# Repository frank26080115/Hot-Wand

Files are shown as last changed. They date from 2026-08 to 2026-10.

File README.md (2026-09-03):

# Hot-Wand

Compact RF soldering iron station. Compatible with 13.56 MHz handpieces. If the handpiece uses 13.56 MHz and a F-type coaxial connector, then it is compatible.

The project's name, Hot-Wand, reflects how a RF soldering iron feels like magic, and justifies their typical multiple-hundreds-of-dollars price. The spirit of this project is not to lower the price, but to make it portable.

This is nearly a clone of [SergeyMax's design](https://github.com/SergeyMax/SolderingStation), but with modifications:

 * redrawn schematic for clarity
 * layout to fit in a Hammond MFG enclosure
 * removed AC power input, uses DC inputs (battery XT30 connector) or USB-PD (with negotiation for 28V)
 * uses a 128x32 OLED display
 * options for low power mode, automatic sleep
 * uses a STM32F042F6P6 microcontroller (more flash memory)
 * cooling fan, temperature sensors
 * internal glass fuse
 * substituted parts that are only available from Russia

I implemented a rather fancy GUI, fancier than what is available on a Metcal soldering station. The firmware features/supports:

 * persistent settings, edited through a setup menu
 * 3 different power levels (for adapting to different USB bricks or power banks)
 * low battery warning/cutoff
 * user triggered sleep mode (basically, the power switch)
 * idle detection for automatic screen dimming and sleep
 * various fault detection
 * easter eggs! try and find them

The XT30 connector allows the user to connect a battery pack. If the user configures what kind of battery chemistry is being used, then the firmware will automatically determine the number of series cells in the battery pack and set an appropriate low battery cutoff threshold. When the battery voltage is considered too low, the power is automatically cutoff and the user is offered an option to override the cutoff.

The USB-C connector is connected to a USB-PD negotiation IC. The negotiator is configured to request 28V at the maximum allowable current (capable of 5A). Depending on the USB-PD host's implementation, the actual offered voltage may be 28V or 20V. If the current required is more than the current available from the USB-PD host, the user can select one of the lower power modes to avoid unexpected shutdown.

The RF power output is through a F-type connector, so it is compatible with most 13.56 MHz handpieces, such as Metcal, Thermaltronics, Hakko.

On paper, the buck converter that is actually powering the RF amplifier is set to 20V output with a 5A current limit. Thinking this means a 80W heat output is optimistic, I would expect somewhere between 50W to 80W of actual heating power, while using about 120W total from the upstream. Thus, the highest power setting is meant to be compatible with 140W USB-PD GaN chargers. The lowest power setting is roughly 50W electrically, to be compatible with 65W USB-PD chargers. The medium setting is roughly 75W electrically and is meant to be used with 100W USB-PD chargers.

When using a battery, the buck converter cannot boost the voltage, so using any DC input below about 24V would mean maximum power cannot be reached. The user does not have to set a low power mode in these cases but just don't expect the power bar being displayed to ever reach the top of the chart. The system cannot function at all below 14V. The DC input is rated for up to a 36V input. There is a glass fuse inside that limits the total system power draw to TODO amps.

While this is a DIY project and not a commercial product, it is a difficult project as it requires hand-wound inductors and tuning the inductor coils. This project is a learning experience, as I had to study the (translated from Russian) blog post made by SergeyMax in detail. See my page on the design study TODO.

## Hot-Wand Lite

In the same spirit, a compact RF soldering iron station. Compatible with 470 kHz handpieces. This is the inexpensive version. It is a clone of the [Radio Thermal](https://radiothermal.com/), but with modifications

 * layout to fit in a Hammond MFG enclosure
 * uses battery XT30 connector or USB-PD for input
 * uses some sort of Seeed Studio XIAO microcontroller module
 * user selectable power levels via externally pluggable jumpers
 * internal glass fuse

Physically, Hot-Wand and Hot-Wand-Lite uses the same aluminum enclosure. The power input stage are almost identical. The RF output connector is a SMA connector this time. [Radio Thermal](https://radiothermal.com/) (the inspiration for this) has instructions on how to build a cheap handpiece.

This cost saving design has way less fault detection.

While this is a DIY project and not a commercial product, it is a difficult project as it requires hand-wound inductors and tuning the inductor coils. Regarding how this is copying a lot of the [Radio Thermal](https://radiothermal.com/) design, I am copying it verbatim, as they do not use anything weird from Russia, and the RF design education I've already gotten from the much more complicated 13.56 MHz version of Hot-Wand.

## What is a RF soldering iron anyways?

An RF soldering iron sends high-frequency electromagnetic energy into a purpose-built tip cartridge, where a thin magnetic heating layer produces heat very close to the working end; in Curie-regulated cartridges, that layer also changes how strongly it absorbs energy as it approaches its designed temperature. Compared with a conventional iron whose resistive heater must heat a larger structure and conduct that heat to the tip, the shorter thermal path and low effective thermal lag let an RF tip respond immediately when a solder joint draws heat and recover its temperature quickly afterward. That fast, load-responsive delivery is why a nominally 50 W RF iron can feel more capable than a nominally 100 W resistive iron: the wattage rating describes available electrical power, while the user's experience is dominated by how quickly and efficiently that power reaches the joint and restores the tip temperature.

The RF soldering iron's station unit does not feature a temperature setting or even have the ability to detect the iron's temperature. When you buy the iron cartridge (which is the tip and stem), it is specific to one temperature. It will always be dead-nuts on target because of the Curie-point behavior of the magnetic alloy built into the cartridge. Below its designed temperature, the alloy is magnetic and the skin effect concentrates RF current in its thin, relatively high-resistance outer layer, producing heat right at the tip. At the Curie point the alloy loses its magnetic properties, the skin effect collapses, and the current moves into the low-resistance copper core, so heating drops sharply. When a solder joint cools the tip, the alloy becomes magnetic again and full heating immediately resumes. The temperature feedback mechanism is therefore inside the heater material itself, directly at the working tip, instead of being a sensor-and-controller loop back in the station.

## Project Ethos

I've always liked the Metcal MX-5200 I have access to at work. I'm also a robot combat competitor, both in insect weight classes and also a part of a heavyweight battlebots team. Thus, I travel with my tools a lot, sometimes even flying to NHRL from California. And while I like my [iFixit soldering iron](https://eleccelerator.com/review-ifixit-soldering-iron/) for it's portability, I thought it'd be cool to have a portable RF soldering iron.

While designing this project, the cost started to balloon. At one point it was decided to drop the pretense that DIY is cheaper, and instead, build something I would rather own even more than the actual (gigantic) MX-5200.

I also wanted to document this project in a way that makes it way more friendly for a DIY builder to actually build.

Undertaking this project is not cheap, it requires a considerable amount of skill and for you to already have access to soldering equipment. You have been warned. If you need a good soldering iron for a reasonable cost, a Hakko FX-888DX or a iFixit Soldering Iron are still a good bets.

## Design Study

Please see [my full design study (click here)](doc/design-study/design-study.md). This includes:

 * Dissection of SergeyMax's design
 * Analyzes other DIY builder's notes as they build SergeyMax's design
 * Analyzes SergeyMax's follow-up video (that's in Russian)
 * My additional design choices, justifications, calculations
 * and more

and please explore the [documentation directory itself](doc), as I might've written something but forgot to link it.

## Build Guides

 * [DIY build guide for the Hot Wand (13.56 MHz version)](doc/build-guide-13mhz/build-guide.md)
 * [DIY build guide for the Hot Wand Lite (470 kHz version)](doc/build-guide-lite-470khz/build-guide-lite.md)

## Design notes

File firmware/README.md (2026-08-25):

This is the firmware for the Hot Wand, running on a STM32F042 microcontroller.

It is meant to be built under PlatformIO and flashed via the SWD pins using a ST-Link V2.

# Firmware Architecture

The overall firmware is split into the main application that operates the soldering iron, and a setup menu (which keeps the soldering iron unpowered while within the menu). The main application owns initialization and the continuously running control loop. The setup menu is a separate modal loop entered during boot; it stops RF generation and forces the buck-converter control to minimum output before accepting input or drawing menu pages. It uses only the button, display, timeout, and nonvolatile-settings paths needed to edit configuration, then resets the controller when exiting. This keeps setup logic out of the active power-control path and makes the safe output state explicit at the boundary between the two modes.

## Platform and hardware layer

The project uses PlatformIO's STM32Cube framework and the STM32F0 hardware abstraction layer supplied by ST. The vendor HAL and CMSIS definitions provide the supported interface to clock control, GPIO, interrupt configuration, ADC setup and calibration, flash programming, and the other MCU peripherals. This keeps device-specific register names, bit definitions, and startup behavior tied to the selected STM32 target rather than duplicating them inside the application.

Some paths use the STM32 peripheral registers directly after the HAL has established the surrounding clocks and pin configuration. This is intentional where the firmware needs an exact timer waveform, a carefully ordered GPIO/peripheral handoff, or a small deterministic interrupt path. The RF carrier, power-attenuation PWM, fan PWM, tip-detect timer, ADC channel rotation, and OLED I2C transport are examples. These accesses still use ST's CMSIS device definitions; they are not a separate home-grown hardware abstraction layer.

## Imported U8g2 display library

A copy of U8g2, including its U8x8 support layer, is imported into `lib/u8g2` and compiled as part of the firmware instead of being fetched as a build-time dependency. The imported library provides the SSD1306 display driver, framebuffer, fonts, and drawing primitives. Its upstream license is retained alongside the source.

Application code reaches U8g2 through `oled.c`. That module supplies the display setup and the U8x8 byte, GPIO, and delay callbacks that connect the library to this board's I2C transport and STM32 timing functions. Keeping the adapter at this boundary avoids spreading display-controller and library-callback details through the rest of the firmware.

## Execution model

There is no RTOS, scheduler, thread, or dynamically registered task list. After a fixed initialization sequence, `main()` enters one cooperative `for (;;)` superloop. Each subsystem exposes a small task function that is called in a deliberate order: inputs and tip state are serviced first, safety faults are checked, power is supervised, RF restart eligibility is evaluated, and then the lower-priority temperature, fan, debug, button-action, and display work runs.

Most tasks are non-blocking state machines. They remember their own state and compare timestamps against the shared millisecond tick, then return quickly when no work is due. This makes execution easy to inspect: there is one foreground control flow, and timing behavior does not depend on scheduler priorities or task synchronization primitives.

The boot/setup screens and terminal fault screen use their own explicit loops. Those are intentionally modal states, not hidden schedulers. They use short delays while continuing the small amount of input and display work appropriate to that state. The setup menu and all terminal fault paths first disable power-producing outputs.

## Interrupts and timing

Interrupts are reserved for events that cannot depend on foreground loop latency:

- SysTick maintains the HAL millisecond counter used by the cooperative state machines.
- The ADC completion interrupt advances continuous round-robin sampling, updates the filtered readings, and maintains a high-granularity DC-input-voltage history.
- EXTI and TIM14 qualify tip-presence edges with a hardware-timed debounce interval. (highest priority)
- The clock security system uses the NMI path to shut down RF if the external crystal fails.
- The user button press is using an interrupt edge trrigger sharing EXTI.

The startup vector table supplied by STM32Cube uses weak handlers. `interrupt_vectors.S` provides strong, non-LTO shims that retain and dispatch to the firmware's C implementations even with the GCC 7 link-time optimizer enabled.

## Tip-detection safety

Tip detection starts fail-closed: before the detector has initialized and confirmed the input, its fault latch is set and RF is not allowed to start. The electrical input has an external pull-up, so a high level represents a connected tip and a low level represents a missing tip.

Both input edges trigger EXTI. The handler masks the tip interrupt and starts TIM14 as a one-shot timer for the 300 microsecond debounce interval. When that interval expires, the timer interrupt samples the settled pin. A confirmed missing tip latches the fault and calls `rfgen_stop()` directly from the interrupt path, without waiting for another pass through the main loop. Edges arriving during qualification remain pending and receive another complete qualification interval after EXTI is unmasked.

The latch does not clear merely because the signal returns high. Reset is allowed only when the last debounced state says the tip is present, the physical pin is currently high, and no debounce interval is in progress. Normal operation treats the resulting tip fault as terminal until the user resets the controller.

RF startup independently repeats these checks. It refuses to start while the tip latch is set, while TIM14 is qualifying an edge, or while the physical tip input is low. The final check and timer enable are performed with maskable interrupts disabled, closing the race in which a disconnect could otherwise occur partway through startup.

## Fan controller

The firmware allows the user to pick between 16 different fan control modes, in three broad categories:

 * simple and force the fan to a certain speed
 * automatic modes triggered by a particular temperature threshold
 * adaptive modes that adjusts fan speed based on temperature detected

## RF generation and shutdown safety

The RF carrier depends on the 27.12 MHz external crystal. TIM1 divides that clock by two to produce the 13.56 MHz, 50 percent duty-cycle waveform. Startup verifies that HSE is ready and is actually the system clock before enabling the RF output. The clock security system remains enabled afterward; an HSE failure enters the NMI handler, latches a clock fault, and stops the generator. Internal lockup and SRAM-parity fault signals are also routed to TIM1's hardware break input, whose configured run and idle off-states hold the RF output inactive.

RF shutdown does not rely on simply stopping a timer and hoping the pin assumes a safe state. Normal `rfgen_stop()` marks the generator inactive, preloads the GPIO output latch low, changes the RF pin from TIM1 alternate-function control to a push-pull GPIO output, and disables TIM1. `rfgen_emergency_stop()` reverses that order for minimum latency: it first clears TIM1's main-output enable, channel enable, and counter, then performs the same GPIO-low handoff. Emergency stop also latches an RF-driver fault that both start gates enforce until MCU reset.

Startup uses the reverse discipline. The timer is completely configured while its main output remains disabled, the inactive timer state owns the pin first, and only the final guarded sequence enables the timer and RF output. If a tip or clock fault is observed during that sequence, shutdown runs again immediately.

## Fault containment

Fault handling is deliberately terminal. Entering `show_fault()` immediately stops RF generation, forces the buck-converter attenuation output to its minimum-power state, and stops the fan before attempting to draw or animate an error message. If the display is unavailable, the firmware remains in the safe terminal loop anyway. Faults are never cleared automatically; recovery requires the explicit reset path allowed for that fault.

Some faults are triggered from the interrupt context. `rfgen_emergency_stop()` will be called from within the interrupt for minimal latency, and then a fault flag is set for the main thread to show the terminal `show_fault()`.

This gives the firmware layered protection. Foreground supervision handles normal voltage, temperature, current, and power decisions; time-critical failures (tip detector, crystal clock, voltage dips/spikes) have interrupt-level shutdown paths; TIM1 has hardware break inputs for internal MCU faults; and terminal fault presentation independently reapplies safe output states before doing any UI work.

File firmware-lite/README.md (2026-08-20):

# Hot Wand Lite Firmware

The Lite edition of Hot Wand is very simple as it is a copy of the Radio Thermal DIY RF soldering iron design. The microcontroller simply needs to generate a 470 kHz square wave.

The additional feature is that the user can select between 3 power modes. The LED will blink according to the input voltage and selected power mode.

This firmware is built under PlatformIO under the Arduino framework. The RF generator code does use low level hardware registers and so care must be taken so that Arduino built-in functionalities do not conflict with the same hardware.

## Power Modes

The "Sport" mode is a 100%-no-matter-what power mode.

The "Normal" power mode is one that allows 100% power for 21V of power input or lower. When above 21V, the firmware attempts to lower power consumption in a way that caps it at 100W.

The "Eco" power mode is a 70% power mode. The intention is to allow a 3A capable power supply to be used instead of a 5A power supply.

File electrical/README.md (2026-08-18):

This directory contains electrical design files for the Hot Wand project

The main `hot-wand` project is the 13.56 MHz version, while the `hot-wand-lite` is the 470 kHz version meant to be less expensive.

The schematic and PCB are designed with CadSoft EAGLE 7. PDF versions of the schematic and image previews of the PCB are provided for convenience.

The `mfg` directory will contain the BOM and gerber files, along with some helpers that aid in generating these files.

The BOM, CPL files, and the design rules, are all meant for use with JLCPCB's PCBA service.

## Release Procedure

0. Run a DRU check, and also run `drill_sizes_report.bat` to catch stray drill sizes
1. Edit the symbol and footprint for the version to reflect the latest version designation
2. Generate the schematic preview PDF file using `eagle_schematic_preview.py`
3. Generate the gerber files using `generate_gerbers.bat` (this also generates the gerber preview)
4. Generate the BOM and CPL files using `generate_bom_cpl.bat`

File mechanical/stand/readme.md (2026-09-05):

this directory contains the 3D printed and milled/cut components used for the folding soldering iron stand

see [this document to see the instructions](../../doc/build-guide-iron-stand.md)

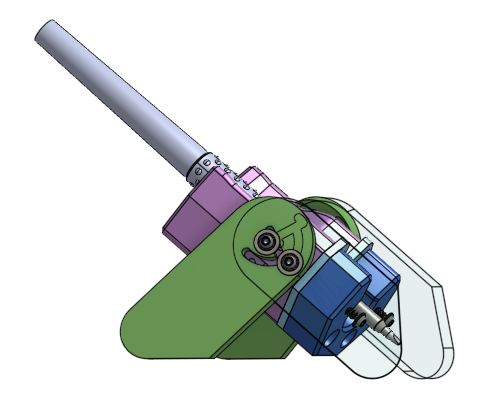
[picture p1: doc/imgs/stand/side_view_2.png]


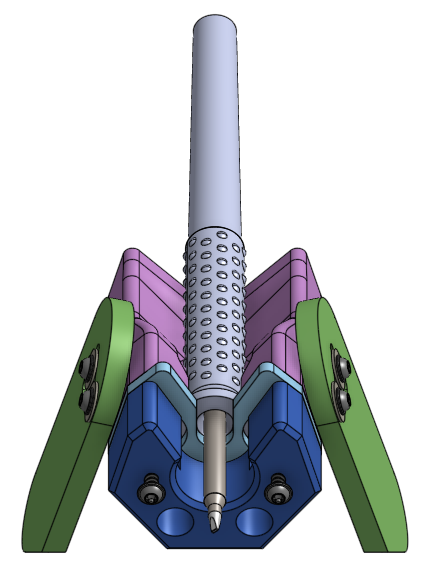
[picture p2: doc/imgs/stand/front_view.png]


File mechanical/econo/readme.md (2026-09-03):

This directory contains the 3D printed components used for the economically built Hot Wand 13.56 MHz plastic version.

These parts are not used if you are building the aluminum enclosed version.

see [this document to see the instructions](../../doc/build-guide-13mhz/econo-build.md)

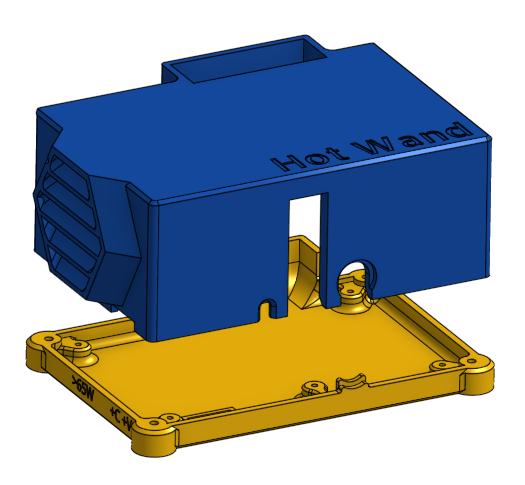
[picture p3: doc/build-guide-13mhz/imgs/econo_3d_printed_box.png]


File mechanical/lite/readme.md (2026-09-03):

this directory contains the 3D printed components used for the Hot Wand Lite 470 kHz version

see [this document to see the instructions](../../doc/build-guide-lite-470khz/build-guide-lite.md)

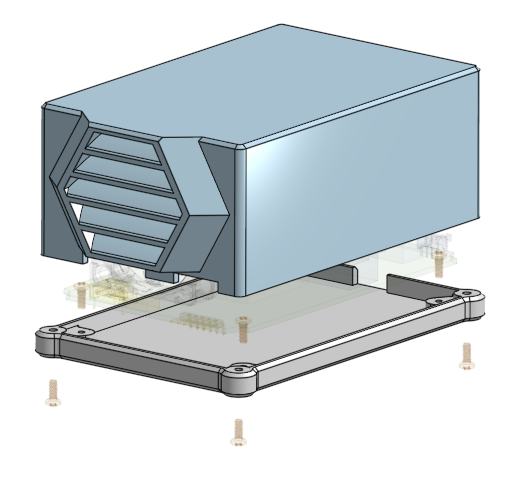
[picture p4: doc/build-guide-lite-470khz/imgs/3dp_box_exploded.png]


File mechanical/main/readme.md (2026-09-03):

this directory contains the 3D printed components used for the main Hot Wand 13.56 MHz version

see [this document to see the instructions](../../doc/build-guide-13mhz/build-guide.md)

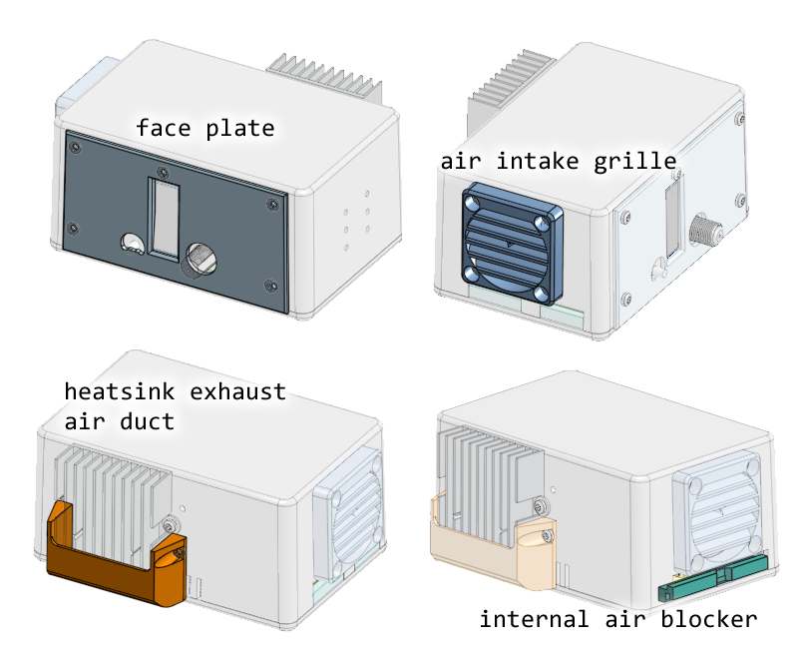
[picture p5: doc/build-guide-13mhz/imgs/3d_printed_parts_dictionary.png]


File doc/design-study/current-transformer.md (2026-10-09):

In SergeyMax’s design, there is a current transformer at the RF output. It is using one of the same toroid cores that’s used in other places in this design. The primary winding is just a single loop of the RF output. The transformer is 1:14:14 so the two secondaries are both 14. The connection that looks almost like a center tap is connected to the RF output through a 10pF capacitor. The output of the transformer goes to something that resembles a full bridge diode rectifier. That goes to what looks like a RC filter before a resistor leading to the feedback network of the main buck converter.

At a simple first glance, I assumed that this was some sort of stability or protection mechanism. More current would mean more signal driven into the feedback network and thus lower the buck converter’s output voltage. I thought maybe this was to compensate for some sort of voltage drop caused by inrush, maybe the buck converter overcompensated for voltage drops like that, and needed something to stabilize it.

SergeyMax’s own blog post didn’t really give a clear answer, and other people building his design were also studying it. This forum thread is a goldmine https://www.eevblog.com/forum/projects/i-built-the-diy-metcal-compatible-soldering-station/

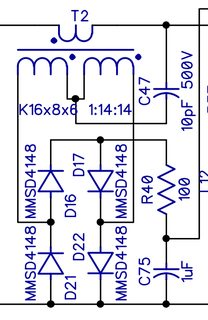
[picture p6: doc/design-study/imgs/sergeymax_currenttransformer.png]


TLDR: This is a power factor meter. As the temperature of the iron tip changes, the complex load changes, shifting the phase relationship between RF voltage and current. The tip doesn't need or want more power when it is already hot, and the power factor will change. This current transformer circuit is able to sense this by detecting the phase difference between voltage and current, and then it tells the buck converter to lower its output voltage when the tip doesn't want more power. (technically it also tells the buck converter to raise the voltage when it is cold)

The builder `rfmerrill` posted to the forum thread:

> At first I thought it was a simple current sense circuit, but then I noticed that the RC filter is a lowpass at around 2 kHz, and the diodes are not arranged in a rectifier configuration.
> 
> After poking at it a bit with some friends, we realized this is actually a **ring mixer** that mixes the output current with the output voltage to measure the phase angle between voltage and current! Which makes a ton of sense actually: We want to reduce the output power as the iron tip reaches the curie point. As it does so, the inductance of the iron tip will drop, causing the phase angle between voltage and current to move away from 45 degrees.
> 
> In other words, it's effectively a power factor meter!

later

> Here's how it works:
> 
> Current flows in the same direction on the schematic on primary and secondary side (same polarity voltage = opposite polarity current!)
> 
> The node between D16 and D17 is clamped to approximately +/-2V by the diode ring.
> 
> Because of the above, we can think of C47 as being from the output voltage to essentially ground, as the voltage on the other side of C47 is much greater than 2V in magnitude. Therefore, the current through C47 is approximately the same as it would be were it connected to ground--in quadrature with the output voltage and equal to approx Vout / 1173 ohm (either RMS or peak since it's a sinusoid)
> 
> When primary current is flowing left to right--i.e. towards the soldering iron tip--D16 and D17 are reverse-biased, and therefore no current flows through R40
> 
> When primary current is flowing right to left, the current induced in the secondary flows through D16 and D17, and the additional current injected by C47 has nowhere to go but into R40--until the voltage at that node gets high enough that either D21 or D22 is forward biased. Because the current injected by C47 is so high, this results in R40 effectively seeing a square wave current which you can see in the LTSpice simulation above.
> 
> So if we want to create a simplified model of how R40 is being driven, we can think of it like this:
> 
> - Not driven when primary current is flowing left to right
> - Driven at +2V when primary current is flowing right to left and current is flowing down through C47
> - Driven at -2V when primary current is flowing right to left and current is flowing up through C47
> 
> Because the current through C47 is 90 degrees out of phase with the output voltage we can then reach the conclusion that
> 
> **if the output current and voltage are in-phase, periods 2 and 3 are of equal time and thus the voltage at C1 is zero**
> 
> . Of course, that voltage is also being pulled towards 0.8V via its connection to the feedback loop of the DC-DC, but we'll ignore that for now.
> 
> If the output voltage starts to lead the output current, then period 2 will lengthen and period 3 will shorten, and the voltage on C47 will be pulled higher. Likewise if the current leads the voltage, the inverse will happen and the voltage on C47 will be pulled lower.
> 
> So in essence this is not as dependent on the magnitude of output current and voltage, and much more on the relative phase, which makes sense.
> 

I read what he said, and it was difficult to get a nice graphic out of a simulator to represent it, so I came up with this theoretical signal animation instead:



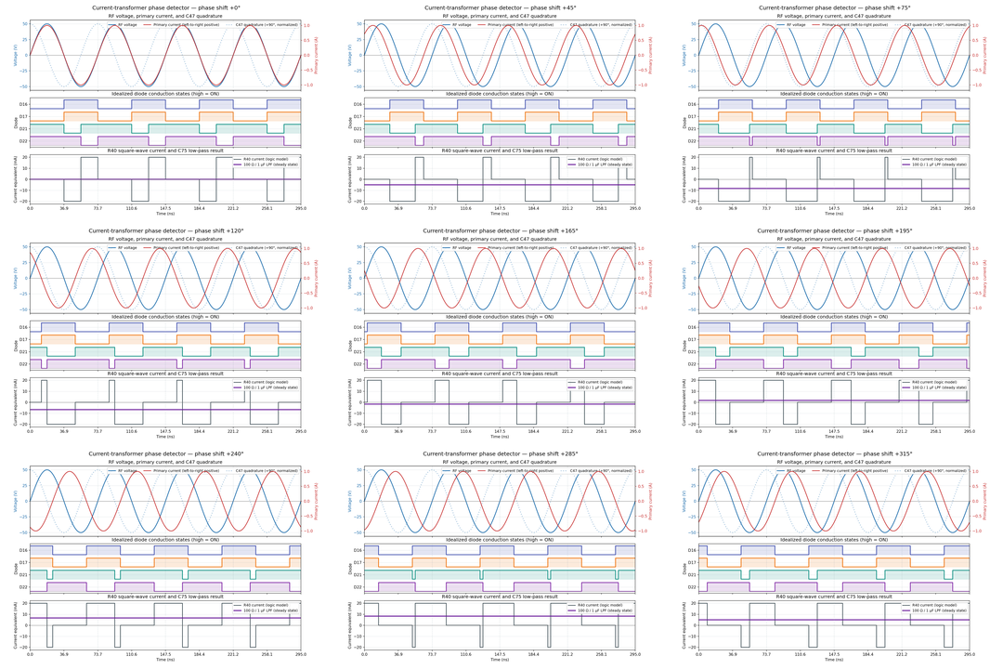
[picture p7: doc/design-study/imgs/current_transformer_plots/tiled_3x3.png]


If you wish to see the individual frames, [click here for all the frame files](./imgs/current_transformer_plots/)

For the three examples of tip temperature states and their resulting waveform:

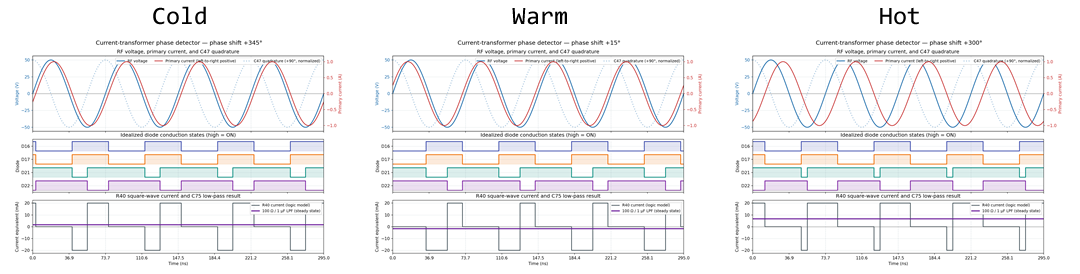
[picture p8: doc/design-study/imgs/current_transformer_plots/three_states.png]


The numbers used in this model are in this document at the bottom.

## My Own Implementation

The builder `rfmerrill` told me that (over reddit chat)

> I was never able to get it to work until I actually sourced the exact cores from russia

He didn't get the current transformer to work with any of the substitute toroid cores, it only started working once he put in the effort to import some of the Russian ones that SergeyMax used.

The rule of thumb is that for a transformer application, a different AL doesn't mean I have to change the winding ratios, it's a ratio after all.

The toroid core I picked is a Fair-Rite 5961004901. The material is "61", the AL is supposedly higher than the one SergeyMax used, and the datasheet claims that it is a "high frequency NiZn ferrite material developed for a range of inductive applications up to 25 MHz".

On paper, this current transformer is behaving almost like a digital component because of the way the diodes clamp the voltage. The current transformer and the 10pF capacitor really just need to provide enough signal strength to actually cause the diodes to conduct. So this means the Fair-Rite substitute should work better, in a sense. But the concern is that the different material causes a phase delay from primary to secondary, which would obviously ruin the whole thing as the whole point is to measure the phase difference between voltage and current.

I planned out the winding in 3D with consideration for my transformer PCB footprint. All wires are to be 22 AWG (SergeyMax used 0.6mm). There isn't many photos of this component so I thought a 3D model would help a ton.

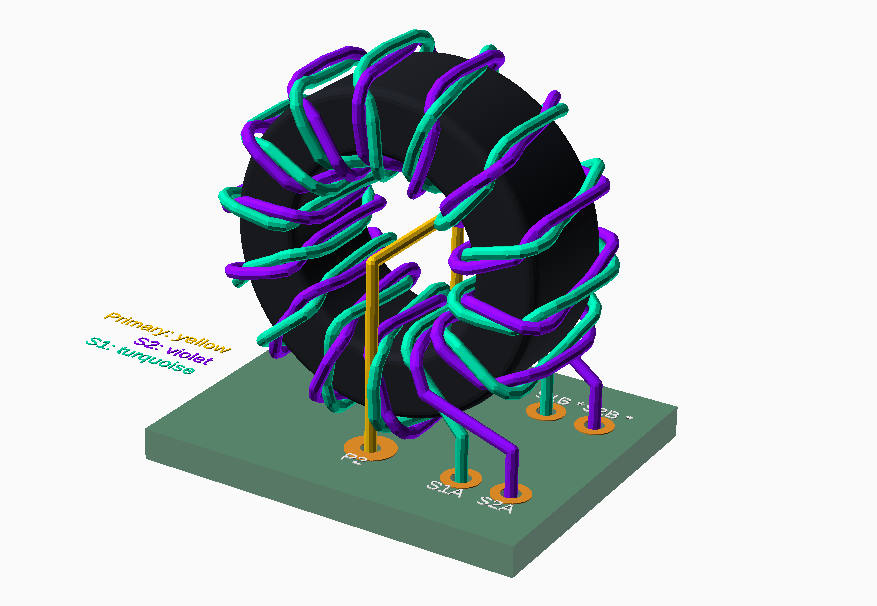
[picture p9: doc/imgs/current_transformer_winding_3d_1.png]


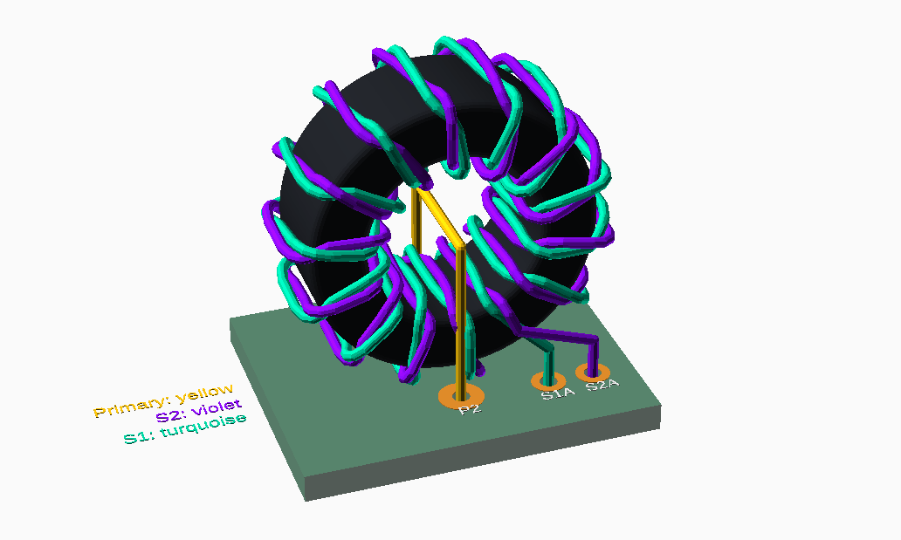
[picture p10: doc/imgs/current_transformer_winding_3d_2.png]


The two secondary wires are first twisted together, and then wound around the toroid, crossing the center of the toroid 14 times. A twisted bifilar winding implementation.

Also, it's hard to get the directions wrong, because the directions for the current flow (the primary current must be in the opposite direction of the secondaries) are actually dictated by the PCB design, not the winding direction. You can wind it clockwise or counterclockwise and it is theoretically going to do the same thing physically. But, do not criss-cross at the bottom!

## Screenshot From SergeyMax's Follow-up Video

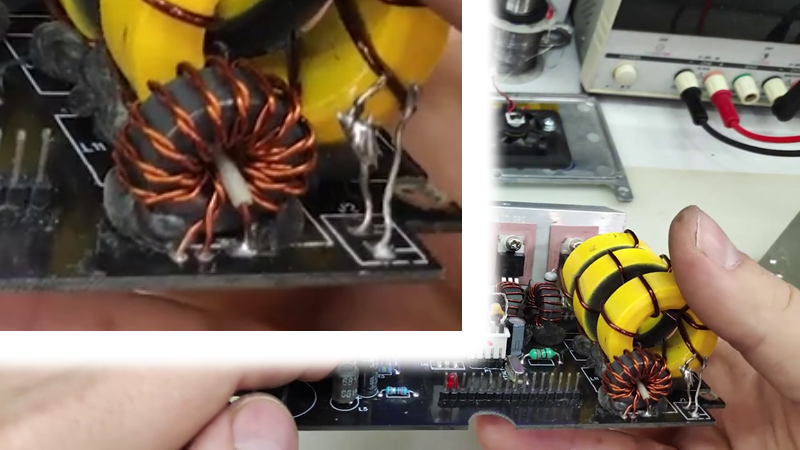
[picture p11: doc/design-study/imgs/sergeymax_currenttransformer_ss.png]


He did say that if you screw this up, it could make the circuit do the opposite, which is boosting the voltage when it should be lowering it. I have spent a ton of time making sure I did not make this mistake.

## Iron Tip Model

For simulations, it is useful to know how to model the iron tip as if it was a complex load.

I got these measurements from http://randomfunprojects.co.uk/metcal.html

Measurements at 13.56 MHz of a STTC-147 tip

| Tip state | Resistance, R (Ω) | Reactance, X (Ω) | Equiv. component | SWR  | S11  |
| --- | ---: | ---: | ---: | ---: | ---: |
| Cold | 42.3 | +j13 | 153 nH | 1.4 |  -16 dB |
| Warm<br />(below Curie temperature) | 55 | -j16 | 730 pF | 1.1 |  -23 dB |
| Hot<br />(above Curie temperature)  | 12 | +j24 | 280 nH | 5.1 | -3.4 dB |

## Relevant Patent

[US Patent US4795886A, filed by Metcal in 1986](https://patents.google.com/patent/US4795886A/en), describes the first embodiment of this, although it was different.

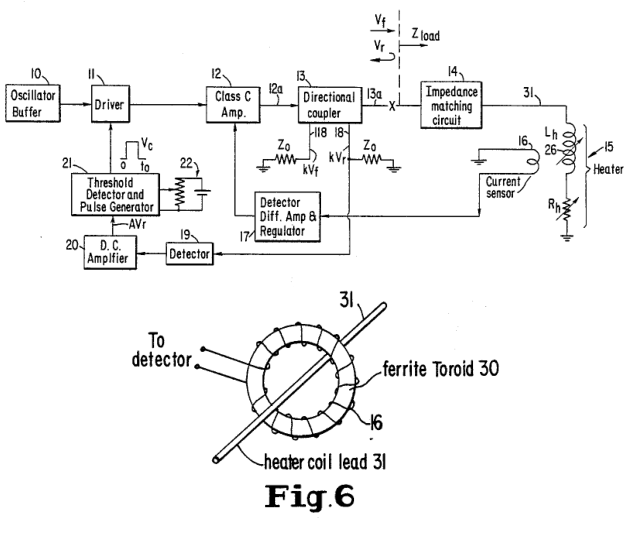
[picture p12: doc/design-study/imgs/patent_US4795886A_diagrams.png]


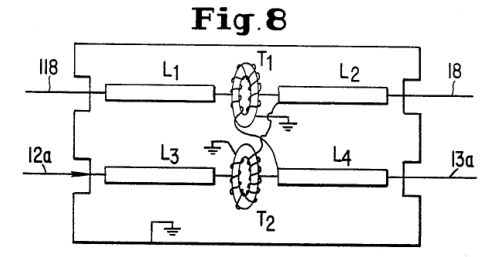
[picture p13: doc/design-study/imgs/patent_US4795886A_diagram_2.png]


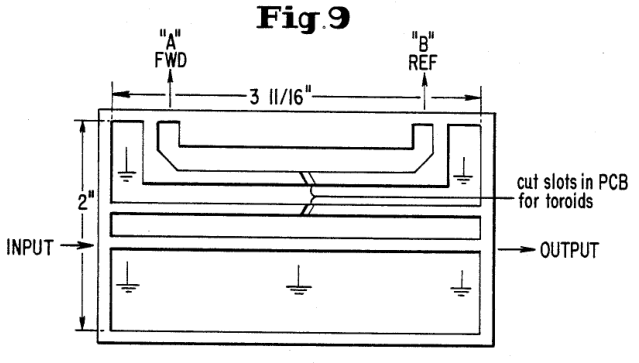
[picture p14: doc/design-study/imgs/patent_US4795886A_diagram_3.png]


The patent’s preferred embodiment uses a directional coupler to measure reflected-voltage magnitude. It does not measure the phase of the reflected wave, so it does not obtain the complete complex reflection coefficient. Our implementation instead measures the phase relationship between load voltage and current, which is another indicator of the changing load impedance.

> When the current to the load exceeds the desired constant magnitude, the voltage induced across coil 16 causes the regulator 17 to decrease the voltage fed to the collector of the final stage of the power supply, namely the Class C amplifier 12. To achieve this function, the detector, differential amplifier and regulator 17 has an adjustable reference voltage against which the voltage across coil 16 is compared. If the voltage across coil 16 exceeds the reference voltage, the regulator 17 lowers the collector voltage to the Class C amplifier 12, until the two volt ages are equal. Similarly, if the voltage across coil 16 is lower than the reference voltage, the regulator senses the difference and raises the voltage to the Class C amplifier until the voltage across coil 16 equals the reference voltage. If the Class C amplifier is of the vacuum tube type, the regulator 17 controls the plate voltage of that amplifier.

Fun, our modern implementation adjusts the voltage being output by the buck converter. This is saying something similar, except it is only using voltage on the coil as the feedback signal, not the phase. (you can see why me and others have been confused by this current transformer's purpose)

The patent's preferred embodiment turns off the RF for a fixed time duration when the iron tip is too hot (reflected voltage exceeds an adjustable threshold associated with a temperature near the effective Curie point)

> When the reflected voltage signal from output 18 produces a voltage that exceeds the reference voltage from circuit 22, the Schmitt trigger produces an output signal which actuates a monostable 21b multivibrator which produces an output signal V_c of a predetermined length, to V_c can turn off the driver transistor by using it to bias the base of a common emitter amplifier stage.

later

> Since the cooling load is small the heater may still be at the effective Curie when time period to expires in which event the driver and Class C amplifier will be turned back on, but since there would then still be a reflected voltage at output 18 the multivibrator would be turned back on almost instantly starting a new off period for a time period to. Thus, the radio frequency power to heater 15 would be cycled on and off with the "off" periods being relatively long as compared to the "on" periods. On the other hand if the cooling load was large the same events would occur except that there would be greater cooling of heater 15 during the time periods to, and the "off" periods would usually be shorter than the "on" periods.

Although it also mentions reducing the current as an alternative implementation

> Instead of turning current on and off for controlling the temperature of the load 15, the apparatus may be designed to simply reduce the current.

Interestingly, even though we think of these RF irons as having one fixed temperature as determined by the tip's Curie temperature, this patent also describes a way of controlling the temperature.

> As the temperature approaches T_c, V_r will increase above this residual voltage. The threshold detector 21, 22 can be set to trigger at any temperature in the range perhaps T_3 to T_c. Thus we have available a range of possible operating temperatures near T_c.

> Though it is theoretically possible to vary the operating temperature over the entire range from approximately T_3 to T_c it is probably desirable to maintain it substantially below the effective Curie temperature T_c at all times in order to maintain the good amplifier efficiency and stability referred to previously as one of the advantages of this approach. A large value of V_r, corresponds to a high degree of mismatch between the Class C amplifier 12 and the load 14, 15. This in turn lowers the efficiency of the amplifier output. Thus operation at temperatures ranging from T_3 up to a temperature T_4, at which amplifier efficiency and stability are still high, is desirable.

## Fooling Around with Dummy Load

I built a dummy load, it has uses two 100 ohm 50W resistors in parallel to create a 50 ohm 100W rated load, mounted to a big heatsink that can be optionally air-cooled (although I don't think it needs it for short tests). In series with this resistance is a 146 nH air core inductor (Wurth Elektronik 7449150146). I built this in a way that the inductor can be shorted out or have capacitors attached.

These tests were performed on a **Metcal MX-5200**, operating at 13.56 MHz. The power numbers below are the MX-5200's displayed readings.

```text
Z(L parallel C) = j*omega*L / (1 - omega^2*L*C)
Zload = 50 + Z(L parallel C)
phase = atan(Im(Zload) / Re(Zload))
```

Positive phase means voltage leads current (inductive load); negative phase means current leads voltage (capacitive load).

| Dummy-load configuration | MX-5200 displayed power number | Calculated nominal load at 13.56 MHz | Calculated phase |
| --- | ---: | ---: | ---: |
| Inductor bypass jumpers open; inductor in series | 40 | `50 + j12.44 ohms` | +14.0 degrees |
| Inductor bypass jumpers shorted | 50 | `50 + j0 ohms` | 0.0 degrees |
| 2,000 pF in parallel with the inductor; bypass open | 56 | `50 - j11.11 ohms` | -12.5 degrees |
| 500 pF in parallel with the inductor; bypass open | 18 | `50 + j26.46 ohms` | +27.9 degrees |
| 300 pF in parallel with the inductor; bypass open | 20 | `50 + j18.24 ohms` | +20.0 degrees |

For comparison, the measured STTC-147 tip impedances in the Iron Tip Model section above represent these phases:

| Tip temperature state | Previously reported measured impedance at 13.56 MHz | Phase calculated from that impedance | Comparison with the dummy load |
| --- | ---: | ---: | --- |
| Cold | `42.3 + j13 ohms` | +17.1 degrees | The unmodified inductive dummy load has almost the same reactance; the 300 pF case has a somewhat larger inductive phase. Both retain 50 ohms of resistance rather than 42.3 ohms. |
| Warm, below Curie | `55 - j16 ohms` | -16.2 degrees | The 2,000 pF case is a nearby capacitive test point, with somewhat smaller resistance and capacitive reactance magnitude. |
| Hot, above Curie | `12 + j24 ohms` | +63.4 degrees | The 500 pF case has a similar reactance magnitude, but its much higher resistance gives a far smaller phase angle. It does not reproduce the hot-tip load. |

Within these five MX-5200 tests, indicated power falls as the nominal load becomes more inductive: 50 with bypass, 40 with the inductor alone, 20 with 300 pF, and 18 with 500 pF. The capacitive 2,000 pF case gives the highest reading, 56. This ordering is consistent with reduced power for increasingly lagging load current and greater power for leading load current, but it does not identify the MX-5200's detector implementation or isolate regulation from RF matching effects.

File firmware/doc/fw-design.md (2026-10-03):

# Main Loop Tasks

 * long button press forces iron to sleep, short press cycles through power modes
 * GUI is updated at 15 FPS
 * UART debug messages are sent at 2 Hz

# Important Policies

 * Faults are never automatically recovered, always have the user press a button
 * The screen is only 32 pixels wide, supporting 5 characters, choose short words
 * Only use capital letters on the GUI as the pixel font may be hard to read
 * Action for button short press must be performed immediately on the first edge to appear responsive

# GUI design

The screen is 128x32 but oriented in a portrait fashion, so it is 32 pixels wide and 128 pixels tall. The connector of the screen is at the bottom.

The top line is always the DC input voltage (for battery monitoring)

If a temperature limit is reached, the first line will also blink "!HOT!" every other second.

Below that is the power graph. It plots the power vs time with solid shaded plot.

# Power Levels

The assumption is that this is an electrically 100W-ish system because the buck converter is theoretically tuned for 20V and is capable of 5A. Actual heat power is unknown. Total input power will also be slightly higher due to inefficienceis and  miscellaneous power usage elsewhere.

The user can choose between power level modes. Available levels are:

 * "SPORT" (100W)
 * "NORMAL" (75W)
 * "ECO" (50W, must never fail when used with a 65W USB power supply)

To actually modulate the power, there is a PWM pin allocated to send a bias signal to the buck converter's feedback input through a resistor and diode.

If the currently utilized power is above the set limit, the attenuation is raised at a steady pace, otherwise, it is lowered.

Pressing the button will cycle through the power modes.

# Power Management

If the input power is below 14V (undervoltage lockout threshold of the secondary buck converter), then all soldering iron functionality is disabled. The GUI will show "LOW VOLT FAULT". Button presses in this state will cause a reboot. The microcontroller shall be in a state that can accept SWD connections.

The ADC provides other fault protections with interrupt priority: one triggered by over-voltage of the buck converter, another triggered by a sharp drop of the input voltage. These events will trigger the system to immediately shut down to protect itself.

If the temperature is too hot, the power limit of ECO mode will be automatically imposed. There is also a higher temperature limit, if reached, will cause the system to completely shutdown with the a fault message.

# Cooling Fan Control

The cooling fan hardware is optional, but the control for it will always exist.

The firmware allows the user to pick between 16 different fan control modes, in three broad categories:

 * simple and force the fan to a certain speed
 * automatic modes triggered by a particular temperature threshold
 * adaptive modes that adjusts fan speed based on temperature detected

# Boot Mode

When the microcontroller boots, it will wait 300 milliseconds for power to stabilize, and then sample the input DC power.

If during boot, the user button is held down, then UART message debugging will become enabled. While the buttons is held, the screen shows "HOLD TO ENTER SETUP" with a progress bar. The progress bar will grow for 3 seconds and then enter the setup menu if the user continues to hold the button.

If the crystal clock fails to initialize properly, the GUI will display an error "CLOCK FAULT"

# Setup Menu

When in the setup menu, the RF generator will be off and the buck converter will be put in minimum output state.

The first line will always say "SETUP", the second line will always be a blank space.

From the third line and onwards, the subject title of the item will be displayed, followed by a "  =  " line, then the value of the item.

Long hold press cycles the value. (duration specified in configuration header)

Short press cycles the subject. (duration specified in configuration header)

The two "SAVE AND EXIT" and "EXIT NO SAVE" are the last subjects and will perform the actions indicated. ("exit" meaning full device reset)

A 5 minute inactivity (no button press of any kind) timeout will cause the device to enter sleep mode (without saving) to prevent OLED burn-in.

# Firmware Code Modules

 * U8g2 and U8x8
 * OLED interface layer, connects HAL to U8g2
 * GUI main mode display
 * GUI setup menu display
 * NVM saving and loading
 * Systick 1ms time keeper, doesn't have to be precise
 * Round robin ADC sampling state machine that also handles digital low pass filtering
 * Tip detection state machine
 * User button state machine
 * Power output limiter
 * RF clock generator
 * Fan state machine
 * PA13 fan PWM generator, with a compile-time GPIO fallback

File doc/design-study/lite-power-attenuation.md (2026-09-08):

## Goal

For the Lite 470 kHz version that is a copy of Radio Thermal's design, which is asking for a 20V 5A power supply, this is a little tricky. The problem is that, the premise of the project is to add USB-PD as a power input, but, only the USB-C cables with a E-marker inside are capable of 5A. This is very annoying and I'd like to implement a reduced power mode just so it would work with 3A instead, which can make it work with normal USB-C cables and 65W USB-C chargers. The constraint is that we cannot add a buck converter into the design.

(For the full 13.56 MHz version, reducing power is a simple matter of reducing the voltage provided by the buck converter.)

I understand that 20V and 3A is about 60W, and RF irons like these are not efficient so we are expecting maybe 30-40W of heat. This is deemed totally acceptable. Even a 30W iron, if it is responsive, feels great to use in 90% of soldering situations. This is about giving just a few more options to the user, they can still power it with full 5A if they choose to.

## Ideas

Something different I've done from Radio Thermal's design is to use a Seeed Studio XIAO microcontroller which generates the 470 kHz, this allows DIY builders to avoid having to buy any programming equipment, as code is flashed via a USB connector.

Having this flexibility, the first explored option is to simply turn on the iron for a period of time and turn it off for a period of time. If we do this really fast, like 5ms on, and 5ms off, the user won't notice the interruption in heat, and won't be bothered by the coil whine (100 Hz hum). Once you get into the 1ms range you might start to hear an annoying 1 kHz tone.

The issue with that idea is that the current will probably still spike to 5A anyways for 5ms, and trigger the over-current protection that's set at 3A if you've negotiated for 3A over USB-PD.

Realistically, the over-current protection doesn't trigger immediately, it takes a few microseconds to trigger, they are usually tolerant of things like the device having a large input capacitor that causes a brief in-rush, plus, they also have their own output capacitor.

Doing long periods like 10ms or even 1ms is easy for the microcontroller. I don't really want to use any periods that can cause an audible tone, and once you get down into the microseconds, the interrupt execution times become a problem.

The firmware design was changed, I switched to using a DMA to feed each individual pulse into the PWM generator. Each power level corresponded to a pattern stored in a table. A PWM pattern like `101010101010` would be 100% power, and I can do things like `101000101000` to reduce the power consumed, that was the idea, kind of a pulse-density modulation. The hope was that the very short period of high consumption, now on the scale of microseconds, would be masked by the capacitor and skip being detected as over-current by the USB host.

(I have explored using SPI or UART to do this, but PWM is the best method here)

But this won't work as is, I'm not dumb, I've already modeled out the way the RF amplifier ramps up. It takes 6-12 clock cycles for it to ramp up to a steady resonating power amp. If you miss a single cycle, it collapses and is basically chaotic enough that restarting will take another 6-12 clock cycles. The good news is that, 12 clock cycles is super short in context and could fly under the 3A radar.

## Simulations

When turning ON the RF wave input
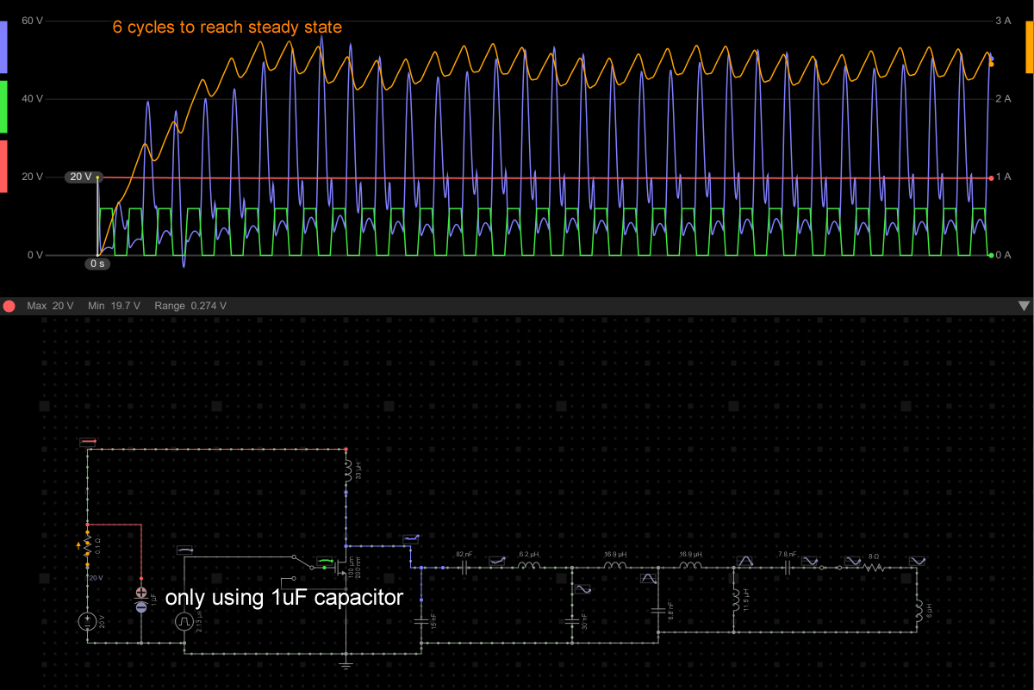
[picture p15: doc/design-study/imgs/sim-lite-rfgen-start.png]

-----
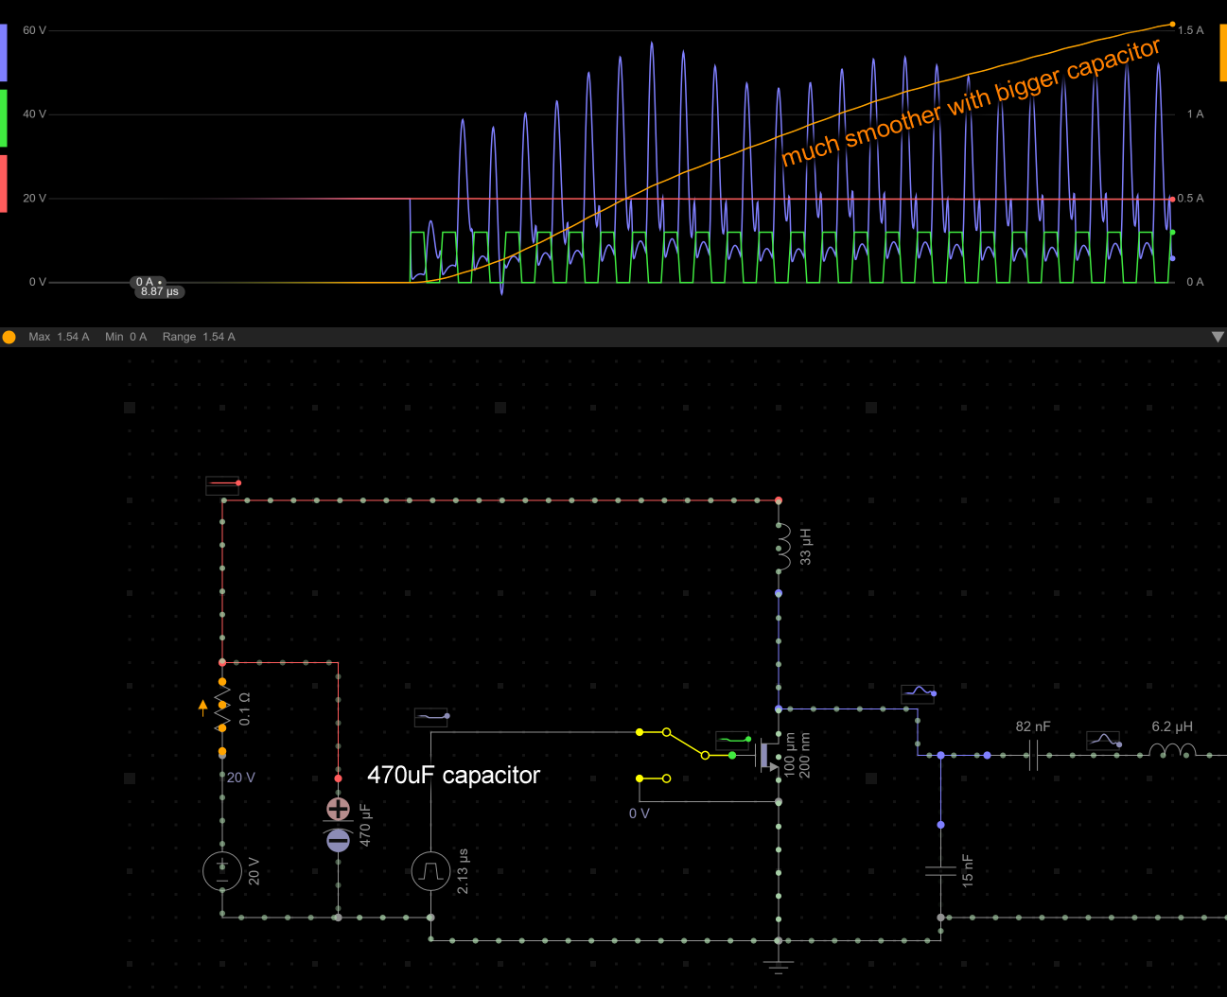
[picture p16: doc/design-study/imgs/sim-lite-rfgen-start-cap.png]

-----
When turning OFF the RF wave input
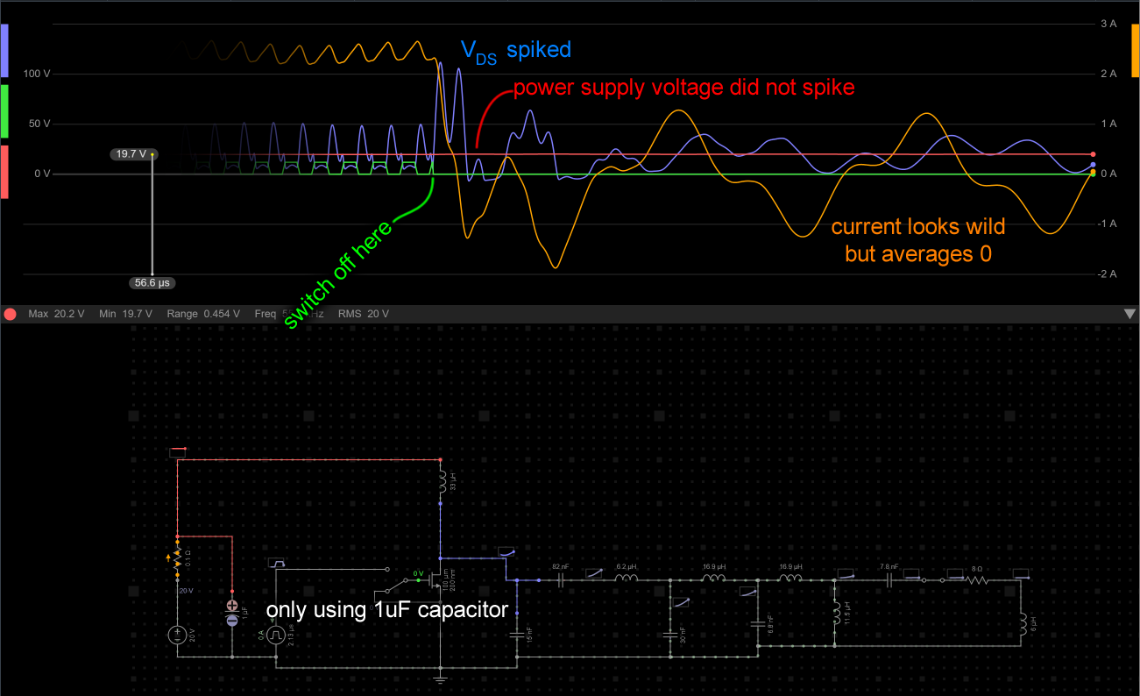
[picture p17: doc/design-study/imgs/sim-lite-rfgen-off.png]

-----
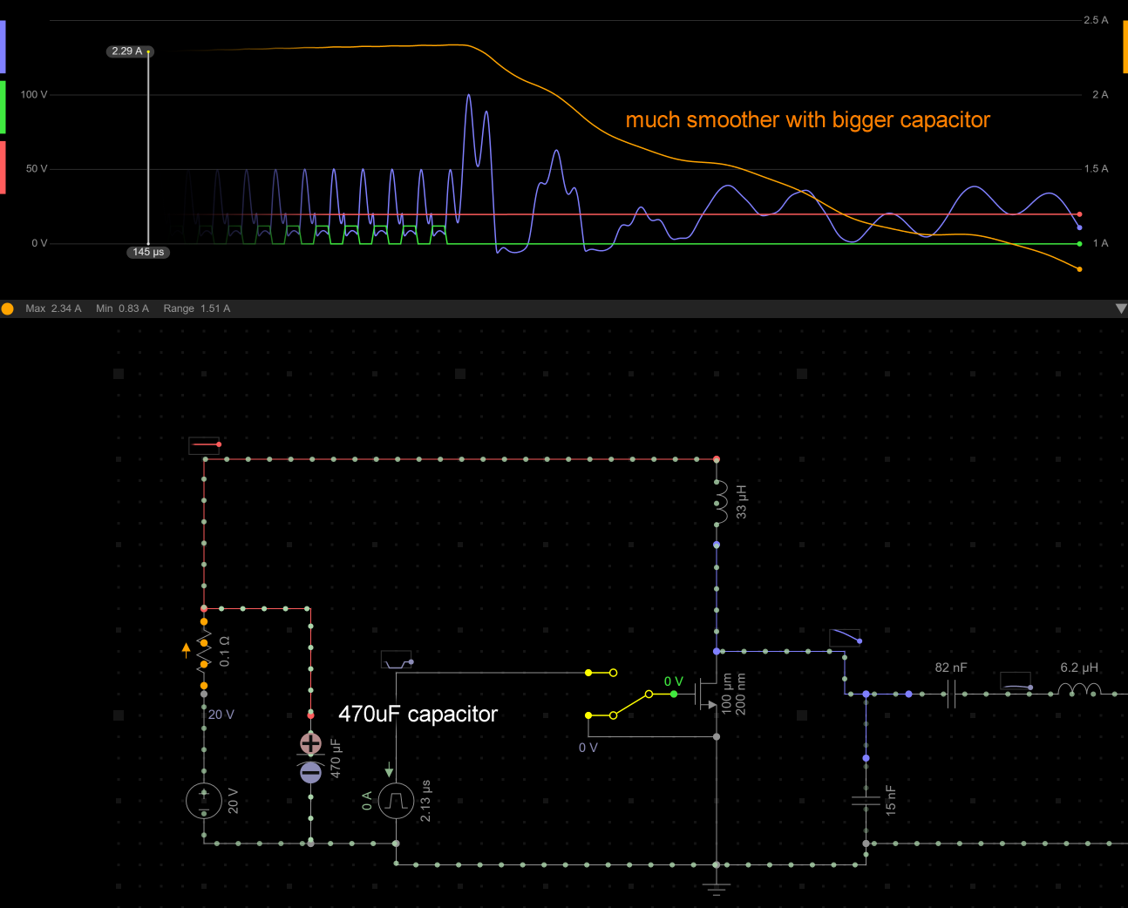
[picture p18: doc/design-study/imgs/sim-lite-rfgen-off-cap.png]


## Final Implementation

So the firmware was changed (I started writing the firmware like 2 weeks before manufacturing of the PCB), so that the pattern table now always starts with 12 carrier cycles (26 microseconds). The code that generates the pattern now inserts more cycles or more blank time (ie. off time) in order to satisfy an average power being requested, all done during run-time.

The first 12 cycles represents a ramp so it's considered 80% average power instead of 100%. If you loop these then you get 100% average power. If you do 12 cycles on and 12 cycles blank then the algorithm considers this about 40%. The algorithm adds more cycles or more blank time depending on the average power requested.

When a blank time starts, the voltages and currents don't just start decaying, noooo, it's not bouncing back and forth at 470 kHz either (if it did, then restarting the amp would be cleaner), it's chaotic. Without a carrier, it doesn't go into the iron tip, but without the MOSFET being on, it doesn't dissipate into ground. No amount of tuning can get this perfect. It does still slowly chill out, so the algorithm is written to enforce a minimum length for any blank periods so that any restart is unlikely to cause some catastrophic spike. The average power calculations are always done with this in consideration.

The major concern is power back-flowing into the USB host. When I added the 470 uF capacitor into the simulation model, this stops being a problem. Napkin math says the capacitor voltage will rise maybe only `0.04V` from the left over energy. It's not THAT much energy in context.

## Upgrading the MOSFET

At some point in September of 2026, on Radio Thermal's Discord, there was one user who asked if it was possible to have multiple handpieces connected at once, not all powered at once, but quickly switched.

This should be easy, even a cheap power switch can handle the current involved, and 470 kHz isn't that high to worry about. The only question left is, if the circuit can handle the open circuit load. Radio Thermal authors posted a few LTspice simulations for people to play with, with different tip loading conditions and VDS measurements already inside.

Given that my design can use a 28V USB-PD input or lithium battery input, I got some results for 30V, and it pointed me to wanting to update the MOSFET to a IXFP26N30X3, it has a 300V VDS rating and a lower gate charge (less heat from the gate driver circuit). In many other ways it is better than the IRF640NPBF that the original Radio Thermal design uses, but it is more expensive. There is also a protection TVS diode SMCJ150CA (SergeyMax actually used a SM15T150CA) that is added as insurance.

Ok the reality is, the peak VDS simulated for a 30V input is about 151V, the SM15T150CA is actually going to conduct a bit before that at 128V so I changed it to a SMCJ150CA, then, the SMCJ150CA's clamping voltage is what made me want a IXFP30N25X3 rated at 250V, but it's $9 (the IRF640NPBF is like $2), and the IXFP26N30X3 is like $6 with a 300V VDS rating and similar other specs. Admittedly all of this is WAYYYYYY overkill, but I'm only doing this once and these are gifts to friends. Plus, from the experiences of the builders of the SergeyMax design, and how I am doing bursty input power, I wanted this to be bulletproof.

Another thing I noticed is that the IRF640NPBF has a gate charge of 67nC (at 10V) and napkin math says that it's going to cost like a bit over 0.3W of heat to drive it. I wanted to keep the resistors simple 0.1W resistors in the gate driver circuit. So IXFP26N30X3 having a 22nC (at 10V) gate charge helps a ton. What's also odd, Radio Thermal's authors only specified 5 ohms for that resistor, it's a 0805 package on the layout, but they did not specify a part number, it's missing from their BOM, and 5 ohm is not a E24 or E96 value. My own design started off using two 3.6 ohm resistors anyways so I didn't bother pushing this issue. SR0805FR-475R1L (5.1 ohm) or CRCW08054R99FKEAHP (4.99 ohm) would work as 5 ohm 0.5W 0805 resistors and are not hideously expensive for a one-off project.

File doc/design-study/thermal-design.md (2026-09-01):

When the project started, it didn't look like SergeyMax focused on thermal very much. The box is plain looking without vent holes and the MOSFETs only have very small heatsinks.

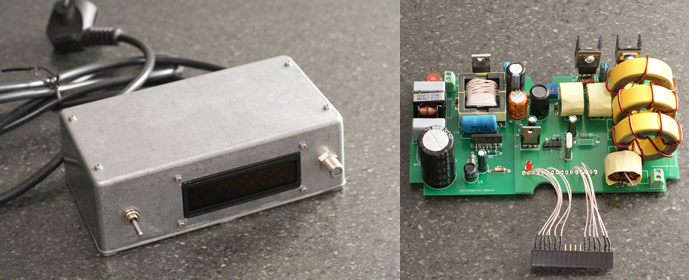
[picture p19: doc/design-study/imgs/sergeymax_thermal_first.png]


Here's a fun question to hold in your head: Why are the actual Metcal or Thermaltronics stations so gigantic when SergeyMax's unit look so small? The differences are huge.

The builder over at EEVblog named `rfmerrill` has a photo of his own build and he stuck the MOSFETs against the enclosure wall with some thermal pads in between.

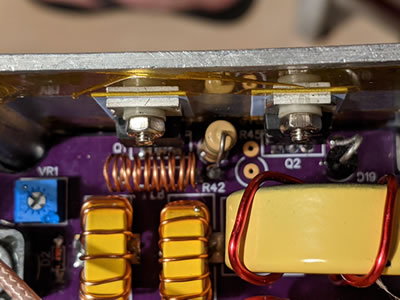
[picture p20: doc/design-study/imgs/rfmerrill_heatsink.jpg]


`rfmerrill` did mention that:

> recommend connecting a nearby ground to Q2's screw to shunt the capacitive coupled noise that will otherwise return through the housing and output jack

also

> Switch the main power transistor back to the "good" silpad from the cheap amazon one (which I used briefly because I couldn't find the good ones)

Years later, SergeyMax released a follow-up video. In it, his own unit has operated for a few years but he added a gigantic heatsink and a small cooling fan to it

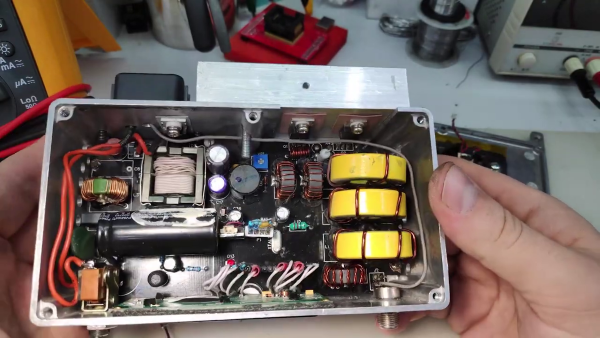
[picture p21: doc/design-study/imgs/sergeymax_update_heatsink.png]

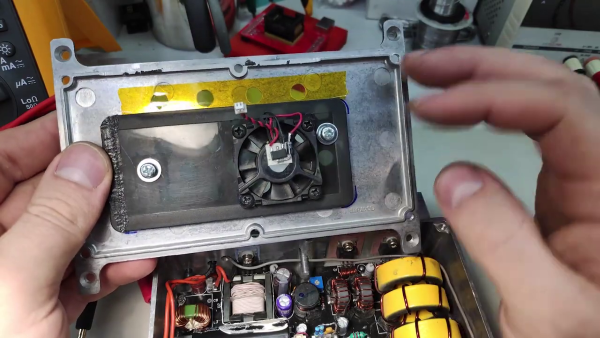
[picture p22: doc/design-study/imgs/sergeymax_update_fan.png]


This prompted me to update my design. I will put a Noctua NF-A4x10 fan inside mine. I use these fans in many places, such as on my 3D printer and a they also cool my archival external hard-drives. They are quiet and last for years.

The plan is to mount it inside the enclosure on the side, on the wall where the power input connectors are. I chose a side mount instead a top mount to lessen the chance of something falling inside the enclosure.

The MOSFETs will be mounted against a large square heatsink. The legs will have to be bent a lot for the back of the TO-220 to reach the heatsink. The heatsink is also attached to the outside of the aluminum enclosure. The assembly of this arrangement should be straight forward.

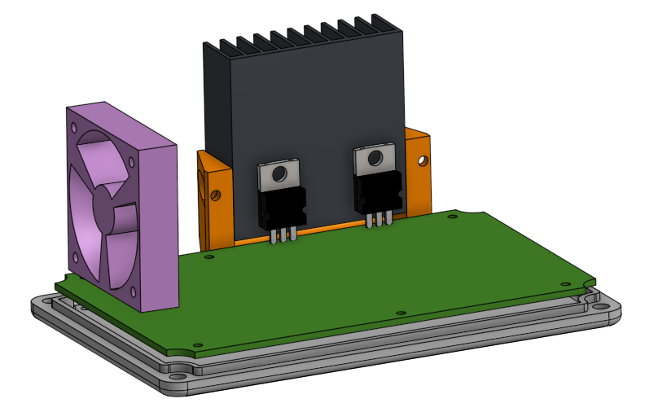
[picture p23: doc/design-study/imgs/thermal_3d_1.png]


It's hidden but there is an air exit at the foot of the MOSFETs. There is a 3D printed air-duct that will redirect exiting airflow up through the heatsink fins.

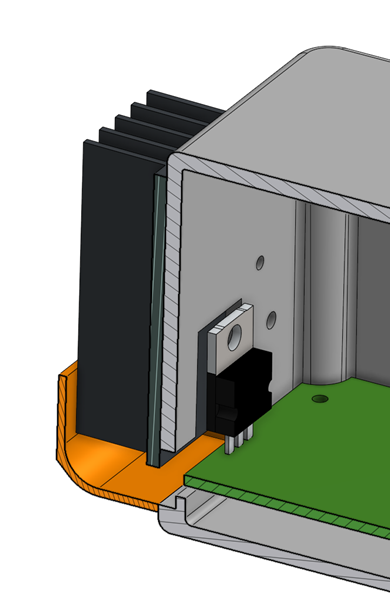
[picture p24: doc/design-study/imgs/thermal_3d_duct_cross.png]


To encourage the airflow through this exit, all other air escape gaps not useful for cooling are covered by 3D printed features.



To further prevent debris from entering the enclosure, a louvered air intake grille is 3D printed, with slats facing downwards.



Back to the question I posed at the start: The Metcal stations are meant for 24/7 non-stop factory operations over decades, it wants to have no moving parts, no possible dust or liquid ingress, so it's a gigantic chunk of aluminum. They remind me of those industrial computers that are also chunks of aluminum with no fans.

Our little portable DIY version of this station is definitely going to need some considerations for thermal dissipation.

## Buck Converter Cooling

The PCB is made with 2oz thick copper for better heat dissipation. This is important for the `TPS54560` buck converter. There are some vent air exit slits near where the buck converter is. That region has a brass standoff connecting that copper pour to the bottom plate of the enclosure. I also soldered on some copper cooling fins to the exposed copper pour in that region.

The `TPS54560` buck converter has its own junction thermal limit.

## Fan Control

The fan is powered by 12V. The 12V comes from a secondary buck converter and is rated for 2A. The fan is controlled by a small MOSFET. As the fan only needs about 50mA, none of this is concerning.

The fan is controlled by the microcontroller. The microcontroller drives the MOSFET, and the MOSFET is used for low-side switching the fan. Additionally, the circuit can be reconfigured:

 * the microcontroller can drive a PWM signal directly
 * the MOSFET can drive a PWM signal as open-drain (the microcontroller will invert the signal)
 * the MOSFET can be driven with PWM and attempt to speed-control a fan that lack PWM inputs

The firmware allows the user to pick between 16 different fan control modes, in three broad categories:

 * simple and force the fan to a certain speed
 * automatic modes triggered by a particular temperature threshold
 * adaptive modes that adjusts fan speed based on temperature detected

## Temperature Sensors

The microcontroller always has its own internal temperature sensor that is being monitored, but it is questionable if this is useful, as it is placed very far away from RF and power components.

There are connections and voltage dividers for two NTC thermistors. These are optional, but I have attached the NTC thermistors to the plastic casing of the two main MOSFETs.

The thermistor is 10 kohm at 25C and have beta of 3950K, a 2.2 kohm pull-up resistor towards 3.3V is used to implement a voltage divider.

| Temp (C) | ADC reading |
|---|---|
| 0 | 960 |
| 25 | 839 |
| 50 | 634 |
| 75 | 413 |
| 100 | 246 |
| 125 | 143 |
| 150 | 85 |

Candidates for NTC thermistor: NRL2104J3950B1F (wire leads) or NRNE104H3950B1H (through hole)

## Resistor Changes from Original Design

In SergeyMax's design, he used two 2.2 ohm resistors in series (doing both source and sink) between the output of his MAX17602 and the IRF510 MOSFET. The foorprint are 0805 and the power rating is not specified, but I think 0805 can go up to 0.5W if you shop hard enough. In my design, I have two 3.6 ohm resistors here doing the same job, one for source and one for sink. Calculations showed that these should be worst case 0.75W rated so I used a 1206 footprint instead.

The 22 ohm resistor used at the input of the tip-detector circuit is an ordinary 0805 footprint resistor in SergeyMax's design. Many EEVBlog users reported that this resistor tended to fail when the tip is actually removed. In my design, these have been beefed up to a 2512 footprint resistor rated for 2W. Better safe than sorry.

At the gate of the main amp MOSFET, there are 150 ohm resistors that SergeyMax specified to be 2W rated and he used a axial package. In my design, I still used a 2W rating but I used a SMD 2512 package, with plenty of ground stitching vias (and 2oz copper PCB). for 12V DC conditions, 150 ohm should cause a bit under 1W of heat, and this net is supposed to be a 12V RF gate clock so we expect a bit less.

## Airflow Napkin Math

(note: numbers are from the design on August 26 2026, final numbers may have changed)

Intake area: fan represented as two circles, 38mm OD and 18mm ID, giving an oriface area of 880mm^2

Outlets for buck converter cooling: 40mm^2 to 60mm^2

Outlet for MOSFET cooling: 45mm x 8.6mm = 387mm^2

Outlets for inductor cooling: 2x or 4x or 6x 4mm diameter holes, oriface area ranging from 25mm^2 to 75mm^2

Useless outlets: 25mm x 5mm and 20mm x 5mm, 225mm^2 total



Generated using `doc\tools\airflow_pie_chart.py`

This rough estimate only tells me:
 * I can afford to have those 6 holes for the toroid cooling, maybe even more. The magnetic properties of those toroids do depend on temperature a bit.
 * I should put in an effort into mimizing the useless air outlets

## Cooling for the Lite Version

I've met with the developers of Radio Thermal, I commented on how big their design is but most of it was taken up by the fan. They replied that it does still work without the fan, but they do not make claims about its performance without the fan.

In my design, there's still a fan and a heatsink (actually two heatsinks stuck together) on the MOSFET. The air is blowing against the heatsink and the toroids internally.



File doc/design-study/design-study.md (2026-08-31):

Designing Hot-Wand was the result of me being inspired by these projects, and then studying them

[SergeyMax's GitHub](https://github.com/SergeyMax/SolderingStation), and SergeyMax's [blog post](https://habr.com/en/articles/451246/) (note: this is a translated version from Russian)

[Radio Thermal's GitHub](https://github.com/RadioThermal/RadioThermal_Soldering_OSHW) and Radio Thermal's [website](https://radiothermal.com/)

At the heart of both is a RF class E amplifier, followed by an impedance matching circuit. Drive the amplifier at the specified frequency and it will output RF power to the iron cartridge.

The Radio Thermal design uses a ATtiny microcontroller to generate the 470 kHz square wave that drives the gate of the MOSFET in the amplifier. There's no power preconditioning or any feedback, nothing fancy, it is extremely simple.

SergeyMax's efforts stemmed from tearing down an actual Metcal soldering station, reverse engineering it, and then building a cheap compact replica. It is way more complicated.

(for personal reasons, I wanted to build a 13.56 MHz version, hence why the extra effort, these reasons may not be totally right in hindsight but that's what I did lol)

In SergeyMax's design, there are the major sections:

 * AC power input, which provides the DC input to the main buck converter and also has a tapped 10V-ish for the gate driver
 * main buck converter, set to about 20V but adjustable, with high side current measurement
 * gate driver for the second gate driver, weird...
 * a second gate driver stage, this is important
 * the class E RF amplifier
 * the impedance matching network
 * a current amplifier right before the RF output
 * a tip detector that detects high voltages at the RF output and signals the microcontroller
 * linear regulators for the microcontroller
 * microcontroller and LCD screen

SergeyMax schematic (https://habrastorage.org/webt/re/41/zc/re41zcn7fyp0lb9axbbr8i0vbn0.png)

SergeyMax's schematic is a bit hard to decode as it is drawn to fit everything onto one sheet of paper and also does not use net flags. Drawing it out again into logical blocks help.

Hot Wand schematic preview

### Input Power

I can blow away the AC power input section and replace it with a DC power input quite easily (most other builders of his design also removed his AC power input, because it's designed for Russia's 220V AC). I don't want to play with wall AC power and would rather delegate that to off-the-shelf USB-PD chargers and power banks.

The Radio Thermal design does not use a buck converter so the RF power input is the unconditioned DC power input. SergeyMax's design uses a buck converter, his design is wall powered so it's gotta have something to take AC power from a transformer and turn it into steady DC. You can't just rectify it and pray. The output from a transformer, even if rectified, is unregulated, with substantial ripple and a voltage that varies with load because of the transformer's finite source impedance.

The buck converter in SergeyMax's design implements a feedback network with an adjustable pot and also has a feedback from the current transformer. The adjustment pot sets the "typical" output voltage of the buck converter, while the microcontroller and the current transformer are able to influence the output voltage further.

For my own design, I really wanted to have adjustable power levels. The best way to accomplish this is to have a microcontroller interface with the feedback signal of the buck converter. So I kept it in my design (I was debating whether I can simplify it away).

The feedback from the current transformer is kind of a power saving feature for added efficiency. It is a power factor detector that tells the buck converter to chill out if the iron tip is already hot. I have a [page written about it here](current-transformer.md).

<a href="current-transformer.md">
  Current-transformer phase detector animation
</a>

You might have noticed that the buck converter circuit has a second LC stage before the current sensor and RF amplifier. This is simply a filter stage to isolate the buck converter's domain from the RF domain, the first is switching at 450 kHz and the latter is switching at 13.56 Mhz and SergeyMax picked 450 kHz and added the filter stage so these two domains don't interact or beat with each other.

Important: another builder pointed out that the 6.8kohm resistor on the buck converter feedback network is the wrong value, and will only allow for about 14V maximum output. He swapped it for a 22kohm and so did I. The original design had a 22V zener beside this resistor in the feedback network that would've capped the voltage at 22V, I upped this zener to 24V as well. My design might be considered a bit "overclocked", but you don't have to actually tune it that high. Later in this document I discuss more protection mechanisms placed around this buck converter. (in other good news, 24V zeners and TVS diodes are wayyy more common anyways, a win for DFM)

### Gate Driver

SergeyMax's design has two big MOSFETs instead of just one. One of them is the main RF class E amplifier's MOSFET, the other one is part of another smaller RF class E amplifier that drives the gate of the bigger one. The difference is that, we are now playing at 13.56 Mhz not 470 kHz. Driving a MOSFET gate at this high frequency means the charges at the MOSFET gate are moving back and forth through the gate driver much frequently. At 470 kHz, moving these charges from the positive supply into the gate, and then out of the gate into ground, at 4A, is not problematic.

The dilemma is that, the RF amplifier needs a big beefy MOSFET that can survive high currents and high voltages (the reverse engineered unit had a MOSFET rated for 500V), but big silicon means big gates, which means big gate capacitance.

This simulation below is representing an ordinary push-pull driver at 12V, driving into a 800 pF capacitor pretending to be a MOSFET gate:



At 13.56 MHz, this becomes upwards of 4W of heat being wasted, by very small parts.

The solution is to use a first stage with a MOSFET chosen to have a very very small gate capacitance, and it can be small because this amplifier only needs to generate about 12V with almost no real current. This MOSFET, along with the inductors and capacitors around it, form another smaller class E amplifier with a resonant tank. This resonant tank is resonanting at 13.56 MHz, bouncing the charges in and out of the gate of the much bigger MOSFET. The charges are being recycled, instead of going in a DC circuit from positive to negative.

[Click here for a more in-depth study of the power consumption comparisons](gate-driver-method-comparison.md)

There is an inductor in the design to tune the resonance of this circuit. The instructions from SergeyMax basically says: make a coreless coil with wire, 10 loops of wire about 5mm in diameter and 10mm wide, you need to stretch or compress this until you tune the resonance correctly.

| Coil Width | Napkin Math Inductance |
|---:|:---|
| 5 mm | 375 nH |
| 10 mm | 224 nH |
| 15 mm | 160 nH |

You might want to start off with 15 mm wide and then compress it until it is tuned, because it is harder to stretch it when it is on a PCB.



I plugged this into a simulator and was able to play with the inductance until the current consumption dropped to 100mA at 12V. 1.2W vs 4W, and moving the heat away from the small parts. Not bad.



If you go overboard with stretching the coil then you end up with an output waveform either not low enough or not high enough. The wave form must at least reach 0V or else the next MOSFET won't actually ever turn off, which would essentially cause a short circuit event.



The MOSFET STP19NF20 datasheet says it has a C_iss of 800 pF. The calculation for this L becomes `L = 1 / ((2 * pi * 13.56e6) ^ 2 * 800e-12)` which is `= 172 nH`. The schematic rounded this as 180 nH. The reactance from L8 nearly cancels out the reactance of the Q1 gate

`X(L8)       = 2 * pi * 13.56e6 * 180e-9         = 15.34 ohms`

`X(Q1 gate)  = 1 / (2 * pi * 13.56e6 * 800e-12)  = 14.67 ohms`

If we choose a different MOSFET wit ha different C_iss, then the tuning will change.

### Impedance Matching Networks

Analysis on how the impedance matching networks work are written in these two pages:

 * [For the Hot-Wand 13.56 MHz](impedance-matching-13.56MHz.md)
 * [For the Hot-Wand-Lite 470 kHz](impedance-matching-470kHz.md)

### Protections

SergeyMax's design has a ton of TVS diodes and Zener diodes protecting these MOSFETs. He did explicitly say that the Metcal unit used a 500V rated MOSFET, but keeping in mind his blog post is from 2019, he found that MOSFET to be too expensive and found a smaller one rated 200V, and just added more 150V TVS diodes. I looked up that bigger MOSFET today... $20 each, so I feel him.

But why did the Metcal use a 500V rated MOSFET and SergeyMax decide that 150V is enough? The circuit isn't actually supposed to let that V_DS voltage get that high in normal operation, when a proper RF soldering iron cartidge is installed, the output impedance is matched and there is a place for all the energy to go. When you unplug the iron cartridge, the output is open circuit and there's nowhere for the energy, stored as magnetic fields in the inductors, to go. The inductors will spike the voltage to hundreds of volts.

Even if you had a detector for disconnection of the cartridge, your MOSFET must survive this spike somehow, either by being rated very high, or having a TVS diode buddy taking it. It does not matter how fast your tip detection circuit works, the energy is already stored, if it has no where to go, even shutting down the RF generator does stop the voltage spike from happening.

### Tip Detector

There is a NPN transistor and some surrounding circuitry that is triggered by the disconnection of the iron cartridge, and signals to the microcontroller. The microcontroller's job is to stop the generation of the RF wave signal if the tip is detected to be disconnected. SergeyMax's firmware will retry to see if the tip reconnected automatically after a few seconds, which is similar to what actual Metcal stations do. My firmware does not and requires the user to press the button to confirm the tip swap has been completed.

The way it works is that a tiny DC current is constantly fed into the iron tip, diverting it to ground. If the tip is not there, that current builds up a charge in a capacitor and then goes through the transistor base instead. [A full study on how this works is available by clicking here](tip-detector.md)

### Microcontroller

The last bit I needed to study is how the microcontroller is generating the 13.56 MHz signal. SergeyMax used a STM32F030F4P6 and a 27.12 MHz crystal in the circuit. The STM32 uses its timer to generate a PWM signal with period of 2 system clock ticks, resulting in a 13.56 MHz square wave.

While SergeyMax used a classic HD44780 chipset 16x2 LCD screen, I wanted to use a SSD1306 chipset OLED screen, which means using I2C. SergeyMax used one of the I2C pins for the PWM generation so I had to reassign the PWM generation pin to another timer channel, not a huge deal. Writing out the code a bit while integrating the U8g2 graphics library into it, it seemed likely that my code will exceed 16kb, so I made sure my circuit is compatible with both the STM32F030F4P6 and the STM32F042F6P6, which has the same footprint but 32kb of flash memory.

Fun fact... more modern STM32 families, like STM32C or STM32G, don't offer the same pin-out or crystal inputs for their smaller packages. But luckily, while exceeding 16kb, the firmware is still under 32kb, so I don't need to upgrade beyond a STM32F042.

With all the pins assigned, I still had two ADC capable pins left, so I added footprints to connect two NTC thermistors, just in case I want to monitor temperatures in the circuit somewhere. The buck converter is going to get hot but it's got an internal thermal cutoff, the two MOSFETs do not have anything monitoring them, so these are the primary suspects.

### DC Power Input

The power input in my design is my own design, it is not derived from either of the preceding projects.

For battery power, I put in a XT30 connector in my design, as the choice is between XT30 and XT60, and I simply will more likely need it to be XT30. My own small combat robots all use XT30 and our team's bigger robots use other much bigger connectors.

For USB-C power input, it uses a USB-PD negotiation IC [AP53781](https://www.diodes.com/part/view/AP53781), compatible with PD3.2, to obtain 28V (from EPR, Extended Power Range). This IC is quite simple, you pick the voltage and current using two resistors. You can also pick "automatic" for the current. The hope is that, if 28V is unavailable from the connected charger, then it will fall back to the next lower voltage, which is 20V.

I chose to use a USB-C charge-only connector to simplify the layout, which means there are no data signals. This means the connector is incompatible with Qualcomm QuickCharge. AP53781 can only negotiate QC up to version 3.0 which is capped at 36W, way too low anyways. So it's not a big deal to not have USB data signals.

With two power inputs, I need one to not explode the other, especially the battery. That's why I added an ideal-diode controller to the circuit. If the USB power is detected, the ideal-diode controller is simply shut down via its enable pin. This prevents 28V from USB from making a 20V lithium battery explode if somebody plugs in both. And vice versa, a battery is also not able to damage a USB charger because the ideal-diode controller would be shut down.

I am not using a 10V tap from a AC transformer like SergeyMax, instead, I've placed a 12V fixed voltage buck converter in the circuit. This powers the gate driver and the cooling fan. The microcontroller is also powered by a similar 3.3V buck converter. These are small and compatible with 78XX series voltage regulators.

Leaving out a barrel jack in my design is a deliberate decision.

I also added a classic glass fuse in my design. I expect it to be appreciated during a short circuit event or a MOSFET failure.

There is some inrush current to worry about. This is discussed later.

### Thermal and Cooling

SergeyMax talked about how the buck converter needed ground via stitching under the IC's exposed bottom pad, plus the vendor uses 2oz copper. SergeyMax's own layout does have the ground stitching, and he even put in a lot of effort making sure the ground plane isn't partitioned near the buck converter.

In my own design, I follow the same practices, and in addition, I put a heatsink and standoff in the area near the buck converter IC. The standoff is made of brass and will conduct some heat from that area of copper to the aluminum enclosure.

SergeyMax's photos shows he's put small generic heatsinks onto the backs of the MOSFETs. I have also put heatsinks on my MOSFETs, and the heatsinks are pressed against the aluminum enclosure for extra effectiveness. I do have to bend and cut my heatsinks so they fit in the design though, a bit inconvenient.

The Radio Thermal design uses a decently sized cooling fan, but when I talked with the authors in person during their demo, they said it will run without the fan. However, without cooling, the magnetic properties of the inductor toroids will change and the whole circuit will go out of tune slightly, causing it to be more inefficient.

In my own design, I had plenty of PCB space and physical space to spare, so I added a small 20mm fan. It is controlled by a MOSFET driven by the microcontroller. The user can choose to leave the fan off, or always on, or use temperature sensors to determine when the fan should run.

### Hand Wound Inductor Considerations

First, if you were reading SergeyMax's post and confused as to where he put instructions for winding the custom inductors, the actual instructions are inside the schematic file, you must open it with DipTrace first, you can get a free view-only version to do so.

The instructions for the K16x8x6 9uH inductors (2 of them) are to use 22 AWG wire with 15 turns. The toroid core SergeyMax actually used only existed in Russia. The closest match I found on Digi-Key is Fair-Rite 5961004901, but the target is now around 10 or 11 turns instead of 15.

Other builders of the design have stated that landing on something 10uH is totally fine and might even work better. One community member experienced an overheating core and suspects it was because it was made of iron powder instead of ferrite.

For the current transformer that's supposed to use the same toroid core, no change is needed. Although, I did add an adjustment potentiometer just in case I need to tune the output of the feedback signal from this current transformer.

For the three large inductors, I purchased the same toroid cores T130-6 from Amidon as SergeyMax specified. The instructions are to use 16 AWG wire, and the turns are 4, 6, and 7. There's no point in attempting to wind these differently, as each turn results in such a huge difference in inductance, that you should just follow the instructions and hope for the best.

In Radio Thermal's design, they used the Kool Mu 0077932A7 core, with Aₗ = 32 nH/turn², +/- 8%. The first core is actually two of these cores epoxied together in a stack, making it roughly Aₗ = 64 nH/turn².

For 6.2 uH: 10 turns if using 2 cores, 14 turns if using 1 core

For 16.9 uH: 22 to 24 turns (choose 23 if no measurement)

For 11.5 uH: 18 to 20 turns (choose 19 if no measurement)

They ask that you use 22 AWG wire or thicker, and use a VNA or LCR meter to verify the results.

### Additional Protections

There are online discussions about SergeyMax's design, some other people have tried to build it and ran into problems.

One person reported that the 22 ohm resistor (it's a 0805 footprint in SergeyMax's layout) "failed enthusiastically" when the tip was disconnected while the circuit was running. So in my design, I put a 2W rated resistor (2512 footprint) in it's position.

Note that a lot of builders did what I did, replace the AC converter circuit with a DC input. Note that SergeyMax designed his AC input for Russian 220V and not American 120V, hence why so many people did that.

One person claimed that the buck converter or one of the MOSFETs can fail if the input power is removed suddenly (which is less of a problem if the input is AC). I had enough board space and firmware memory left to approach this problem from multiple angles:

 * Added a TVS diode at the output of the buck converter where it supplies the RF amplifier. The amplifier itself already has a TVS protecting it above 150V, the new TVS diode is on the input side starting protection from 24V.
 * Added a output-to-input diode to the buck converter, providing an additional path parallel to the internal MOSFET body diode, when there's backward current.
 * Firmware is set to halt RF generation immediately when a sharp input voltage drop is detected
 * Firmware is set to halt RF generation immediately when an output voltage exceeds 25V

Both the 12V and 3.3V auxiliary power regulators (they are buck converters too but can also be replaced with linear regulators) also have diodes that protect from reverse current.

The battery input is always protected by an ideal-diode implementation, so that even if the user mistakenly connects both the battery and the USB port, the battery doesn't explode.

An additional MOSFET protects the AP53781 from high battery voltage, the rating for AP53781 is 31V and the battery might be as high as 35V. This MOSFET is driven by the AP53781 itself so the AP53781 is acting like the ideal-diode controller. The additional gate capacitance being driven by a current limited gate driver means all of the MOSFETs will turn on slower, which slows down inrush current into the big bulk capacitor, which is actually a good side effect.

Plus, there's a 20x5mm glass fuse that will blow during over-current. The upstream shouldn't explode.

I threw in some TVS diodes around the XT30 input, the USB input, and the tactile button, as protection against static electricity.

### Lite Version, Reducing Power

For the Lite 470 kHz version that is a copy of Radio Thermal's design, which is asking for a 20V 5A power supply, this is a little tricky. The problem is that, the premise of the project is to add USB-PD as a power input, but, only the USB-C cables with a E-marker inside are capable of 5A. This is very annoying and I'd like to implement a reduced power mode just so it would work with 3A instead, which can make it work with normal USB-C cables and 65W USB-C chargers. The constraint is that we cannot add a buck converter into the design.

To overcome all this... this topic deserves [its own page, please click here](lite-power-attenuation.md)

### Inrush Current Study

My design uses large bulk capacitors at the input, and also, I've allowed it to be connected to up to 8S worth of batteries, almost 34V. This would make the XT30 connector spark if the inrush current is uncontrolled.

The Radio Thermal design features a NTC inrush limiter on the barrel jack. In my design, the AP53781 slowly opens the MOSFET that gates the VBUS power, slow enough to act as an inrush limiter. When the MOSFETs connect, the inrush towards the input bulk capacitor should not exceed 2A. If 2A is tripping the USB power supply then we have bigger issues. The RF amplifier should not cause a large inrush when starting. The MOSFET will turn on and the inductor will essentially block the current surge (limits initial `di/dt`) that you would expect.

That leaves the XT30 connector to worry about, but I don't want to use an NTC inrush limiter, as it will waste a lot of power, we're talking about several watts. The more advanced 13.56 MHz design is a lot more dynamic in terms of current consumption as it has both circuitry and firmware that dynamically adjusts the power being supplied to the iron. So an NTC inrush limiter will very frequently cool back down and become very resistive. This both wastes energy and causes a delay in the soldering iron's thermal response.

There is an ideal-diode implementation in the way of the inrush, but the body diode of the MOSFET there will still conduct, so it's not helpful in blocking inrush. It will see a large pulse but expected to survive. I've selected some seriously overkill MOSFETs already.

Another idea that was explored: using the `LM74700` ideal-diode controller to block the inrush by giving it a back-to-back MOSFET instead of a single MOSFET. This was studied and determined to be not feasible, the problem being that the incoming voltage will blow up the second MOSFET's `V_GS`. Texas Instruments explicitly says the `LM74700` does not support this because its off action is to connect GATE to ANODE; that only guarantees `V_GS=0` for the input-side MOSFET.

So the real solution is to use a Texas Instruments `LM74810`. These are basically ideal-diode controllers for back-to-back NFETs. I implemented the inrush limiting feature according to the recommendation in the datasheet, it involves a resistor and capacitor on the HGATE signal.

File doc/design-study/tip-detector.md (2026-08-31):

# Tip Detector

The tip detector shuts down RF generation when the handpiece or cartridge becomes electrically disconnected. A disconnected load also causes the RF output voltage and the class-E MOSFET drain voltage to rise, but that voltage rise is not what this circuit directly measures.

The circuit is primarily a **DC continuity detector with an RF low-pass filter**. It injects a few milliamps of DC into the RF output. A connected cartridge provides a low-resistance DC path to ground and holds the detector low. An open connector or cartridge removes that path, allowing the bias voltage to turn on Q3.

(There is no diode RF rectifier or calibrated envelope detector in this circuit. Residual RF could be rectified by Q3's base-emitter junction, but that is an unwanted secondary effect and not the intended detection mechanism.)

## Circuit

The relevant portion of the circuit is approximately:

```text
3.3 V -- R19 470 ohm --------------+
                                   |
                                   |
RF-OUT -- R21 22 ohm -- L9 22 uH --+-- R22 2.2 kohm -- Q3 base
                                   |
                                C42 33 nF
                                   |
                                  GND

3.3 V -- R18 4.7 kohm --+-- (microcontroller GPIO)
                        |
                        |
                    Q3 collector

Q3 emitter -- GND
```

The output logic is active-low:

| Physical state | Q3 | `TIP-DET` / PA5 |
|---|---|---|
| Tip connected | Off | High: tip present |
| Tip disconnected | Saturated | Low: tip absent |





## DC Operation

At DC, L9 is approximately a short circuit and C42 is an open circuit. The detector therefore sees the DC resistance of the cable, connector, handpiece, and cartridge through R21.

Define:

```text
RBIAS = R19 = 470 ohm
RLOAD = R21 + resistance of cable, connectors, handpiece, and tip
RBASE = R22 = 2200 ohm
```

Before Q3 starts conducting, the detector-node voltage is approximately the ordinary divider result:

```text
VDET = 3.3 * RLOAD / (RBIAS + RLOAD)
```

With a connected tip whose complete DC loop resistance is only a few ohms, `RLOAD` is dominated by R21's 22 ohms. For example, using 2 ohms for the external loop gives:

```text
VDET = 3.3 * 24 / (470 + 24) = 0.160 V
```

This voltage is far below the base-emitter voltage needed to turn on Q3, so Q3 remains off. The DC continuity-test current is approximately:

```text
ITEST = 3.3 / (RBIAS + RLOAD)
```

For the illustrative 2-ohm external loop, the normal test current is:

```text
ITEST = 3.3 / (470 + 24) = 6.68 mA
```

This is too small to heat the cartridge appreciably.

When the tip is disconnected, `RLOAD` becomes effectively infinite. The 3.3 V bias then flows through `RBIAS`, `RBASE`, and Q3's base-emitter junction. Using a nominal `VBE` of 0.65 V:

```text
IB = (3.3 - 0.65) / (470 + 2200) = 0.99 mA
```

R18 only asks Q3 to sink approximately:

```text
IC = (3.3 - VCE(sat)) / 4700 = approximately 0.66 mA
```

The available base current is consequently much greater than necessary, so an open tip drives Q3 deeply into saturation. The [BC846B datasheet](https://assets.nexperia.com/documents/data-sheet/BC846_SER.pdf) specifies the B gain group at `hFE = 200` to `450` at 2 mA and gives a maximum `VCE(sat)` of 0.2 V under its stated saturation test. Even using 0.2 V as a conservative collector-low estimate, the result is safely below the STM32's guaranteed low-input limit.

### Approximate resistance trip point

At the instant Q3 begins to turn on, base current is still small. Taking `VBE = 0.65 V`, the approximate external-loop resistance that raises the detector node to the switching point is:

```text
RLOOP(trip) = VBE * RBIAS / (3.3 - VBE) - R21
```

With VR2 shorted, this gives approximately:

```text
RLOOP(trip) = 93 ohm
```

This is not a precision threshold. `VBE` varies with collector current, temperature, and transistor sample; the BC846B datasheet indicates roughly -2 mV/degree C. Cable resistance, inductor winding resistance, contamination, and connector contact resistance also contribute. The useful conclusion is that **a normal low-resistance cartridge looks decisively connected, while an open circuit looks decisively disconnected**.

### Optional VR2 test-current adjustment

VR2 is not needed for normal operation. Its only intended use is to insert extra series resistance when testing different continuity currents. Adding resistance also changes the approximate resistance trip point, so the choice is not completely independent of detection behavior.

Using the same illustrative 2-ohm external loop:

| Resistance inserted at VR2 | Test current | Approximate external-loop trip resistance |
| ---: | ---: | ---: |
| 0 ohm, normal short | 6.68 mA | 93 ohm |
| 330 ohm | 4.00 mA | 174 ohm |
| 680 ohm | 2.81 mA | 260 ohm |
| 1000 ohm | 2.21 mA | 339 ohm |

Unless there is a specific reason to reduce the test current, VR2 should remain shorted. VR3 also remains shorted; R22 alone provides ample base-current limiting.

With the output open and before Q3 conducts, C42 charges through `RBIAS`. Its full charging time constant is:

```text
tauDET = RBIAS * C42 = 470 ohm * 33 nF = 15.5 us
```

It does not need to charge to 3.3 V to cause a transition. Starting near zero, the ideal time to reach 0.65 V is only:

```text
tTRIP = -tauDET * ln(1 - 0.65 / 3.3)
      = 0.219 * tauDET
      = 3.4 us
```

Base current and parasitic capacitances change the real waveform, but this shows that the detector-node transition is naturally in the microsecond range rather than milliseconds. On reconnection, C42 discharges through R21 and the low-resistance tip loop and therefore falls still faster.

## Rejection of the 13.56 MHz Signal

R21, L9, and C42 form a second-order low-pass network. Its ideal undamped natural frequency is:

```text
f0 = 1 / (2 * pi * sqrt(L * C))
   = 1 / (2 * pi * sqrt(22 uH * 33 nF))
   = 187 kHz
```

At 13.56 MHz, the ideal component reactances are:

```text
XL = 2 * pi * f * L
   = 2 * pi * 13.56 MHz * 22 uH
   = 1874 ohm

XC = 1 / (2 * pi * f * C)
   = 1 / (2 * pi * 13.56 MHz * 33 nF)
   = 0.356 ohm
```

The inductor therefore presents a large series impedance to RF while C42 holds the detector node close to RF ground. Treating the components as ideal and ignoring the relatively light bias-network loading, the RF transfer magnitude is approximately:

```text
|VDET / VRF| = |XC| / sqrt(R21^2 + (XL - XC)^2)
              = 0.000190
              = -74.4 dB
```

For illustration, 100 V peak at `RF-OUT` would produce only about 19 mV peak at the detector node in this ideal calculation. This is why describing the network merely as an "LC filter that triggers on high RF voltage" is misleading: its purpose is to keep the RF away from Q3 while allowing the DC continuity measurement through.

R21 limits current and damps the LC network. Real attenuation will differ because L9 has winding resistance, inter-winding capacitance, and a self-resonant frequency, while PCB and transistor capacitances add other RF paths. Those parasitics should be checked on the assembled board, but they do not change the basic DC-continuity operating principle.

## Collector Filtering and Logic Levels

R18 pulls `TIP-DET` to 3.3 V while C41 filters the collector signal. When Q3 is off, their time constant and corner frequency are:

```text
tau = R18 * C41 = 4.7 kohm * 3.3 nF = 15.5 us
fc  = 1 / (2 * pi * R18 * C41) = 10.3 kHz
```

The corresponding 10% to 90% rising time is approximately:

```text
tr = 2.2 * tau = 34 us
```

The falling edge is also fast because Q3 actively discharges C41. This capacitor suppresses very short disturbances and keeps RF pickup away from the microcontroller input.

At a 3.3 V MCU supply, the conservative all-I/O limits in the [STM32F042 datasheet](https://www.st.com/resource/en/datasheet/stm32f042g4.pdf) are no more than 0.99 V for a guaranteed low and at least 2.31 V for a guaranteed high. The expected collector levels of approximately 0.2 V or less and 3.3 V have ample margin.

## Firmware Behavior

`TIP-DET` is connected to STM32 pin PA5 and configured for interrupts on both edges. The firmware interprets high as connected and low as disconnected.

On either edge, the EXTI interrupt temporarily masks further tip-detector edges and starts TIM17 as a 300 us one-shot debounce timer. When that timer expires, the firmware samples PA5:

- If PA5 is high, the tip is recorded as present.
- If PA5 is low, the disconnect fault is latched and RF generation is stopped.
- RF cannot start while the fault is latched, while a debounce interval is active, or while the physical input remains low.
- The latch can only be cleared by the user when the debounced state and the live pin both say that the tip is present.

The tip-detector interrupt has the highest maskable firmware priority. That minimizes additional interrupt latency, but it does not remove the deliberate 300 us qualification period.

Combining the analog settling time, the collector filter, and firmware debounce gives a typical response on the order of 0.3 ms to 0.4 ms. At 13.56 MHz, the 300 us debounce alone spans:

```text
13.56 MHz * 300 us = 4068 RF cycles
```

## Protection Limitations

This detector prevents the amplifier from continuing to drive a disconnected load. It cannot prevent the first no-load voltage excursion: energy already stored in the matching-network inductors and capacitors must go somewhere, and even one RF cycle is much faster than the detector and firmware.

Consequently, this circuit does not replace adequate MOSFET voltage rating, the drain-voltage clamp, suitable TVS protection, correct matching-network tuning, or safe PCB layout. It is a sustained-open-load shutdown mechanism, not a cycle-by-cycle overvoltage limiter.

Unlike SergeyMax's automatic retry behavior, this firmware leaves the disconnect fault latched. Once the cartridge is connected again, the user must press the button to acknowledge the replacement before RF generation can restart.

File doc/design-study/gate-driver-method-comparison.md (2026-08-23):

# 13.56 MHz Gate-Driver Method Comparison

SergeyMax's design has two power MOSFETs instead of driving the main RF MOSFET directly. In the original SergeyMax design, a MAX17602 gate-driver IC drives the relatively small IRF510 Q2. Q2, L7, C37/C38, L8, and the capacitance of Q1 form a small RF power amplifier whose load is the gate of the main STP19NF20 Q1.

Hot-Wand preserves that two-stage RF architecture but substitutes a 1EDN8511B for the MAX17602. This substitution was selected after comparing available drivers and is considered a potentially better fit for this implementation; it is not a component used or specified by SergeyMax. In the Hot-Wand schematic, U2 therefore means the 1EDN8511B. The two stages are:

1. U2 hard-switches the gate of Q2.
2. Q2 and the resonant network move charge into and out of the much larger gate of Q1.

The apparently simpler alternative would be to delete Q2 and its RF network and connect the 1EDN8511B directly to Q1. The driver has enough *peak-current* capability to make this look plausible: Infineon specifies 4 A source and 8 A sink. Peak current is not the main problem, however. At 13.56 MHz, the average amount of charge moved on every cycle, the resulting power dissipation, and the very small thermal mass of the SOT-23 driver all matter.

## Original Driver and Hot-Wand Substitution

The [MAX17602](https://www.analog.com/en/products/max17602.html) is a dual MOSFET driver with one inverting and one non-inverting channel. Analog Devices specifies 4 A peak source and sink current, 12 ns typical propagation delay, and typical 6 ns rise and 5 ns fall times with a 1 nF load.

The 1EDN8511B is a single-channel driver with separate source and sink output pins. It provides 4 A peak source current, 8 A peak sink current, and permits separate turn-on and turn-off gate resistors. It also specifies reverse-current robustness at its output. Those features made it look attractive for controlling Q2, particularly because rapidly and firmly turning Q2 off is useful in this RF switching stage.

The substitution is not better in every specification. The MAX17602 has a shorter typical propagation delay and provides two driver channels, while the 1EDN8511B has a stronger sink output and a simpler interface for separate source and sink paths. Calling the 1EDN8511B "potentially better" means that it appears better suited to this particular implementation; final judgment still depends on the measured waveform, power consumption, and temperature at 13.56 MHz.

All calculations below that refer to U2 or to the 1EDN8511B describe the Hot-Wand substitution. They should not be read as specifications or analysis of the original MAX17602 implementation.

## Datasheet Values Used

The relevant numbers are:

| Part | Role | Input capacitance, C_iss | Total gate charge, Qg | Gate-charge test condition |
|:---|:---|---:|---:|:---|
| STP19NF20 | Main RF amplifier, Q1 | 800 pF typical | 24 nC typical | VDS = 160 V, ID = 15 A, VGS = 0 to 10 V |
| IRF510 | Gate RF amplifier, Q2 | 180 pF typical | 8.3 nC maximum | VDS = 80 V, ID = 5.6 A, VGS = 0 to 10 V |

These come from the [STP19NF20 datasheet](https://www.st.com/resource/en/datasheet/stb19nf20.pdf) and the [Vishay IRF510 datasheet](https://www.vishay.com/docs/91015/irf510.pdf). The conditions do not exactly reproduce this class-E circuit, so the results below are engineering estimates, not precision loss predictions. In particular, Qg changes with drain voltage, drain current, and the gate-voltage excursion.

The [1EDN751x/1EDN851x datasheet](https://www.infineon.com/assets/row/public/documents/24/49/infineon-1edn751x-1edn851x-datasheet-en.pdf) specifies the following typical characteristics at a 12 V supply:

- 4 A peak source and 8 A peak sink capability;
- 0.85 ohm source and 0.35 ohm sink output resistance;
- 19 ns propagation delay;
- 6.5 ns rise time and 4.5 ns fall time with a 1.8 nF test load; and
- 170 degrees C/W junction-to-ambient thermal resistance for the SOT-23-6 package on the specified test board.

The RF period is only:

```text
T = 1 / 13.56e6 = 73.75 ns
```

The propagation delay mostly shifts the waveform in time and can be compensated by phase. Rise time, fall time, power, and temperature are the harder constraints. Infineon's power-versus-frequency graph only extends to 1 MHz, so operation at 13.56 MHz is an extrapolation even though the individual timing specifications are fast enough.

## C_iss Is Useful for Tuning, but Qg Is Better for Power

C_iss is measured as a small-signal capacitance with VGS = 0 V. It is useful for the first resonance estimate for L8:

```text
L = 1 / ((2 * pi * f)^2 * C_iss)
L = 1 / ((2 * pi * 13.56e6)^2 * 800e-12)
L = 172 nH
```

That explains the nominal 180 nH L8. It does not mean that Q1 behaves like an ideal, constant 800 pF capacitor during switching. The gate-drain capacitance changes as the drain voltage moves, and the driver must also supply the Miller charge. The datasheet's total gate charge is a better starting point for driver power.

The difference can be seen with a simple capacitor calculation. Charging an ideal 800 pF gate from 0 V to 12 V requires:

```text
Q = C * V
Q = 800e-12 * 12
Q = 9.6 nC

P = C * V^2 * f
P = 800e-12 * 12^2 * 13.56e6
P = 1.56 W
```

The 9.6 nC result is much lower than Q1's specified 24 nC total gate charge. Therefore, using only C_iss would substantially understate the load seen by a hard-switching driver. It is still useful when estimating the resonant frequency because the resonator responds to incremental capacitance, but even that result must be tuned on the real hardware.

## Charge Moved on Every Cycle

For a conventional gate driver, Qg enters the gate during turn-on and approximately the same charge leaves during turn-off. Consequently:

```text
charge delivered by the supply per cycle = Qg
absolute charge moved in and out per cycle = 2 * Qg

average supply current = Qg * f
average charge traffic = 2 * Qg * f
gate-drive power from the supply = Qg * Vdrive * f
```

The 4 A and 8 A driver specifications describe brief current peaks during an edge. They do not mean that the driver continuously consumes 4 A. The averages calculated from Qg are more useful for power budgeting.

At 13.56 MHz, the charge comparison is:

| Hard-driven MOSFET | Qg used | Charge in + out per cycle | Average supply current | Average charge traffic | Power at 10 V | 12 V estimate using the same Qg |
|:---|---:|---:|---:|---:|---:|---:|
| Q1, STP19NF20 | 24 nC | 48 nC | 325 mA | 651 mA | 3.25 W | 3.91 W |
| Q2, IRF510 | 8.3 nC  | 16.6 nC | 113 mA | 225 mA | 1.13 W | 1.35 W |

The 12 V column is deliberately labelled as an estimate. Both Qg values were specified for a 0-to-10 V gate excursion, and Q1's charge is typical while Q2's is a maximum. The table is most useful for showing scale: directly hard-switching Q1 makes the 1EDN8511B handle about 2.9 times as much gate charge as it handles while driving Q2.

This also explains why a direct driver is easy at 470 kHz but troublesome here. With the same Q1 and a 10 V gate drive:

```text
Pgate at 470 kHz  = 24e-9 * 10 * 470e3   = 0.113 W
Pgate at 13.56 MHz = 24e-9 * 10 * 13.56e6 = 3.25 W

13.56 MHz / 470 kHz = 28.9
```

The driver moves the same charge on each edge, but it must do it 28.9 times as often.

### Gate resistor recommendation for the IRF510

The 13.56 MHz design uses separate 3.6 ohm turn-on and turn-off resistors between the 1EDN8511B and the IRF510. These parts must not be selected as ordinary low-power gate resistors. Using the 1.35 W, 12 V gate-power estimate above, 1EDN8511B's typical output resistances, and the IRF510's 2.5 ohm typical internal gate resistance gives approximately:

```text
P(R-turn-on)  ~= (1.35 W / 2) * 3.6 / (0.85 + 3.6 + 2.5) = 0.35 W
P(R-turn-off) ~= (1.35 W / 2) * 3.6 / (0.35 + 3.6 + 2.5) = 0.38 W
```

The [IRF510 datasheet](https://www.vishay.com/docs/91015/irf510.pdf) specifies 2.5 ohms only as a typical gate-input resistance at 1 MHz; it gives no guaranteed minimum. Conservatively ignoring that internal resistance raises the estimates to about 0.55 W for R_turn_on and 0.62 W for R_turn_off. The real losses depend on Q2's actual gate-charge operating point and waveform, but these estimates rule out ordinary 0.1 W or 0.25 W parts and leave too little assurance for an ordinary 0.5 W part.

**Recommendation:** fit both resistors with the 3.6 ohm `1206` footprint pulse-withstanding resistor rated at least 0.75 W at 70 degrees C. The Yageo part `SR1206FR-7T3R6L` is an AEC-Q200 surge-resistant thick-film resistor rated 0.75 W at 70 degrees C, giving useful margin over the expected 0.35 W to 0.38 W. Its permissible power derates above 70 degrees C, so the assembled board should be tested at continuous RF output and the resistor temperatures checked in the final enclosure.

### Estimated U2 heating while driving the IRF510

The 1.35 W gate-power estimate is the total energy dissipated among U2's output transistors, the two external gate resistors, the IRF510's internal gate resistance, and other series resistance. It is not 1.35 W dissipated entirely inside U2.

Using the IRF510's 2.5 ohm typical internal gate resistance, U2's estimated output-stage share is:

```text
P(U2 source) ~= (1.35 W / 2) * 0.85 / (0.85 + 3.6 + 2.5) = 0.083 W
P(U2 sink)   ~= (1.35 W / 2) * 0.35 / (0.35 + 3.6 + 2.5) = 0.037 W

P(U2 output stage) ~= 0.083 W + 0.037 W = 0.12 W
```

Because 2.5 ohms is a typical IRF510 value specified at 1 MHz, and no minimum is guaranteed, a conservative calculation ignores the MOSFET's internal gate resistance:

```text
P(U2 output stage)
  ~= (1.35 W / 2) * (0.85 / (0.85 + 3.6) + 0.35 / (0.35 + 3.6))
  ~= 0.19 W
```

With U2's specified 170 degrees C/W junction-to-ambient thermal resistance, 0.12 W to 0.19 W corresponds to an idealized junction rise of about 20 to 32 degrees C on the datasheet test board. This range covers only resistive loss in the output stage. It excludes quiescent consumption, input switching, internal cross-conduction, PCB thermal conditions, and other frequency-dependent losses. Infineon's power-versus-frequency data stops at 1 MHz, so 13.56 MHz is a substantial extrapolation and the assembled U2 temperature and 12 V supply current remain authoritative checks. This also explains why the video report of suspect MAX17602 devices becoming very hot cannot be accepted or rejected from gate-charge power alone: a counterfeit or unsuitable driver can have much greater internal dynamic loss than this simplified resistance model predicts.

## What Happens If the 1EDN8511B Drives Q1 Directly?

The approximately 3.25 W at 10 V, or roughly 3.9 W at 12 V, is not all dissipated inside the driver IC. It is divided among the driver's output transistors, external gate resistors, Q1's internal gate resistance, and other series resistance. Nevertheless, all of it becomes heat somewhere; none of the energy placed in the gate is recovered by a conventional push-pull connection.

As a deliberately simplified illustration, suppose the existing 3.6 ohm source and sink resistors were reused and Q1's internal gate resistance and PCB resistance were ignored. The share dissipated by U2 would be approximately:

```text
source-edge driver share = 0.85 / (0.85 + 3.6) = 19.1%
sink-edge driver share   = 0.35 / (0.35 + 3.6) =  8.9%

P(U2) ~= (3.91 W / 2) * (19.1% + 8.9%)
P(U2) ~= 0.55 W
```

At 170 degrees C/W, 0.55 W corresponds to a 94 degrees C junction rise on the datasheet test board. This estimate omits the driver's own high-frequency switching loss and is strongly dependent on layout and resistance, so the thermal margin would be uncomfortable. Adding Q1's internal resistance would reduce U2's share, but that only moves some of the heat into Q1.

The same simplified split puts about 1.6 W into the turn-on resistor and about 1.8 W into the turn-off resistor. Q1's internal gate resistance would reduce those figures, but ordinary 0603 resistors would still not be a sensible assumption for a direct-drive experiment. Reducing the external resistance makes the edges faster but moves more heat into U2; increasing it protects U2 and the resistors but increases Q1's switching time and drain switching loss.

There is also a timing problem not included in Pgate. Q1's datasheet gives typical rise and fall times of 22 ns and 11 ns under its specified test conditions. A complete RF period is only 73.75 ns. Those datasheet switching times cannot be copied directly into the class-E operating point, but they show why merely having adequate peak gate current does not guarantee a clean, efficient 13.56 MHz power stage.

## What the RF Gate Amplifier Changes

The resonant method does **not** make Q1's gate charge disappear. Approximately the same charge still moves into and out of Q1, and substantial RF current can circulate through L8 and the gate. What changes is where that charge comes from.

With a direct driver, charge comes from the 12 V rail during every turn-on and is dumped to ground during every turn-off. With L8 tuned against Q1's gate capacitance, energy alternates between the electric field in the gate capacitance and the magnetic field in L8. Q2 only has to replenish the energy lost in the real resistances and deliberately shape the oscillation. The large Q1 gate current circulates locally instead of all of it passing through the tiny 1EDN8511B package.

For the idealized 800 pF gate charged to a 12 V peak, the maximum stored energy is:

```text
E = 0.5 * C * Vpeak^2
E = 0.5 * 800e-12 * 12^2
E = 57.6 nJ
```

A hard driver draws twice that amount from its supply per cycle:

```text
Esupply per cycle = C * V^2 = 115.2 nJ
```

Half is lost while charging the capacitance and the energy remaining in the capacitance is lost while discharging it. An ideal resonator keeps the 57.6 nJ and passes it back and forth. A real resonator only needs its losses replaced. For a loaded quality factor Qloaded:

```text
Presonator_loss ~= 2 * pi * f * E / Qloaded
```

Using the idealized 800 pF and 12 V peak gives:

| Assumed loaded Q | Estimated resonator loss |
|---:|---:|
| 5 | 0.98 W |
| 10 | 0.49 W |
| 20 | 0.25 W |

This is only a scale estimate. Q1's capacitance is nonlinear, its drain is moving, L8 has resistance, and Q2 is not an ideal lossless switch. R12 also deliberately damps and discharges the Q1 gate. With a 12 V peak sine wave, R12 alone would dissipate:

```text
Vrms = 12 / sqrt(2) = 8.49 V
P(R12) = Vrms^2 / 150 = 0.48 W
```

That corresponds to a parallel quality factor of about 10 for an 800 pF load at 13.56 MHz, before coil, MOSFET, and PCB losses are counted. The actual simulated waveform has a DC offset and is not a perfect sine, so R12's real dissipation must be measured from its RMS voltage.

## Whole-Circuit Power Comparison

The important comparison is not 800 pF versus zero. The present circuit saves energy at Q1 but pays to hard-switch Q2 and to operate Q2's drain resonator.

| Method | Hard-switched gate power | Additional RF-stage power | Napkin total from the 12 V rail |
|:---|---:|---:|---:|
| 1EDN8511B directly driving Q1 | about 3.25 W at 10 V; about 3.9 W as a 12 V estimate | none | about 3.3 to 4 W, plus driver self-consumption |
| 1EDN8511B driving Q2, then resonant drive of Q1 | about 1.13 W at 10 V; about 1.35 W as a 12 V estimate | approximately 1.2 W in the existing tuned simulation | approximately 2.3 to 2.6 W, plus driver self-consumption |

The 1.2 W RF-stage figure is the simulated 100 mA draw from a 12 V source after tuning. The simulation uses an ideal source at Q2's gate, so Q2's gate-drive power must be added; otherwise the comparison double-counts the benefit. The physical board may differ substantially because the hand-wound coil, Q1 capacitance, Q2 switching loss, and waveform are all imperfect.

On this basis, directly driving Q1 from 12 V would consume roughly 4 W, while the complete resonant approach is estimated to consume about 2.3 to 2.6 W. The RF gate amplifier therefore plausibly saves around 1 to 2 W and, just as importantly, **moves much of the remaining dissipation out of the small U2 package and the small resistors**. These are still napkin estimates: the final difference depends on Q1's operating-point gate charge, the loaded Q of the resonant network, Q2's switching losses, and the actual RMS voltage across R12.

## If L8 Is Badly Tuned

As an example, suppose a badly tuned L8 makes the complete gate-drive circuit draw 500 mA from the 12 V bus:

```text
Pinput = V * I
Pinput = 12 * 0.5
Pinput = 6 W
```

The gate-drive subsystem is then receiving 6 W. The 2 A rating of the 12 V buck converter means that it can supply this current without being overloaded; it does not say where the 6 W is dissipated. A mistuned resonant network redistributes that power among its switching, damping, magnetic, and clamping losses.

The extra power caused by mistuning can appear in several places:

| Component or path | Effect of detuning |
|:---|:---|
| Q2 | Conduction and switching loss increase when its drain waveform moves away from class-E operation. The heatsink removes average heat from Q2, while drain-voltage peaks and avalanche operation remain separate electrical stresses. |
| R12 | It continuously damps the Q1 gate waveform. Its dissipation is `Vgate_rms^2 / 150`. A 17.3 V RMS waveform corresponds to its 2 W rating because `sqrt(2 * 150) = 17.3`. |
| TVS2 and D9 | They conduct when the gate waveform reaches their clamping regions. Visible clipping therefore identifies some of the additional input power as clamp dissipation. |
| L8 | Its circulating RF current can be much greater than the 500 mA drawn from the supply. Skin effect, proximity effect, and ordinary copper resistance convert part of that circulating current into heat. |
| L7 | It carries the gate amplifier's DC input current plus RF ripple. Both copper loss and core loss depend on the resulting current waveform. |
| C37/C38 and PCB resistance | Capacitor ESR, dielectric loss, and trace resistance dissipate part of the circulating RF energy. Detuning can also increase the voltage across the coupling capacitors. |
| U2, R16, and R17  | These primarily pay for charging Q2's gate rather than directly absorbing all of the additional tank loss. Q2's altered drain waveform can still change its Miller charge and the current returned through the driver. |

The 6 W figure only describes the power entering from the 12 V bus. Resonant voltage and current magnification must be considered separately. Q2's drain voltage can be much greater than 12 V, and L8's circulating current can be much greater than 500 mA. Q2's heatsink helps with its share of the real power loss, but it does not reduce either of those RF magnification effects.

L8 tuning also affects the main amplifier through Q1's gate waveform. If Q1 does not turn fully on and off at the intended times, its additional dissipation is supplied by the main adjustable buck converter. That power is not included in the 6 W gate-drive calculation, so the 12 V current measurement and the main RF power measurement describe two different parts of the circuit.

During initial tuning, the useful measurements are:
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

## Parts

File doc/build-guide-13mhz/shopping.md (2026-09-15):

# Shopping List for Hot Wand (13.56 MHz version)

This is a practical shopping list for building **one** Hot Wand (13.56 MHz version). It supplements the fabrication files and the JLCPCB-assembled board; it is deliberately not a second BOM. Parts marked `JLC-DNP=2` in the schematic are not listed here because that value only records a temporary JLCPCB stock problem.

Exact manufacturer part numbers matter unless an entry explicitly permits a substitute. Quantities below are the installed quantities for one unit. Distributor stock changes, so a Digi-Key search link is used where a durable exact-product link is unavailable.

## Parts installed on the PCB

### 12 V regulator module

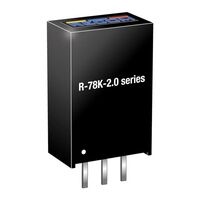
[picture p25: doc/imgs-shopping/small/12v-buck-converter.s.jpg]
12 V regulator module


Quantity: **one Recom R-78K12-2.0**. Install it at IC1 to create the 12 V rail for the power and cooling circuitry. Shop at [Digi-Key](https://www.digikey.com/en/products/detail/recom-power/R-78K12-2-0/18093036).

### 3.3 V regulator module

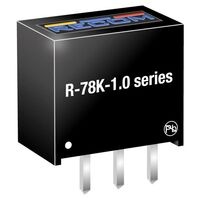
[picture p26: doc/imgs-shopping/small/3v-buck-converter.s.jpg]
3.3 V regulator module


Quantity: **one Recom R-78K3.3-1.0**. Install it at IC2 to power the controller and low-voltage logic. Shop at [Digi-Key](https://www.digikey.com/en/products/detail/recom-power/R-78K3-3-1-0/18093033).

### Inrush and reverse-polarity MOSFETs

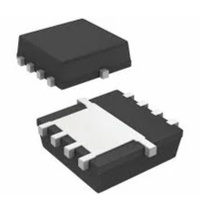
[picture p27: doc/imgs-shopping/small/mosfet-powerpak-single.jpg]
Single PowerPAK MOSFET


Quantity: **three Vishay SiS862ADN-T1-GE3 MOSFETs**. Install them at Q4, Q5, and Q7 in the power input circuitry. Shop at [Digi-Key](https://www.digikey.com/en/products/detail/vishay-siliconix/SIS862ADN-T1-GE3/10273791).

### Dual input-switch MOSFET

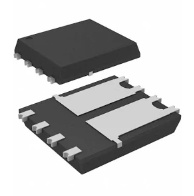
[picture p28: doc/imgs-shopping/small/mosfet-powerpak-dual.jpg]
Dual PowerPAK MOSFET


Quantity: **one Diodes Incorporated DMTH64M2LPDWQ-13**. Install it at Q6 in the USB-PD/input switching path. Shop using the exact-part [Digi-Key search](https://www.digikey.com/en/products/result?keywords=DMTH64M2LPDWQ-13).

### Main RF MOSFET

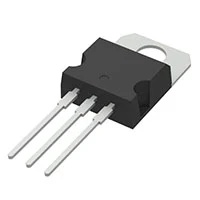
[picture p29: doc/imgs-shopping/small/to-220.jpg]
TO-220 MOSFET


Quantity: **one STMicroelectronics STP19NF20**. Install it at Q1 as the main RF amplifier MOSFET. Shop at [Digi-Key](https://www.digikey.com/en/products/detail/stmicroelectronics/STP19NF20/1852512).

### RF driver MOSFET

TO-220 MOSFET

Quantity: **one Vishay IRF510PBF**. Install it at Q2 as the RF gate driver MOSFET. Shop at [Digi-Key](https://www.digikey.com/en/products/detail/vishay-siliconix/IRF510PBF/811710).

### USB-C connector

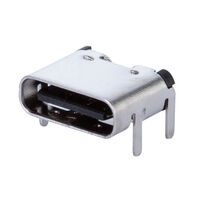
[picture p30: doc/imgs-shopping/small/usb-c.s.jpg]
USB-C connector


Quantity: **one Same Sky UJC-H-G-SMT-P6-TR**. Install it at JP2 for USB-PD input power. The drilled shell stakes and six-pad charge-only footprint must match the PCB. Shop at [Digi-Key](https://www.digikey.com/en/products/detail/same-sky-formerly-cui-devices/UJC-H-G-SMT-P6-TR/24818614).

### XT30 board connector

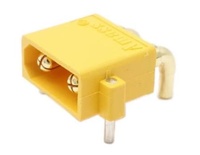
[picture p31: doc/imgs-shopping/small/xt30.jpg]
XT30 board connector


Quantity: **one XT30PW-M**. Install it at JP3 as the high-current DC input. It is the right-angle male PCB version. Search for this on your preferred online shop.

### USB-PD selection header

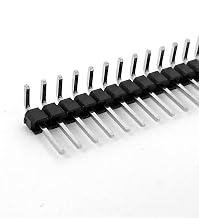
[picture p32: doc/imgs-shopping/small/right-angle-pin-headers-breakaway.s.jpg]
Right-angle breakaway pin header


Quantity: **one six-pin segment cut from a 1-by-40, 2.54 mm right-angle male breakaway header**. Install the six-pin segment at JP5 so the input voltage and current request can be selected. A long strip is inexpensive and leaves plenty of spare header for other projects. Search for [2.54 mm right-angle breakaway headers on Amazon](https://www.amazon.com/s?k=2.54mm+right+angle+male+breakaway+header+1x40).

### USB-PD selection shunts



Quantity: **two installed; buy one bulk bag of generic 2.54 mm jumper shunts**. Fit two shunts to JP5 to make the independent USB-PD selections. Prefer the taller style with a finger tab or handle because it is much easier to move in the completed unit; search for [bulk 2.54 mm pull-tab jumper caps on Amazon](https://www.amazon.com/s?k=2.54mm+jumper+caps+with+handle+pull+tab).

### 470 uF bulk capacitor

Large electrolytic capacitor

Quantity: **one Nichicon UHW1H471MPD, 470 uF, 50 V capacitor**. Install it at C6 for input-energy storage. Its 10 mm diameter and 5 mm lead spacing fit the intended footprint. Shop at [Digi-Key](https://www.digikey.com/en/products/detail/nichicon/UHW1H471MPD/3664388).

### 100 uF capacitors

Medium electrolytic capacitor

Quantity: **two Panasonic EEU-FR1H101B, 100 uF, 50 V capacitors**. Install them at C2 and C4 for local rail filtering. Their 8 mm diameter and 5 mm lead spacing match the board. Shop at [Digi-Key](https://www.digikey.com/en/products/detail/panasonic-industry/EEU-FR1H101B/2504106).

### Fuse clips

PCB fuse clips

Quantity: **two Eaton BK/1A3399-10-R**. Together they form the F1 holder for one 5-by-20 mm glass fuse. Shop at [Digi-Key](https://www.digikey.com/en/products/detail/eaton-electronics-division/BK-1A3399-10-R/1023735).

### Input fuse

Glass fuse

Quantity: **one Littelfuse 0235007.MXP, 7 A, 5-by-20 mm fast-acting glass fuse**. Install it in F1 to protect the input wiring and board during a fault; buying spares is sensible, but one is installed per unit. Shop at [Digi-Key](https://www.digikey.com/en/products/detail/littelfuse-inc/0235007-MXP/3424905).

### Input filter inductor

Through-hole inductor

Quantity: **one Würth Elektronik 744750460220, 22 uH inductor**. Install it at L1 in the input filter. Shop at [Digi-Key](https://www.digikey.com/en/products/detail/w%C3%BCrth-elektronik/744750460220/6598151).

### Axial 22 uH inductor

Axial inductor

Quantity: **one Abracon AIAP-01-220K-T**. Install it at L9. Shop at [Digi-Key](https://www.digikey.com/en/products/detail/abracon-llc/AIAP-01-220K-T/3059827).

Alternative: Bourns 5300-17-RC

### F-type handpiece connector

F-type coaxial connector

Quantity: **one Molex 0733300030 PCB F-type coaxial jack**. This is a F-type coaxial RF connector. Install it at JP1 as the 13.56 MHz handpiece output. Shop at [Digi-Key](https://www.digikey.com/en/products/detail/molex/0733300030/2755903).

### Pushbutton

Tactile pushbutton

Quantity: **one APEM MJTP1236D**. Install it at SW1 as the front-panel control button; Shop at [Digi-Key](https://www.digikey.com/en/products/detail/apem-inc/MJTP1236D/1798058).

### OLED display module

Quantity: **one 0.91-inch, 128-by-32, four-pin SSD1306 I2C module**. Install it at U4 for the user interface. Buy only a module with the board's expected physical size and pin order, **GND, VCC, SCL, SDA**; visually similar modules are wired differently. A practical source is this exact-description, [Amazon search](https://www.amazon.com/s?k=0.91+SSD1306+128x32).

### SWD programming header

Female socket header

Quantity: **one six-pin segment cut from a long 2.54 mm female breakaway socket strip**. Install it at JP4 on the underside of the board so the controller can be flashed and debugged. Buy a long strip and cut it to six positions rather than ordering a single expensive connector; search for [2.54 mm female breakaway headers on Amazon](https://www.amazon.com/s?k=2.54mm+female+breakaway+header+1x40).

### 10 kΩ potentiometer

Trim potentiometer

Quantity: **one Bourns TC33X-2-103E**. Install it at VR1. Shop using the exact-part [Digi-Key search](https://www.digikey.com/en/products/result?keywords=TC33X-2-103E).

### 1 kΩ potentiometer

Trim potentiometer

Quantity: **two Bourns TC33X-2-102E**. Install them at VR2 and VR3. Shop using the exact-part [Digi-Key search](https://www.digikey.com/en/products/result?keywords=TC33X-2-102E).

### 5 kΩ potentiometer

Trim potentiometer

Quantity: **one Bourns TC33X-2-502**. Install it at VR4. Shop using the exact-part [Digi-Key search](https://www.digikey.com/en/products/result?keywords=TC33X-2-502).

### Power-MOSFET thermistors

Quantity: **two TODO:TBD thermistors**. Install them at THERM1 and THERM2 against the two TO-220 devices so firmware can detect unsafe device temperatures.

### Four-pin fan header

Four-pin fan header

Quantity: **one Molex 0470531000**. Install it at FAN1 for the 12 V PWM fan. It is the keyed four-position PC-fan header expected by the fan cable. Shop at [Digi-Key](https://www.digikey.com/en/products/detail/molex/0470531000/2421261).

Alternative: JST `B2B-XH-A`, which is a 2 pin XH header so it won't support PWM. It is used by cheaper fans like WINNSINN. Shop at [Digi-Key](https://www.digikey.com/en/products/detail/jst-sales-america-inc/B2B-XH-A/1651045).

### Optional indicator LEDs

Quantity: **up to four 0603 LEDs**, one each for LED1 through LED4. They are visual indicators and the build guide permits them to be omitted; using different colors makes the indications easier to distinguish. Choose suitable low-current 0603 LEDs using the [Digi-Key 0603 LED search](https://www.digikey.com/en/products/result?keywords=0603%20indicator%20LED).

## Custom magnetics

### Fair-Rite toroid cores

Fair-Rite toroid core

Quantity: **three Fair-Rite 5961004901 cores**. Two are used for L3 and L7, and the third is used for transformer T1. Their material and dimensions determine the winding values. Shop at [Digi-Key](https://www.digikey.com/en/products/detail/fair-rite-products-corp/5961004901/8594132).

### Amidon T130-6 cores

Amidon toroid core

Quantity: **three Amidon T130-6 cores**. Wind L4, L5, and L6 on one core each; the `-6` material is essential to the stated turns and inductance. Shop from [Amidon](https://www.amidoncorp.com/t130-6/).

### 22 AWG magnet wire

Magnet wire

Quantity: **at least 3 m (10 ft) of solid 22 AWG enamelled copper magnet wire**. It winds L3, L7, L8, and both T1 secondaries, with margin for the one-turn primary, trimming, and one rewind. A small hobby spool is much more economical than distributor-cut wire; search for [22 AWG enamelled copper magnet wire on Amazon](https://www.amazon.com/s?k=22+AWG+enameled+copper+magnet+wire). Make sure it is solid copper, not copper-clad aluminum.

### 16 AWG magnet wire

Magnet wire

Quantity: **at least 1.5 m (5 ft) of solid 16 AWG enamelled copper magnet wire**. It winds the three large T130-6 inductors L4, L5, and L6 with working margin. Buy a small hobby spool from [Amazon](https://www.amazon.com/s?k=16+AWG+enameled+copper+magnet+wire), and make sure it is solid copper rather than copper-clad aluminum.

## Cooling and enclosure hardware

### Aluminum enclosure

Aluminum enclosure

Quantity: **one unpainted Hammond 1590T enclosure**. Shop at [Digi-Key](https://www.digikey.com/en/products/detail/hammond-manufacturing/1590T/131037).

### Main heatsink

45 mm square heatsink

Quantity: **one HSB21-454515 heatsink, 45-by-45-by-15 mm**. It cools Q1 and Q2 and transfers their heat to the enclosure wall. Shop using the exact-part [Digi-Key search](https://www.digikey.com/en/products/result?keywords=HSB21-454515).

(note: Uxcell on Amazon has 45mm x 45mm x 10mm heatsinks in packs of 5 for $8. This is compatible with our design, it is cheaper if you are using all 5, but it less effective at cooling.)

### Cooling fan



Quantity: **one Noctua NF-A4x10 PWM, 12 V, 40-by-40-by-10 mm fan**. Shop from [Noctua's product page](https://www.noctua.at/en/products/nf-a4x10-pwm).

This can be substituted for any cheap 40mm x 40mm x 10mm 12V cooling fan. Such as [WINNSINN on Amazon](https://www.amazon.com/dp/B07DB5XQ23).

### TO-220 thermal pads

TO-220 thermal pad

Quantity: **two electrically insulating silicone TO-220 pads**. Place one between each of Q1 and Q2 and the heatsink; they are required because both transistor tabs must remain electrically isolated. T-Global `DC0011/06-TI900-0.12-2A` is suitable; shop at [Digi-Key](https://www.digikey.com/en/products/detail/t-global-technology/DC0011-06-TI900-0-12-2A/3466708).

### TO-220 shoulder washers

Nylon shoulder washer

Quantity: **two nylon shoulder washers for #4 screws, approximately 3.7 mm outside diameter and 2 mm shoulder depth**. Fit one into each TO-220 tab hole to isolate its mounting screw. Shop for `12SWS0432` using the [Digi-Key search](https://www.digikey.com/en/products/result?keywords=12SWS0432).

### Thermistors

Thermistor

Quantity: **two TDK B57891M0103K000 NTC thermistors**. Epoxy one each to each of the TO-220 MOSFETs. Connect them using wires to THERM1 and THERM2 on the PCB. Shop at [Digi-Key](https://www.digikey.com/en/products/detail/tdk/B57891M0103K000/3500546).

Alternatives: `B57891M0103J000`, `B57891S0103F008`, `B57891S0103J008`, `B57891S0103H008`, `B57891S0103H009`

### #4-40 enclosure and heatsink screws

#4-40 machine screws

Quantity: **(at least) eleven #4-40-by-3/8-inch screws; buy a small box**. They fasten Q1, Q2, the heatsink, the exhaust duct, and the faceplate. Search for [#4-40-by-3/8-inch machine screws on Amazon](https://www.amazon.com/s?k=%234-40+x+3%2F8+machine+screws), or buy them from a local hardware store.

### Brass PCB standoffs



Quantity: **six female-female M2.5 standoffs, 6 mm long with a 4.5 mm hex body, made of brass**. Search for [M2.5-by-6 mm brass female-female standoffs on Amazon](https://www.amazon.com/s?k=M2.5+6mm+female+female+brass+standoff), checking the product drawing for the required body dimensions.

### M2.5 PCB screws

M2.5 screws

Quantity: **twelve M2.5-by-4 mm screws**. Use six to attach the standoffs to the PCB and six to attach the standoffs to the enclosure lid. Buy a small pack from [Amazon](https://www.amazon.com/s?k=M2.5+x+4mm+screws).

### Fan screws

M3 by 20 mm screws

Quantity: **two M3-by-20 mm screws**. They pass through the fan and its printed mounting feature.

This can be substituted liberally as long as you also substitute the nuts and washers these will screw into.

### Fan washers

M3 flat washers

Quantity: **six M3 flat washers**. They spread the fan-fastener load on the fan, and two are used for the heatsink.

This can be substituted liberally as long as they fit the screws being used with it.

### Fan locknuts

Nylon-insert locknuts

Quantity: **four M3 nylon-insert locknuts**. They keep the fan fasteners from loosening under vibration.

This can be substituted liberally as long as they fit the screws being used with it.

### Rubber feet

Rubber feet

Quantity: **four self-adhesive rubber bumper feet**. Put them on the enclosure lid so the finished unit does not slide or rest directly on its screw heads. Buy a generic sheet or bulk pack of [small adhesive rubber feet from Amazon](https://www.amazon.com/s?k=small+self+adhesive+rubber+bumper+feet).

### Copper sheet for PCB fins

Copper sheets

Quantity: **one small piece of 0.5 mm (approximately 0.020 inch) copper sheet**. Cut it into the 5 mm-tall fins described in the assembly supplement to move heat away from the regulator area into the fan airflow. A small hobby sheet is sufficient; search for [0.5 mm copper sheet on Amazon](https://www.amazon.com/s?k=0.5mm+copper+sheet), or check a local hobby or metal shop.

### Thermal paste

Quantity: **one small tube of ordinary non-electrically-conductive CPU thermal paste**. Apply it between the main heatsink and the aluminum enclosure wall to reduce their thermal contact resistance; it is not a substitute for the insulating pads beneath Q1 and Q2. Any inexpensive generic paste is adequate. Search [Amazon](https://www.amazon.com/s?k=non+conductive+CPU+thermal+paste), and do not use liquid metal.

### High-temperature epoxy

Quantity: **one small package of high-temperature two-part epoxy**. Use small amounts to secure the two thermistors in reliable thermal contact with Q1 and Q2, following the build guide and keeping it off electrical joints. A consumer metal-repair epoxy such as original J-B Weld is sufficient; search [Amazon](https://www.amazon.com/s?k=high+temperature+two+part+epoxy), or buy it from an automotive or hardware store.

### Sensor-safe high-temperature RTV silicone

Quantity: **one small tube of Permatex Ultra Red RTV Silicone Gasket Maker**. Make sure the tube is labeled sensor-safe and non-corrosive. Do not substitute an acidic, acetic-cure RTV: its cure byproducts can corrode exposed copper and other electronics. Search [Amazon](https://www.amazon.com/s?k=Permatex+Ultra+Red+RTV+Silicone+Gasket+Maker), or buy it from an automotive-parts or hardware store.

### 3D-printer filament

Quantity: **enough PETG for the final plastic parts and enough PLA for the disposable templates, if printing them yourself**. Use PETG for the faceplate, airflow parts, and anything that remains near the hot enclosure. PLA is adequate for drilling and cutting templates that are discarded after use. One standard spool of each is far more than a single unit consumes, so use filament already on hand or ask someone to print the parts.

## Handpiece and tip

Choose **one** of the handpiece systems below. The Thermaltronics, Metcal, and Hakko choices all use a standard F-type RF connection and operate at 13.56 MHz. Thermaltronics and Metcal share the STTC/SMTC cartridge ecosystem, while the Hakko FX-1001 uses its own T31 cartridges.

### Thermaltronics SHP-1 handpiece

Thermaltronics SHP-1 handpiece

The least-expensive new, directly compatible option. The SHP-1 is made for Thermaltronics' 13.56 MHz TMT-9000 system and is also specified for Metcal MX systems. It accepts Thermaltronics M-series and Metcal STTC/SMTC-series cartridges and connects through the F-type handpiece interface used by this project. See the official [Thermaltronics SHP-1 datasheet](https://www.thermaltronics.com/downloads/SHP-1_Datasheet.pdf).

### Metcal MX-RM3E handpiece



An alternative to the SHP-1. This is the conventional genuine Metcal MX handpiece, uses the F-type RF connection, and accepts STTC and SMTC cartridges as well as several newer compatible Metcal cartridge families. It is directly compatible, but costs more when purchased new; used units can be a good value. See the official [Metcal MX-RM3E page](https://store.metcal.com/en-us/shop/soldering-desoldering/hand-pieces/MX-RM3E).

### Metcal MX-H1-AV advanced handpiece



This is bling bling, almost $200 a pop. It uses the F-type RF connection and accepts STTC and SMTC cartridges. It is directly compatible but is normally the most expensive of the straightforward choices. See the official [Metcal MX-H1-AV page](https://store.metcal.com/en-us/shop/soldering-desoldering/hand-pieces/MX-H1-AV).

### Hakko FX-1001 handpiece



A directly connectable alternative to the Thermaltronics and Metcal handpieces. The FX-1001 has a standard F-type connector, operates at 13.56 MHz, and uses Hakko T31 cartridges. Hakko explicitly confirms that the FX-1001 and T31 cartridges can be used with 13.56 MHz Metcal supplies equipped with a standard F-type connector; see Hakko's official article, [Can I use my HAKKO FX-1001 Soldering Iron Handpiece and T31 Series Tips with my Metcal Power Supply?](https://kb.hakkousa.com/Knowledgebase/10637/Can-I-use-my-HAKKO-FX1001-Soldering-Iron-Handpiece-and-T31-Series-Tips-with-my-Metcal%C2%AE-Power-Supply). Also see the official [Hakko FX-1001 handpiece page](https://hakkousa.com/fx-1001-rf-induction-heating-soldering-iron-handpiece-only.html) and [FX-100 specifications](https://www.hakko.com/english/products/hakko_fx100_spec.html).

The connector and operating frequency are compatible without an adapter. However, because the Hot Wand's matching network and tip-disconnect detector were developed around an STTC cartridge, verify normal heating, power delivery, and disconnect detection with the selected T31 cartridge during bring-up.

### STTC/SMTC or Thermaltronics M-series cartridge

When using a Thermaltronics SHP-1 or compatible Metcal handpiece. Select the temperature series and tip geometry for the intended work. STTC and SMTC cartridges fit both the SHP-1 and the Metcal choices above; Thermaltronics M-series cartridges are specified for the SHP-1 but should not be assumed to fit every Metcal handle. Browse Metcal's official [cartridge and handpiece compatibility guide](https://www.metcal.com/wp-content/uploads/2026/03/Metcal_Cartridge-Guide-EN.pdf).

### Hakko T31 cartridge

T31 cartridges are made for the FX-1001 and are not mechanically interchangeable with STTC, SMTC, or Thermaltronics M-series cartridges. Choose the desired fixed temperature series and geometry from Hakko's official [T31 cartridge list](https://www.hakko.com/english/products/hakko_fx100_tips.html).

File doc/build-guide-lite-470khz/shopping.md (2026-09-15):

# Shopping List for Hot Wand Lite (470 kHz version)

This is a practical shopping list for building **one** Hot Wand Lite. It supplements the fabrication files and the JLCPCB-assembled board; it is deliberately not a second BOM. Parts marked `JLC-DNP=2` in the schematic are not listed here because that value only records a temporary JLCPCB stock problem.

Exact manufacturer part numbers matter unless an entry explicitly permits a substitute. Quantities below are the installed quantities for one unit. Distributor stock changes, so a Digi-Key search link is used where a durable exact-product link is unavailable.

## Parts installed on the PCB

### 12 V regulator module

12 V regulator module

Quantity: **one Recom R-78K12-2.0**. Install it at IC1 to create the 12 V rail used by the power stage and fan. Shop at [Digi-Key](https://www.digikey.com/en/products/detail/recom-power/R-78K12-2-0/18093036).

### Inrush and reverse-polarity MOSFETs

Single PowerPAK MOSFET

Quantity: **three Vishay SiS862ADN-T1-GE3 MOSFETs**. Install them at Q2, Q3, and Q5 as a part of the power input circuitry. Shop at [Digi-Key](https://www.digikey.com/en/products/detail/vishay-siliconix/SIS862ADN-T1-GE3/10273791).

### Dual input-switch MOSFET

Dual PowerPAK MOSFET

Quantity: **one Diodes Incorporated DMTH64M2LPDWQ-13**. Install it at Q4 in the USB-PD/input switching path. Shop using the exact-part [Digi-Key search](https://www.digikey.com/en/products/result?keywords=DMTH64M2LPDWQ-13).

### Main 470 kHz RF MOSFET

TO-220 MOSFET

Quantity: **one**, installed at Q1 as the main RF power switch.

Pick from:
* [IXFP26N30X3](https://www.digikey.com/en/products/detail/ixys/IXFP26N30X3/8032441), 300V VDS rating, "22 nC @ 10 V"
* [IXFP30N25X3](https://www.digikey.com/en/products/detail/ixys/IXFP30N25X3/7561333), 250V VDS rating, "21 nC @ 10 V", more expensive, no reason to pick this over the above, but it will work
* [IPW60R120CM8XKSA1](https://www.digikey.com/en/products/detail/infineon-technologies/IPW60R120CM8XKSA1/26424587), 600V VDS rating, "24 nC @ 10 V", there's no advantage to this part but I'm noting it down here as a comparable TO-247 part

### Main Power Inductor



Quantity: **one**, either a Pulse Electronics `PA4343.333NLT` [Digi-Key](https://www.digikey.com/en/products/detail/pulse-electronics/PA4343-333NLT/5641830) or a Bourns `SRP1265A-330M` [Digi-Key](https://www.digikey.com/en/products/detail/bourns-inc/SRP1265A-330M/4876718), populated as L1.

### USB-C connector

USB-C connector

Quantity: **one Same Sky UJC-H-G-SMT-P6-TR**. Install it at JP2 for USB-PD input power. The drilled shell stakes and six-pad charge-only footprint must match the PCB. Shop at [Digi-Key](https://www.digikey.com/en/products/detail/same-sky-formerly-cui-devices/UJC-H-G-SMT-P6-TR/24818614).

### XT30 board connector

XT30 board connector

Quantity: **one XT30PW-M**. Install it at JP3 as the high-current DC input. It is the right-angle male PCB version. Search for this on your preferred online shop.

### USB-PD selection header

Right-angle breakaway pin header

Quantity: **one six-pin segment cut from a 1-by-40, 2.54 mm right-angle male breakaway header**. Install the six-pin segment at JP5 so the input voltage and current request can be selected. A long strip is inexpensive and leaves enough spare header for JP6, JP4, and other projects. Search for [2.54 mm right-angle breakaway headers on Amazon](https://www.amazon.com/s?k=2.54mm+right+angle+male+breakaway+header+1x40).

### USB-PD selection shunts



Quantity: **two installed; buy one bulk bag of generic 2.54 mm jumper shunts**. Fit two shunts to JP5 to make the independent USB-PD selections. Prefer the taller style with a pull tab or handle because it is much easier to move in the completed unit. Search for [bulk 2.54 mm pull-tab jumper caps on Amazon](https://www.amazon.com/s?k=2.54mm+jumper+caps+with+handle+pull+tab).

### 470 uF bulk capacitors

Large electrolytic capacitor

Quantity: **two Nichicon UHW1H471MPD, 470 uF, 50 V capacitors**. Install them at C12 and C13. Their 10 mm diameter and 5 mm lead spacing fit the intended footprints. Shop at [Digi-Key](https://www.digikey.com/en/products/detail/nichicon/UHW1H471MPD/3664388).

### Fuse clips

PCB fuse clips

Quantity: **two Eaton BK/1A3399-10-R**. Together they form the F1 holder for one 5-by-20 mm glass fuse. Shop at [Digi-Key](https://www.digikey.com/en/products/detail/eaton-electronics-division/BK-1A3399-10-R/1023735).

### Input fuse

Glass fuse

Quantity: **one Littelfuse 0235007.MXP, 7 A, 5-by-20 mm fast-acting glass fuse**. Install it in F1 to protect the input wiring and board during a fault; buying spares is sensible, but one is installed per unit. Shop at [Digi-Key](https://www.digikey.com/en/products/detail/littelfuse-inc/0235007-MXP/3424905).

### SMA handpiece connector

SMA board connector

Quantity: **one SMA-J-P-H-ST-EM1 edge-launch jack**. Install it at JP1, in the orientation shown by the build guide, as the 470 kHz handpiece output. Its launch geometry must match the board footprint. Shop using the exact-part [Digi-Key search](https://www.digikey.com/en/products/result?keywords=SMA-J-P-H-ST-EM1).

### Slide switch

Right-angle slide switch

Quantity: **one Same Sky SLW-864574-5A-RA-N-D**. Install it at SW1 as the Lite unit's external control switch; the right-angle actuator and footprint are mechanically specific. Shop at [Digi-Key](https://www.digikey.com/en/products/detail/same-sky-formerly-cui-devices/SLW-864574-5A-RA-N-D/24399231).

### XIAO controller module

Quantity: **one Seeed Studio XIAO with pre-soldered headers**, as the microcontroller module. See assembly instructions to see which exact modules are compatible.

### XIAO socket headers

Female breakaway socket header

Quantity: **two seven-pin segments cut from a long 2.54 mm female breakaway socket strip**. Install them at U1 so the XIAO can be removed or replaced without desoldering the module. Buy a long strip and cut it to size rather than ordering two individual sockets; search for [2.54 mm female breakaway headers on Amazon](https://www.amazon.com/s?k=2.54mm+female+breakaway+header+1x40).

### Four-pin fan header

Four-pin fan header

Quantity: **one Molex 0470531000**. Install it at FAN1 for the 12 V PWM fan. It is the keyed four-position PC-fan header expected by the fan cable. Shop at [Digi-Key](https://www.digikey.com/en/products/detail/molex/0470531000/2421261).

### Output-selection header

Right-angle breakaway pin header

Quantity: **one four-pin segment cut from the same 1-by-40, 2.54 mm right-angle male header used for JP5**. Install it at JP6 only if the selectable output-level interface will be used; it exposes the signal-name selections documented in the build guide. Search for [2.54 mm right-angle breakaway headers on Amazon](https://www.amazon.com/s?k=2.54mm+right+angle+male+breakaway+header+1x40).

### Output-selection shunts



Quantity: **two additional 2.54 mm pull-tab jumper shunts**. Fit them across the two signal-to-ground pairs at JP6 when the output-level selection header is installed. They can come from the same bulk bag purchased for JP5; search for [bulk 2.54 mm pull-tab jumper caps on Amazon](https://www.amazon.com/s?k=2.54mm+jumper+caps+with+handle+pull+tab).

## Custom inductors

### Kool Mu cores

Kool Mu toroid core

Quantity: **five Magnetics 0077932A7 Kool Mu cores**. Use two stacked cores for L2 and one core each for L3, L4, and L5. The material, dimensions, and nominal 32 nH/turn² factor determine the winding instructions. Shop at [Digi-Key](https://www.digikey.com/en/products/detail/magnetics-a-division-of-spang-co/0077932A7/18626819).

### 22 AWG magnet wire

Magnet wire

Quantity: **at least 5 m (16.4 ft) of solid 22 AWG enamelled copper magnet wire**. It winds L2 through L5 and leaves useful margin for trimming, measurement corrections, or one rewind. A small hobby spool is much more economical than distributor-cut wire; search for [22 AWG enamelled copper magnet wire on Amazon](https://www.amazon.com/s?k=22+AWG+enameled+copper+magnet+wire). Make sure it is solid copper, not copper-clad aluminum.

### Core-stacking epoxy

Quantity: **one small package of rigid two-part epoxy**. Use a small amount to join the two 0077932A7 cores used by L2 before winding them; the joint must be thin enough that the winding-length guidance remains useful. An inexpensive consumer epoxy is sufficient; search [Amazon](https://www.amazon.com/s?k=two+part+epoxy+small+package), or buy it from a local hardware store.

## Cooling and enclosure hardware

### MOSFET heatsinks

heatsink

Quantity: **two tall stamped heatsinks for TO-220**. Stack them around Q1 as shown in the Lite build guide to cool the main RF switch and brace it against the enclosure wall.

[Assmann WSW Components V2006B @ Digi-Key](https://www.digikey.com/en/products/detail/assmann-wsw-components/V2006B/3476155)

[Boyd Laconia 504222B00000G @ Digi-Key](https://www.digikey.com/en/products/detail/boyd-laconia-llc/504222B00000G/5833)

### Cooling fan



Quantity: **one Noctua NF-A4x10 PWM, 12 V, 40-by-40-by-10 mm fan**. Shop from [Noctua's product page](https://www.noctua.at/en/products/nf-a4x10-pwm).

This can be substituted with any inexpensive 40 mm x 40 mm x 10 mm, 12 V cooling fan.

### Q1 mounting screw

#4-40 countersunk screws

Quantity: **one #4-40-by-1/2-inch countersink screw**. It passes through the shoulder washer, Q1, thermal pad, and heatsink stack shown in the build guide. Buy a small pack from [Amazon](https://www.amazon.com/s?k=%234-40+x+1%2F2+countersink+screws), or use a local hardware store.

### Q1 mounting locknut

Nylon-insert locknuts

Quantity: **one #4-40 nylon-insert locknut**. It clamps the Q1 heatsink stack without loosening in service. Buy a small pack from [Amazon](https://www.amazon.com/s?k=%234-40+nylon+insert+locknuts), or use a local hardware store.

### M2.5 screws

M2.5 screws

Quantity: **eight M2.5-by-8 mm screws**. These are used to fasten the PCB and to fasten the box halves together. Buy a small pack from [Amazon](https://www.amazon.com/s?k=M2.5+x+8mm+screws), or use a local hardware store.

Alternatives: #2 x 5/16" thread forming screws or sheet metal screws or plastite screws, M2.5 x 8mm plastite screws

### Thermal paste

Quantity: **one small tube of ordinary non-electrically-conductive CPU thermal paste**. Apply it only at the metal-to-metal heatsink interfaces shown in the build guide. Any inexpensive generic paste is adequate. Search [Amazon](https://www.amazon.com/s?k=non+conductive+CPU+thermal+paste).

### 3D-printer filament

**Enough PETG for the plastic parts**. Avoid PLA as the device might get very warm.

## Handpiece and tip

### Commercial 470 kHz handpiece

Thermaltronics SHP-K handpiece

If using the commercial path instead of the Radio Thermal handpiece. It holds Thermaltronics K-series cartridges; its original connector must be adapted or replaced to mate with the Hot Wand Lite's SMA output. Shop at [Digi-Key](https://www.digikey.com/en/products/detail/thermaltronics/SHP-KM/22491869).

#### Mating SMA cable plug

SMA cable plug

**Amphenol RF 901-9895-RFX**. This is a straight, in-line, standard-polarity SMA plug with a male center pin, so it mates with the female SMA jack at JP1. Shop at [Digi-Key](https://www.digikey.com/en/products/detail/amphenol-rf/901-9895-RFX/272187).

### K-series soldering cartridge

Thermaltronics K-series cartridges

If using the SHP-KM path. Select the geometry and temperature that suit the work; K75C002 is one example, not a universal choice. Browse the [Thermaltronics K-series catalog](https://www.thermaltronics.com/k_series.php).

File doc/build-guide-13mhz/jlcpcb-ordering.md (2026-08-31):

## PCB specifications

- Base material: FR-4
- Layers: 2
- Thickness: 1.6 mm
- Outer copper weight: 2 oz

Outer copper weight of 2 oz copper is preferred and deliberate for thermal design, it adds about $40 to the cost when building a batch of 5.

Keep the other fabrication options at their defaults.

## PCBA specifications

Select Standard PCBA and bottom-side assembly only. The top-side and omitted parts are installed by hand. Enable **Confirm Parts Placement** so component orientations can be checked before production.

## Gerber, BOM, CPL

See the `electrical/mfg` directory for the files

Sometimes, JLCPCB's parser misses the part number indicated and claims to not be able to find a part, in these cases, open the BOM file and find the part number, paste it into the search box manually.

The part numbers chosen within the BOM are selected to have the highest availability, but sometimes a part can still be out-of-stock. Handle this situation however you need to. If you choose to skip those components, make sure you remember which ones were skipped and purchase them from another distributor.

The rotations in the component placement file should be correct for the provided BOM, but you should be careful and double check against JLCPCB's placement preview.

If a part is dangerously low on stock at JLCPCB, they offer the option for you to pre-order the parts, which means "place a hold on these parts for me".

## Cost Estimate

A build batch of 5 units can cost $200 before taxes and before shipping

This is only the cost for JLCPCB, there are additional costs for other components you have to source yourself and solder manually.

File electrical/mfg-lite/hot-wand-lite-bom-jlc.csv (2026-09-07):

Comment | Designator | Footprint | LCSC Part #
 | JP5 | 1X06_LOCK
 | TVS4 | SOD323-R | C840638
 | TVS5 | SOD323-R | C840638
 | TVS6 | SOD323-R | C840638
1A 40V | D2 | SOD123FL | C8598
1EDN8511BXUSA1 | U2 | SOT95P280X145-6N-7-V | C3655509
1K | R16 R20 | 0603-RES | C21190
1n | C11 | 1206 | C3859218
1uF | C19 | 0603-CAP | C15849
2A | D1 | SMA-DIODE | C698873
2K | R14 R31 | 0603-RES | C22975
2N7002K | Q6 | SOT23-3 | C14498;C547263;C5224211;C54347659
3R6 | R3 R4 | 0603-RES | C445783
4K3 | R9 | 0603-RES | C23159
4K7 | R2 R7 R8 R22 R28 | 0603-RES | C23162
6n8 | C9 C10 | 1206 | C2182121
10n | C6 C7 C8 | 1206 | C2261646
10u | C14 C15 C16 C17 | EIA3216-KIT | C13585
15V | TVS3 | SOD-323 | C2987151
15n | C1 C5 | 1206 | C3858208
22K | R12 | 0603-RES | C31850
22n | C2 C3 C4 | 1206 | C3862155
24K | R13 | 0603-RES | C23352
33u | L1 | IND_PA4343.103NLT | C2453886
36V | TVS1 TVS2 | SMA | C134984
51K | R15 R19 R30 | 0603-RES | C23196
56K | R18 | 0603-RES | C23206
100K | R17 R21 | 0603-RES | C25803
100n | C18 C20 C21 C22 C23 C24 C25 C26 | 0603-CAP | C14663
100 | R1 R10 R11 R26 R29 | 0805 | C441975
470 | R5 R6 R23 R24 R25 R27 | 0603-RES | C23179
AMS1117-5.0 | IC2 | SOT223 | C6187
AP53781 | U4 | QFN3030-16 | C52730979
ES1J | D3 | SMA-DIODE | C64879
FAN-CONN-X4-CONN-X4 | FAN1 | FAN-CONN-X4
G3404 | Q7 | SOT23-3 | C14498;C547263;C96615
LED | LED1 | LED_LTST-S220KRKT | C284935
LM74810QDRRRQ1 | U3 | DRR0012E-MFG | C3215601
SMCJ150CA | D4 | SMC | C2649864

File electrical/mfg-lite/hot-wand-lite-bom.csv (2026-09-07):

Comment | Designator | Footprint | Asm | Mfg Part # | LCSC Part #
 | JP4 | 1X02_LONGPADS | DNP-TOP-TH
 | JP6 | 1X04_LOCK | DNP-TOP-TH
 | JP5 | 1X06_LOCK | TOP-TH
 | SJ6 | SJ_3 | DNP-BOTTOM-SMD
 | SJ7 | SJ_3 | DNP-BOTTOM-SMD
 | TVS4 | SOD323-R | BOTTOM-SMD |  | C840638
 | TVS5 | SOD323-R | BOTTOM-SMD |  | C840638
 | TVS6 | SOD323-R | BOTTOM-SMD |  | C840638
 | SW1 | SWITCH-SLW-864574-5A-RA-N-D | DNP-TOP-TH | SLW-864574-5A-RA-N-D
1A 40V | D2 | SOD123FL | BOTTOM-SMD |  | C8598
1EDN8511BXUSA1 | U2 | SOT95P280X145-6N-7-V | BOTTOM-SMD |  | C3655509
1K | R16 R20 | 0603-RES | BOTTOM-SMD |  | C21190
1n | C11 | 1206 | BOTTOM-SMD | GCM31C5C3A102FX03L | C3859218
1uF | C19 | 0603-CAP | BOTTOM-SMD |  | C15849
2A | D1 | SMA-DIODE | BOTTOM-SMD | VSSAF5N50;SL36A | C698873
2K | R14 R31 | 0603-RES | BOTTOM-SMD |  | C22975
2N7002K | Q6 | SOT23-3 | BOTTOM-SMD | 2N7002K;SSM3K388R,LF;Si2318CDS-T1-GE3;PMV60ENEAR | C14498;C547263;C5224211;C54347659
3R6 | R3 R4 | 0603-RES | BOTTOM-SMD |  | C445783
4K3 | R9 | 0603-RES | BOTTOM-SMD |  | C23159
4K7 | R2 R7 R8 R22 R28 | 0603-RES | BOTTOM-SMD |  | C23162
6n8 | C9 C10 | 1206 | BOTTOM-SMD | C1206C682JCGACAUTO | C2182121
6u2 | L2 | IND-KOOLMU-2W | DNP-TOP-MIX
10n | C6 | 1206 | BOTTOM-SMD | C3216C0G2E103J115AA | C2261646;C2170837;C2175075
10n | C7 C8 | 1206 | BOTTOM-SMD | GRM31B5C2E103JWA1L | C2261646
10u | C14 C17 | EIA3216-KIT | BOTTOM-SMD | MLASU31LBB5106KTNA01;GRT31CR61H106KE01K | C13585
10u | C15 C16 | EIA3216-KIT | BOTTOM-SMD | TAJA106K016TNJ;T491A106K016AT | C13585
11u5 | L5 | IND-KOOLMU | DNP-TOP-TH
12V R-78K12-2.0 | IC1 | TO220-BUCK-12V | DNP-TOP-TH | R-78K12-2.0
15V | TVS3 | SOD-323 | BOTTOM-SMD | SD15C-01FTG;CDSOD323-T15SC;TSD15CDYFR | C2987151
15n | C1 C5 | 1206 | BOTTOM-SMD | C3216C0G2E153J160AA | C3858208
16u9 | L3 L4 | IND-KOOLMU | DNP-TOP-TH
22K | R12 | 0603-RES | BOTTOM-SMD |  | C31850
22n | C2 C3 | 1206 | BOTTOM-SMD |  | C3862155
22n | C4 | 1206 | BOTTOM-SMD | GCM31C5C2E223JX03L | C3862155
24K | R13 | 0603-RES | BOTTOM-SMD |  | C23352
33u | L1 | IND_PA4343.103NLT | TOP-SMD | PA4343.333NLT;SRP1265A-330M | C2453886
36V | TVS1 TVS2 | SMA | BOTTOM-SMD | SMAJ36CA | C134984
51K | R15 R19 R30 | 0603-RES | BOTTOM-SMD |  | C23196
56K | R18 | 0603-RES | BOTTOM-SMD |  | C23206
100K | R17 R21 | 0603-RES | BOTTOM-SMD |  | C25803
100n | C18 C20 C21 C22 C23 C24 C25 C26 | 0603-CAP | BOTTOM-SMD |  | C14663
100 | R1 R10 R11 R26 R29 | 0805 | BOTTOM-SMD |  | C441975
470u | C13 | CPOL-RADIAL-1000UF-25V | DNP-TOP-TH | UHW1H471MPD
470u | C12 | CPOL-RADIAL-COMBO-10MM | DNP-TOP-TH | UHW1H471MPD
470 | R5 R6 R23 R24 R25 R27 | 0603-RES | BOTTOM-SMD |  | C23179
AMS1117-5.0 | IC2 | SOT223 | BOTTOM-SMD | AMS1117-5.0 | C6187
AP53781 | U4 | QFN3030-16 | BOTTOM-SMD |  | C52730979
COAX-SMA | JP1 | SAMTEC_SMA-J-P-H-ST-EM1-LGRPAD | DNP-BOTTOM-SMD | SMA-J-P-H-ST-EM1
DMTH64M2LPDWQ-13 | Q4 | POWERPAK-SO8-X2 | DNP-TOP-SMD | DMTH64M2LPDWQ-13
DNP | R32 | 0603-RES | DNP-BOTTOM-SMD
ES1J | D3 | SMA-DIODE | BOTTOM-SMD |  | C64879
FAN-CONN-X4-CONN-X4 | FAN1 | FAN-CONN-X4 | TOP-TH | 0470531000
FAN-TIEDOWN-20MM-V1 | FAN2 | FAN-20MM-TIEDOWN | DNP-TOP-TH | MS2006H12D-RSR
FUSEX20MM | F1 | FUSE_5MM | DNP-TOP-TH | 3518P
G3404 | Q7 | SOT23-3 | BOTTOM-SMD | G3404;MMFTN3404A;PJA3404A;Si2318CDS-T1-GE3;PMV60ENEAR | C14498;C547263;C96615
LED | LED2 | LED-0603 | DNP-TOP-SMD
LED | LED1 | LED_LTST-S220KRKT | BOTTOM-SMD | LTST-S220KRKT | C284935
LM74810QDRRRQ1 | U3 | DRR0012E-MFG | BOTTOM-MIX |  | C3215601
NCHAN | Q1 | TO247-COMBO | DNP-TOP-TH
PCB-ART-VER-LITE | PCB2 | PCB-ART-VERSION-LITE | DNP-BOTTOM-MECH
PCB-OUTLINE | PCB1 | PCB-OUTLINE | DNP-TOP-TH
SEEED-XIAO-SAMD21-TH-LOCKING | U1 | MODULE_102010388_LOCKING | DNP-TOP-TH
SIS862ADN-T1-GE3 | Q2 Q3 Q5 | POWERPAK-1212-8 | DNP-TOP-SMD | SIS862ADN-T1-GE3
SJ-SMALL-1206-SJ | SJ3 SJ5 | 1206-SJ | DNP-BOTTOM-SMD
SJ-SMALL-1206-SJ | SJ1 SJ2 SJ4 | 1206-SJ | DNP-TOP-SMD
SMCJ150CA | D4 | SMC | BOTTOM-SMD |  | C2649864
USBC-CHGONLY-4M-DRILL | JP2 | SAMESKY_UJC-H-G-SMT-2-P6-TR-DRILL | DNP-TOP-MIX | UJC-H-G-SMT-P6-TR
XT-CONNECTOR-XT30PW | JP3 | XT30PW | DNP-TOP-TH | XT30PW-M

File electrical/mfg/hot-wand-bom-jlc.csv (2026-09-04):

Comment | Designator | Footprint | LCSC Part #
 | JP5 | 1X06_LOCK
 | D11 | SMA-DIODE | C698873
0R1 | R1 R2 R3 | 1206 | C188071
1EDN8511BXUSA1 | U2 | SOT95P280X145-6N-7-V | C3655509
1K | R5 R8 R41 | 0603-RES | C21190
1N4148W | D7 | SOD123FL | C84367
1uF | C34 C36 C46 | 0603-CAP | C15849
2A | D10 | SMA-DIODE | C698873
2A 60V | D13 | SOD123FL | C53340922
2K2 | R9 R11 R22 R24 R27 R40 R50 R51 | 0603-RES | C4190
2N7002K | Q8 | SOT23-3 | C14498;C547263;C5224211;C54347659
3K | R48 R54 | 0603-RES | C4211
3R6 | R16 R17 | 1206 | C6301221
3V6 | D12 D14 | SOD-323 | C840638
3n3 | C8 C41 C58 | 0603-CAP | C1613
4K3 | R30 | 0603-RES | C23159
4K7 | R15 R18 R28 R29 R33 R35 R36 R38 R39 R42 R43 R44 | 0603-RES | C23162
4u7 IHLP2525CZ | L2 | IND_IHLP-2525CZ_VIS-M | C845027
10p | C55 C56 | 0603-CAP | C1634
10pF 500V | C33 | 0805 | C6629873
10u | C57 | 1206 | C13585
10u | C45 | EIA3216 | C13585
10u | C5 C43 C44 C61 | EIA3216-KIT | C13585
15V | TVS4 | SOD-323 | C2987151
22K | R4 R7 R23 R26 R34 R55 | 0603-RES | C31850
22 | R21 | R2512 | C5204054
27.12 MHz 10pF | Y1 | XTAL-4SMD-3.2X2.5-V2 | C1986817
33nF | C42 | 0603-CAP | C21117
36V | TVS3 TVS5 | SMA | C134984
39K | R47 | 0603-RES | C23153
47pF 1000V | C20 C21 C22 C23 C24 C25 C27 C28 C29 C30 C31 | 0805 | C6366545
75K | R49 | 0603-RES | C23242
82K | R25 R53 | 0603-RES | C23254
100n | C7 C35 C47 C48 C49 C50 C51 C52 C53 C54 C59 C60 C62 C63 C64 | 0603-CAP | C14663
100nF | C1 | 0603-CAP | C14663
100nF | C9 C10 C11 C12 C37 C38 | 0805 | C5182461
100pF | C39 C40 | 0805 | C6958299
100pF 1000V | C13 C14 C15 C16 C17 C18 C26 | 0805 | C6958299
100 | R10 R14 R52 | 0603-RES | C22775
100 | R31 R32 R56 | 0805 | C441975
150 2W | R12 | R2512 | C175287
270K | R6 | 0603-RES | C137755
470 | R19 R45 | 0603-RES | C23179
4148 | D5 D6 D8 | SOD123FL | C84367
AP53781 | U7 | QFN3030-16 | C52730979
BC846B | Q3 | SOT23-3 | C181138
BZT52C24 | D2 | SOD123FL | C2109
ES1J | D4 | SMA-DIODE | C64879
FAN-CONN-X4-CONN-X4 | FAN1 | FAN-CONN-X4
G3404 | Q9 | SOT23-3 | C14498;C547263;C96615
INA138 | U5 | SOT95P280X145-5N | C47914
LM74810QDRRRQ1 | U6 | DRR0012E-MFG | C3215601
SD103A | D3 | SOD-323 | C7420360
SM15T150CA | TVS1 | SMC | C133715
SMAJ24CA | TVS6 | SMA | C148223
SMBJ15CA | TVS2 | SMA-DIODE | C78809
STANDOFF-M2.5-4.5MMHEX | STANDOFF1 STANDOFF2 | STANDOFF-M2.5-4.5MMHEX
STM32F042F6P6 | U3 | SOP65P640X120-20N | C2969989
STPS3L60S | D1 | SMC | C2971007
STPS0540Z | D9 | SOD123FL | C181835
TEST-POINT-SQ-2MM | TP1 TP2 | PAD-SQ-2MM
TPS54560DDA | U1 | VREG_LM5017MR/NOPB | C31966

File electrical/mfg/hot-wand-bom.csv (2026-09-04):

Comment | Designator | Footprint | Asm | Mfg Part # | LCSC Part #
 | JP4 | 1X06_LOCK | DNP-TOP-TH
 | JP5 | 1X06_LOCK | TOP-TH
 | SJ1 | SJ_2S-NO | DNP-BOTTOM-SMD
 | SJ3 | SJ_2S-NO | DNP-BOTTOM-SMD
 | SJ2 | SJ_2S-NO | DNP-TOP-SMD
 | SJ4 | SJ_3 | DNP-BOTTOM-SMD
 | SJ5 | SJ_3 | DNP-BOTTOM-SMD
 | D11 | SMA-DIODE | BOTTOM-SMD |  | C698873
 | SW1 | SW_1-1825027-1 | DNP-TOP-TH | MJTP1236D;TL1105JAF160R1RBLK
 | T1 | XFORMER-K16X8X6-1:14:14 | DNP-TOP-TH
0R1 | R1 R2 R3 | 1206 | BOTTOM-SMD | KDV12DR100ET;VMK-R033-1.0-U | C188071
1EDN8511BXUSA1 | U2 | SOT95P280X145-6N-7-V | BOTTOM-SMD |  | C3655509
1K | R5 R8 R41 | 0603-RES | BOTTOM-SMD |  | C21190
1K | VR2 VR3 | TRIM_35WR1KLFTR_V3 | DNP-TOP-SMD | TC33X-2-102E
1N4148W | D7 | SOD123FL | BOTTOM-SMD |  | C84367
1uF | C34 C36 C46 | 0603-CAP | BOTTOM-SMD |  | C15849
2A | D10 | SMA-DIODE | BOTTOM-SMD | VSSAF5N50;SL36A | C698873
2A 60V | D13 | SOD123FL | BOTTOM-SMD | STPS2L60ZFY | C53340922
2K2 | R9 R11 R22 R24 R27 R40 R50 R51 | 0603-RES | BOTTOM-SMD |  | C4190
2N7002K | Q8 | SOT23-3 | BOTTOM-SMD | 2N7002K;SSM3K388R,LF;Si2318CDS-T1-GE3;PMV60ENEAR | C14498;C547263;C5224211;C54347659
3K | R48 R54 | 0603-RES | BOTTOM-SMD |  | C4211
3R6 | R16 R17 | 1206 | BOTTOM-SMD |  | C6301221
3V3 R-78K3.3 | IC2 | TO220-BUCK-3.3V | DNP-TOP-TH
3V6 | D12 D14 | SOD-323 | BOTTOM-SMD | ESDLC3V3D3B-TP;CDSOD323-T03SC;SD03LCC | C840638
3n3 | C8 C41 C58 | 0603-CAP | BOTTOM-SMD |  | C1613
4K3 | R30 | 0603-RES | BOTTOM-SMD |  | C23159
4K7 | R15 R18 R28 R29 R33 R35 R36 R38 R39 R42 R43 R44 | 0603-RES | BOTTOM-SMD |  | C23162
4u7 IHLP2525CZ | L2 | IND_IHLP-2525CZ_VIS-M | BOTTOM-SMD | IHLP2525CZER4R7M11 | C845027
5K | VR4 | TRIM_35WR1KLFTR_V2 | DNP-TOP-SMD | TC33X-2-502
8A 20x5mm | F1 | FUSE_5MM | DNP-TOP-TH | Keystone 3518P
9uH | L3 L7 | IND_K16X8X6_X2 | DNP-TOP-TH
10K | VR1 | TRIM_35WR1KLFTR_V2 | DNP-TOP-SMD | TC33X-2-103E
10K/~3950 | THERM1 THERM2 | 1X02-2MM | DNP-TOP-TH | B57891M0103K000
10p | C55 C56 | 0603-CAP | BOTTOM-SMD |  | C1634
10pF 500V | C33 | 0805 | BOTTOM-SMD | QCCT102Q100J1GV001E | C6629873
10u | C57 | 1206 | BOTTOM-SMD |  | C13585
10u | C45 | EIA3216 | BOTTOM-SMD | TAJA106K016TNJ;T491A106K016AT | C13585
10u | C5 C43 C61 | EIA3216-KIT | BOTTOM-SMD | MLASU31LBB5106KTNA01;GRT31CR61H106KE01K | C13585
10u | C44 | EIA3216-KIT | BOTTOM-SMD | TAJA106K016TNJ;T491A106K016AT | C13585
12V R-78K12-2.0 | IC1 | TO220-BUCK-12V | DNP-TOP-TH
15V | TVS4 | SOD-323 | BOTTOM-SMD | SD15C-01FTG;CDSOD323-T15SC;TSD15CDYFR | C2987151
15nF (DNP) | C3 | 0805 | DNP-BOTTOM-SMD
22K | R4 R7 R23 R26 R34 R55 | 0603-RES | BOTTOM-SMD |  | C31850
22uH | L9 | TFI0410 | DNP-TOP-TH | AIAP-01-220K-T
22 | R21 | R2512 | BOTTOM-SMD |  | C5204054
27.12 MHz 10pF | Y1 | XTAL-4SMD-3.2X2.5-V2 | BOTTOM-SMD |  | C1986817
33nF | C42 | 0603-CAP | BOTTOM-SMD |  | C21117
33u | L1 | IND_RADIAL_D12.7_P6.35 | DNP-TOP-TH | Wurth 744750460220 (22uH)
36V | TVS3 TVS5 | SMA | BOTTOM-SMD | SMAJ36CA | C134984
39K | R47 | 0603-RES | BOTTOM-SMD |  | C23153
47pF 1000V | C21 C22 C23 C24 C25 C27 C28 C29 C30 C31 | 0805 | BOTTOM-SMD |  | C6366545
47pF 1000V | C20 | 0805 | BOTTOM-SMD | QCCT102Q470J1GV001E | C6366545
75K | R49 | 0603-RES | BOTTOM-SMD |  | C23242
82K | R25 R53 | 0603-RES | BOTTOM-SMD |  | C23254
100n | C47 | 0603-CAP | BOTTOM-SMD
100n | C7 C35 C48 C49 C50 C51 C52 C53 C54 C59 C60 C62 C63 C64 | 0603-CAP | BOTTOM-SMD |  | C14663
100nF | C1 | 0603-CAP | BOTTOM-SMD |  | C14663
100nF | C9 C10 C11 C12 C37 C38 | 0805 | BOTTOM-SMD | CHV0805N250104KXT;MBASQ21GAB7104KTCA01;MBASQ21GAB7104MTCA01 | C5182461
100pF | C39 C40 | 0805 | BOTTOM-SMD |  | C6958299
100pF 1000V | C14 C15 C16 C17 C18 C26 | 0805 | BOTTOM-SMD |  | C6958299
100pF 1000V | C13 | 0805 | BOTTOM-SMD | QCCT102Q101J1GV001E | C6958299
100uF 50V | C4 | CPOL-RADIAL-1000UF-25V | DNP-TOP-TH
100uF 50V | C2 | CPOL-RADIAL-1000UF-25V | DNP-TOP-TH | EEU-FR1H101B;EEU-FR1J101B
100 | R10 R14 R52 | 0603-RES | BOTTOM-SMD |  | C22775
100 | R31 R32 R56 | 0805 | BOTTOM-SMD |  | C441975
150 2W | R12 | R2512 | BOTTOM-SMD | CRGP2512F150R | C175287
180nH | L8 | IND-10X6MM | DNP-TOP-TH
180nH | L4 | IND_T130-6_X2 | DNP-TOP-TH
270K | R6 | 0603-RES | BOTTOM-SMD |  | C137755
400nH | L5 | IND_T130-6_X2 | DNP-TOP-TH
470uF | C6 | CPOL-RADIAL-1000UF-25V | DNP-TOP-TH | UHW1H471MPD;EEU-FR1H471;EEU-FR1H471B
470 | R19 R45 | 0603-RES | BOTTOM-SMD |  | C23179
540nH | L6 | IND_T130-6_X2 | DNP-TOP-TH
4148 | D5 D6 D8 | SOD123FL | BOTTOM-SMD |  | C84367
AP53781 | U7 | QFN3030-16 | BOTTOM-SMD |  | C52730979
BC846B | Q3 | SOT23-3 | BOTTOM-SMD |  | C181138
BZT52C24 | D2 | SOD123FL | BOTTOM-SMD |  | C2109
COAX-FTYPE-PCB-MNT | JP1 | CONN_73330-0030_MOL | DNP-TOP-TH
DMTH64M2LPDWQ-13 | Q6 | POWERPAK-SO8-X2 | DNP-TOP-SMD
DNP | R37 R46 R46B | 0603-RES | DNP-BOTTOM-SMD
DNP | C32 R20 | 0805 | DNP-BOTTOM-SMD
DNP | C19 | 0805 | DNP-BOTTOM-SMD |  | C6958299
DNP | R13 | R2512 | DNP-BOTTOM-SMD | CRGP2512F150R
ES1J | D4 | SMA-DIODE | BOTTOM-SMD |  | C64879
FAN-CONN-X4-CONN-X4 | FAN1 | FAN-CONN-X4 | TOP-TH | WM9797-ND;0470533000
FAN-TIEDOWN-20MM-V1 | FAN2 | FAN-20MM-TIEDOWN | DNP-TOP-TH | MS2006H12D-RSR
G3404 | Q9 | SOT23-3 | BOTTOM-SMD | G3404;MMFTN3404A;PJA3404A;Si2318CDS-T1-GE3;PMV60ENEAR | C14498;C547263;C96615
INA138 | U5 | SOT95P280X145-5N | BOTTOM-SMD |  | C47914
IRF510 | Q2 | TO220V-REAR | DNP-TOP-TH
LED | LED1 LED2 LED3 LED4 | LED-0603 | DNP-TOP-SMD
LM74810QDRRRQ1 | U6 | DRR0012E-MFG | BOTTOM-MIX |  | C3215601
PCB-ART-VERSION | PCB2 | PCB-ART-VERSION | DNP-BOTTOM-MECH
PCB-OUTLINE | PCB1 | PCB-OUTLINE | DNP-TOP-TH
SD103A | D3 | SOD-323 | BOTTOM-SMD |  | C7420360
SIS862ADN-T1-GE3 | Q4 Q5 Q7 | POWERPAK-1212-8 | DNP-TOP-SMD
SJ-SMALL-1206-SJ | SJ7 SJ8 | 1206-SJ | DNP-BOTTOM-SMD
SJ-SMALL-1206-SJ | SJ6 | 1206-SJ | DNP-TOP-SMD
SM15T150CA | TVS1 | SMC | BOTTOM-SMD |  | C133715
SMAJ24CA | TVS6 | SMA | BOTTOM-SMD |  | C148223
SMBJ15CA | TVS2 | SMA-DIODE | BOTTOM-SMD |  | C78809
SSD1306-4PIN-0.91N-VERT | U4 | OLED-0.91IN-VERT | DNP-TOP-TH
STANDOFF-M2.5-4.5MMHEX | STANDOFF1 STANDOFF2 | STANDOFF-M2.5-4.5MMHEX | TOP-MIX
STM32F042F6P6 | U3 | SOP65P640X120-20N | BOTTOM-SMD |  | C2969989
STP19NF20 | Q1 | TO220V-REAR | DNP-TOP-TH
STPS3L60S | D1 | SMC | BOTTOM-SMD |  | C2971007
STPS0540Z | D9 | SOD123FL | BOTTOM-SMD |  | C181835
TEST-POINT-SQ-2MM | TP1 TP2 | PAD-SQ-2MM | TOP-SMD
TPS54560DDA | U1 | VREG_LM5017MR/NOPB | BOTTOM-MIX |  | C31966
USBC-CHGONLY-4M-DRILL | JP2 | SAMESKY_UJC-H-G-SMT-2-P6-TR-DRILL | DNP-TOP-MIX
XT-CONNECTOR-XT30PW | JP3 | XT30PW | DNP-TOP-TH

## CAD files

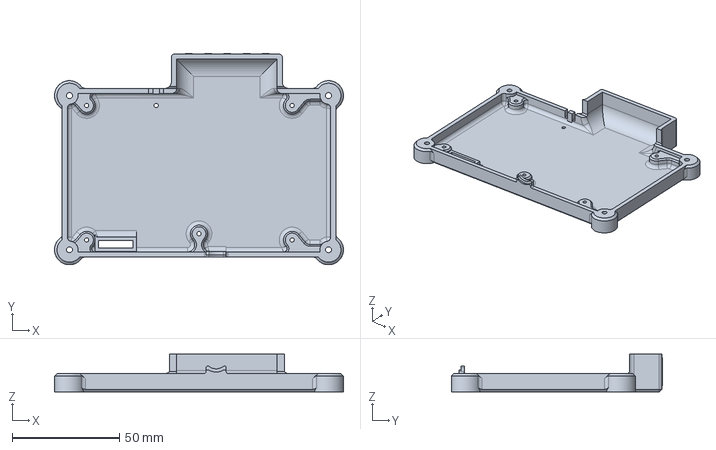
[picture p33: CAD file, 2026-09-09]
mechanical/econo/bottom-lid.step
135.0 x 98.8 x 17.6 mm

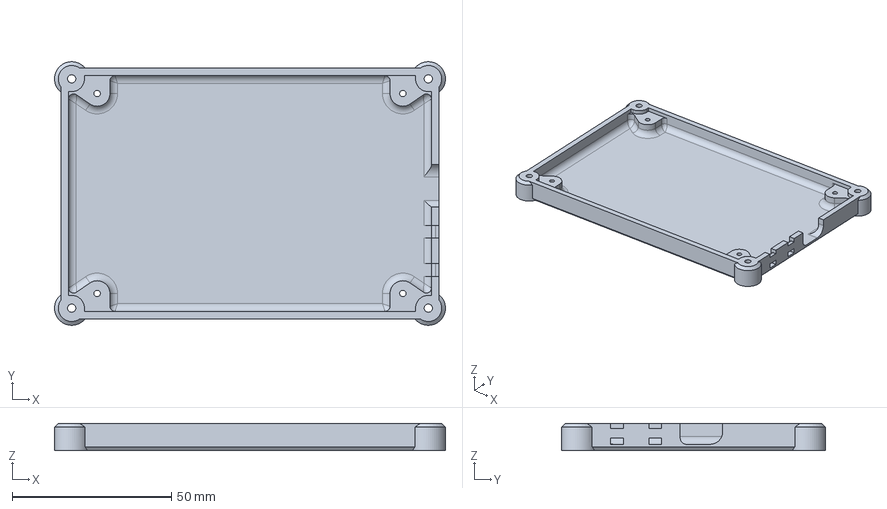
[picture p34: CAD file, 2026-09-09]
mechanical/lite/bottom-lid.step
122.8 x 82.8 x 8.60 mm

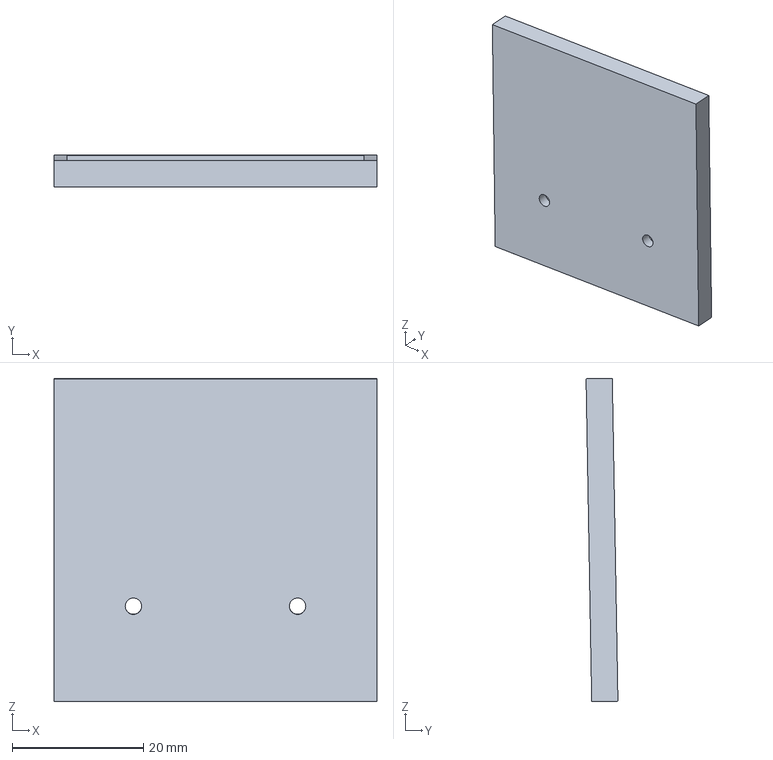
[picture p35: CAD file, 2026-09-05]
mechanical/main/heatsink-drill-template.step
49.2 x 4.86 x 49.3 mm

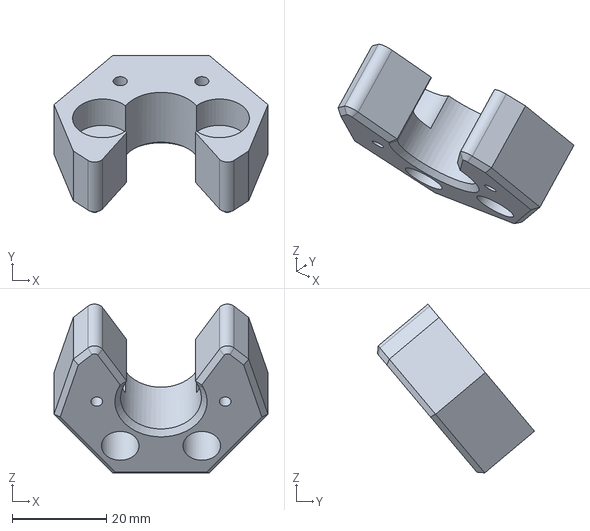
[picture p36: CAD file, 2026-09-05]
mechanical/stand/tip-shroud.step
45.5 x 33.4 x 35.9 mm

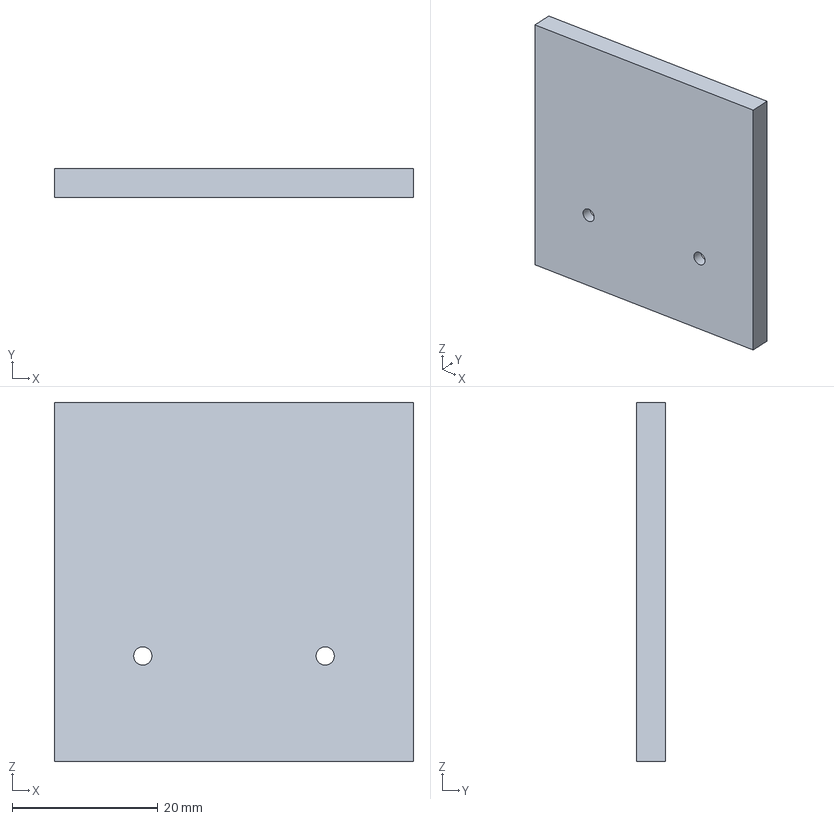
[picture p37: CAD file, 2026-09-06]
mechanical/econo/heatsink-drill-template.step
49.2 x 4.00 x 49.2 mm

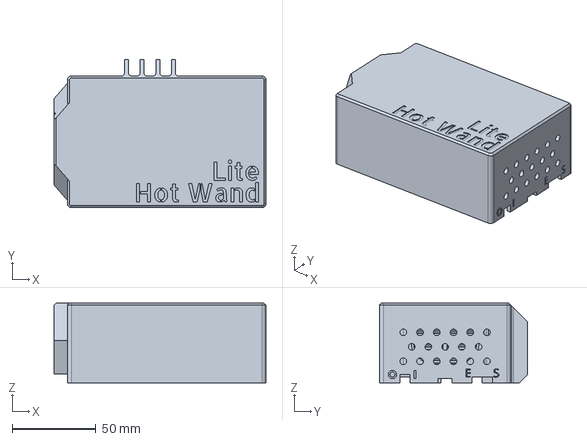
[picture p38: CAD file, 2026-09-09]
mechanical/lite/box-body.step
126.8 x 88.8 x 47.7 mm

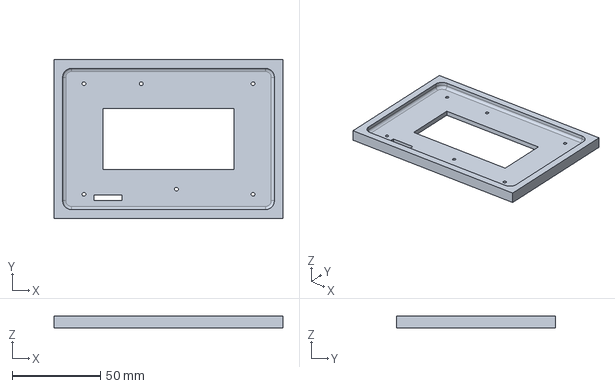
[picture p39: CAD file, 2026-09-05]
mechanical/main/lid-template.step
130.0 x 90.0 x 7.00 mm

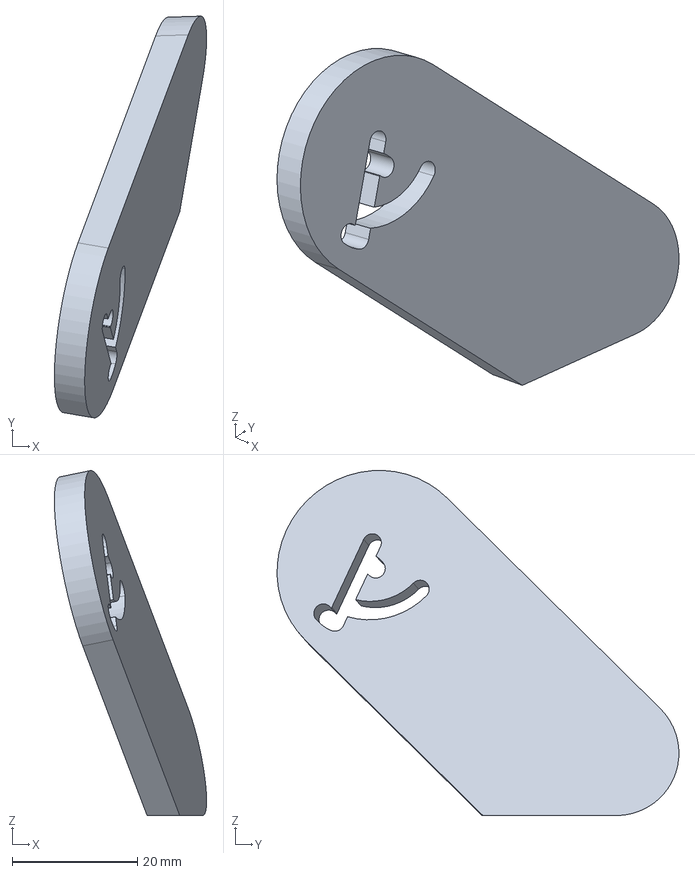
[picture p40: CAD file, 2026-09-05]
mechanical/stand/foot-left.step
24.3 x 64.0 x 55.0 mm

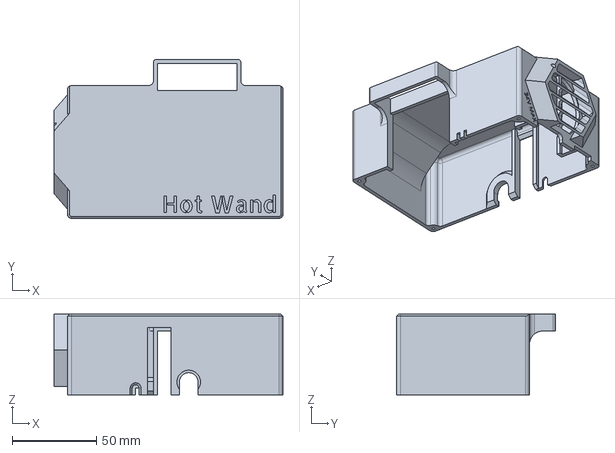
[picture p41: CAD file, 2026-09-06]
mechanical/econo/box-body.step
135.8 x 94.2 x 47.9 mm

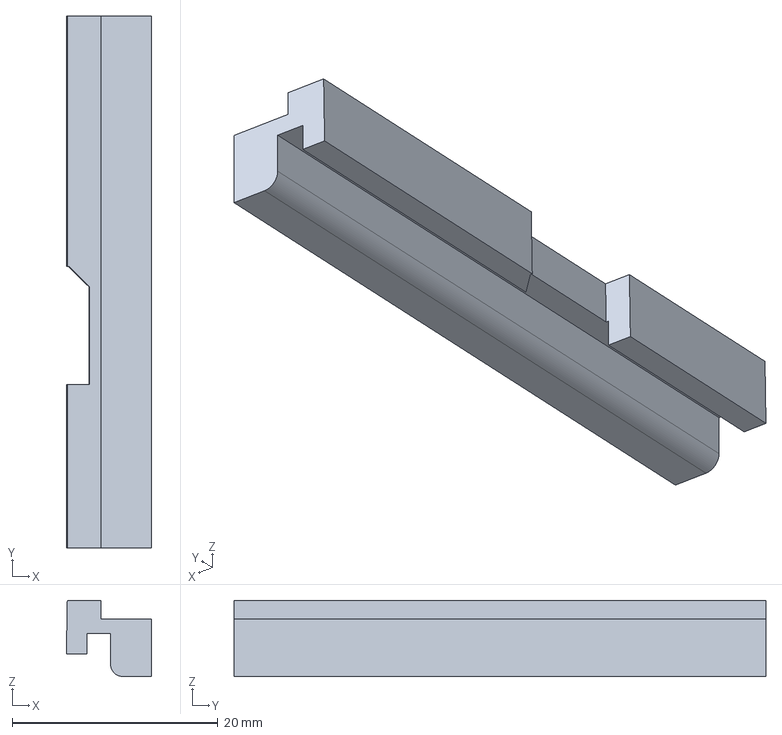
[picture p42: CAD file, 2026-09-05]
mechanical/main/air-gap-blocker.step
8.30 x 51.8 x 7.40 mm

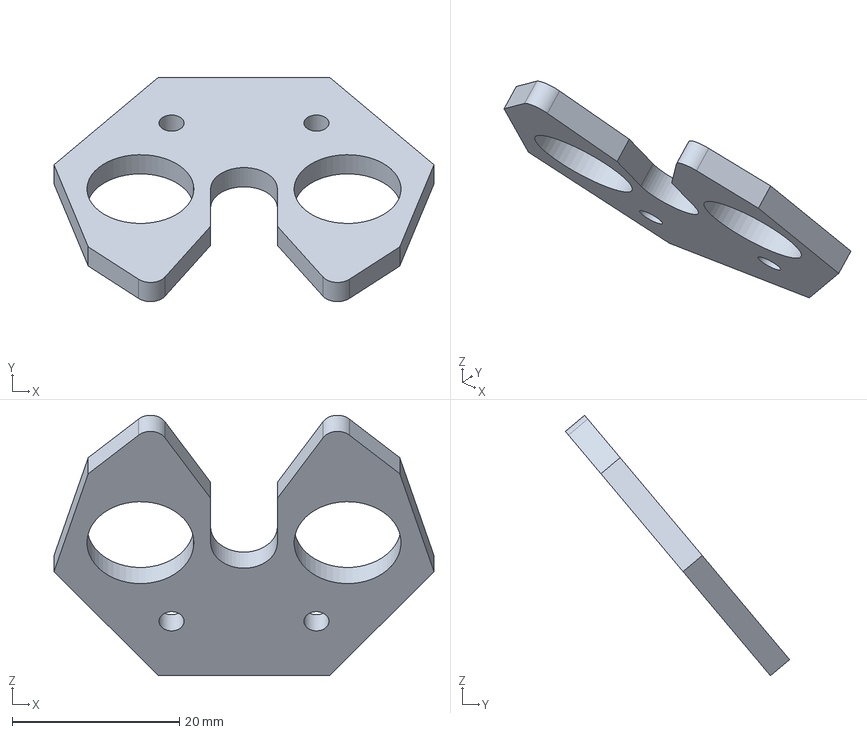
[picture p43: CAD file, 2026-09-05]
mechanical/stand/strike-plate.step
45.5 x 26.8 x 31.2 mm

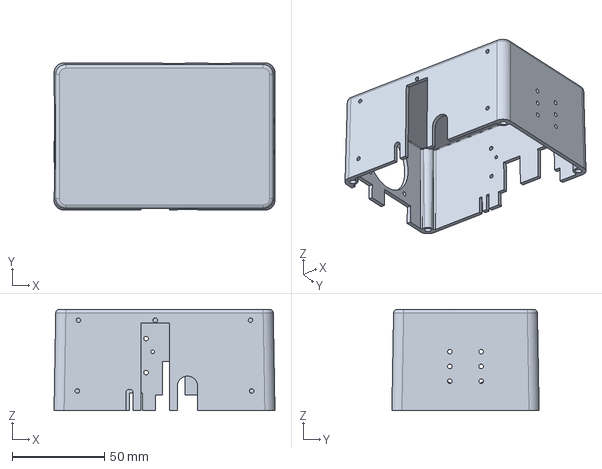
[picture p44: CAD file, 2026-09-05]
mechanical/main/1590t-enclosure-body.step
120.0 x 80.0 x 55.0 mm

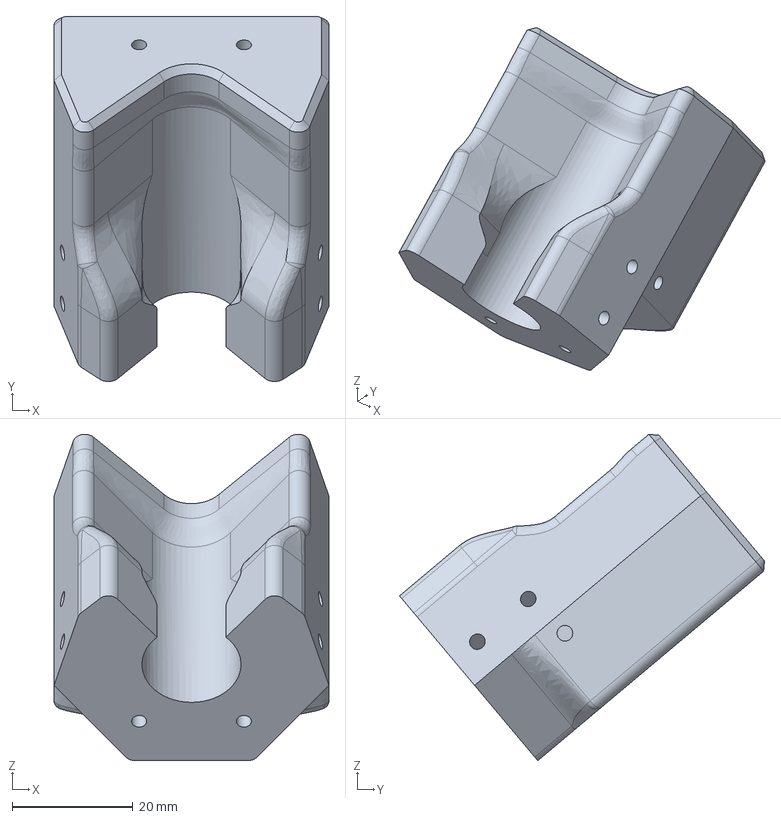
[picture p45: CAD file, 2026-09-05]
mechanical/stand/handle-rest.step
45.5 x 60.4 x 54.0 mm

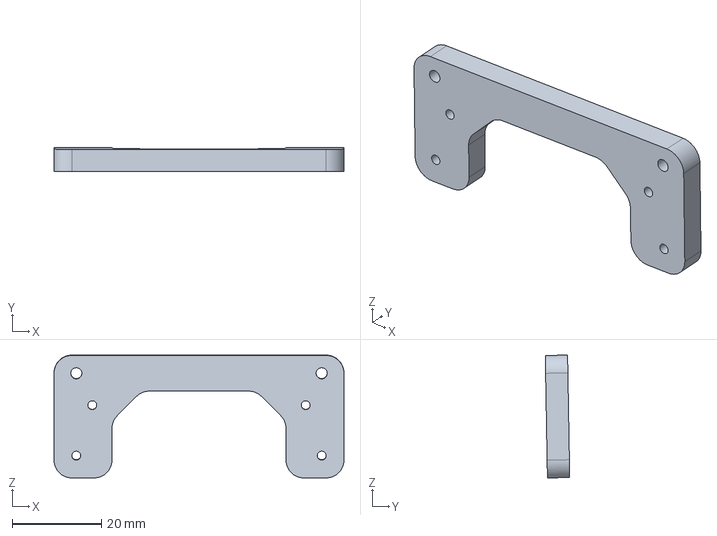
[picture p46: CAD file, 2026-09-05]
mechanical/main/internal-anchor-plate.step
65.0 x 5.48 x 27.5 mm

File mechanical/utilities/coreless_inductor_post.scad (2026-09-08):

/*
 * Coreless inductor L8 winding post
 *
 * Units are millimetres. This is a disposable winding mandrel: wind ten
 * turns of 22 AWG magnet wire in the spiral groove, then cut or snap the
 * 2 mm neck to remove the square footing.
 */

// ---------- Winding adjustment ----------

// IMPORTANT: Change this value to tune the winding spacing (for example,
// 1.05 or 1.1). This is the vertical rise of one complete spiral turn.
winding_pitch = 1.0;

// ---------- Physical dimensions ----------

footing_size = 20;
footing_thickness = 0.8;

neck_diameter = 2.0;
post_diameter = 5.4;
post_height = 12;
cone_side_angle = 45;

// The groove is cut by a complete 0.8 mm-diameter circular tube following
// the requested 5.4 mm-diameter helical path.
wire_diameter = 0.8;
spiral_path_diameter = 5.4;

// Higher values make the helical groove smoother but take longer to render.
segments_per_turn = 32;
wire_facets = 24;
post_facets = 96;

// ---------- Derived dimensions ----------

wire_radius = wire_diameter / 2;
spiral_path_radius = spiral_path_diameter / 2;

// OpenSCAD trigonometric functions use degrees. At 45 degrees, the cone
// height is the same as the change in radius: (5.8 - 2.0) / 2 = 1.9 mm.
cone_height =
    (post_diameter - neck_diameter) / 2 / tan(cone_side_angle);
cone_bottom_z = footing_thickness;
cone_top_z = cone_bottom_z + cone_height;
post_top_z = cone_top_z + post_height;

// Begin below the first possible cone intersection and finish above the top
// edge so the same uninterrupted helix cleanly opens at both ends.
spiral_start_z = cone_bottom_z;
spiral_end_z = post_top_z + wire_radius;
spiral_height = spiral_end_z - spiral_start_z;
spiral_segments = ceil(
    spiral_height / winding_pitch * segments_per_turn
);

function spiral_point(index) =
    let(
        z = spiral_start_z
            + spiral_height * index / spiral_segments,
        angle = 360 * (z - spiral_start_z) / winding_pitch
    )
    [
        spiral_path_radius * cos(angle),
        spiral_path_radius * sin(angle),
        z
    ];

// ---------- Geometry ----------

module footing() {
    translate([-footing_size / 2, -footing_size / 2, 0])
        cube([footing_size, footing_size, footing_thickness]);
}

module winding_post() {
    union() {
        translate([0, 0, cone_bottom_z])
            cylinder(
                h = cone_height,
                d1 = neck_diameter,
                d2 = post_diameter,
                $fn = post_facets
            );

        translate([0, 0, cone_top_z])
            cylinder(
                h = post_height,
                d = post_diameter,
                $fn = post_facets
            );
    }
}

module round_spiral_cutter() {
    for (i = [0 : spiral_segments - 1]) {
        hull() {
            translate(spiral_point(i))
                sphere(r = wire_radius, $fn = wire_facets);
            translate(spiral_point(i + 1))
                sphere(r = wire_radius, $fn = wire_facets);
        }
    }
}

module spiral_groove() {
    round_spiral_cutter();
}

union() {
    footing();

    difference() {
        winding_post();
        spiral_groove();
    }
}

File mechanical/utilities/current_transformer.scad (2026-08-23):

/*
 * Hot-Wand 1:14:14 current transformer
 *
 * Units are millimetres.
 *
 * This is an assembly illustration, not a manufacturing-accurate model of
 * enamel deformation.  The turn count, winding direction, continuous wire
 * identities, and PCB-hole mapping are intentional.  The exact twist pitch
 * and the way the free leads settle are illustrative.
 *
 * Winding convention encoded here:
 *
 *   turquoise wire: S1A -> 14 turns -> S1B
 *   violet wire:    S2A -> 14 turns -> S2B
 *   yellow wire:    P1  -> one pass through the core -> P2
 *
 * Start both secondary wires at the A holes, twist the two insulated wires
 * together, and wind the resulting pair as one cable.  If each continuous
 * colored wire is inserted into its matching A/B holes, the PCB footprint
 * establishes the required electrical polarity.
 *
 * Physical polarity encoded by the PCB footprint:
 *
 *   dotted side:   P1, S1B, S2B
 *   undotted side: P2, S1A, S2A
 *
 * The positive primary-current reference is P1 -> P2.  Following either
 * secondary from A -> B, its passages through the aperture run in the
 * opposite direction.  Consequently, current entering a dotted B terminal
 * runs through the aperture in the same sense as current entering dotted P1.
 */

// ---------- Display controls ----------

show_core = true;
show_secondary_windings = true;
show_primary = true;
show_pcb = true;
show_pad_labels = true;
show_color_legend = true;

// 0 = quicker/faceted, 1 = normal, 2 = smoother/slower.
render_quality = 1;

// ---------- Physical dimensions ----------

core_outer_diameter = 16;
core_inner_diameter = 9.6;
core_thickness = 6.3;
core_edge_radius = 0.45;

wire_diameter = 0.6;
wire_radius = wire_diameter / 2;

// For a toroidal transformer, each conductor passage through the aperture is
// one electrical turn.  The model produces exactly this many passages.
secondary_turns = 14;

// The exact hand-twisted pitch is not electrically prescriptive.  This value
// makes the bifilar construction unambiguous in an instructional rendering.
pair_twists = 34;
pair_center_distance = wire_diameter * 1.04;
pair_center_offset = pair_center_distance / 2;

// Clearance between the modelled wire centreline envelope and the ferrite.
winding_clearance = 0.15;

// Lift the upright core enough for the widest orientation of the twisted pair
// to pass between it and the PCB.  In the physical assembly the wound core
// naturally rests on the pair rather than directly on the board.
core_lift_above_pcb =
    pair_center_distance + wire_diameter + winding_clearance + 0.1;

// ---------- PCB footprint dimensions ----------

pcb_thickness = 1.6;
pcb_fragment_size = [20, 16];

// ---------- Color legend layout (safe to tweak) ----------

// XY position of the first legend line.  The PCB extends from X=-10 to X=10,
// so the default X position puts the entire legend off its right edge.
color_legend_origin = [11.5, 2.0];

// Positive values place subsequent lines downward from the origin.
color_legend_line_spacing = 1.45;
color_legend_text_size = 0.82;
color_legend_text_height = 0.05;
color_legend_z = 0.07;
text_rotation = 180;

secondary_pad_diameter = 1.9304;
primary_pad_diameter = 2.54;
pad_drill = 1.0;

// These coordinates match XFORMER-K16X8X6-1:14:14 in hot-wand.lbr.
S2A = [-7.6,  4.0];
S1A = [-5.0,  4.0];
S2B = [-7.6, -4.0];
S1B = [-5.0, -4.0];
P2  = [ 0.0,  3.8];
P1  = [ 0.0, -3.8];

// ---------- Colors ----------

core_color = [0.12, 0.13, 0.15];
secondary_1_color = [0.00, 0.86, 0.66];  // turquoise
secondary_2_color = [0.56, 0.04, 1.00];  // violet
primary_color = [1.00, 0.78, 0.04];      // yellow
pcb_color = [0.04, 0.30, 0.16, 0.68];
copper_color = [0.88, 0.55, 0.16];
label_color = [0.94, 0.94, 0.94];

// ---------- Derived geometry ----------

core_outer_radius = core_outer_diameter / 2;
core_inner_radius = core_inner_diameter / 2;
core_major_radius = (core_outer_radius + core_inner_radius) / 2;
core_radial_half_width = (core_outer_radius - core_inner_radius) / 2;
core_center_height = core_outer_radius + core_lift_above_pcb;

// The secondary centreline follows a rounded-rectangle envelope around the
// approximately rectangular cross-section of the ferrite toroid.
winding_radial_radius =
    core_radial_half_width
    + pair_center_offset
    + wire_radius
    + winding_clearance;
winding_axial_radius =
    core_thickness / 2
    + pair_center_offset
    + wire_radius
    + winding_clearance;
winding_superellipse_power = 4;

// Use nearly the entire circumference so the 14 paired passages are visibly
// separated.  The remaining lower-left gap is only for the free leads.  It is
// slightly wider than the maximum projected width of the twisted pair.
winding_gap_center_angle = 235;
winding_gap_angle = 12;
winding_start_angle = winding_gap_center_angle + winding_gap_angle / 2;
winding_sweep_angle = 360 - winding_gap_angle;

// Start on the P2/A face and finish on the P1/B face.  A toroidal turn is
// counted by a passage through the aperture, not by requiring both free leads
// to finish at the same cross-section angle.  Starting at -90 degrees and
// sweeping 13.5 cross-section revolutions produces exactly 14 aperture
// passages, then leaves the finish lead naturally on the opposite face.
winding_minor_start_angle = -90;
winding_minor_sweep_angle = -(secondary_turns - 0.5) * 360;
twist_start_angle = 0;

path_segments = render_quality <= 0
    ? max(secondary_turns * 15, pair_twists * 5)
    : render_quality == 1
        ? max(secondary_turns * 24, pair_twists * 9)
        : max(secondary_turns * 34, pair_twists * 12);

wire_facets = render_quality <= 0 ? 7 : render_quality == 1 ? 10 : 14;
core_facets = render_quality <= 0 ? 96 : render_quality == 1 ? 160 : 240;
core_corner_facets = render_quality <= 0 ? 10 : render_quality == 1 ? 16 : 24;

tangent_step = 1 / path_segments;
lead_rise = 2.2;

// ---------- Vector and path functions ----------

function v_add(a, b) = [a[0] + b[0], a[1] + b[1], a[2] + b[2]];
function v_sub(a, b) = [a[0] - b[0], a[1] - b[1], a[2] - b[2]];
function v_scale(v, s) = [v[0] * s, v[1] * s, v[2] * s];
function v_dot(a, b) = a[0] * b[0] + a[1] * b[1] + a[2] * b[2];
function v_cross(a, b) = [
    a[1] * b[2] - a[2] * b[1],
    a[2] * b[0] - a[0] * b[2],
    a[0] * b[1] - a[1] * b[0]
];
function v_length(v) = sqrt(v_dot(v, v));
function v_unit(v) = let(n = v_length(v)) n == 0 ? [0, 0, 0] : v_scale(v, 1 / n);

function clamp01(x) = min(1, max(0, x));
function signed_power(x, p) =
    x == 0 ? 0 : (x < 0 ? -1 : 1) * pow(abs(x), p);

function major_angle(u) = winding_start_angle + winding_sweep_angle * u;
function minor_angle(u) =
    winding_minor_start_angle + winding_minor_sweep_angle * u;

function radial_cross_section_offset(u) =
    winding_radial_radius
    * signed_power(cos(minor_angle(u)), 2 / winding_superellipse_power);

function axial_cross_section_offset(u) =
    winding_axial_radius
    * signed_power(sin(minor_angle(u)), 2 / winding_superellipse_power);

// Local toroid coordinates: the ring lies in XY and its thickness is along Z.
function winding_center_local(u) =
    let(
        phi = major_angle(u),
        radius = core_major_radius + radial_cross_section_offset(u)
    )
    [
        radius * cos(phi),
        radius * sin(phi),
        axial_cross_section_offset(u)
    ];

// Rotate the toroid upright and place it above the PCB.  After this transform,
// the ring lies in XZ and the toroid thickness is along Y.
function local_to_board(p) = [p[0], -p[2], p[1] + core_center_height];
function winding_center(u) = local_to_board(winding_center_local(u));

function winding_surface_normal(u) =
    let(
        phi = major_angle(u),
        radial = radial_cross_section_offset(u),
        axial = axial_cross_section_offset(u)
    )
    v_unit([
        radial * cos(phi),
        -axial,
        radial * sin(phi)
    ]);

function winding_tangent(u) =
    v_unit(v_sub(
        winding_center(clamp01(u + tangent_step)),
        winding_center(clamp01(u - tangent_step))
    ));

// Create a stable local frame normal to the bundle path, then rotate each
// conductor around the bundle centreline.  The 180-degree wire-index offset
// keeps the two insulated conductors on opposite sides of the twisted pair.
function secondary_wire_point(u, wire_index) =
    let(
        centre = winding_center(u),
        tangent = winding_tangent(u),
        raw_normal = winding_surface_normal(u),
        normal = v_unit(v_sub(
            raw_normal,
            v_scale(tangent, v_dot(raw_normal, tangent))
        )),
        binormal = v_unit(v_cross(tangent, normal)),
        twist_angle = twist_start_angle
            + pair_twists * 360 * u
            + wire_index * 180,
        offset_direction = v_add(
            v_scale(normal, cos(twist_angle)),
            v_scale(binormal, sin(twist_angle))
        )
    )
    v_add(centre, v_scale(offset_direction, pair_center_offset));

// ---------- Geometry helpers ----------
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

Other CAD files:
mechanical/stand/foot-right.step
mechanical/main/heatsink-exhaust-duct.step
mechanical/stand/alu-strike-plate.step
mechanical/main/air-intake-grille.step
mechanical/econo/bottom-lid.stl
mechanical/econo/box-body.stl
mechanical/econo/heatsink-drill-template.stl
mechanical/lite/bottom-lid.stl
mechanical/lite/box-body.stl
mechanical/main/1590t-enclosure-lid.step
mechanical/main/air-gap-blocker.stl
mechanical/main/air-intake-grille.stl
mechanical/main/box-template.step
mechanical/main/box-template.stl
mechanical/main/face-plate.step
mechanical/main/face-plate.stl
mechanical/main/heatsink-drill-template.stl
mechanical/main/heatsink-exhaust-duct.stl
mechanical/main/internal-anchor-plate.stl
mechanical/main/lid-template.stl
mechanical/stand/alu-strike-plate.dxf
mechanical/stand/foot-left.stl
mechanical/stand/foot-right.stl
mechanical/stand/handle-rest.stl
mechanical/stand/strike-plate.dxf
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

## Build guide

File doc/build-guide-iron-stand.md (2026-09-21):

# Soldering Iron Handpiece Stand

This soldering iron stand fits any handpiece that has a 16mm flange, which is common for RF soldering iron handpieces. It can contain magnets that put RF soldering iron cartridges into sleep mode. It is primarily designed to be portable with folding legs to stand it up, but it can also be mounted as a part of a heavier duty iron stand.

It consists of mostly 3D printed components and one aluminum plate that is supposed to be cut by SendCutSend (or similar).





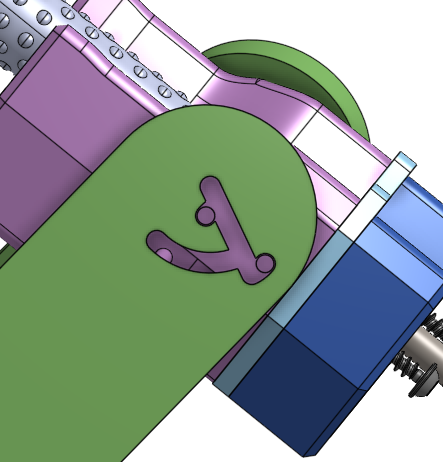
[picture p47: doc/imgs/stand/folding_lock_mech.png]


The pieces are named:

* Handle Rest
* Strike Plate
* Tip Shroud
* Left Foot, Right Foot

The files are all [here in this directory](../mechanical/stand)

There are two versions: 16mm for handpieces with a 16mm diameter flange (Metcal, Radio Thermal). 18mm for handpieces with a 18mm diameter flange (Thermaltronics). Only one piece, the handle-rest, has this variation.

It can house cylindrical magnets that are 1/2" in diameter and 1/4" thick, magnetized axially. (KJ Magnetics D84, D84AH, D84B-N52, etc)

The design has the strike plate intentionally taking possible hits from the hot soldering iron tip, preventing the plastic from getting melted accidentally. However it is still advised to cover exposed plastic surfaces with aluminum foil tape for added protection.

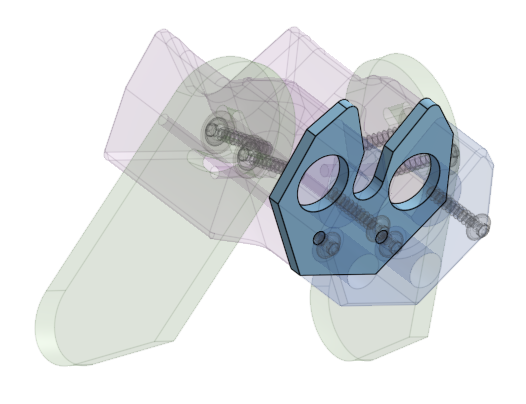
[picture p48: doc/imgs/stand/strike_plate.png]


The strike plate is to be made with a heat resistant material. The strike plate can be made of something like a soda can if you don't want to pay for it to be laser-cut or water-jet. The spacing for the magnet can be adapted.

Assembly assumes to use M3 sized 16mm long plastite screws (McMaster-Carr `96817A107`) and M3 washers. You may substitute this as you wish, all the holes are a bit undersized in the design.

The design is available [at Onshape (click here)](https://cad.onshape.com/documents/cfeb2fa9b83109508c6ff5e8/w/69b4ef0849f116bf37eeaccd/e/969a8f9c953454fe4aa374bb), public export permissions have been enabled. Static exported files have been saved to [this directory in the repo](../mechanical/stand) as well.

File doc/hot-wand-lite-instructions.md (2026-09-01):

# Hot Wand Lite Instructions

Hot-Wand Lite is the simpler cheaper 470 kHz version of Hot-Wand.

# Operating Instructions

## Powering by Battery

If you want to use a battery with the XT30 connector, you can use up to a 6S Li-HV, 6S Li-Po, or 6S LiFePO4 battery pack.

## Powering by Desktop AC

If you want to power from a AC power supply, the best way is to add a XT30 connector on a AC-to-DC converter capable of 20V 5A.

Technically this device will accept up to 28V, and theoretically it is more powerful at higher voltages. It will demand more current, and the electronics will run hotter, and be more stressed. I recommend sticking with 20V. Or, upgrade to the full blown 13.56 MHz version of Hot-Wand.

## Powering by USB-PD

Only USB-C chargers delivering 100W or more will work with Hot-Wand-Lite. If you want a cheaper way of using the maximum power output, consider using the XT30 connector along with a dedicated DC power supply capable of 20V and 5A, or more. A 65W USB-C charger might work if you configure for 15V mode.

The voltage and current requested from a USB-PD host can be configured using jumper shunt blocks. The voltage requested is 15V by default without the jumper, and 20V when the jumper is installed.

The current requested is 3A without the jumper, and 5A when the jumper is installed. However, requesting 5A, you need a special USB-C cable with a "E-marker" chip, and the cable must be rated 140W or more.

Realistically, the only configuration that actually works is:

 * USB-C PD charger capable of 100W or more
 * Voltage configured for 20V
 * Current configured for 5A
 * USB-C cable rated for 140W or more and explicitly states that it has a E-marker chip

## Power Levels

The jumpers near the output of the Hot Wand Lite is where you can select the power level. The levels are:

 * Sport (maximum always)
 * Normal (attempt to stay under 5A limit)
 * Eco (60% power always)

NOTE: These levels are not meant for saving battery power, they only exist so that if your power supply is not sufficient, you have an option to lower the power usage. In fact, theoretically if you are heating up a gigantic solder joint, using a higher power mode will use less total battery energy, because the heat will rise faster and less is being lost during that time. I would keep the configuration in Sport mode unless you have an insufficient power supply.

## LED Indicators

The LED indicator will blink in different patterns according to the input power voltage range (low or high) and the selected output power level (Sport, Normal, or Eco).

    Low V  + Eco:     _/\_______/\______
    Low V  + Normal:  _/\/\_____/\/\____
    Low V  + Sport:   _/\/\/\___/\/\/\__
    High V + Eco:     _/‾‾‾‾‾\/\____/‾‾‾‾‾\/\___
    High V + Normal:  _/‾‾‾‾‾\/\/\___/‾‾‾‾‾\/\/\___
    High V + Sport:   _/‾‾‾‾‾\__/‾‾‾‾‾\_

Input voltage below 22V is considered low. So a 20V capable USB host (such as 65W to 100W) will be considered in the low range. A 24V DC power supply or a 140W USB host will be considered in the high range.

# Assembly Instructions

[Please see this document (click here)](build-guide-lite-470khz/build-guide-lite.md)

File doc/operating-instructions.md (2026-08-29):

## Normal Operation

When powered up, the soldering iron does not really need any interaction. It just works, much like a Metcal soldering station.

The GUI will display the DC input voltage, and a graph representing power draw. The voltage helps users determine battery voltage or USB host delivered voltage. The power graph show how much power is being consumed by the soldering iron cartridge.

Remember, this is a RF soldering iron, there is no need (and no way) to adjust temperature. The temperature is just magically always correct. Since you are using one and knows it's worth like $1000, I assume this is why you are using one.

Pressing the button quickly will cycle between the three power limit modes. The SPORT mode is essentially unlimited. The Normal and Eco modes will show a dotted line on the power graph indicating where the virtual power limit is.

Pressing and holding the button for a few seconds will place the Hot-Wand into sleep mode, it is essentially powered off. Pressing the button again will wake it back up.

## Swapping Tips

Swapping the tip (removing the cartridge) should ideally be done when the iron is off, which is less stressful on the electrical components. Swapping tips while the unit is on causes a large build-up of stored RF energy and causes a voltage spike, which will trigger a fault.

## Operating Faults

If any internal sensors detect a fault, the fault will be displayed. Some faults can be dismissed by pressing the button, some cannot.

Swapping the tip (removing the cartridge) while the iron is powered will cause a fault. Finish swapping the tip, and press the button to reboot the device to use the new tip. It is highly recommended that you shut down the iron yourself before swapping the tip, it is less stressful on the electrical components this way.

A low battery fault can show up if you've configured a battery protection mode. This fault will cause the system to power down, but it can be overridden and continue to power back up if you press and hold the button. Do this at your own risk, I'm not your mom.

If overheating is detected, the power limiter will automatically go into Eco mode and you cannot change the power limit while the temperature is still too hot.

## Power Input

### Battery

If you want to use a battery with the XT30 connector, you can use up to a 8S Li-HV, 8S Li-Po, or 8S LiFePO4 battery pack. Although I strongly recommend not using 8S and stick with 6S.

### Desktop

If you want to power from a AC power supply, the best way is to add a XT30 connector on a AC-to-DC converter capable of 24V 5A, 28V 5A will also work and maybe better. Pushing above 28V is unneccessary.

### USB-PD

Only USB-C PD chargers delivering 65W or more will work with Hot-Wand. Only USB-C chargers delivering 140W or more will deliver the maximum amount of power that Hot-Wand is capable of delivering. If you want a cheaper way of using the maximum power output, consider using the XT30 connector along with a dedicated DC power supply.

The voltage and current requested from a USB-PD host can be configured using jumper shunt blocks.

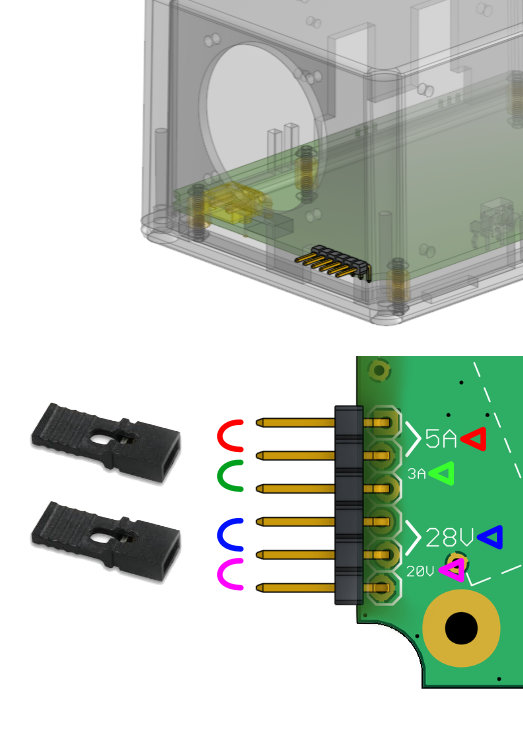
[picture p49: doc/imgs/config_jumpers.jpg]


The voltage requested is 20V by default without the jumper, and 28V when the jumper is installed. Some USB hosts can still provide 20V even if 28V is requested.

The current requested is "automatic" without the jumper, and 5A when the jumper is installed. However, requesting 5A, you need a special USB-C cable with a "E-marker" chip, and it must be rated 140W or more.

When using the "automatic" option for requesting current from the USB host without the special cable, it is likely the limit is 3A, if using a 65W, 80W, or 100W charger.

If you find that the Hot-Wand simply does not power up through USB, first, choose "automatic" for current. If that doesn't help, then choose 20V instead of 28V. If the 20V and automatic current option does not work, something is seriously wrong and that particular USB host cannot work with Hot-Wand.

If you find that the Hot-Wand will function, but suddenly, power is cut by the USB host, then you should try lowering the power limit by using one of the lower power limit modes.

If the USB host is delivering 15V instead of 20V (some chargers will split power when multiple devices are plugged in), the Hot-Wand will not work very well. Below 14V the Hot-Wand will not function at all.

## Setup Menu

When powered off (unplug power cable), press and hold the button, while holding the button, insert the power cable. Keep holding the button. The screen will state that holding the button will enter the setup menu. Eventually, the setup menu will be activated.

Inside the setup menu, pressing the button quickly will scroll to the next topic. Pressing and holding the button will cause the option to be edited within the current topic.

When you are happy with the setup, press the button until the screen reads "SAVE AND EXIT", then press-and-hold the button until the unit reboots.

If you want to discard your changes, then press the button until the screen reads "EXIT DON'T SAVE", then press-and-hold the button until the unit reboots.

## Battery Modes

In the setup menu, you can choose a battery mode. This let's you pick between three supported battery chemistries: Li-Po (regular lithium polymer), Li-HV (higher voltage lithium polymer), and Li-Fe (LiFePO4). For each option, there is also a "safer" mode.

The system will automatically determine how many cells your battery has based on your selected battery chemistry, and then determine the appropriate safe low battery cutoff voltage. If you've chosen the "safer" mode of that chemistry, then the cutoff voltage is just slightly higher.

This feature only works correctly if the input voltage calibration is correct. If you cannot calibrate the input voltage reading, then I would suggest you do not use the battery mode feature at all.

This feature does not account for cell imbalance! If you have an unhealthy out-of-balanace battery pack, it is possible that one cell is over-discharged but not trigger a warrning.

## Input Voltage Calibration

There is a setup menu topic for input voltage calibration ("INPUT VOLT CALIB"). You can pick options such as `-5` `-4` `-3` `-2` `-1` `0` `+1` `+2` `+3` `+4` `+5`. The voltage after calibration will be displayed on the screen while you make a selection. If you know what voltage you are actually inputting, then change the selection until the displayed voltage is the closest match.

Please use a multimeter for this. Don't trust that a 20V power supply is actually outputting 20.00V

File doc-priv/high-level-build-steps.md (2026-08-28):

## 0. Circuit Board Reception

Get the circuit board from JLCPCB

Populate all out-of-stock components that JLCPCB did not populate

## 1. Input Power

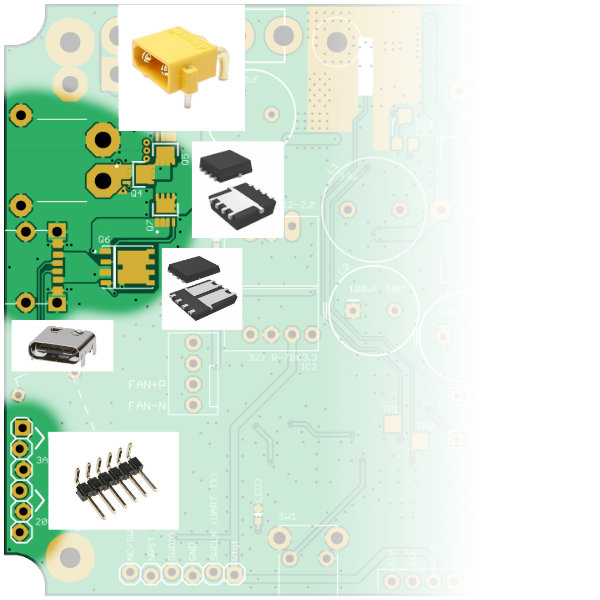
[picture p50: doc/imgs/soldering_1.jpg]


Populate power input MOSFETs, these PowerPAK MOSFETs are hand soldered with a soldering iron (not hot air). For each of the three MOSFETs, follow these steps:

1. brush the bottom of the MOSFET with flux, brush the PCB footprint with flux
2. apply a **very thin** layer of solder to the center pad of the MOSFET footprint on the PCB (not the MOSFET itself)
3. brush some more flux onto the PCB footprint
4. solder pin 1 of the MOSFET to the PCB, ensuring it is on straight
5. solder pins 2, 3, 4 of the MOSFET onto the PCB
6. solder pins 5 thru 8 of the MOSFET all in one go, apply extra solder as the wicking action will pull solder underneath the MOSFET (this is why we prepped the center pad first)

Populate the USB-C connector, followed by the XT30 connector

Populate JP5, which is the header for the shunt jumpers that configures USB-PD negotiation

Test input power. First test XT30 connector and check if the ideal-diode works. I recommend using a smoke-stopper device for this test if using a battery, otherwise, use a non-battery DC input with a XT30 connector.

Then test USB-C negotiation with a variety of configurations (20V vs 28V, 5A limit vs automatic current limit)

During the USB-C tests, the shunt jumpers should have been installed to JP5

(OPTIONAL) Populate LEDs. If you choose to do this, it might be nice to use different colours for each one.

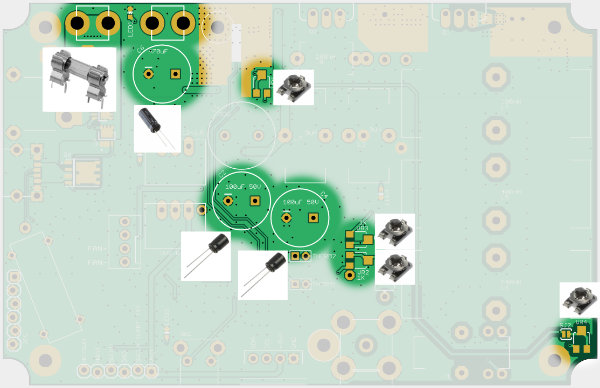
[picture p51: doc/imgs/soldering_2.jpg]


Populate the potentiometers. (DEVELOPMENT ONLY) Make note of their orientation and correlate spin direction with resistances.

Populate the fuse holder, and install a 7A fuse (20x5mm glass fast-blow fuse). Do a quick check to make sure it doesn't blow a fuse immediately.

Populate all through hole capacitors

## Testing Note: Voltage Measurement Points

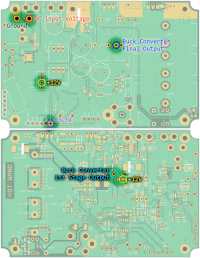
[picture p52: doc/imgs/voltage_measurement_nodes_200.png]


## 2. Power Supplies

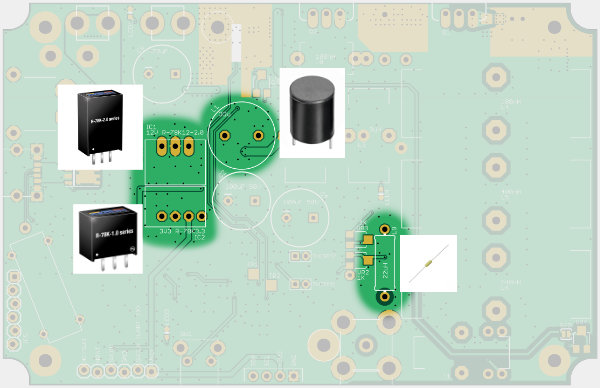
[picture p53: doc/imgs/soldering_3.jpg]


Populate the 12V buck converter. Populate the 3.3V buck converter (or voltage regulator).

Test the output of these buck converters (and/or voltage regulator). Power up the circuit using a current limited power supply of some kind (test condition: 20V input, 1A limit), and measure the 12V and 3.3V nodes using a multimeter, making sure they are measuring very close (within +/- 5%) to 12V and 3.3V.

Populate the L1 inductor. This is the main buck converter's first stage inductor.

Now, when powered up, the main buck converter will start outputting some voltage. Adjust the potentiometer to vary the voltage, test up to the limit, then set it to the lowest possible setting.

Populate the L9 inductor. This is the filter inductor for the tip detector.

## 3. PCB Cooling and Mounting Hardware

Add the custom cut copper fins to the buck converter heat dissipation area. Using 0.5mm thick copper sheets, cut strips that are about 5mm tall, and then cut them into small fins. Solder these fins to the top side of the PCB where the copper is exposed, near where buck converter is under, which is also near where one of the standoff screws is supposed to go. Arrange them such that the fins are perpendicular to the edge of the board as we want the air to flow outwards towards vents that are on the side of the box.



Do not make the fins block the area where the brass standoff and screw is supposed to go! We are soldering on the fins first before the standoffs are attached because it is easier to solder this way, without the huge thermal mass of the standoff.

Attach all brass standoffs (M2.5 thread, 6mm long, 4.5mm hex) to the bottom of the circuit board, using M2.5 x 4mm screws. Use low or medium strength thread-locker if available. Using tooth-lock washers is also optional.

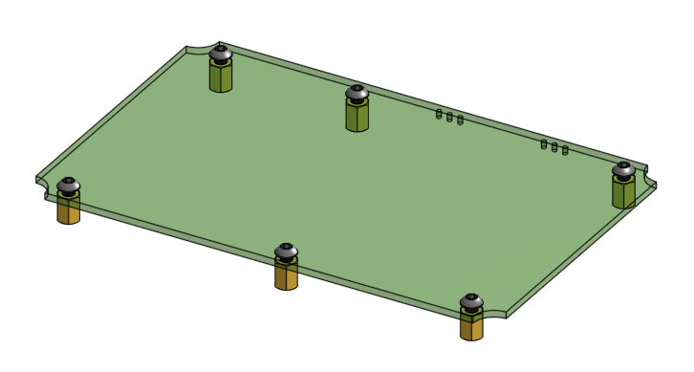
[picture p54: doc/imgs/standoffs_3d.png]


## 4. Controls and Firmware Bring-Up

Populate tactile button, OLED screen, coax connector

Populate the fan connector

Populate the debug header. It is a 6 pin female header with 0.1 inch pin pitch on the bottom of the circuit board.

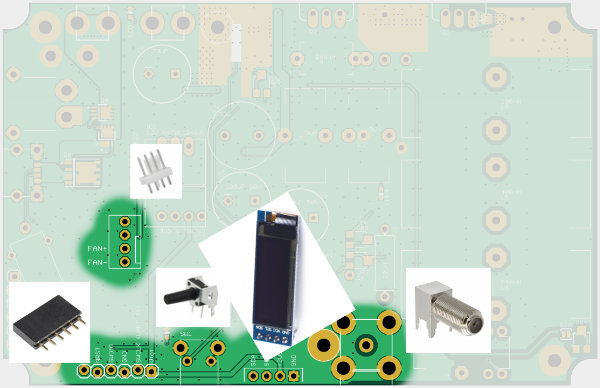
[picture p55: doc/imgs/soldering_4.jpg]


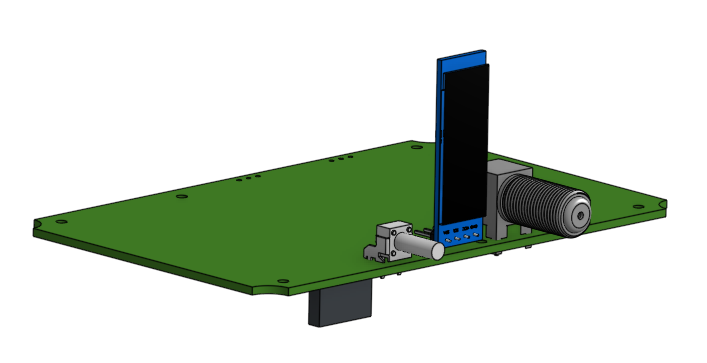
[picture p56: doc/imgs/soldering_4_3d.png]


Configure the fan solder jumpers (SJ3, SJ4, SJ5), these are on the bottom of the PCB.

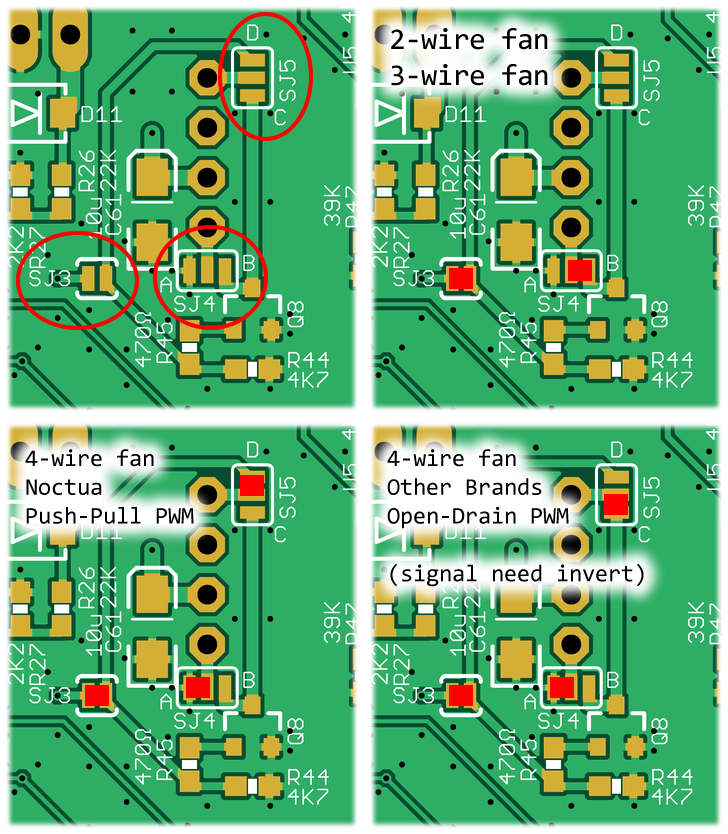
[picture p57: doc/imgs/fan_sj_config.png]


Ensure **SJ1** is bridged (ie. shorted) by solder.

At this point in the build process, you need to flash the firmware to the microcontroller

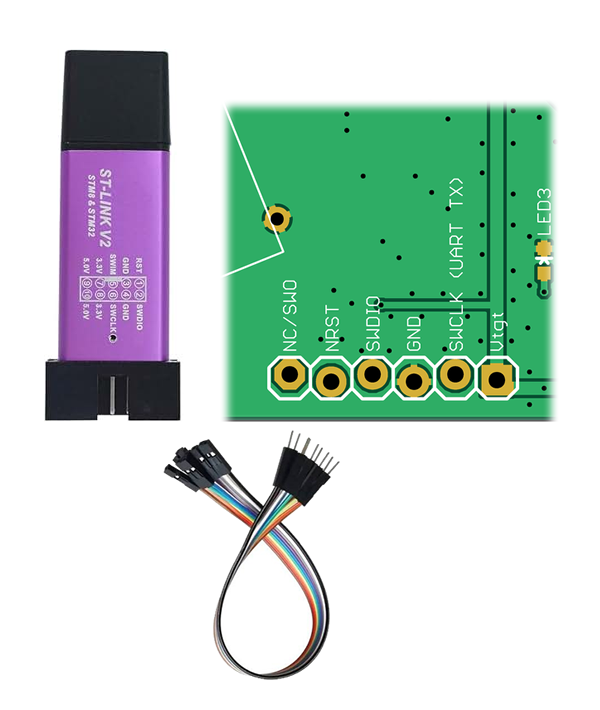
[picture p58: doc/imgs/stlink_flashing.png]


TODO: link to another page on firmware flashing

(DEVELOPMENT ONLY) Test firmware as much as possible, see all bring-up tests

## 5. Custom Inductors

Wind custom inductors (way more detailed instructions)

(DEVELOPMENT ONLY) measure custom wound inductor for inductance

Populate all custom wound inductors and transformer.

(DEVELOPMENT ONLY) Sanity check buck converter voltage isn't affected by power factor detector circuit

## 6. Solder/Measurement Jumpers

Either short out with solder, or populate **SJ6** with a 0.01 ohm measurement resistor, which is used to measure drain current of Q1.

If SJ6 is not used for measurements, then also short out **SJ7** with solder.

**SJ8** is used to measure the current consumption of the 12V rail, to determine the gate driver's efficiency. The tuning happens after the MOSFETs are ready. Short it out with solder if you are not performing this measurement.

## 6. Printed Parts and Templates

3D print all drilling and cutting templates

3D print: face plate, air intake grille, air exhaust duct, internal air blockers

3D printing material is PETG, or really anything that is more temperature resistant than PLA. Do not use PLA.

Everything can be 3D printed using a 0.4mm or 0.6mm nozzle.

## 7. Enclosure Preparation

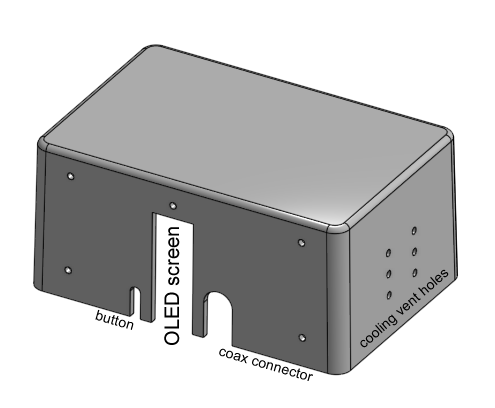
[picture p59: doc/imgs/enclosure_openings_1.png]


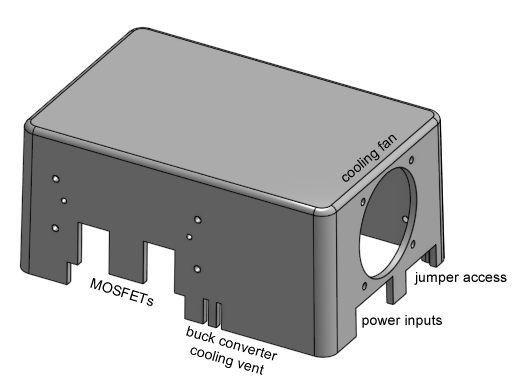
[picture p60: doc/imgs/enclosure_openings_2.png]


Drill and cut enclosure box and lid. Use the cutting and drilling templates to help. Thread tap enclosure box where needed. Please refer to diagram.

(note: all holes start off with a 2.5mm drill bit, and if needed, a larger drill bit is used after)

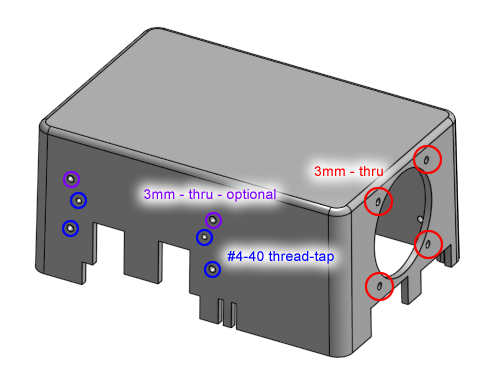
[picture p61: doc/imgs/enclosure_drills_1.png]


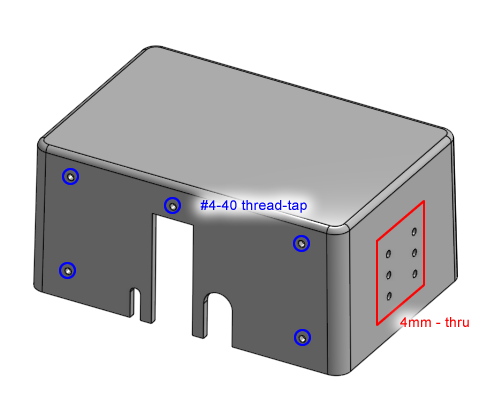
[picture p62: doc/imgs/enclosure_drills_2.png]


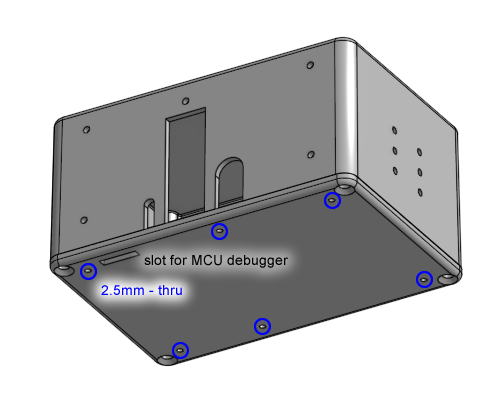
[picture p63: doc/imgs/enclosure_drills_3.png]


The holes for the face plate are not a part of the drilling template. Instead, the face plate itself is used as the drilling template. These holes are thread-tapped for #4-40 screws. The face plate will be fastened as the very last step of the whole build.

Perform an inspection of 3D printed parts and make sure they fit on the enclosure, such that the cutouts are the right size and in the right positions. Additional cutting, grinding, and/or filing, maybe required to make adjustments. Ensure the face plate lines up, and the tactile button, OLED screen, and coaxial connector all line up when the box is dropped over the circuit board when the circuit board is attached to the bottom box lid.

Clean all metal shavings, debur all drilled and cut edges, dull all sharp edges.

## 8. Power MOSFET and Heatsink Assembly

Drill and thread tap the heatsink. A 3D printed drilling template is provided. The thread tap is for a #4-40 thread.

Cut some of the fins off the heatsink where screws will sit over.

Debur the cuts and clean any metal shavings from heatsink.

Clean the surface of the heatsink and the back of both MOSFETs with rubbing alcohol.

Place a silicone thermal pad between each MOSFET and the heatsink.

Insert a nylon shoulder washer (for #4 screws with 3.7mm OD and 2mm depth) into the TO-220 tab's hole.

Fasten the MOSFET to the heatsink using a #4-40 x 3/8 inch long screw through the nylon shoulder washer.

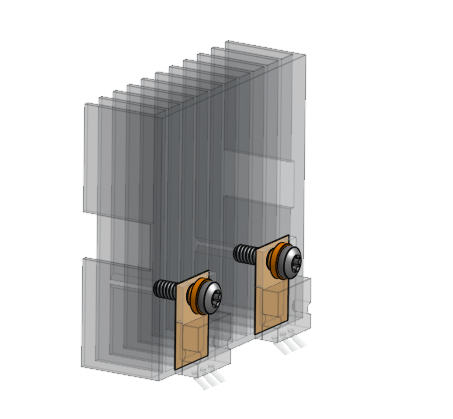
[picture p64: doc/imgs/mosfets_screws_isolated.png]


Before tightening completely, make sure the MOSFET legs are aligned with their perspective footprints on the circuit board. Tighten the screw completely after alignment is ensured.

Cut off the excess silicone thermal pad with an Xacto knife.

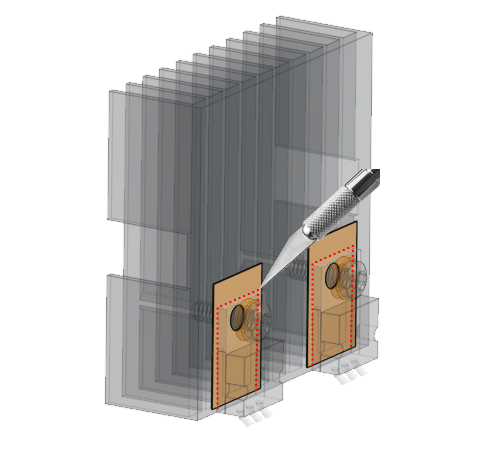
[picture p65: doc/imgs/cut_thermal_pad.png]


Check to make sure heatsink is not causing continuity problems. The drain tab of each MOSFET must not be conductive with the heatsink, nor with each other.

Bend the MOSFET legs, refer to the diagram. The goal is so that the heatsink can mate with the box's face once the box is dropped down on the circuit board.

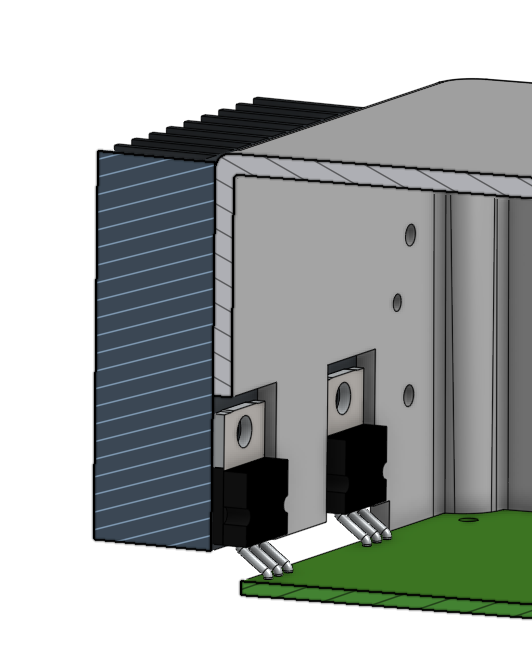
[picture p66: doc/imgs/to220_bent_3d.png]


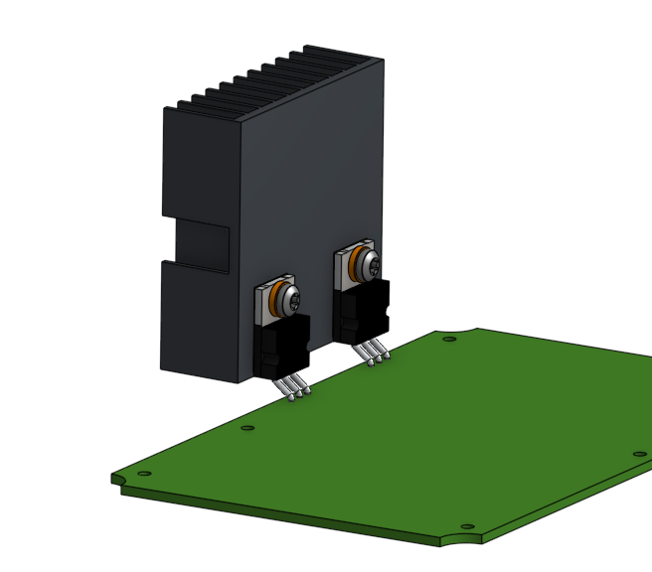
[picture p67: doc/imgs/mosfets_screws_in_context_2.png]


Solder MOSFETs to PCB, continue to adjust the angle of the MOSFET's legs as needed.

Wire up the NTC thermistors and attach them to the MOSFET's plastic face. First, ziptie the wires of the NTC thermistors to the drain leg of the MOSFET. Then, use high temperature epoxy to adhere the bead of the NTC thermistor to the surface of the MOSFET. Please refer to photograph.

Perform mandatory safety related firmware tests (tip detection, NTC thermistors, warning near 8S input voltages). These tests are to be done under unlimited current input power (the glass fuse is the protection now), but the buck converter should be set to a low setting.

(DEVELOPMENT ONLY) full functionality testing while not enclosed, tune the air-core inductor in the gate driver circuit, perform burn-in tests, see detailed test plan

## 9. Final Assembly

**Perform a final review of all soldering, including test points, test resistors, solder jumpers.**

Fasten PCB to bottom lid, using the brass standoffs installed previously and M2.5 x 4mm screws.

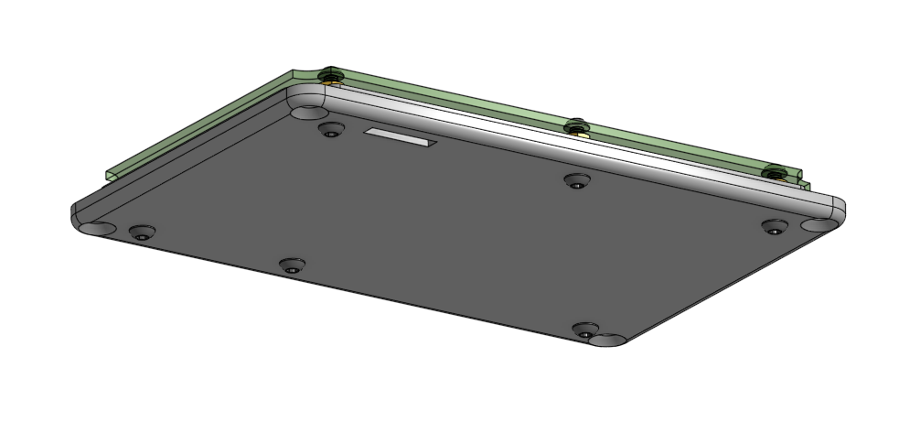
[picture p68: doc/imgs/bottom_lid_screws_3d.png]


Assemble cooling fan and the air intake grille to the box. See diagram for details.

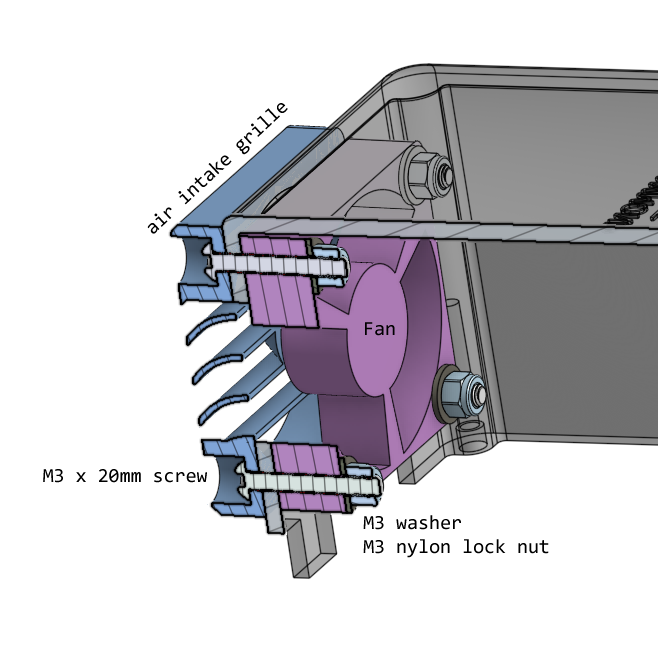
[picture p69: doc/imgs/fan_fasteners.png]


Clean the heatsink surface and the surface of the box where it will sit, use rubbing alcohol.

Apply thermal paste to the box where the heatsink will sit

Plug in the fan to the circuit board

Drop the box over the whole assembly

Secure the heatsink with #4-40 screws and M3 washers

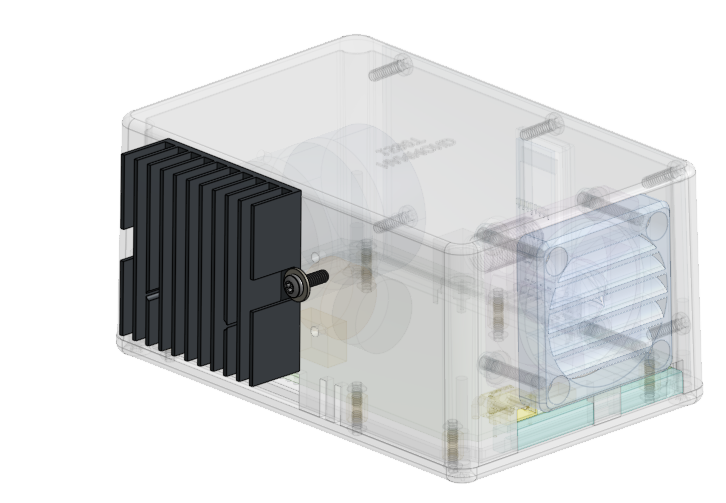
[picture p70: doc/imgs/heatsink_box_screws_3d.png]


Clean up thermal paste that got squished out

Fasten on the air exhaust duct, using #4-40 screws

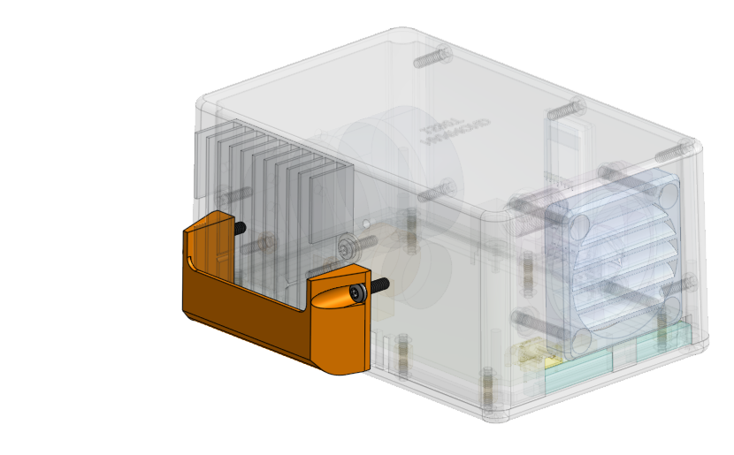
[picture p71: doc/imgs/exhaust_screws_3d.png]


Fasten on the face plate, using #4-40 screws

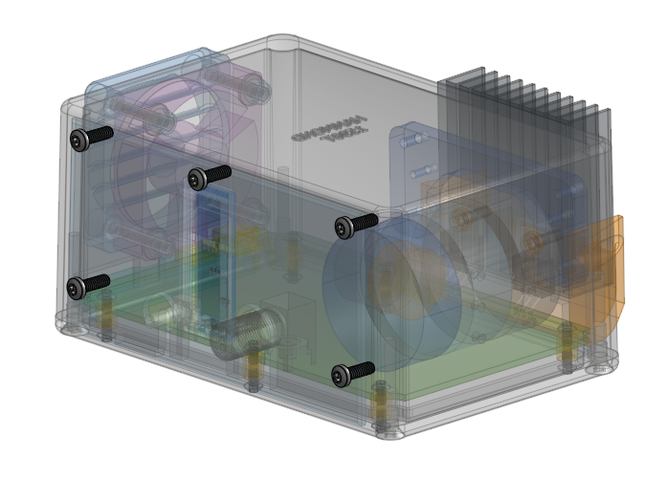
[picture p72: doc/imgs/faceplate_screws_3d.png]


Stick on some rubber feet to the bottom of the enclosure.

## 10. Enclosed Development

(DEVELOPMENT ONLY) further firmware development

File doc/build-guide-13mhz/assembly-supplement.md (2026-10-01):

# Assembly Supplement

## Power Input MOSFETs

Populate power input MOSFETs, these PowerPAK MOSFETs are hand soldered with a soldering iron (not hot air). For each of the three MOSFETs, follow these steps:

1. brush the bottom of the MOSFET with flux, brush the PCB footprint with flux
2. brush some more flux onto the PCB footprint
3. solder pin 1 of the MOSFET to the PCB, ensuring it is on straight and flat against the PCB
4. solder pins 2, 3, 4 of the MOSFET onto the PCB
5. solder pins 5 thru 8 of the MOSFET all in one go, apply extra solder as the wicking action will pull solder underneath the MOSFET

## Testing Note: Voltage Measurement Points

During assembly, it is recommended that you test the power supplies as they are added. Using a multimeter, these are the points that are convenient to test each important voltage node.

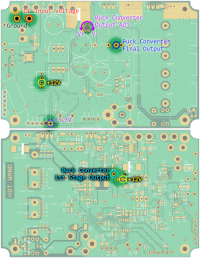
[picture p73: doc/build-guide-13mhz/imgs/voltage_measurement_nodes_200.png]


### Repeated XT30 Power Tests

For repeated power-up tests, leave the XT30 connector mated and switch the bench supply output on and off. Avoid rapidly unplugging and reconnecting XT30 while the bulk capacitor or U6 gate-drive capacitors may still be charged. A quick reconnect can behave differently from a fully discharged start and may spark at the connector.

If Q5 appears shorted in an unpowered resistance check, first disconnect every power source and verify that DC-IN and Q5 gate-to-source voltage have discharged. Recheck Q5 before assuming the MOSFET has failed. A connector spark by itself does not establish whether the inrush limiter is working.

## PCB Cooling Fins near Buck Converter

Using 0.5mm thick copper sheets, cut strips that are about 5mm tall, and then cut them into small fins. Solder these fins to the top side of the PCB where the copper is exposed, near where buck converter is under, which is also near where one of the standoff screws is supposed to go. Arrange them such that the fins are perpendicular to the edge of the board as we want the air to flow outwards towards vents that are on the side of the box.

<!-- TODO: Add a photo of the PCB cooling fins. -->

## Fan Solder Jumper Selection



For fans with only two wires, simply connect it such that the positive wire is connected to where it says `FAN+`, and the positive wire is connected to where it says `FAN-`. Then, use solder to bridge SJ4-B.

For fans with a PWM input (4 wires), plug the connector in the correct orientation (as indicated by the artwork). Then, for fans that prefer a push-pull PWM signal, use solder to bridge SJ4-A and SJ5-D. For fans that prefer an open-drain PWM signal, use solder to bridge SJ4-A and SJ5-C.

Noctua's documentation says their fans prefer a push-pull signal. Other brands of PC fans traditionally prefers an open-drain signal.

Using an open-drain signal requires the firmware option "FAN SIGNL POLAR" to be set to `INVRT`.

## Solder Jumpers and Tuning Parts

VR1 and R37: Responsible for main buck converter output voltage. If the best value for VR1 is known, VR1 can be omitted and R37 used in its place as a permanent setting.

R12 and R13 dissipates gate charge to Q1. R13 is to be identical as R12 but only placed if required. Otherwise leave DNP.

SJ6 is a 0R01 measurement resistor for current through Q1. Short it out with solder for normal builds.

SJ7 is an additional short-to-ground for when SJ6 is not being used for current measurement. Short it out with solder for normal builds.

R11 and VR4 are used to set the sensitivity of the current transformer power factor detector. If you need VR4 for tuning, then hort out SJ2, and maybe remove R11 depending on if you want it in parallel or not.

SJ8 is a measurement resistor for the 12V bus. It is used when tuning L8 (the custom coreless inductor). During normal builds, short out SJ8 with solder.

VR2 and VR3 are used to tune the sensitivity of the tip-detector. VR2 with R19 (and sometimes R20) sets the constant DC bias into Q3's base. VR3 and R22 sets the sensitivity to AC for Q3's base. The resistors can be exchanged for other values when the final resistance is determined, and the potentiometers can be bypassed with a solder jump.

SJ1 is connected between the microcontroller's BOOT0 pin and ground. It should be shorted out with solder in all normal situations. It can be used to put the microcontroller in a bootloader mode if a wire is used to bridge BOOT0 to VCC.

SJ3 connects the microcontroller to the overall fan controlling circuitry. Only connect this after flashing the microcontroller with firmware.

SJ4 is used to select the fan's ground, it can be permanently connected to ground, or have the ground connected to the MOSFET.

SJ5 selects the connection to the PWM pin of the fan. Most fans do not actually use a PWM signal. You can select the PWM signal coming directly from the MCU (recommended for Noctua brand fans and some others), or select the PWM to come from the MOSFET (open drain mode, requires signal inversion in configurable firmware settings).

R46 should be a 0 ohm resistor (or short it out with solder). You can choose to replace it with a particular value if you need to negotiate a certain current limit with the USB-PD host.

## Component Skipping and Substitutions

### Fuse

You can obviously just bridge the fuse holder footprint and not use a fuse. Do this at your own risk.

### Power Input Ideal Diode

Everything around U6, Q4, and Q5, these are an ideal-diode implementation with inrush limiting. They prevent a battery from exploding if a battery and USB are simultaneously plugged in. They also prevent inrush current from causing a fuse to blow. You can decide to skip these two protections, and maybe also add a NTC inrush limiter.

Q7 is used to protect the AP53781 from battery voltage that is potentially too high. Skip and short this out if you wish. Or substitute with an appropriate schottky diode.

### 3.3V Regulator

If you don't want to pay for a `R-78K3.3` buck converter for the 3.3V power bus, you can install a linear voltage regulator instead. The PCB layout supports the `LM1117T-3.3` or `LD1117V33` footprint by providing an extra pad beside the original `R-78K3.3` footprint. (this only saves about $2, and will result in more internal heat)

If you perform this substitution, when the input voltage reaches below about 14V, instead of providing a warning, the whole device will simply shut down abruptly.

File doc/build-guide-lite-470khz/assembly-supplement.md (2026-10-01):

# Assembly Supplement

## Power Input MOSFETs

Populate power input MOSFETs, these PowerPAK MOSFETs are hand soldered with a soldering iron (not hot air). For each of the three MOSFETs, follow these steps:

1. brush the bottom of the MOSFET with flux, brush the PCB footprint with flux
2. brush some more flux onto the PCB footprint
3. solder pin 1 of the MOSFET to the PCB, ensuring it is on straight and flat against the PCB
4. solder pins 2, 3, 4 of the MOSFET onto the PCB
5. solder pins 5 thru 8 of the MOSFET all in one go, apply extra solder as the wicking action will pull solder underneath the MOSFET

## Skipping Components and Substitutions

None of the following are recommended.

You can obviously just bridge the fuse holder footprint and not use a fuse. Do this at your own risk.

If you only ever want to use the power mode "Sport" mode, then you only need C12 and not C13.

You don't need the SMA coaxial connector if you just solder the cable directly to the PCB.

D3 and D4 are optional. They do not exist in the Radio Thermal design. They are meant to protect Q1 from high V_DS conditions, which could occur if the iron tip is disconnected while the unit is operating. These diodes do exist in the SergeyMax design. Omiting these diodes would save I think maybe $10 total if you order a batch of 5 PCBA jobs.

TVS4, TVS5, TVS6, are all meant for anti-static protection. They are optional.

TVS1 and TVS2 are meant for power line transient protection and a bit of anti-static protection. They are optional.

Q5 is used to protect the AP53781 from battery voltage that is potentially too high. Skip and short this out if you wish. Or substitute with an appropriate schottky diode.

Everything around U3, Q2, and Q3, these are an ideal-diode implementation with inrush limiting. They prevent a battery from exploding if a battery and USB are simultaneously plugged in. They also prevent inrush current from causing a fuse to blow. You can decide to skip these two protections, and maybe also add a NTC inrush limiter.

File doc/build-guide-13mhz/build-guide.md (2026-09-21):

# Hot-Wand 13.56 MHz Build Guide

## 0. Circuit Board Reception

Get the circuit board from JLCPCB with mostly bottom components already populated. [See this guide on ordering from JLCPCB](jlcpcb-ordering.md)

Populate all out-of-stock components that JLCPCB did not populate on the bottom side first. (this depends on what was available when the circuit board was ordered)

For all the other required parts, [see the shopping document (click here)](shopping.md)

## 1. Input Power



Populate power input MOSFETs, these PowerPAK MOSFETs are hand soldered with a soldering iron (not hot air). For each of the three MOSFETs, [follow these steps (click here for document)](./assembly-supplement.md#power-input-mosfets)

Populate the USB-C connector, followed by the XT30 connector

Populate JP5, which is the header for the shunt jumpers that configures USB-PD negotiation

Test input power. First test XT30 connector and check if the ideal-diode works. I recommend using a smoke-stopper device for this test if using a battery, otherwise, use a non-battery DC input with a XT30 connector.

Then test USB-C negotiation with a variety of configurations (20V vs 28V, 5A limit vs automatic current limit)

During the USB-C tests, the shunt jumpers should have been installed to JP5

([click here to see testing notes](assembly-supplement.md#testing-note-voltage-measurement-points))

(OPTIONAL) Populate LEDs. If you choose to do this, it might be nice to use different colours for each one.



Make sure the components with polarity are installed correctly. The capacitors have a negative lead that is marked with a `-` symbol and a strip on the side.

Populate the potentiometers. (DEVELOPMENT ONLY) Make note of their orientation and correlate spin direction with resistances.

Populate the fuse holder, and install a 7A fuse (20x5mm glass fast-blow fuse). Do a quick check to make sure it doesn't blow a fuse immediately. ([click here to see testing notes](assembly-supplement.md#testing-note-voltage-measurement-points))

Populate all through hole capacitors

## 2. Power Supplies



Populate the 12V buck converter. Populate the 3.3V buck converter (or voltage regulator).

Test the output of these buck converters (and/or voltage regulator). Power up the circuit using a current limited power supply of some kind (test condition: 20V input, 1A limit), and measure the 12V and 3.3V nodes using a multimeter, making sure they are measuring very close (within +/- 5%) to 12V and 3.3V.

Populate the L1 inductor. This is the main buck converter's first stage inductor.

Now, when powered up, the main buck converter will start outputting some voltage. Adjust the potentiometer to vary the voltage, test up to the limit, then set it to the lowest possible setting.

([click here to see testing notes](assembly-supplement.md#testing-note-voltage-measurement-points))

Populate the L9 inductor. This is the filter inductor for the tip detector. It should be raised about 5mm above the PCB when installed.

## 3. PCB Cooling and Mounting Hardware

Add the custom cut copper fins to the buck converter heat dissipation area.  [Click here to see detailed procedures](assembly-supplement.md#pcb-cooling-fins-near-buck-converter)

<!-- TODO: Add a photo of the PCB cooling fins. -->

Do not make the fins block the area where the brass standoff and screw is supposed to go! We are soldering on the fins first before the standoffs are attached because it is easier to solder this way, without the huge thermal mass of the standoff.

Attach all brass standoffs (M2.5 thread, 6mm long, 4.5mm hex) to the bottom of the circuit board, using M2.5 x 4mm screws. Use low or medium strength thread-locker if available. Using tooth-lock washers is also optional and can help.



## 4. Controls and Firmware Bring-Up

Populate the tactile button, OLED screen, and the coax connector. The OLED screen needs a right angled header (4 pins), and when soldering, raise the header a bit.

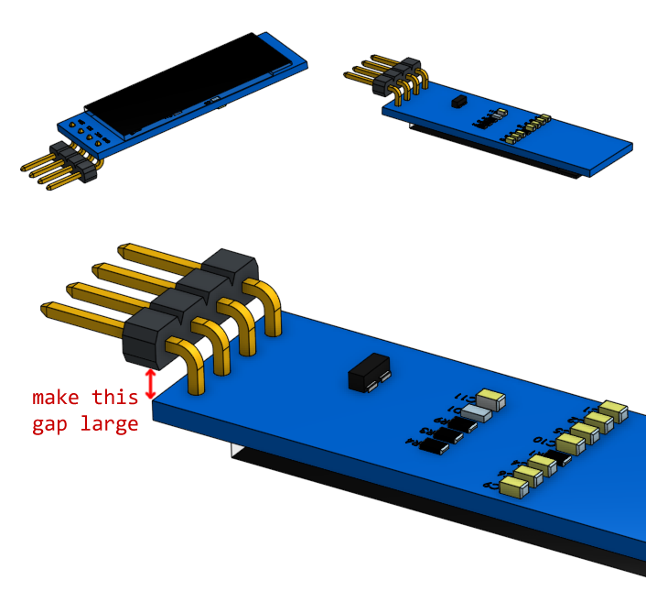
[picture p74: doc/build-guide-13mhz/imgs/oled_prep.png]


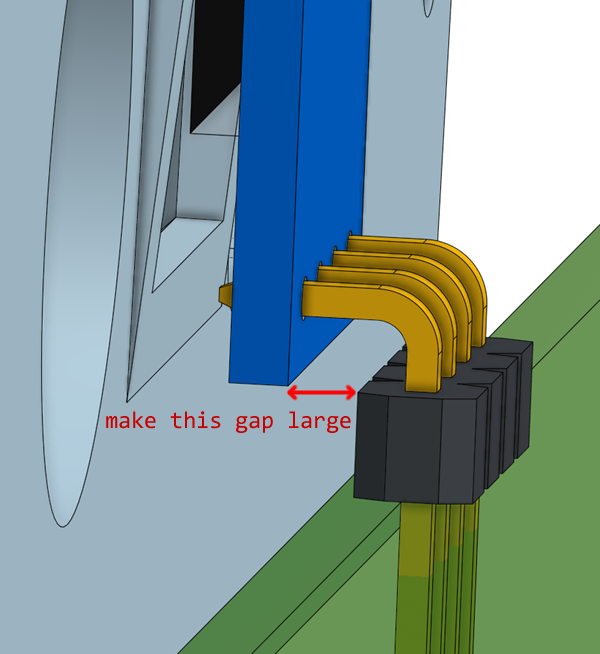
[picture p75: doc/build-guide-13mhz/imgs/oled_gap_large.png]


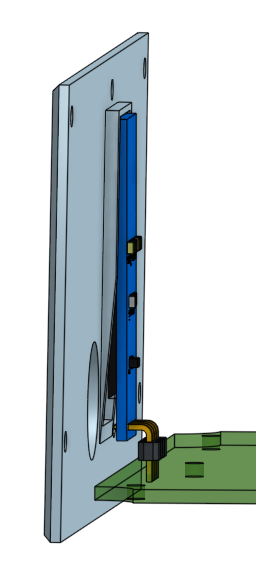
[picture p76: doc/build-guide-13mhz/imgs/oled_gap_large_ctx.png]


Make sure you trim off the protruding header from the bottom of the PCB.

Populate the fan connector

Populate the debug header. It is a 6 pin female header with 0.1 inch pin pitch on the bottom of the circuit board.





Ensure **SJ1** is bridged (ie. shorted) by solder.

At this point in the build process, you need to [flash the firmware to the microcontroller (click here for instructions)](firmware-flashing.md)



(DEVELOPMENT ONLY) Test firmware as much as possible, go through all bring-up tests

Configure the fan solder jumpers (SJ3, SJ4, SJ5), these are on the bottom of the PCB. Do this after firmware flashing. [More details, click here](./assembly-supplement.md#fan-solder-jumper-selection)



## 5. Custom Inductors

Wind custom inductors ([click here for detailed instructions](custom-inductors.md))

(DEVELOPMENT ONLY) measure custom wound inductor for inductance

Populate all custom wound inductors and transformer.

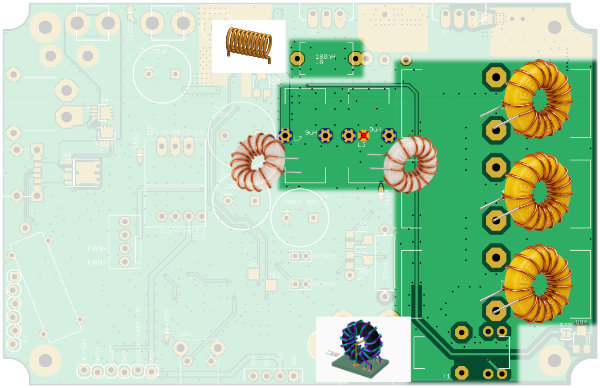
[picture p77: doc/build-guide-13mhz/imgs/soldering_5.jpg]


(DEVELOPMENT ONLY) Sanity check buck converter voltage isn't affected by power factor detector circuit

## 6. Solder/Measurement Jumpers

Ensure that **SJ1** is already bridged/shorted with solder. (BOOT0 pin of MCU)

Ensure that **SJ3** is already bridged/shorted with solder. (fan control signal from MCU)

Short **SJ6** and **SJ7** and **SJ8** with solder.

(DEVELOPMENT ONLY) SJ6 can be used for measuring the drain current of Q1, when populated with a 0.01 ohm measurement resistor.

(DEVELOPMENT ONLY) SJ8 used to measure the current consumption of the 12V rail, to determine the gate driver's efficiency. The tuning happens after the MOSFETs are ready. Short it out with solder if you are not performing this measurement.

## 7. Printed Parts and Templates

3D print: face plate, air intake grille, air exhaust duct, internal air blocker



The files are all [here in this directory](../../mechanical/main)

3D printing material is PETG, or really anything that is more temperature resistant than PLA. Do not use PLA.

Everything can be 3D printed using a 0.4mm or 0.6mm nozzle. Everything is designed to be printable without supports.

The internal air blocker may need some additional tweaking with a knife and file before it fits.

3D print all drilling and cutting templates. These are to be printed using PLA.

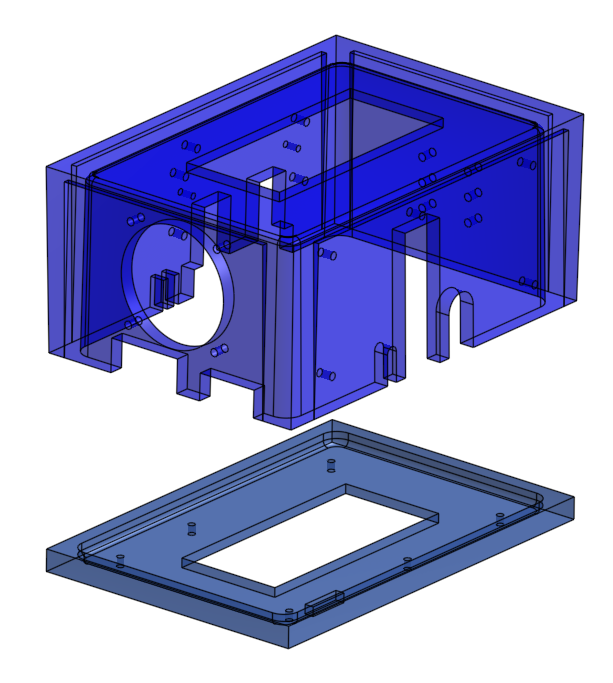
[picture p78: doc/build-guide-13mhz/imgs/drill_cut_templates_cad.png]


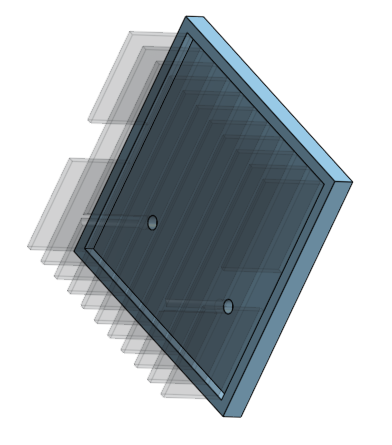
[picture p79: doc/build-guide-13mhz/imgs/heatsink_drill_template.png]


## 8. Enclosure Preparation





Drill and cut enclosure box and lid. Use the cutting and drilling templates to help. Thread tap enclosure box where needed. Please refer to diagram.

(note: all holes start off with a 2.5mm drill bit, and if needed, a larger drill bit is used after)

(note: the template is designed to be used with a drill press, the surface angles of the template are made so that holes being drilled are perpendicular to the box's tapered walls)





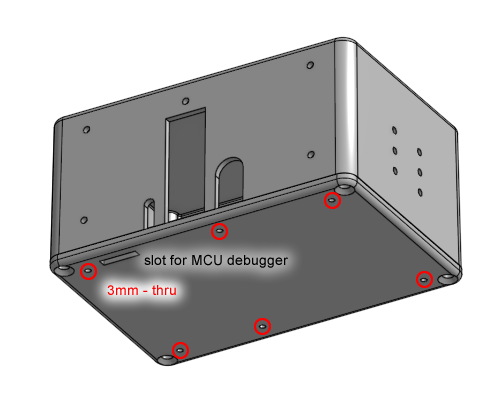
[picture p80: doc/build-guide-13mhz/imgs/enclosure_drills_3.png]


Perform an inspection of 3D printed parts and make sure they fit on the enclosure, such that the cutouts are the right size and in the right positions. Additional cutting, grinding, and/or filing, maybe required to make adjustments. Ensure the face plate lines up, and the tactile button, OLED screen, and coaxial connector all line up when the box is dropped over the circuit board when the circuit board is attached to the bottom box lid.

Clean all metal shavings, debur all drilled and cut edges, dull all sharp edges.

## 9. Power MOSFET and Heatsink Assembly

Drill and thread tap the heatsink. A 3D printed drilling template is provided. The thread tap is for a #4-40 thread. Remember to place the template correctly such that the final result would be optimized for upward airflow.

Cut some of the fins off the heatsink where screws will sit over.

Debur the cuts and clean any metal shavings from heatsink.

Clean the surface of the heatsink and the back of both MOSFETs with rubbing alcohol.

Place a silicone thermal pad between each MOSFET and the heatsink.

Insert a nylon shoulder washer (for #4 screws with 3.7mm OD and 2mm depth) into the TO-220 tab's hole.

Fasten the MOSFET to the heatsink using a #4-40 x 3/8 inch long screw through the nylon shoulder washer.

DO NOT FORGET THE NYLON SHOULDER WASHERS! Or else you blow up your circuit as you short circuit the drain tab to ground.



Before tightening completely, make sure the MOSFET legs are aligned with their perspective footprints on the circuit board. Tighten the screw completely after alignment is ensured.

Cut off the excess silicone thermal pad with an Xacto knife.



Check to make sure heatsink is not causing continuity problems. The drain tab of each MOSFET must not be conductive with the heatsink, nor with each other.

Bend the MOSFET legs, refer to the diagram. The goal is so that the heatsink can mate with the box's face once the box is dropped down on the circuit board.





Solder MOSFETs to PCB, continue to adjust the angle of the MOSFET's legs as needed.

Wire up the NTC thermistors and attach them to the MOSFET's plastic face. First, use high temperature RTV silicone to adhere the wires of the NTC thermistors a part of the PCB near the MOSFET. Then, use high temperature epoxy to adhere the bead of the NTC thermistor to the surface of the MOSFET. Note: this step takes many hours for the silicone and epoxy to cure, be patient. Please refer to photograph.

Perform mandatory safety related firmware tests (tip detection, NTC thermistors, warning near 8S input voltages). These tests are to be done under unlimited current input power (the glass fuse is the protection now), but the buck converter should be set to a low setting.

(DEVELOPMENT ONLY) full functionality testing while not enclosed, tune the air-core inductor in the gate driver circuit, perform burn-in tests, see detailed test plan

## 10. Final Assembly

**Perform a final review of all soldering, including test points, test resistors, solder jumpers.**

Clean the entire PCB, using an antistatic brush and rubbing alcohol.

At this point, you may apply conformal coating over the circuit board if you wish.

Fasten PCB to bottom lid, using the brass standoffs installed previously and M2.5 x 4mm screws.



**Addendum:** you might need to grind away some of the metal too close to the standoffs. See the following photo:

<!-- TODO photo -->

Assemble cooling fan and the air intake grille to the box. See diagram for details.



Clean the heatsink surface and the surface of the box where it will sit, use rubbing alcohol.

Apply thermal paste to the box where the heatsink will sit

Plug in the fan to the circuit board. Watch the polarity of the connector when plugging it in.

Make sure the fan wires are tidy and won't get jammed back into the fan blades once the box is closed, maybe use tape or zip-ties or something to keep the wires short and together.

Drop the box over the whole assembly

Secure the heatsink with #4-40 screws and M3 washers



Clean up thermal paste that got squished out

Fasten on the air exhaust duct, using #4-40 screws



Fasten on the face plate, using #4-40 screws



Using the screws that came with the purchase of the enclosure, screw the lid to the box.

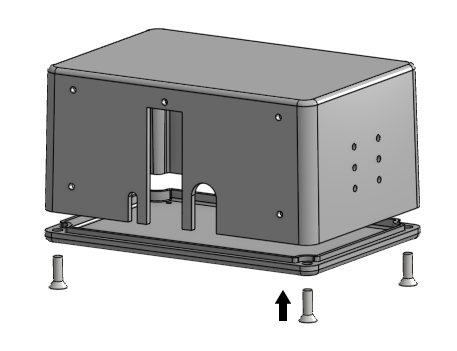
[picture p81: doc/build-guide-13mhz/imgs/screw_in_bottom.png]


Stick on some rubber feet to the bottom of the enclosure.

<!-- TODO: photograph -->

## 11. Enclosed Development

(DEVELOPMENT ONLY) further firmware development

## Iron Stand

Please see [this page about my 3D printed folding soldering stand](../build-guide-iron-stand.md)



## Economy Build

There's a cheaper way of building this project, using more 3D printed parts and less other hardware. [Please see this (click here) document if you are interested](econo-build.md)

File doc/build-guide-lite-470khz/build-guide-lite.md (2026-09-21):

# Hot-Wand Lite 470 kHz Build Guide

## 0. Circuit Board Reception

Get the circuit board from JLCPCB with mostly bottom components already populated. [See this guide on ordering from JLCPCB](jlcpcb-ordering.md)

Populate all out-of-stock components that JLCPCB did not populate on the bottom side first. (this depends on what was available when the circuit board was ordered)

For all the other required parts, [see the shopping document (click here)](shopping.md)

## 1. Input Power

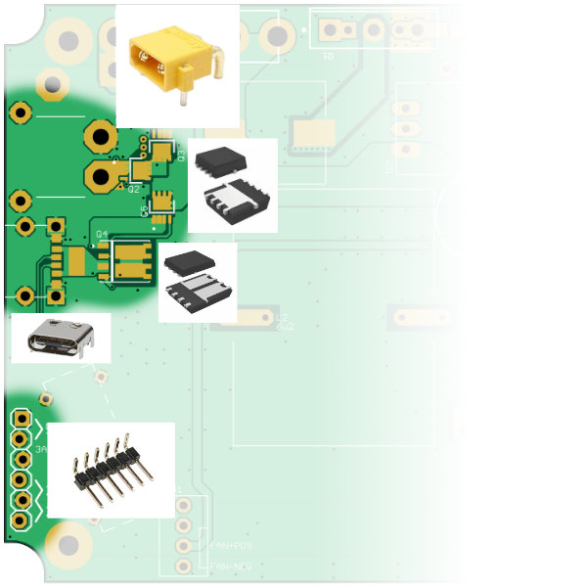
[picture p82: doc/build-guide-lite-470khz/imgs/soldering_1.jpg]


Populate power input MOSFETs, these PowerPAK MOSFETs are hand soldered with a soldering iron (not hot air). For each of the three MOSFETs, [follow these steps (click here for document)](./assembly-supplement.md#power-input-mosfets)

Populate the USB-C connector, followed by the XT30 connector

Populate JP5, which is the header for the shunt jumpers that configures USB-PD negotiation

Test input power. First test XT30 connector and check if the ideal-diode works. I recommend using a smoke-stopper device for this test if using a battery, otherwise, use a non-battery DC input with a XT30 connector.

Then test USB-C negotiation with a variety of configurations (20V vs 28V, 5A limit vs automatic current limit)

During the USB-C tests, the shunt jumpers should have been installed to JP5

## 2. Top Side Components

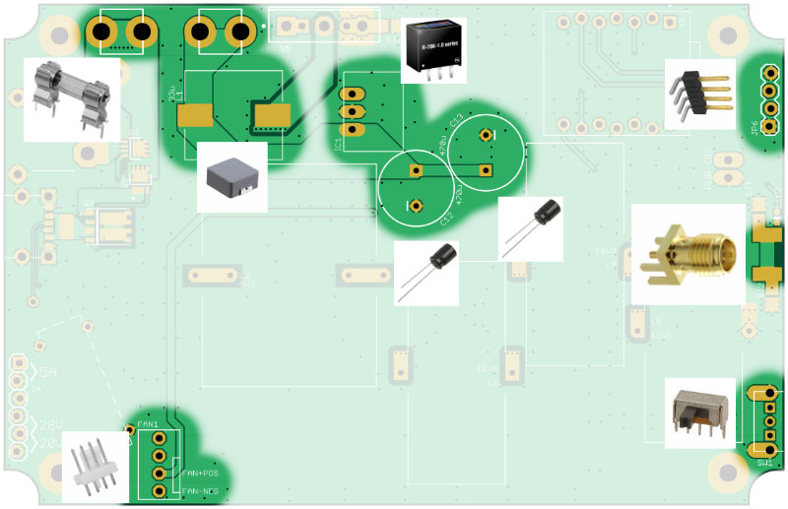
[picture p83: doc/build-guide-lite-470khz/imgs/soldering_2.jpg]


Make sure the components with polarity are installed correctly. The capacitors have a negative lead that is marked with a `-` symbol and a strip on the side.

The SMA coaxial connector is supposed to be soldered upside down, with the center pin on the bottom of the board.

(For revision `20260820A` only) The power switch needs to have a direction selected, to choose which side means "ON" and which side means "OFF". I leave this up to the user. Solder between one of these two locations to make the choice.

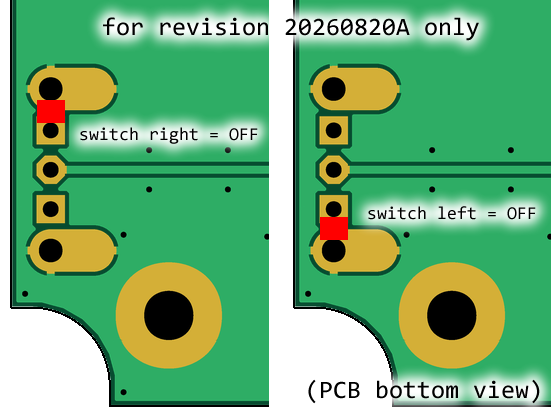
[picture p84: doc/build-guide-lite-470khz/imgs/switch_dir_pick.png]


## 3. Microcontroller and Firmware Bring-Up

WARNING: NEVER flash firmware while the main input power is connected. You can also just remove the microcontroller module before flashing it.

Many microcontroller modules are compatible with this design:

 * Seeed Studio XIAO RP2040
 * Seeed Studio XIAO SAMD21
 * Seeed Studio XIAO ESP32-C3
 * Waveshare RP2040 Zero (needs to be installed upside down)
 * ESP32-C3 Super Mini

Solder male headers to the microcontroller module (the headers should have been included with the microcontroller module).

The microcontroller can be [flashed using Visual Studio Code and PlatformIO (click here for a guide)](firmware-flashing.md).

It is recommended to solder female headers onto the Hot-Wand-Lite PCB where the microcontroller module footprint is, and then plugging in the microcontroller module. This makes the microcontroller module removable.

## 4. Custom Inductors

There are 4 custom inductors in this design. [Follow the instructions on how to create them (click here)](custom-indoctors.md), and then solder them to their perspective locations.

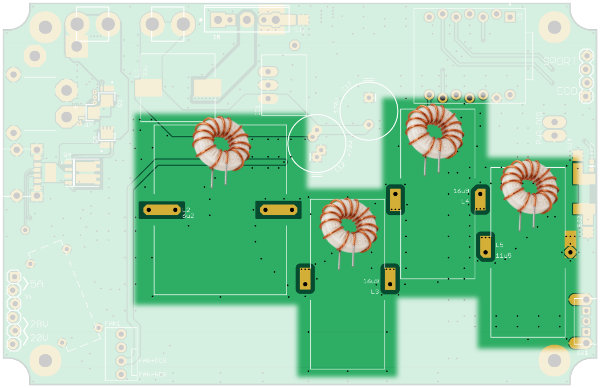
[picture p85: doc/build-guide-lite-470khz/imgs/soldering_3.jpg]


(DEVELOPMENT ONLY) If a LCR meter is available, record the number of winds for each individual inductor and the resulting inductance.

## 5. MOSFET Heatsink

Assemble the MOSFET together with the heatsinks according to the diagrams:

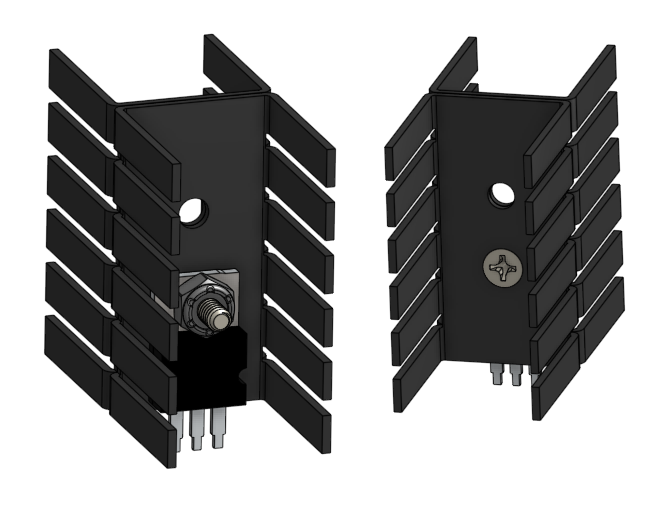
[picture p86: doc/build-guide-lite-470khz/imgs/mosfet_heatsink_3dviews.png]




The bottom 3 fins of the heatsink needs to be bent to avoid the 12V buck converter, use a gentle curved bend to avoid snapping the aluminum. There's 1 bottom fin that needs to be snapped off so it doesn't hit the SMD inductor. You must do this before soldering.



Then solder the MOSFET to the circuit board.

WARNING: do NOT ever use the heatsink or the TO-220 as a ground, it is not ground, it is the drain of the MOSFET carrying high RF voltage.

## 6. Solder Jumpers

SJ1, SJ2, SJ3, SJ4, SJ5 are all meant for a developer to measure the ground return current. For normal use, these all need to be bridged (ie shorted-out) with solder.

(DEVELOPMENT ONLY) At this point, full testing can happen, as long as tests are short enough as to not require a cooling fan.

## 7. 3D Printed Box

3D print the box, consisting of two parts: the body, and the bottom. Avoid using PLA for this, use something that can stand a bit more temperature. The design is meant to be printed without any supports.



[Find the files required here (click here)](../../mechanical/lite)

(note: if you want a more expensive premium metal build, the Lite version PCB is compatible with the aluminum enclosure that the 13.56 MHz version uses, and you will need the brass standoffs, and the heatsink stack needs to be insulated from the MOSFET)

## 8. Final Assembly and Testing

**Perform a final review of all soldering, including test points, test resistors, solder jumpers.**

Clean the entire PCB, using an antistatic brush and rubbing alcohol.

At this point, you may apply conformal coating over the circuit board if you wish.

Fasten PCB to bottom lid using four M2.5 x 6mm screws.



Insert the cooling fan into the slot for the fan. Make sure the direction of airflow is towards the inside of the box. The fan should not need any fasteners, but you can use a small amount of hot glue to hold it in place (it will sit on the XT30 connector).



Plug in the fan, making sure the polarity is correct.

Make sure the fan wires are tidy and won't get jammed back into the fan blades once the box is closed, maybe use tape or zip-ties or something to keep the wires short and together.

Drop the box over the whole assembly. The heatsink might touch the box, that's ok. Use four M2.5 x 6mm screws to fasten the bottom lid to the box body.



## Handpiece

#### If using: Radio Thermal Handpiece

Radio Thermal provides instructions on making a cheap handpiece, [please see their instructions](https://github.com/RadioThermal/RadioThermal_Soldering_OSHW/tree/main/Handpiece)

When finished, you can just connect the it to the SMA connector

#### If using: Thermaltronics Handpiece

Thermaltronics still sells their older SHP-K handpieces (meant for 470 kHz cartridges) for about $50 dollars, but they have a weird big connector. You can either cut off the connector and solder on a SMA connector, or make some sort of adapter by yourself.

## Iron Stand

Please see [this page about my 3D printed folding soldering stand](../build-guide-iron-stand.md)



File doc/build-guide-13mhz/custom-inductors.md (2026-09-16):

# Custom Inductors

Make sure you are familiar with how to use enamel coated magnet wire correctly, how to prepare the ends of the wires for soldering, etc.

Remember that, one "turn" is defined as passing through the center of the toroid once. It doesn't have to be a complete loop.

## 9 uH choke

Both small custom inductors use the Fair-Rite 5961004901 toroid core, and 22 AWG solid core enamel coated wire (aka magnet wire).

For the 9 uH choke, use 13 turns. The A_L of this toroid core is 80 +/- 25%, 13 turns is worst case 10.14 uH. Ending up with a slightly higher than specified inductance for these 9 uH chokes is not the end of the world.

Equation for wire length: `(2 * 13) + T * (2 * ((16 - 9.6) / 2 + 6.35) + pi * 0.644) * 1.05`

13 turns should be 315 mm of wire. I highly recommend cutting sections of 350 mm to make it easier to pull.

If you actually managed to get a `K16x8x6` identical to the one SergeyMax used, then use 15 turns as per original instructions.

## Current transformer

The ratio is 1:14:14

Uses the Fair-Rite 5961004901 toroid core and 22 AWG enamel coated wire.

The primary (the 1 in 1:14:14) is just a single wire crossing the inside of the toroid once. No crossing on the bottom/outside of the toroid.

I recommend cutting off about 3 feet of 22 AWG enamel coated wire, and then folding all of it exactly in half as if it was a pair of wires, then twisting the pair together, evenly.

Then wrap the twisted-pair around the toroid 14 times. Do not cause these wires to cross while wrapping around the toroid.

Reference the following 3D model:





You need to use a multimeter to confirm which wire is which before soldering the wire ends into the PCB.

## Large inductors

The three large inductors are using the Amidon T130-6 toroid cores and 16 AWG solid core enamel coated wire.

Equation for wire length: `(2 * 10) + T * (2 * ((33 - 19.8) / 2 + 11.1) + pi * 1.29) * 1.05`

180 uH -> 4 turns -> 186 mm

400 uH -> 6 turns -> 269 mm

540 uH -> 7 turns -> 310 mm

## Coreless inductor L8

Use 10 turns of 22 AWG wire, wound around a 5 mm dowel or similar mandrel. Make the coil approximately 10 mm wide, then squeeze or stretch it during tuning.



Using a 5 mm inside diameter, a 0.644 mm wire diameter, a 1 mm pitch, two 10 mm leads, and 5% extra wire for winding tolerance, the approximate cut length in millimeters is:

`(2 * 10) + 10 * sqrt((pi * (5 + 0.644))^2 + (10 / 10)^2) * 1.05`

This gives approximately 207 mm, so cut about 210 mm of wire before winding.

## Securing the Inductors

Custom inductors are commonly secured with neutral-cure, electronics-grade RTV silicone, which remains flexible and is relatively easy to remove, or with two-part epoxy when a rigid, permanent bond is wanted. Avoid acid-cure RTV silicone, recognizable by its vinegar smell, because it can corrode copper and electronics. Avoid hot-melt glue as it is very possible for this circuit to get hot.

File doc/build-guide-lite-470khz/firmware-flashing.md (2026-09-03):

# Firmware Flashing for Hot Wand Lite

While the microcontroller module is removed from the circuit board, plug it into your computer via a USB-C cable.

Run Visual Studio Code **with the PlatformIO extension installed**.

Use Github to obtain a copy of the Hot-Wand project repo. (do this either by cloning it from Github or by downloading the zip package from Github)

Use Visual Studio Code to open the `firmware-lite` directory within the project repo.

PlatformIO will attempt to load the project, this might take a long time. After PlatformIO is ready, it will show the options:

 * seeed_xiao_rp2040
 * seeed_xiao_samd21
 * waveshare_rp2040_zero
 * seeed_xiao_esp32c3
 * esp32c3_supermini

Expand one of these, and click "Upload". It should be that simple.



Note: Visual Studio Code and PlatformIO might need to install more things on your computer when doing this for the first time. It might be super slow.

## Troubleshooting

If something goes wrong, it might be in the build step or in the upload step. If it's in the build step, you can also click "Build" and use the messages to help you troubleshoot.

Problems during the upload step are often caused by driver issues or not selecting the right COM port.

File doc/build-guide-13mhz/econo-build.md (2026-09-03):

# Economy Build for Hot Wand 13.56 MHz version

There's a way to build the 13.56 MHz version of Hot Wand for cheap, using a 3D printed enclosure and skipping a lot of components.

Due to the lack of an aluminum enclosure, this design relies heavily on the cooling fan for cooling. It also does not provide an RF shield between the inside and outside.

If you wish to build this way, then you need to be smart and pay attention to both documents to figure out what to buy and what not to buy.

Do not buy any of the brass standoffs.

Do not buy the aluminum enclosure.

The screws used are `M2.5 x 8mm` and `#4-40 x 3/8 in`. There are no nuts or washers required at all.

Do not buy thermal paste, it is not needed.

You do still need to make the custom heatsink fins for the buck converter out of the copper sheet.

Note: This design only works for a heatsink that is 45mm x 45mm x 15mm, `HSB21-454515`. This heatsink is cheaper on Digi-Key than ones on Amazon even in bulk.

## 3D Printed Box

The box is designed as two pieces. 3D print them both out a temperature resistant material, such as PETG. See [this directory for the files you need](../../mechanical/econo)



* Box Body
* Bottom Lid
* Heatsink Drilling Template

The heatsink needs a drilling template, you can print this out of PLA because it'll be thrown away after you are done.

## MOSFET and Heatsink Mounting

Drill and thread tap the heatsink. A 3D printed drilling template is provided. The thread tap is for a #4-40 thread. Remember to place the template correctly such that the final result would be optimized for upward airflow.

Cut some of the fins off the heatsink where screws will sit over.

Debur the cuts and clean any metal shavings from heatsink.

Clean the surface of the heatsink and the back of both MOSFETs with rubbing alcohol.

Place a silicone thermal pad between each MOSFET and the heatsink.

Insert a nylon shoulder washer (for #4 screws with 3.7mm OD and 2mm depth) into the TO-220 tab's hole.

Fasten the MOSFET to the heatsink using a #4-40 x 3/8 inch long screw through the nylon shoulder washer.

DO NOT FORGET THE NYLON SHOULDER WASHERS! Or else you blow up your circuit as you short circuit the drain tab to ground.



Before tightening completely, make sure the MOSFET legs are aligned with their perspective footprints on the circuit board. Tighten the screw completely after alignment is ensured.

Check to make sure heatsink is not causing continuity problems. The drain tab of each MOSFET must not be conductive with the heatsink, nor with each other.

The MOSFET legs do NOT need to be bent.

See original instructions about attaching the thermistors.

## Fan Installation

The fan is inserted into the plastic enclosure and held in place using hot glue. No fasteners are used. The design has the fan resting on the XT30 connector, so there's no fear of it moving even if there are no fasteners.



Make sure the airflow direction is into the box.

Plug in the fan before closing the box.

## Screwing the PCB Down

**Perform a final review of all soldering, including test points, test resistors, solder jumpers.**

Clean the entire PCB, using an antistatic brush and rubbing alcohol.

At this point, you may apply conformal coating over the circuit board if you wish.

Use **five** M2.5 x 8mm screws to screw down the PCB. Brass standoffs are not used. The screw near the F-type coax connector is installed, the screw near the buck converter is not installed.

(alternatives: #2 x 5/16" thread forming screws or sheet metal screws or plastite screws, M2.5 x 8mm plastite screws)



Plug in the fan before closing the box.

## Final Box Closure

Use M2.5 x 8mm screws to fasten the enclosure box to the enclosure bottom lid.



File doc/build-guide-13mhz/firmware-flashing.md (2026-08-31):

# Firmware Flashing

The microcontroller is a STM32F042. On the circuit board, there is a 6 pin debug header with the necessary SWD signals for firmware flashing. The signals are labelled on the circuit board.

The assembly specifies that a 6 pin female header is installed to the bottom of the PCB at this location. This allows the debug port to be accessed even when the Hot-Wand device is fully enclosed. This means it is easier to use male-to-female dupont jumper wires to make the connection between the debugger and our circuit board.



The firmware file is available as a `*.hex` file to download and flash directly.

The easiest tool to use for firmware flashing is a ST-Link V2 (or V3). This tool is most easily used with ST's own[STM32CubeProgrammer software (click here for ST's page to download)](https://www.st.com/en/development-tools/stm32cubeprog.html).

You can purchase a cheap ST-Link V2 from online retailers very easily. If you own a STM32 development board, you can also use the on-board ST-Link that is built into those development boards.

You might own a dedicated JTAG/SWD debugger device, such as a Segger J-Link, Keil ULINK, or [Black Magic Debug](https://black-magic.org/), in which case, I will leave it up to you on how to perform the flashing.

## Instructions for STM32CubeProgrammer

Wire up the debugger, make the connections

1. GND / ground
2. Vtgt or 3.3V
3. SWDIO
4. SWCLK
5. NRST or RST

The other remaining 6th signal is not connected.

Connect the debugger to your computer using a USB cable.

Run `STM32CubeProgrammer`.

Power on the Hot-Wand, using your preferred power input method. (be smart about it, if you can use one with a current limit, then use a 0.5A current limit)

Click on `Connect` inside `STM32CubeProgrammer`. The GUI should populate with some information about the current microcontroller, indicating that it is a `STM32F042`.

<!-- Insert screenshot of a successful STM32CubeProgrammer connection here. -->

Open the `Erasing & Programming` page using the navigation on the left side of the window.

Under `File path`, browse to and select the downloaded firmware `*.hex` file. The addresses required for programming are contained in the hex file, so no start address needs to be entered manually.

Enable the option to verify the programmed data after writing, if it is available in the installed version of STM32CubeProgrammer.

Click `Start Programming` or `Download`, depending on the version of the software. Wait for both the programming and verification operations to complete successfully. Do not disconnect the debugger or remove power while this operation is in progress.

<!-- Insert screenshot of the selected firmware file and programming controls here. -->

<!-- Insert screenshot of the successful programming and verification message here. -->

Click `Disconnect`, close STM32CubeProgrammer, and then remove power from the Hot-Wand. Disconnect the USB cable and jumper wires after the target is no longer powered.

Power the Hot-Wand normally. The device should start using the newly programmed firmware.

## Firmware Updating

You can update the firmware using the same procedure. But, as SJ3 is connected, the debug signal will cause the fan to do weird things.

## Troubleshooting

If STM32CubeProgrammer cannot connect to the microcontroller, check the following:

1. Confirm that `GND`, `SWDIO`, `SWCLK`, and `NRST` are connected to the matching signals on the debugger.
2. Confirm that the target is powered and that the debugger can detect the target voltage.
3. Confirm that the ST-Link is selected as the connection interface.
4. Reduce the SWD connection frequency and try connecting again.
5. Select the option to connect while the target is held in reset, if that option is available, and try again.
6. Disconnect and reconnect the debugger USB cable, then restart STM32CubeProgrammer.

If programming completes but verification fails, repeat the operation once after checking the connections and power supply. If it continues to fail, perform a full chip erase and then program the firmware file again. A full chip erase removes the existing firmware and any settings stored in the microcontroller's flash memory.

If the device does not start after a successful programming operation, remove power completely, wait a few seconds, and power it again. If the problem remains, reconnect the debugger and confirm that the programming and verification operations complete without errors.

## Note for Firmware Development

Be extremely careful in regards to the RF signal generation. That pin must never be left in a high state. When left in a high state, the MOSFET of the RF amplifier will be turned on, and if left on for too long, it represents a short circuit as flat DC voltage starts to flow through it.

This means never halting the code unexpectedly while RF signal generation is active. Do not pause at a breakpoint, single-step through the RF generation code, or otherwise stop the processor while the RF output pin may be high. A debugger can halt the CPU without changing the state of its GPIO pins, leaving the last output level applied indefinitely.

Before pausing or resetting the microcontroller during development, first disable RF generation and confirm that the output pin has returned to a low state. Firmware should also configure this pin as a low output as early as possible during startup and force it low before entering an error state, shutdown sequence, or other condition that may prevent normal signal generation from continuing. Treat unexpected faults and infinite loops in the RF generation path as potentially unsafe, since software protection cannot change the pin state after the processor has been halted by a debugger.

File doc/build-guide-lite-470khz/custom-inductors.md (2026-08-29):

# Custom Inductors

In Radio Thermal's design, they used the Kool Mu 0077932A7 core, with Aₗ = 32 nH/turn², +/- 8%. The first core is actually two of these cores epoxied together in a stack, making it roughly Aₗ = 64 nH/turn².

The coated core dimensions are 27.69 mm maximum outside diameter, 14.10 mm minimum inside diameter, and 11.94 mm maximum height. For 22 AWG wire, using a diameter of 0.644 mm, two 10 mm leads, and 5% extra wire for winding tolerance, the approximate cut length in millimeters is:

Single core, where `T` is the number of turns:

`(2 * 10) + T * (2 * ((27.69 - 14.10) / 2 + 11.94) + pi * 0.644) * 1.05`

Two cores stacked together:

`(2 * 10) + T * (2 * ((27.69 - 14.10) / 2 + (2 * 11.94)) + pi * 0.644) * 1.05`

One turn means passing the wire through the center of the toroid once. These lengths are deliberately approximate; cut a little more if the two-core stack has a thick epoxy joint or if you want longer leads.

For 6.2 uH: 10 turns using 2 cores, requiring about 685 mm of wire; or 14 turns using 1 core, requiring about 601 mm

For 16.9 uH: 22 to 24 turns, requiring about 932 mm to 1015 mm of wire (choose 23 turns and about 974 mm if no measurement)

For 11.5 uH: 18 to 20 turns, requiring about 766 mm to 849 mm of wire (choose 19 turns and about 808 mm if no measurement)

Radio Thermal's developers ask that you use 22 AWG wire or thicker, and use a VNA or LCR meter to verify the results.

If you really do not have the measurement equipment, I have indicated the best choice.

#### Total Wire Lengths

The totals below assume 22 AWG wire and use the rounded cut lengths given above.

Using the recommended turn counts and two stacked cores for the 6.2 uH inductor:

`685 + 974 + 808 = 2467 mm = 2.467 m = 8.09 ft`

Depending on whether 22 to 24 turns and 18 to 20 turns are used for the other two inductors, the total ranges from approximately 2383 mm to 2549 mm, or 2.383 m to 2.549 m (7.82 ft to 8.36 ft).

If the 6.2 uH inductor is instead wound with 14 turns on one core, while the recommended turn counts are used for the others:

`601 + 974 + 808 = 2383 mm = 2.383 m = 7.82 ft`

For one complete unit, the practical minimum purchase is 3 m (10 ft) of 22 AWG magnet wire. To leave enough wire for trimming mistakes or rewinding an inductor, buy approximately 5 m (16.4 ft), or the next larger standard spool size.

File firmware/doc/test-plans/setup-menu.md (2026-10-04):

# Automated Setup Menu test (13.56 MHz Hot-Wand)

## Run it

Build PlatformIO environment **stm32f042_setup_swd** in firmware/platformio.ini first. The Python runner flashes that already built ELF; it does not build firmware. This image provides the SWD synthetic button, preserves SWD pins, and displays the vision fiducial as its first OLED frame. The ordinary stm32f042 and stm32f042_cubeide environments are not suitable.

Before launching, power the safe, checked board and connect the ST-Link V3MINIE through SWD, NRST, target voltage, and ground. Keep L3–L6 and the handpiece absent. Put the Sony RX0 II in PC Remote still-photo mode, with JPEG size L, PC+Camera storage, manual focus available, and an exposure that resolves individual OLED pixels. Close other debugger or camera applications. Check framing with:

    py firmware\tools\auto_testing\eyes_rx0.py --view

The whole OLED must be visible. From the repository root, start the unattended test with:

    py firmware\tools\auto_testing\setup_menu_test.py

Optional arguments:

    py firmware\tools\auto_testing\setup_menu_test.py --output-dir .\menu-run-01 --crop-to 800
    py firmware\tools\auto_testing\setup_menu_test.py --calibration .\previous-run\fiducial_calibration.json

The runner needs numpy, opencv-python, Pillow, gphoto2, PlatformIO ARM GDB, and PlatformIO OpenOCD. Full executable paths are near the top of tools/auto_testing/build_metadata.py; update them if installations move. The default output directory is date-and-time named under the current directory. An explicit --output-dir must name a new directory. The run includes the five-minute inactivity tests, so allow more than 15 minutes plus camera focus and transfer time.

## Modules and evidence

| Module | Responsibility |
| --- | --- |
| tools/auto_testing/eyes_rx0.py | Importable Rx0Camera handles still capture, automatic fiducial focus/exposure search, and corrected capture. |
| tools/auto_testing/fiducial.py | Finds the fiducial and applies its saved perspective transform. |
| tools/auto_testing/image_processing.py | Compares corrected photos with the framebuffer using only the **central 2×2 camera pixels** of each 8×8 OLED pixel region. |
| tools/auto_testing/build_metadata.py | Reads symbols and addresses from the ELF and rejects flash load ranges that reach NVM. Reads the menu table in compiled target memory. |
| tools/auto_testing/target_gdb.py | Starts OpenOCD, connects persistent GDB over local TCP, flashes, reads the sent-frame mirror and NVM, sends synthetic presses, and resets. |
| tools/auto_testing/frmbuf2png.py | Converts framebuffer blobs to upright black-and-white PNGs. |
| tools/auto_testing/setup_menu_test.py | Runs the phases below and writes the report and image artifacts. |

The runner saves the initial 1 KiB NVM page to nvm_before.bin, flashes only the ELF application load ranges, then checks that the reserved NVM page remained byte-for-byte unchanged. It does not directly write settings or erase NVM. Firmware Save actions may append journal records. At the end, the runner restores the initial *setting values* through the menu and verifies them; the final raw page may differ from the backup.

Calibration happens while the fiducial gate remains visible. Unless --calibration is supplied, focus and exposure search are automatic; the corrected fiducial and JSON recipe are saved. The runner dismisses the gate by writing vision_test_fiducial_press, leaving the synthetic boot hold intact. The fiducial reappears after every reset. An existing JSON positions the camera once; subsequent stills reuse focus, exposure, and perspective transform.
Every downloaded calibration JPEG is retained under calibration_stills in the run directory.

After each successful OLED I2C send, the vision-test firmware copies the 512-byte framebuffer into vision_test_oled_sent_framebuffer and finishes an even vision_test_oled_sent_generation. GDB reads this completed-frame mirror, briefly halting and resuming the MCU. An odd generation means the copy was interrupted and must be retried. GDB-MI values are parsed only from their command's result record, excluding asynchronous stop notifications. The MCU measures button durations. The mailbox symbols are btn_swd_test_command_ms, btn_swd_test_state, and btn_swd_test_completed. Commands are issued only from idle: 0 releases the boot hold, 200 ms is short, and 1250 ms is long. The runner also tests 850, 1150, and 3000 ms. Expected page order and option strings come from the setup_menu_items table in the *flashed ELF*.

The photo comparison proves that the lit screen agrees with the framebuffer sent by firmware. On the voltage page, the bottom 18 OLED rows contain a live measurement that may change between the SWD read and the PTP still. The report gives both the whole-frame mismatch and the checked upper-region mismatch; only the latter determines pass/fail there. It does **not** independently OCR displayed words. Navigation, distinct option images, option wrap, and NVM persistence are checked separately. Retained photos permit review of exact text, clipping, and layout. A camera failure is logged and the run continues with framebuffer evidence if possible. Missing SWD connection, persistently invalid framebuffer pointer, unsafe ELF load range, or a button transport that cannot advance is a hard stop.

## Automated cases

| Phase | Operations and expected evidence |
| --- | --- |
| A1 | Release the boot hold before the three-second entry threshold; capture the non-menu screen. |
| A2–A3 | Reset, enter Setup Menu, release the hold without a menu action, then short-press to fan and polarity pages. |
| A4–A5 | Check value changes from 1250 and 3000 ms holds; probe 850 ms as short and 1150 ms as long. Reset to a known state. |
| B1 | Short-press through all eleven compiled pages and wrap. Distinct page images and return to the initial frame are checked. |
| B2 | On each value page, long-press through its compiled option count. Option images must be distinct and wrap to the starting image. The live voltage footer is excluded from image signatures. |
| B3 | Edit two settings in RAM, navigate away and back, discard, reenter, and verify the saved baseline remains. |
| B4 | Capture the voltage page at two times, step through positive and negative calibration selections, and retain images. Voltage accuracy requires an external reference. |
| C1–C2 | Save one field, then several fields; verify NVM journal and reentry values. |
| C3 | Edit saved settings without saving, discard, and verify the previous NVM values. |
| C4 | Issue **GDB reset**, reenter, and verify persistence. This emulates a reboot; it does not remove board power or prove power-loss behavior. |
| C5 | Restore initial setting values through the menu, Save, reset, and verify. |
| D1 | Make an unsaved edit, wait at least 305 seconds without a button command, capture the post-timeout screen, and confirm no save. |
| D2 | Wait about 270 seconds, send activity, capture about 45 seconds later, then wait for the new timeout and capture again. |
| D3 | Start a long press near 299.3 seconds after menu entry and record whether it beats timeout. A firmware discrepancy is possible because timeout is checked before events. |
| D4 | RF and buck safe-state verification remains a separate electrical probe check; the script reports it as blocked. |

report.txt contains timestamps, mailbox observations, expected page/value, mismatch fractions, NVM checks, failures, and interruptions. Each observation has numbered full and corrected camera images, a raw framebuffer binary, a synthetic framebuffer PNG, and classified/difference images when comparison succeeds. nvm_at_stop.bin is attempted on an interrupted run. Individual discrepancies are logged and the sequence continues when possible; a hard stop retains available artifacts.

## Limits and separate checks

The physical PA7 switch, EXTI path, contact bounce, and RF/buck electrical behavior are outside this SWD script. The human button bring-up and high-impedance electrical checks remain separate. With L3–L6 and the handpiece absent, this run says nothing about loaded RF heating, fan electrical performance, or tip detection. Blank-NVM defaults and forced flash-write failures require separately prepared fixtures; this script does not erase or corrupt NVM to create those conditions.

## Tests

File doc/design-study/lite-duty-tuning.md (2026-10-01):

# Lite continuous-carrier duty experiment

2026-09-27. Investigate changing the gate HIGH fraction within every RF cycle,
independently of the existing burst power setting. No firmware changes made.

## Method and limits

Original nominal PCB capacitors, including C11; 20 V supply; 470 kHz;
continuous carrier. The inherited FDP18N20F model and STP-CN04 cold, warm
(below Curie), and hot (above Curie) impedances are unchanged from the
[overtemperature study](lite-overtemperature-tuning.md). These are not measured
K75C002 impedances, and the model does not predict equilibrium temperature.
Actual fitted MOSFET and any board modifications must be accounted for before
applying the results. Clamp action, avalanche, core losses/saturation and thermal
feedback are not modeled.

[duty_sweep.py](sim-470khz/overtemperature/duty_sweep.py) runs 30 cases at
400 cycles with a 10 ns maximum timestep; `--verify` runs 21 cases at 800
cycles with a 5 ns maximum timestep, including more extreme low duties.
Measurements average the final 40 cycles. Peak drain voltage includes startup.
Duty is the command waveform's midpoint-to-midpoint HIGH fraction; gate rise,
fall, Miller plateau and threshold affect actual MOSFET conduction time.

The sweep holds frequency constant: at 470 kHz the period is 2.128 us;
50% gives approximately 1.064 us HIGH, while 40% gives 0.851 us HIGH.

Class E can be designed for non-50% duty. The matching and shunt network must
still provide appropriate drain voltage at turn-on; changing duty alone in a
fixed network is not equivalent to redesigning it for that duty. See
[Yang et al., Analysis and design of Class-E power amplifiers at any duty ratio](https://metal.shanghaitech.edu.cn/publication/J5.pdf).

## Initial screening

| Gate duty | Cold tip W | Warm tip W | Hot tip W | Warm MOSFET W | Warm drain at gate rising through 3 V |
| --- | ---: | ---: | ---: | ---: | ---: |
| 30% | 15.25 | 14.48 | 5.81 | 16.87 | 65.0 V |
| 40% | 43.84 | 48.88 | 5.78 | 12.25 | 45.4 V |
| 45% | 58.39 | 67.64 | 5.75 | 7.98 | 25.1 V |
| 50% | 65.77 | 77.64 | 5.73 | 6.03 | 4.8 V |
| 52.5% | 66.54 | 78.49 | 5.72 | 5.93 | -0.7 V |
| 55% | 66.44 | 78.33 | 5.71 | 5.94 | -0.8 V |
| 60% | 66.25 | 78.08 | 5.69 | 5.90 | -0.8 V |
| 65% | 66.67 | 77.93 | 5.83 | 5.82 | -0.8 V |

At 65%, the **hot** MOSFET dissipates 2.92 W and has 31.1 V drain voltage at
the 3 V gate crossing. Thus the warm-state column alone cannot qualify a duty.
The crossing is an indicator of turn-on conditions, not an exact measurement
of the instant channel conduction begins.

Reducing duty to 40% substantially reduces useful cold/warm power but hardly
changes hot power. Worse, the switch now discharges the drain capacitance from
substantial voltage each cycle. At 45 V, C1 alone contains about 15.2 uJ;
discharging that energy at 470 kHz corresponds to about 7.1 W. This is an
illustration of hard-switching loss, not an additional loss to add to the
simulated MOSFET dissipation.

## Longer, finer verification and shorter pulses

The repeat at 40%, 50% and 55% agreed with initial tip-power results within
0.2%. Maximum adjacent-window power change was 0.034% in the initial sweep
and 0.013% in verification. These check numerical consistency, not hardware
accuracy. Full data: [initial CSV](sim-470khz/overtemperature/duty.csv) and
[verification CSV](sim-470khz/overtemperature/duty_verify.csv).

| Gate duty | Cold tip W | Warm tip W | Hot tip W | Warm MOSFET W | Hot MOSFET W |
| --- | ---: | ---: | ---: | ---: | ---: |
| 10% | 1.03 | 0.76 | 0.64 | 6.08 | 7.09 |
| 15% | 1.85 | 1.38 | 1.60 | 8.12 | 6.89 |
| 20% | 3.65 | 2.81 | 3.68 | 11.37 | 3.81 |
| 25% | 7.52 | 6.31 | 5.24 | 14.88 | 1.46 |
| 50% reference | 65.78 | 77.66 | 5.73 | 6.04 | 0.72 |

Very short pulses eventually reduce hot power, but at 15% the model puts
6.89 W into the hot-state MOSFET to deliver just 1.60 W to the tip. This is
not an attractive idle-power solution; checking only hot-state loss would
also miss the large heating-state losses at intermediate duties.

## Firmware and bench implications

Carrier duty needs its own parameter, separate from `power`. The current
SAMD21 and RP2040 compare settings use half the period, and the RMT backend
uses half-period HIGH counts for both explicit pulses and the carrier.
All these paths must agree if a duty control is implemented. Burst behavior
needs separate verification after any change; these runs use continuous RF.

A small increase toward 52-55% is potentially an efficiency-tuning experiment,
not a useful hot-tip power reduction in this model. Start at 15 V and 50%,
change only one parameter, and inspect gate/drain timing and MOSFET temperature
in cold, heating and settled-hot conditions. Scope ground goes to board GND.
There is no model-certified safe duty range. Shorter pulses should not be
accepted merely because the tip warms more slowly or the USB meter reads less.

The existing L2 increase and capacitor adjustments remain more promising for
reducing above-Curie electrical power. A firmware-only alternative to study
separately is longer RF bursts with genuine gate-low pauses, so ring-up losses
are a smaller fraction of delivered energy. Startup/shutdown peaks and thermal
ripple must be checked; the present sweep does not establish safe burst timing.

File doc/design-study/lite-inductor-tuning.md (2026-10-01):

# Lite inductor adjustment experiment

2026-09-26. Initial recommendation: increase **L2**, the nominal 6.2 uH
series inductor wound on two stacked cores. Make small, reversible adjustments
to winding spacing, with electrical measurements before accepting a lower tip
temperature as an improvement.

## Assumptions and evidence

The user reports inductances within 0.1 uH of nominal on an LCR meter and
evenly spaced windings. Radio Thermal's authors suggested adjusting the
inductors under operating conditions.

The numerical screening below assumes the **original capacitors including
C11**, approximately **470 kHz**, **20 V**, and **continuous RF**. Confirm this
matches the hardware before using the numbers. The previous electrical model
uses STP-CN04 load states, not measured K75C002 impedances; these are directions
to investigate, not predictions of tip temperature or safe limits.

The sweep changes one ideal inductance at a time. Winding movement can also
change capacitance, leakage coupling and loss, which this sweep does not model.
The manufacturer explicitly notes that actual powder-core inductance depends
on winding construction and leakage flux:
[Magnetics powder-core explanation](https://www.mag-inc.com/products/powder-cores/learn-more-about-powder-cores).
Low-signal inductance matching alone does not validate the complete loaded RF
network or its switching behavior.

| Single adjustment | Cold tip W | Just below Curie W | Above Curie W |
| --- | ---: | ---: | ---: |
| Original | 65.77 | 77.64 | 5.73 |
| L2 +2%, 6.324 uH | 60.79 | 69.53 | 5.25 |
| L2 +5%, 6.510 uH | 53.20 | 57.97 | 4.63 |
| L2 +10%, 6.820 uH | 42.27 | 43.19 | 3.80 |
| L3 +5%, 17.745 uH | 68.10 | 80.06 | 6.05 |
| L4 +5%, 17.745 uH | 64.71 | 75.00 | 5.64 |
| L5 +5%, 12.075 uH | 68.93 | 81.01 | 6.18 |

L2 +5% reduces hot heating about 19%, but also reduces just-below-Curie heating
about 25%. This is useful attenuation, not free improvement in temperature
regulation. Its modeled cold/warm/hot MOSFET drain losses decrease from
3.79/6.03/0.71 W to 2.62/3.84/0.56 W. The corresponding all-time drain peaks
change from 85.8/93.1/119.7 V to 87.1/93.0/117.0 V. These peaks include startup;
protection clamp, avalanche, core saturation/loss and board parasitics are
omitted. Real drain waveforms take precedence.

Increasing L2 raises the series branch inductive reactance; at 470 kHz, a
0.31 uH increase adds approximately 0.92 ohm. That is significant in this
low-impedance branch. Increasing all inductors together is not equivalent.

## Procedure

1. Record the present capacitor configuration, frequency, supply voltage,
   gate/drain traces, tip temperature and amplifier temperature. Photograph
   the winding spacing so the original geometry can be restored. Use the same
   cartridge, cable, thermometer contact and airflow throughout.
2. With RF off and the supply disconnected/discharged, move a few L2 turns
   slightly closer and establish the direction and size of the inductance
   change on the LCR meter. Isolate a lead if needed to avoid measuring the
   surrounding network. Never attach the LCR meter to an energized board.
   Measure at the same frequency, fixture and temperature for comparisons.
3. Start electrical screening at 15 V, original carrier frequency, continuous
   RF (`power 100`). This avoids the load-dependent burst behavior observed
   in the earlier study. Keep the actual cartridge connected.
4. If making live fine adjustments, use a nonconductive plastic/nylon trimming
   tool and light pressure only. Do not use fingers, metal pliers or metal
   tweezers. These are RF nodes with voltages much higher than the DC input;
   enamel is not a touch-safe barrier. If a movement needs force, switch off
   and adjust it unpowered. Avoid scraping enamel, moving leads, or moving the
   whole core relative to its neighbors.
5. Monitor Q1 gate and drain together. After each tiny movement, withdraw the
   tool and observe switching first. The drain should return near zero before
   turn-on. Reject a change that produces markedly higher turn-on voltage,
   new spikes, unexpected input-current increase or rapid amplifier heating.
   Scope ground clips go to circuit GND, not an RF node. Use a properly rated
   probe and the fitted transistor's development voltage limit.
6. Start with approximately +0.1 to +0.15 uH from the measured L2 baseline.
   Then test roughly +0.2 and +0.3 uH if electrical results remain acceptable.
   For a 6.2 uH starting point this means about 6.3, 6.4 and 6.5 uH. These are
   trial points, not a prescribed optimum. Do not jump straight to +10%.
7. Qualify promising settings at increasing supply voltage toward 20 V,
   checking cold startup, warming through the transition, and hot operation.
   Wait for temperature to stabilize after each adjustment; continuous
   squeezing while watching a delayed thermometer makes overshoot likely.
   Record electrical changes immediately and thermal changes after settling.
8. Restore the original geometry and repeat a measurement, then repeat the
   candidate. A repeatable A/B result is more useful than one temperature dip.
   A jump associated only with tool/hand proximity can be RF interference or
   temporary loading, not a permanent improvement.
9. Once a candidate passes continuous operation, test Eco separately, including
   burst edges. Check heating recovery on the same repeatable soldering load.
   Accept only if idle temperature, recovery and amplifier stress are all
   suitable. More inductance can simply make the entire iron weaker.

Without a gate/drain scope measurement, use unpowered adjustments and reduced
voltage screening. Temperature alone is insufficient to qualify a live 20 V
retune. There is no guaranteed safe inductance interval established here.

Leave L1 alone: it is the supply choke, not one of the hand-wound matching
inductors. Keep L3, L4, L5, carrier frequency and capacitors fixed during the
first L2 series. If L2 does not give a repeatable useful trend within a few
small steps, restore baseline and investigate the actual load/waveforms rather
than continuing to compress turns.

| Trial | Measured L2 | Input V | Tip temperature | Drain at turn-on / peak | Input current | Amplifier temperature | Recovery |
| --- | --- | --- | --- | --- | --- | --- | --- |
| Baseline | | | | | | | |
| Small increase | | | | | | | |
| Restored baseline | | | | | | | |

## Reproduction

Run `python doc/design-study/sim-470khz/overtemperature/inductor_sweep.py`.
The script retains its netlist, case list, log and CSV in the same directory.
The original-capacitor run comprises 51 cases: baseline and -5%, +2%, +5%,
+10% for each of L2-L5, with three fixed load states. Final powers average
40 cycles after a 400-cycle run at a maximum timestep of 10 ns. Adjacent
steady windows differed by less than 0.02% in tip power.

The optional `--without-c11` regenerates the study for C11 removed; that variant
has not been run as part of this original-capacitor screening. See also
[`lite-overtemperature-tuning.md`](lite-overtemperature-tuning.md) and
[`lite-proposed-tuning-test-plan.md`](lite-proposed-tuning-test-plan.md).

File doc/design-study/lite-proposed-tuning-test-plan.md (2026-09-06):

# Hot-Wand Lite Proposed Tuning Test Plan

## Purpose

This plan uses only a synchronized four-channel oscilloscope to:

1. make a simple pass/fail decision on the 470 kHz power stage; and
2. try to improve its performance by adding capacitors in parallel with the
   existing capacitor banks.

The main load is a cold K-family cartridge. A second test is made after the
cartridge becomes hot. Cold is expected to be the more stressful load, but that
is an assumption until both states have been measured: a temperature-dependent
impedance change can make the hot state worse for zero-voltage switching even
when its current is lower.

This is a proposed development procedure, not a production certification. It
does not replace the voltage, current, pulse-energy, safe-operating-area, and
thermal limits in the data sheets for the parts actually fitted.

The calculations and nominal network behavior are described in
[`impedance-matching-470kHz.md`](impedance-matching-470kHz.md).

## Relevant Schematic Nets

The renamed nets in `electrical/hot-wand-lite.sch` make the RF chain:

```text
Q1 drain / MOSFET-DRAIN
  -> C2..C5 -> M1 -> L2 -> M2 -> L3 -> M3
  -> L4 -> M4 -> C10..C11 -> RF-OUT -> cartridge
  -> RF-RETURN -> SJ2||SJ3||SJ4||SJ5 -> GND

Q1 source -> MOSFET-SOURCE -> SJ1 -> GND
```

C6 through C8 shunt `M2` to ground, C9 shunts `M3` to ground, and L5
shunts `M4` to ground. All four output-return jumpers are connected across the
same two nodes; they are one four-resistor shunt bank, not four independent
sense points.

## Equipment and Preconditions

- A four-channel oscilloscope with waveform math, saved references, and CSV
  export if possible.
- One probe suitable for the full Q1 drain transient voltage. A normal low-
  voltage 10x probe is not automatically suitable.
- Three other compensated probes. A low-noise 1x probe may be useful on the
  two shunts if its bandwidth and capacitance are acceptable.
- Short probe ground springs. Do not use long alligator ground leads around the
  RF stage.
- A current-limited DC source is strongly preferred. Start at the lowest input
  voltage at which the 12 V gate-driver rail regulates correctly.
- The K-family cartridge and the exact handpiece/cable that will be used in
  service.
- D3/D4 and all other intended protection components fitted before testing.
- The actual Q1 part number and its data sheet recorded in the test log. The
  project shopping list suggests IRF640NPBF, but the schematic intentionally
  calls Q1 only `NCHAN` and permits alternatives.

Never defeat the oscilloscope protective-earth connection. All ground clips
from both oscilloscopes are normally common through protective earth. Connect
every ground clip only to circuit `GND`. In particular:

- do not ground `MOSFET-SOURCE`, because that bypasses SJ1;
- do not ground `RF-RETURN`, because that bypasses SJ2 through SJ5;
- do not ground `RF-OUT`, `M1` through `M4`, `MOSFET-DRAIN`, or Q1's heatsink;
  and
- confirm that grounding circuit `GND` does not short a non-isolated power
  source or another connected instrument.

Always connect the cartridge before enabling RF. Never use an open output as a
tuning test. Power down and discharge the board before moving probes or adding
a capacitor.

## Measurement Resistors

### SJ1: Q1 source-current shunt

Populate SJ1 with a low-inductance `0.010 ohm`, 1% current-sense resistor as a
starting value:

```text
IQ1_source = V(MOSFET-SOURCE) / 0.010 ohm
           = 100 A/V * V(MOSFET-SOURCE)

10 mV = 1 A
50 mV = 5 A
```

Use a pulse-rated part whose power rating is adequate for the planned burst:

```text
PSJ1 = IQ1_source_rms^2 * 0.010 ohm
```

SJ1 measures MOSFET source current, which includes drain current plus gate and
parasitic displacement currents. It is a useful switching-stress measurement,
but it is not the same as the 470 kHz load current. Its resistance and
inductance also alter Q1's effective gate-to-source drive, so SJ1 should be
shorted again after development unless it is intentionally part of the final
design.

### SJ2 through SJ5: cartridge-current shunt

Populate SJ2, SJ3, SJ4, and SJ5 with four equal low-inductance `1.00 ohm`, 1%
resistors. In parallel they give:

```text
RRF_shunt = 1.00 ohm / 4 = 0.250 ohm
Icartridge = V(RF-RETURN) / 0.250 ohm
           = 4 A/V * V(RF-RETURN)

250 mV = 1 A
500 mV = 2 A
```

For matched resistors, each resistor dissipates:

```text
Peach = Icartridge_rms^2 / 16
```

At `2 A RMS`, each 1 ohm resistor dissipates `0.25 W`. Use parts with adequate
continuous and pulse ratings, and stop before exceeding either their rating or
the board's thermal capability. Do not fit a zero-ohm link on any one of these
four footprints; one link bypasses the entire measurement bank.

Measure the actual installed shunt resistances if suitable low-resistance test
equipment is available. Otherwise, use the nominal values for approximate
current and treat scope-derived power as comparative rather than calibrated.

## Oscilloscope Preparation

1. Compensate all probes.
2. Set the attenuation and voltage rating correctly in the scope for every
   channel.
3. Connect the probes to the same low-voltage square wave and deskew them. At
   470 kHz, one degree is only about `5.91 ns`.
4. Use at least `100 MS/s` when available. Capture several complete carrier
   cycles away from the beginning or end of a power-control burst.
5. Use full bandwidth for drain overshoot and switching-edge checks. A 20 MHz
   bandwidth limit or high-resolution acquisition can be used separately for
   fundamental phase and shunt-amplitude measurements.
6. Trigger on the rising edge of `FET-GATE` and save the baseline setup and
   waveform as a scope reference.

Do not combine timing or phase measurements from the separate two-channel
scope with the four-channel scope. The second scope may monitor slow or
independent signals such as the input rail and 12 V gate-driver rail, but its
waveforms are not synchronized closely enough for RF phase or switching-loss
calculations.

## Four-Channel Probe Configurations

Two acquisitions are used because the synchronized scope has four channels.
Do not move probes while the board is powered.

### Configuration A: switching safety

| Channel | Probe tip | Derived quantity |
| --- | --- | --- |
| CH1 | `FET-GATE` | Gate voltage relative to ground |
| CH2 | `MOSFET-SOURCE` | `IQ1_source = CH2 / RSJ1` |
| CH3 | `MOSFET-DRAIN` | Drain voltage relative to ground |
| CH4 | `RF-RETURN` | `Icartridge = CH4 / RRF_shunt` |

Use scope math or exported samples:

```text
VGS = CH1 - CH2
VDS = CH3 - CH2
IQ1_source = CH2 / 0.010
Icartridge = CH4 / 0.250
```

This configuration establishes Q1 gate margin, turn-on drain voltage, drain
peak, Q1 current, and output current on the same timebase.

### Configuration B: load and delivered power

| Channel | Probe tip | Purpose |
| --- | --- | --- |
| CH1 | `FET-GATE` | Trigger and switching reference |
| CH2 | `MOSFET-DRAIN` | Drain peak and approximate ZVS check |
| CH3 | `RF-OUT` | Output voltage relative to ground |
| CH4 | `RF-RETURN` | Output-current shunt voltage |

Calculate:

```text
Vcartridge = CH3 - CH4
Icartridge = CH4 / 0.250
Pcartridge = mean(Vcartridge * Icartridge)
```

`CH3 - CH4` is essential: CH3 alone includes the voltage across the return
shunt. If the scope cannot subtract, multiply, and average simultaneously,
save all four channels to CSV and perform the arithmetic afterward.

For the fundamental impedance:

```text
|Zcartridge| = Vcartridge_rms / Icartridge_rms
theta = phase(Vcartridge) - phase(Icartridge)
Rcartridge = |Zcartridge| * cos(theta)
Xcartridge = |Zcartridge| * sin(theta)
```

Positive `theta` means current lags and the load is inductive. Negative `theta`
means current leads and the load is capacitive. Use a fundamental sinusoidal
fit or FFT phase, not the switching edges.

Changing an upstream capacitor does not force this cartridge phase toward
zero. The output phase identifies the cartridge/cable impedance; Q1's drain
waveform and delivered power determine whether the amplifier is well tuned.

# Test Plan 1: Simple Pass/Fail

## Pass/fail limits to record before power-up

Fill in these limits from the fitted parts and probes:

| Limit | Test value |
| --- | ---: |
| Fitted Q1 | __________ |
| Q1 absolute `VDS` rating | __________ V |
| Test `VDS` stop limit: no more than 80% of Q1 rating | __________ V |
| Drain probe peak rating | __________ V |
| Lower of Q1 and probe stop limits | __________ V |
| Q1 absolute `VGS` rating | __________ V |
| SJ1 RMS/pulse power limit | __________ W |
| Each SJ2-SJ5 RMS/pulse power limit | __________ W |
| Selected DC input-current limit | __________ A |

For an IRF640NPBF, the manufacturer specifies a `200 V` drain-to-source
breakdown rating and an absolute `+/-20 V` gate-to-source limit. This plan uses
`160 V` and `+/-15 V` as conservative development stop limits for that part.
Use different limits if a different Q1 is fitted. D4 is an SM15T150CA TVS with
a `128 V` maximum stand-off rating; repeated flat-topping or visible TVS
conduction is a failed tuning condition, not normal operation.

## Immediate stop conditions

Turn RF off immediately if any of the following occurs:

- the DC source enters current limit unexpectedly;
- `VDS` reaches the recorded stop limit or the drain probe rating;
- `VGS` exceeds the recorded limit, shows sustained negative drive, or does
  not return close to zero while Q1 should be off;
- the drain waveform clips repeatedly against the TVS or shows increasing
  cycle-to-cycle ringing;
- Q1 current exceeds the chosen device/SOA or SJ1 pulse limit;
- either shunt exceeds its calculated pulse or RMS power limit;
- waveforms drift rapidly at unchanged settings; or
- there is arcing, odor, smoke, unexpected sound, or abnormal heating.

## Cold-cartridge procedure

1. Let the K-family cartridge, handpiece, board, inductors, and Q1 return to
   room temperature. Record the cartridge and cable identifiers.
2. Connect the cartridge before power. Select the lowest firmware power setting
   that still provides clean groups of 470 kHz cycles.
3. Use Configuration A. Set a low DC current limit and begin at the lowest
   input voltage that gives a regulated gate-driver rail.
4. Capture the first stable carrier cycles inside a short burst. Ignore the
   start/stop transient only for phase and RMS calculations; its peak voltage
   must still remain below the stop limit.
5. Increase input voltage or power one small step at a time. At every step,
   save `VGS`, `VDS`, Q1 source current, and cartridge current.
6. Stop at the intended normal operating point, nominally 20 V for this
   project. Do not proceed to 24 V or 28 V until 20 V passes with margin.
7. Power down, discharge the board, and change to Configuration B. Repeat the
   same operating points and record output impedance and real power.
8. Repeat each important capture three times. A marginal result that changes
   materially between nominally identical cold starts is a failure.

## Cold pass criteria

The cold test passes only if all of the following are true at the intended
operating point:

| Item | Pass criterion |
| --- | --- |
| Carrier | Stable `470 kHz`, within `+/-1%` (`465.3` to `474.7 kHz`) |
| `VGS` high | Approximately 10 to 13.5 V for the 12 V driver, measured gate-to-source |
| `VGS` low | Returns within about -1 to +1 V with no unintended turn-on |
| `VGS` excursions | Remain inside the recorded conservative limit; `+/-15 V` for IRF640NPBF |
| Q1 turn-on | `VDS` is at its valley and no more than `max(5 V, 10% of VDS_peak)` when `VGS` crosses its rising threshold |
| Drain slope at turn-on | Near its minimum; no large positive-slope hard-switching edge |
| Drain peak | Below the recorded stop limit; `160 V` for IRF640NPBF, and below the probe rating |
| Drain clamp | No repeated flat-topping or obvious TVS/avalanche operation |
| Q1 and load current | Stable, repeatable, and below device, shunt, supply, and connector limits |
| Output real power | Positive, repeatable, and sufficient to begin heating the cartridge |
| Burst boundaries | No single start/stop transient violates any voltage or current limit |

The `5 V or 10%` turn-on criterion is a practical screening threshold, not a
claim of mathematically perfect class-E operation. A waveform that clearly
turns Q1 on while substantial drain voltage remains is a fail even if the
average current looks acceptable.

## Hot-cartridge procedure and pass criteria

1. Begin only after the cold test passes.
2. Keep the same handpiece, probes, input voltage, firmware setting, and scope
   timing.
3. Run long enough for the cartridge impedance and waveforms to stabilize at
   its hot operating state. Do not use the startup transient for the hot
   measurement.
4. Capture Configuration A, then power down and repeat the stabilized test with
   Configuration B.
5. Apply every cold pass criterion to the hot captures as well.
6. Compare cold and hot `VDS_peak`, turn-on `VDS`, Q1 peak/RMS current,
   cartridge impedance, and delivered power. A large unexplained drift or an
   improving output accompanied by worse switching stress is a fail.

## Simple verdict

- **PASS:** both cold and hot tests satisfy every criterion through the normal
  20 V operating point with repeatable margin.
- **CONDITIONAL PASS:** 20 V passes, but a higher optional input mode does not.
  Disable or document the higher mode.
- **FAIL:** any immediate stop condition occurs, either temperature state fails
  ZVS/stress limits, or the result is not repeatable.

# Test Plan 2: Capacitor-Addition-Only Tuning

## Scope of permitted changes

Do not remove or reduce any existing production capacitor. Trial capacitors are
temporarily placed in parallel with a bank; an unsuccessful trial must be
removed before the next trial. Only a capacitor addition that passes both cold
and hot tests becomes permanent.

Use C0G/NP0 or another RF-appropriate low-loss dielectric, with voltage,
ripple-current, package, and temperature ratings at least as good as the
existing parts. Keep leads and tack connections extremely short. Power down and
discharge before every change.

Do not tune by attempting to make cartridge voltage and current exactly in
phase. At a fixed frequency their phase is principally a property of the
cartridge and cable. Use these synchronized figures of merit instead:

1. lower Q1 `VDS` at turn-on;
2. lower worst-case `VDS_peak` without repeated TVS conduction;
3. lower Q1 switching-overlap energy;
4. lower Q1 RMS/peak current for the same delivered power; and
5. greater delivered real cartridge power without worsening items 1 through 4.

An oscilloscope-derived switching-loss proxy can be calculated from
Configuration A:

```text
VDS = CH3 - CH2
IQ1_source = CH2 / RSJ1
Eswitch_proxy = integral_over_one_cycle(max(VDS * IQ1_source, 0))
Pswitch_proxy = Eswitch_proxy * 470000
```

This is comparative, not a calibrated semiconductor-loss measurement. Source
current contains displacement currents, probe delay creates multiplication
error, and the shunt/probes perturb the circuit. Use the same deskew, probes,
scales, sample rate, and integration window for every candidate.

## Bank order and trial increments

Change only one bank at a time. Test each value relative to the current best
configuration, not cumulatively without intermediate measurements.

| Order | Bank | Existing total | Suggested independent additions | Reason |
| ---: | --- | ---: | --- | --- |
| 1 | C10 + C11 | 7.8 nF series bank | 100 pF, 220 pF, 470 pF, 1 nF | Direct output-match variable; most appropriate first adjustment for a measured cold cartridge |
| 2 | C6 + C7 + C8 | 30 nF shunt bank at `M2` | 220 pF, 470 pF, 1 nF, 2.2 nF | Adjusts the transformation presented toward the class-E drain |
| 3 | C2 + C3 + C4 + C5 | 81 nF series bank | 1 nF, 2.2 nF, 4.7 nF | Small drain-side reactive trim because the existing bank is only about `-j4.18 ohms` at 470 kHz |
| 4 | C9 | 6.8 nF shunt bank at `M3` | 22 pF, 47 pF, 100 pF maximum initial trials | Last resort only; C9 with L3/L4 sets the approximately 469.5 kHz immittance converter |

Do not start with C9. Large additions there move the deliberately tuned
L3-C9-L4 inverter away from the carrier and make the behavior of the other
banks harder to interpret.

The additions in the table are exploration values, not guaranteed answers.
If the smallest practical addition causes an immediate stress increase, stop
testing that direction at that bank. The correct mathematical solution may
require less capacitance; that solution is outside this add-only plan.

## Establish the baseline

1. Complete Test Plan 1 with no added tuning capacitors.
2. Choose a repeatable cold starting condition and a fixed point inside the RF
   burst for measurements.
3. Save three Configuration A and three Configuration B acquisitions at the
   selected reduced-power tuning point and at normal 20 V operation.
4. Record the mean and spread of:
   - Q1 turn-on `VDS`;
   - `VDS_peak`;
   - Q1 source peak and RMS current;
   - cartridge peak and RMS current;
   - `Pcartridge`;
   - cartridge phase and complex impedance; and
   - `Pswitch_proxy` if it can be calculated reliably.
5. Repeat at the stabilized hot state. Define the worse cold/hot result for
   each stress metric as the baseline to beat.

## Candidate test loop

For each temporary capacitor addition:

1. Power down and discharge the board.
2. Add one trial capacitor to the selected bank with the shortest possible
   connection. Record its measured or marked value and location.
3. Return the cartridge to the defined cold condition.
4. Repeat Configuration A first at the reduced-power tuning point. Reject the
   candidate immediately if any pass criterion worsens into a failure or any
   stop condition occurs.
5. If safe, repeat Configuration A at 20 V, followed by Configuration B at the
   same operating point. Capture three repetitions.
6. Heat the cartridge to its stable hot state and repeat both configurations.
7. Compare the candidate with the baseline using the acceptance rules below.
8. Keep the best passing addition as the new baseline, or remove the failed
   trial and restore the previous best configuration.
9. Test the next value or bank only after the previous state has been clearly
   recorded and restored.

## Candidate acceptance rules

A capacitor addition is accepted only if:

- every pass/fail criterion remains satisfied in both cold and hot states;
- no stress metric worsens by more than the larger of 5% or the measured
  three-run repeatability band; and
- it produces at least one meaningful improvement:
  - at least 10% lower Q1 turn-on `VDS` or switching-loss proxy while delivered
    power stays within 5% of baseline; or
  - at least 5% greater delivered real power while Q1 turn-on voltage, drain
    peak, Q1 current, and switching-loss proxy do not materially worsen.

When metrics conflict, prefer lower Q1 turn-on voltage and lower worst-case
drain peak over a small increase in output power. Reject an improvement that
exists only when hot but worsens the cold start, or vice versa.

Stop the add-only program when:

- all four banks have been tried without an accepted improvement;
- the next addition would exceed a component or probe rating;
- an accepted configuration has repeatable margin in both cold and hot tests;
  or
- the trend indicates that less capacitance is required.

In the last case, document **no add-only solution**. Do not force an addition
merely because removing/replacing an existing capacitor is outside the allowed
scope.

## Test Record

Use one row per baseline or capacitor trial and attach the saved scope files.

| Run | State | Added bank/value | Input V | `VDS` at turn-on | `VDS` peak | Q1 I peak/RMS | Load I RMS | Load phase | Load real power | Loss proxy | Verdict |
| --- | --- | --- | ---: | ---: | ---: | --- | ---: | ---: | ---: | ---: | --- |
| B0 | Cold | None | | | | | | | | | |
| B0 | Hot | None | | | | | | | | | |
| | Cold | | | | | | | | | | |
| | Hot | | | | | | | | | | |

Record rejected trials as well as accepted ones. A negative result establishes
which tuning direction should not be repeated and is especially important when
the permitted adjustment is addition-only.

## Data-Sheet References

- [Infineon IRF640N data sheet](https://www.infineon.com/assets/row/public/documents/24/49/infineon-irf640n-datasheet-en.pdf)
- [STMicroelectronics SM15T150CA product page](https://www.st.com/en/protections-and-emi-filters/sm15t150ca.html)

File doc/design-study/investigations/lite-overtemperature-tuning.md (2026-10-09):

# Lite 470 kHz overtemperature investigation

Study date: 2026-09-22. Results are candidate bench modifications, not validated
temperature settings or a guaranteed safe operating envelope.

## Recommended first experiment

**Remove C11 (1 nF), leave C10 (6.8 nF) fitted, and keep the carrier at its
original approximately 470 kHz.** C10 and C11 are parallel between `M4` and
`RF-OUT`. This reduces the output coupling bank from 7.8 nF to 6.8 nF without
cutting a trace or inserting a component into the output cable.

At 20 V, the inherited above-Curie load model receives about 40% less heating
power, while the just-below-Curie model retains about 77% of its original power.
That is a better tradeoff than the useful parallel-only changes examined here.
The hot-state power is close to the original network at 15 V, which is the
user's known working temperature condition. This is an electrical comparison;
it does not predict that the modified hardware will idle at 376 C.

If full removal reduces heating more than desired, fit 220 pF or 470 pF at C11
instead. Use C0G/NP0 with the original voltage rating or higher and suitable RF
current capability. Keep the existing C10. Do not increase C10/C11 to cure this
problem: increasing this bank increased above-Curie heating in the model.

## Reported hardware behavior

- K75C002 cartridge, intended 75 temperature series.
- Approximately 470 C at 20 V; inline USB-C meter indicates roughly 30 W input.
- Approximately 376 C at 15 V.
- Approximately 470 C in Eco at 20 V, described as 60% burst operation.
- Temperature measured with a dedicated tip thermometer using a disposable
  three-arm contact sensor. Reliable Eco input wattage is unavailable.
- Fitted MOSFET and actual cold/warm/hot K75C002 impedances are unconfirmed.

The manufacturer's [K75C002 datasheet](https://www.thermaltronics.com/downloads/datasheets/K75C002_Technical_Datasheet.pdf)
specifies 350-398 C. That range covers geometry and measurement differences;
398 C is not an exact setpoint for every cartridge geometry. The Curie change
does not eliminate every real electrical loss or create a hard temperature
ceiling. Equilibrium still depends on delivered power and heat loss.

As a diagnostic, keep the tip on the thermometer and briefly disable RF. An
abrupt reading step, distinct from normal cooling, would suggest RF-dependent
measurement error or sensor heating. This is a check, not a conclusion that
the reported temperature is wrong.

## Simulation and its limits

The study uses LTspice 26.0.2 and the component values and connectivity in
`electrical/hot-wand-lite.sch`:

```text
Q1 drain -- C2..C5 (81 nF) -- L2 (6.2 uH) -- M2
M2 -- L3 (16.9 uH) -- M3 -- L4 (16.9 uH) -- M4
M2 -- C6..C8 (30 nF) -- GND
M3 -- C9 (6.8 nF) -- GND
M4 -- L5 (11.5 uH) -- GND
M4 -- C10 || C11 (6.8 nF || 1 nF) -- RF-OUT -- cable -- tip
Q1 drain -- C1 (15 nF) -- GND
Supply -- L1 (33 uH) -- Q1 drain
```

The load states come from the local `from_discord_sept5_2026.asc`, whose comments
identify an **STP-CN04**, not the user's K75C002:

| Model state | R | L |
| --- | ---: | ---: |
| Cold | 11.6 ohm | 5.5 uH |
| Just below Curie | 14.0 ohm | 7.2 uH |
| Above Curie | 1.54 ohm | 1.7 uH |

The active parameter table's 1.54 ohm value is retained. A separate 0.1 ohm
tip-inductor DCR and 0.5 ohm cable resistance are also retained. Reported tip
power means dissipation in `Rtip`; it excludes cable and modeled inductor DCR.

The drive is simplified to 12 V with 50 ns source edges, 50% midpoint duty, and
5 ohm source impedance. Each real split-driver path has one 3.6 ohm resistor;
5 ohm includes assumed driver impedance. The inherited FDP18N20F transistor
model is retained because the fitted transistor is unknown. Supply impedance
is 50 milliohm; bulk capacitance is 940 uF with assumed 50 milliohm ESR.
RF ESR/DCR values are inherited estimates, not measurements of this board.

**D3/D4 protection, MOSFET avalanche, magnetic-core loss/saturation, PCB/cable
parasitics, temperature-dependent transistor behavior, and thermal feedback
are not modeled.** Drain peaks are unclamped electrical-model results. Values
above the modeled device's rating describe an invalid hardware operating
condition, not a prediction that it survives. No numerical temperature can be
calculated from these three fixed load states.

The original model draws about 10.6 W in its above-Curie state at 20 V, unlike
the reported approximate 30 W. Thus it does not reproduce the user's hardware
quantitatively. Real cartridge impedance, fitted inductances, losses, waveform,
and metering remain important uncertainties. Use these results to choose a
reversible experiment, not to assert a certain temperature reduction.

Electrical sweep summary
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

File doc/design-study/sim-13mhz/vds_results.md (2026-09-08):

# 13.56 MHz RF amplifier: unclamped VDS results

Simulated on 2026-09-07 with LTspice 26.0.2 for Windows. Runnable schematic: [rf_amp.asc](rf_amp.asc). Full main-run measurement log: [rf_amp.log](rf_amp.log).

**Provisional model results:** Q1 is represented by a datasheet-based STP19NF20 approximation, with an assumed gate waveform. ST's official SPICE-model download timed out on repeated attempts. These numbers are useful for comparing the modeled conditions; they are not validated hardware voltage limits or a completed TVS selection.

The **D4/TVS1 drain-clamp branch is omitted**, as requested, to expose the unclamped voltage demand.

## Maximum VDS over the full transient

Each cell is the result of:

```spice
.meas TRAN V_DS MAX V(Vds)
```

The measurement covers **0 to 1 ms**, including LTspice's `startup` ramp of the independent sources over the first 20 us. The maximum timestep is 200 ps and waveform compression is disabled. VCC is the DC supply **at the RF stage / L3 input**, replacing the buck converter's output.

| Tip condition | Impedance at 13.56 MHz | VCC = 15 V | VCC = 20 V | VCC = 25 V | VCC = 30 V |
|---|---|---:|---:|---:|---:|
| Cold | 42.3 + j13 ohm | 70.2 V | 120.4 V | 169.7 V | 216.5 V |
| Warm (below Curie) | 55 - j16 ohm | 65.9 V | 84.8 V | 102.9 V | 121.0 V |
| Hot (above Curie) | 12 + j24 ohm | 149.4 V | 216.1 V | 287.0 V | 361.1 V |
| Open output | 1 Tohm (open approximation) | 418.3 V | 543.3 V | 682.5 V | 803.7 V |

The largest main-run result is **803.7 V with an open output at 30 V VCC**. All open-output results exceed the physical MOSFET's 200 V rating. The model has no avalanche or failure behavior: these are hypothetical unclamped voltages, not predictions that a real STP19NF20 survives or actually reaches them.
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

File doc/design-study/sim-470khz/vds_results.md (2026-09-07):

# Radio Thermal simulation: peak drain voltage

Source schematic: `from_discord_sept5_2026.asc`

LTspice 26.0.2 was used to evaluate the originally inactive directive:

```spice
.meas V_DS MAX(V(Vds))
```

The original transient analysis was retained:

```spice
.tran 0 1004.21u 1000u 5n startup
```
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

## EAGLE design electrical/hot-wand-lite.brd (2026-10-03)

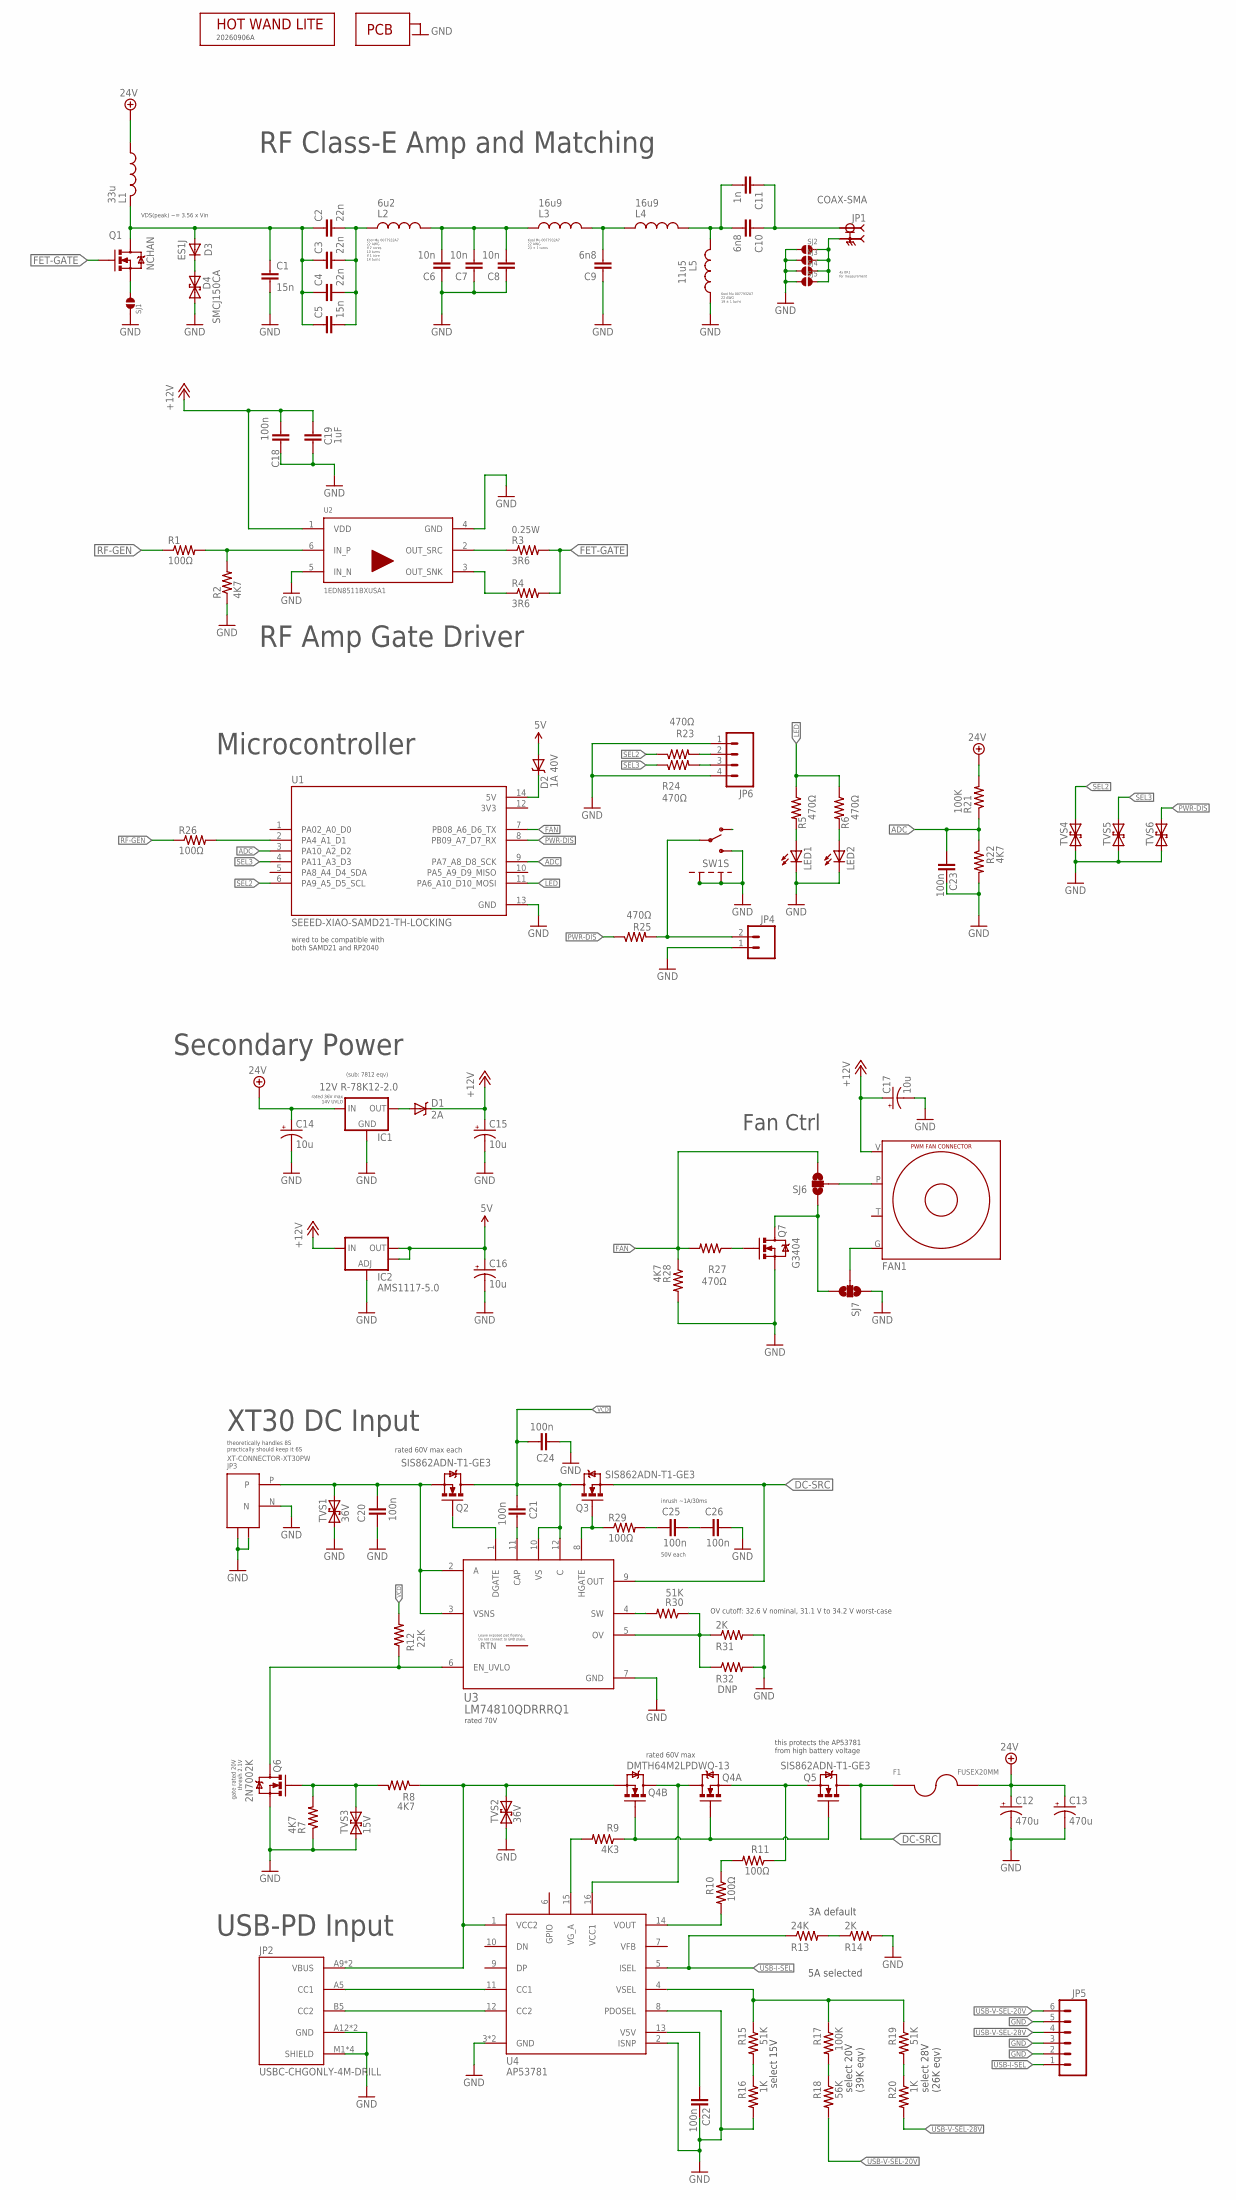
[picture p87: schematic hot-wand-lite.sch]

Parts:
C1, C5: 15n; 1206; PARTNUM C3216C0G2E153J160AA; JLCPARTNUM C3858208
C2, C3: 22n; 1206; JLCPARTNUM C3862155
C4: 22n; 1206; PARTNUM GCM31C5C2E223JX03L; JLCPARTNUM C3862155
C6: 10n; 1206; PARTNUM C3216C0G2E103J115AA; JLCPARTNUM C2261646;C2170837;C2175075
C7, C8: 10n; 1206; PARTNUM GRM31B5C2E103JWA1L; JLCPARTNUM C2261646
C9, C10: 6n8; 1206; PARTNUM C1206C682JCGACAUTO; JLCPARTNUM C2182121
C11: 1n; 1206; PARTNUM GCM31C5C3A102FX03L; JLCPARTNUM C3859218
C12, C13: 470u; CPOL-RADIAL-COMBO-10MM; PARTNUM UHW1H471MPD; JLC-DNP 1
C14, C17: 10u; EIA3216-KIT; PARTNUM MLASU31LBB5106KTNA01;GRT31CR61H106KE01K; JLCPARTNUM C13585
C15, C16: 10u; EIA3216-KIT; PARTNUM TAJA106K016TNJ;T491A106K016AT; JLCPARTNUM C13585
C18, C20, C21, C22, C23, C24, C25, C26: 100n; 0603-CAP; JLCPARTNUM C14663
C19: 1uF; 0603-CAP; JLCPARTNUM C15849
D1: 2A; SMA-DIODE; PARTNUM VSSAF5N50;SL36A; JLCPARTNUM C698873
D2: 1A 40V; SOD123FL; JLCPARTNUM C8598
D3: ES1J; SMA-DIODE; JLCPARTNUM C64879
D4: SMCJ150CA; SMC; JLCPARTNUM C2649864
F1: FUSEX20MM; FUSE_5MM; PARTNUM 3518P; JLC-DNP 1
FAN1: FAN-CONN-X4-CONN-X4; FAN-CONN-X4; PARTNUM 0470531000
IC1: 12V R-78K12-2.0; TO220-BUCK-12V; PARTNUM R-78K12-2.0; JLC-DNP 1
IC2: AMS1117-5.0; SOT223; PARTNUM AMS1117-5.0; JLCPARTNUM C6187
JP1: COAX-SMA; SAMTEC_SMA-J-P-H-ST-EM1-LGRPAD; PARTNUM SMA-J-P-H-ST-EM1; JLC-DNP 1
JP2: USBC-CHGONLY-4M-DRILL; SAMESKY_UJC-H-G-SMT-2-P6-TR-DRILL; PARTNUM UJC-H-G-SMT-P6-TR; JLC-DNP 1
JP3: XT-CONNECTOR-XT30PW; XT30PW; PARTNUM XT30PW-M; JLC-DNP 1
JP4: M02PTH3; 1X02_LONGPADS; JLC-DNP 1
JP5: M06LOCK; 1X06_LOCK
JP6: M04LOCK; 1X04_LOCK; JLC-DNP 1
L1: 33u; IND_SRP1265A; PARTNUM PA4343.333NLT;SRP1265A-330M;SRP1265CC-3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; JLCPARTNUM C2453886
L2: 6u2; IND-KOOLMU-2W; JLC-DNP 1
L3, L4: 16u9; IND-KOOLMU; JLC-DNP 1
L5: 11u5; IND-KOOLMU; JLC-DNP 1
LED1: LED; LED_LTST-S220KRKT; PARTNUM LTST-S220KRKT; JLCPARTNUM C284935
LED2: LED; LED-0603; JLC-DNP 1
PCB1: PCB-OUTLINE; JLC-DNP 1
PCB2: PCB-ART-VER-LITE; PCB-ART-VERSION-LITE; JLC-DNP 1
Q1: NCHAN; TO247-COMBO; JLC-DNP 1
Q2, Q3, Q5: SIS862ADN-T1-GE3; POWERPAK-1212-8; PARTNUM SIS862ADN-T1-GE3; JLC-DNP 1
Q4: DMTH64M2LPDWQ-13; POWERPAK-SO8-X2; PARTNUM DMTH64M2LPDWQ-13; JLC-DNP 1
Q6: 2N7002K; SOT23-3; PARTNUM 2N7002K;SSM3K388R,LF;Si2318CDS-T1-GE3;P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; JLCPARTNUM C14498;C547263;C5224211;C54347659
Q7: G3404; SOT23-3; PARTNUM G3404;MMFTN3404A;PJA3404A;Si2318CDS-T1-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; JLCPARTNUM C14498;C547263;C96615
R1, R10, R11, R26, R29: 100Ω; 0805; JLCPARTNUM C441975
R2, R7, R8, R22, R28: 4K7; 0603-RES; JLCPARTNUM C23162
R3, R4: 3R6; 0603-RES; JLCPARTNUM C445783
R5, R6, R23, R24, R25, R27: 470Ω; 0603-RES; JLCPARTNUM C23179
R9: 4K3; 0603-RES; JLCPARTNUM C23159
R12: 22K; 0603-RES; JLCPARTNUM C31850
R13: 24K; 0603-RES; JLCPARTNUM C23352
R14, R31: 2K; 0603-RES; JLCPARTNUM C22975
R15, R19, R30: 51K; 0603-RES; JLCPARTNUM C23196
R16, R20: 1K; 0603-RES; JLCPARTNUM C21190
R17, R21: 100K; 0603-RES; JLCPARTNUM C25803
R18: 56K; 0603-RES; JLCPARTNUM C23206
R32: DNP; 0603-RES
SJ1, SJ2, SJ3, SJ4, SJ5: SJ-SMALL-1206-SJ; 1206-SJ
SJ6, SJ7: SOLDERJUMPER_2WAYS; SJ_3
SW1: SWITCH-SPDT-2MNT-SLW-864574-5A-RA-N-D; SWITCH-SLW-864574-5A-RA-N-D; PARTNUM SLW-864574-5A-RA-N-D; JLC-DNP 1
TVS1, TVS2: 36V; SMA; PARTNUM SMAJ36CA; JLCPARTNUM C134984
TVS3: 15V; SOD-323; PARTNUM SD15C-01FTG;CDSOD323-T15SC;TSD15CDYFR; JLCPARTNUM C2987151
TVS4, TVS5, TVS6: TVSSOD323-R; SOD323-R; JLCPARTNUM C840638
U1: SEEED-XIAO-SAMD21-TH-LOCKING; MODULE_102010388_LOCKING; JLC-DNP 1
U2: 1EDN8511BXUSA1; SOT95P280X145-6N-7-V; JLCPARTNUM C3655509
U3: LM74810QDRRRQ1; DRR0012E-MFG; JLCPARTNUM C3215601
U4: AP53781; QFN3030-16; JLCPARTNUM C52730979

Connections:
3V3: U1.12 (3V3)
5V: C16.A (+), D2.A, IC2.2 (OUT), IC2.4 (OUT)
12V-2: D1.A, IC1.3 (OUT)
+12V: C15.A (+), C17.A (+), C18.2, C19.2, D1.C, FAN1.V, IC2.3 (IN), U2.1 (VDD)
+24V: C12.1 (+), C12.1B (+), C13.1 (+), C13.1B (+), C14.A (+), F1.3 (2), F1.4 (2), IC1.1 (IN), L1.1, R21.2
ADC: C23.2, R21.1, R22.1, U1.3 (PA10_A2_D2), U1.9 (PA7_A8_D8_SCK)
DC-SRC: F1.1, F1.2 (1), Q3.1 (S), Q3.2 (S), Q3.3 (S), Q5.5 (D), Q5.6 (D), Q5.7 (D), Q5.8 (D), Q5.9 (D), U3.9 (OUT)
FAN: R27.2, R28.1, SJ6.3, U1.7 (PB08_A6_D6_TX)
FET-GATE: Q1.1 (G), Q1.1B (G), R3.2, R4.2
GND: C1.2, C6.1, C7.1, C8.1, C9.1, C12.2 (-), C12.2B (-), C13.2 (-), C13.2B (-), C14.C (-), C15.C (-), C16.C (-), C17.C (-), C18.1, C19.1, C20.2, C22.1, C23.1, C24.2, C26.1, D4.A (1), IC1.2 (GND), IC2.1 (ADJ), JP2.A12 (GND), JP2.B12 (GND), JP2.M1 (SHIELD), JP2.M2 (SHIELD), JP2.M3 (SHIELD), JP2.M4 (SHIELD), JP3.M1, JP3.M2, JP3.N, JP4.1, JP5.2, JP5.3, JP5.5, JP6.1, JP6.4, L5.1, LED1.C, LED2.C, PCB1.1, PCB1.2, PCB1.3, PCB1.4, Q6.2 (S), Q7.2 (S), R2.1, R7.1, R14.2, R16.2, R22.2, R28.2, R31.2, R32.2, SJ1.1, SJ2.2, SJ3.2, SJ4.2, SJ5.2, SJ7.1, SW1.M1 (MNT1), SW1.M2 (MNT2), SW1.R (S), TVS1.A (1), TVS2.A (1), TVS3.2 (1), TVS4.A (1), TVS5.A (1), TVS6.A (1), U1.13 (GND), U2.4 (GND), U2.5 (IN_N), U3.7 (GND), U4.2 (ISNP), U4.3 (GND), U4.8 (PDOSEL), U4.EXP (GND)
LED: R5.1, R6.1, U1.11 (PA6_A10_D10_MOSI)
M1: C2.2, C3.2, C4.2, C5.2, L2.1A (1), L2.1B (1), L2.1C (1), L2.1D (1)
M2: C6.2, C7.2, C8.2, L2.2A (2), L2.2B (2), L2.2C (2), L2.2D (2), L3.1
M3: C9.2, L3.2, L4.1
M4: C10.2, C11.2, L4.2, L5.2
MCU-RF: R1.2, R2.2, U2.6 (IN_P)
MOSFET-DRAIN: C1.1, C2.1, C3.1, C4.1, C5.1, D3.A, L1.2, Q1.2 (D)
MOSFET-SOURCE: Q1.3 (S), Q1.3B (S), SJ1.2
unnamed: R17.2, R18.1
unnamed: LED2.A, R6.2
unnamed: R15.2, R16.1
unnamed: R13.2, R14.1
unnamed: R19.2, R20.1
unnamed: R3.1, U2.2 (OUT_SRC)
unnamed: R4.1, U2.3 (OUT_SNK)
unnamed: Q4.1 (S), Q5.1 (S), Q5.2 (S), Q5.3 (S), R11.1
unnamed: JP6.2, R23.2
unnamed: JP6.3, R24.2
unnamed: Q7.1 (G), R27.1
unnamed: FAN1.P, SJ6.2
unnamed: JP4.2, R25.2, SW1.C
unnamed: Q7.3 (D), SJ6.1, SJ7.3
unnamed: D2.C, U1.14 (5V)
unnamed: FAN1.G, SJ7.2
unnamed: D3.C, D4.C (2)
unnamed: C25.1, C26.2
unnamed: Q6.1 (G), R7.2, R8.2, TVS3.1 (2)
unnamed: Q4.5 (D), Q4.6 (D), Q4.7 (D), Q4.8 (D), Q4.9 (D), Q4.10 (D), U4.16 (VCC1)
unnamed: C22.2, U4.13 (V5V)
unnamed: R10.2, U4.14 (VOUT)
unnamed: C25.2, R29.2
unnamed: LED1.A, R5.2
unnamed: R10.1, R11.2
unnamed: R30.2, U3.4 (SW)
unnamed: C21.1, U3.11 (CAP)
PWR-DIS: R25.1, TVS6.C (2), U1.8 (PB09_A7_D7_RX)
RF-GEN: R1.1, R26.1
RF-GEN-PRE: R26.2, U1.2 (PA4_A1_D1)
RF-OUT: C10.1, C11.1, JP1.1
RF-RETURN: JP1.2_1 (2), JP1.2_2 (2), JP1.3_1 (2), JP1.3_2 (2), SJ2.1, SJ3.1, SJ4.1, SJ5.1
SEL2: R23.1, TVS4.C (2), U1.6 (PA9_A5_D5_SCL)
SEL3: R24.1, TVS5.C (2), U1.4 (PA11_A3_D3)
U3-DGATE: Q2.4 (G), U3.1 (DGATE)
U3-EN: Q6.3 (D), R12.1, U3.6 (EN_UVLO)
U3-HGATE: Q3.4 (G), R29.1, U3.8 (HGATE)
U3-OV: R30.1, R31.1, R32.1, U3.5 (OV)
U4-VGA: R9.2, U4.15 (VG_A)
U4-VGA-2: Q4.2 (G), Q4.4 (G), Q5.4 (G), R9.1
U4-VSEL: R15.1, R17.1, R19.1, U4.4 (VSEL)
USB-CC1: JP2.A5 (CC1), U4.11 (CC1)
USB-CC2: JP2.B5 (CC2), U4.12 (CC2)
USB-I-SEL: JP5.1, R13.1, U4.5 (ISEL)
USB-V-SEL-20V: JP5.6, R18.2
USB-V-SEL-28V: JP5.4, R20.2
USB-VBUS: JP2.A9 (VBUS), JP2.B9 (VBUS), Q4.3 (S), R8.1, TVS2.C (2), U4.1 (VCC2)
VCD: C21.2, C24.1, Q2.5 (D), Q2.6 (D), Q2.7 (D), Q2.8 (D), Q2.9 (D), Q3.5 (D), Q3.6 (D), Q3.7 (D), Q3.8 (D), Q3.9 (D), R12.2, U3.10 (VS), U3.12 (C)
VIN-XT30: C20.1, JP3.P, Q2.1 (S), Q2.2 (S), Q2.3 (S), TVS1.C (2), U3.2 (A), U3.3 (VSNS)

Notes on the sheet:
RF Amp Gate Driver
Secondary Power
select 15V
USB-PD Input
gate rated 20V thresh 2.1V
Microcontroller
rated 36V max 14V UVLO
select 20V (39K eqv)
RF Class-E Amp and Matching
wired to be compatible with both SAMD21 and RP2040
(sub: 7812 eqv)
Kool Mu 0077932A7 22 AWG if 2 cores 10 turns if 1 core 14 turns
Kool Mu 0077932A7 22 AWG 23 ± 1 turns
Kool Mu 0077932A7 22 AWG 19 ± 1 turns
3A default
5A selected
4x 0R1 for measurement
select 28V (26K eqv)
0.25W
theoretically handles 8S practically should keep it 6S
XT30 DC Input
rated 60V max each
rated 70V
rated 60V max
50V each
inrush ~1A/30ms
OV cutoff: 32.6 V nominal, 31.1 V to 34.2 V worst-case
this protects the AP53781 from high battery voltage
VDS(peak) ~= 3.56 x Vin
Fan Ctrl

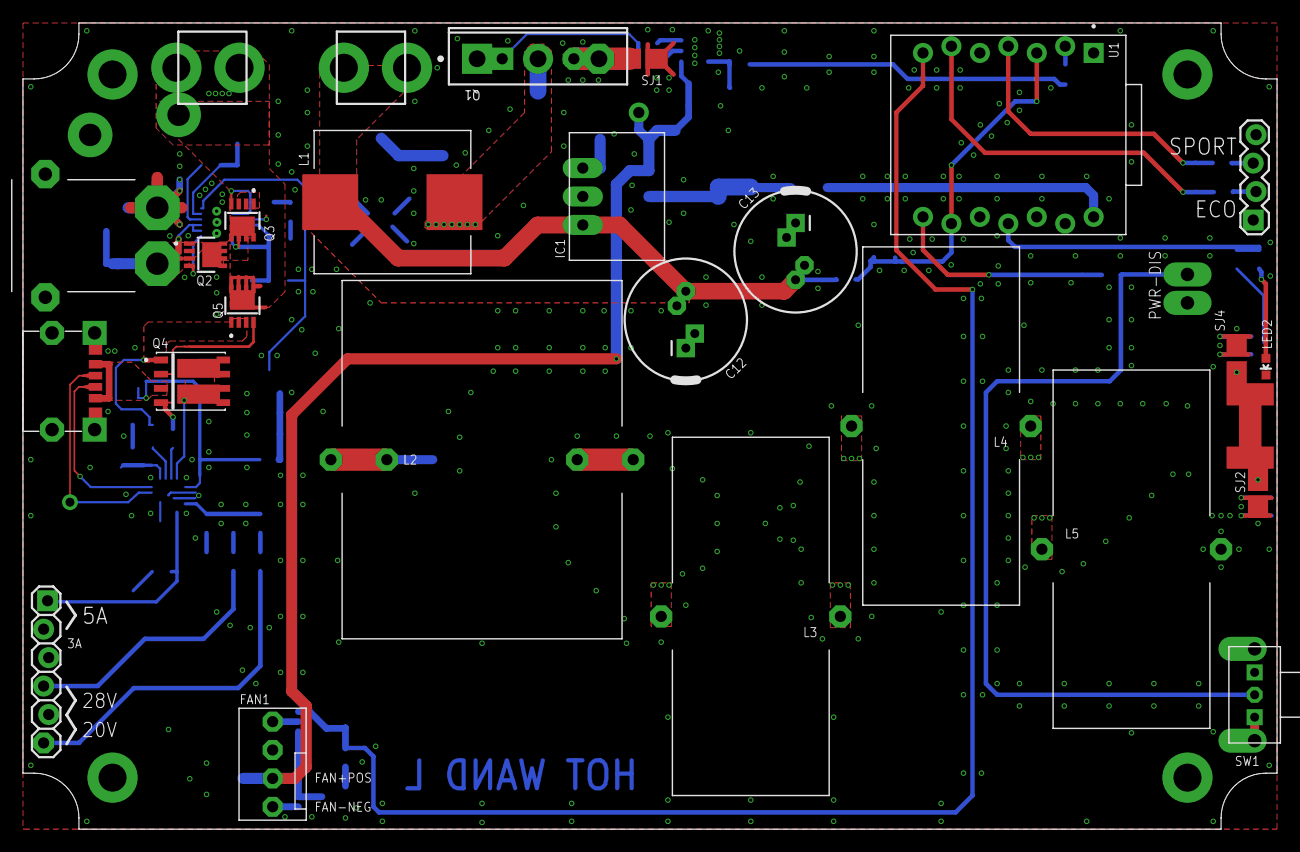
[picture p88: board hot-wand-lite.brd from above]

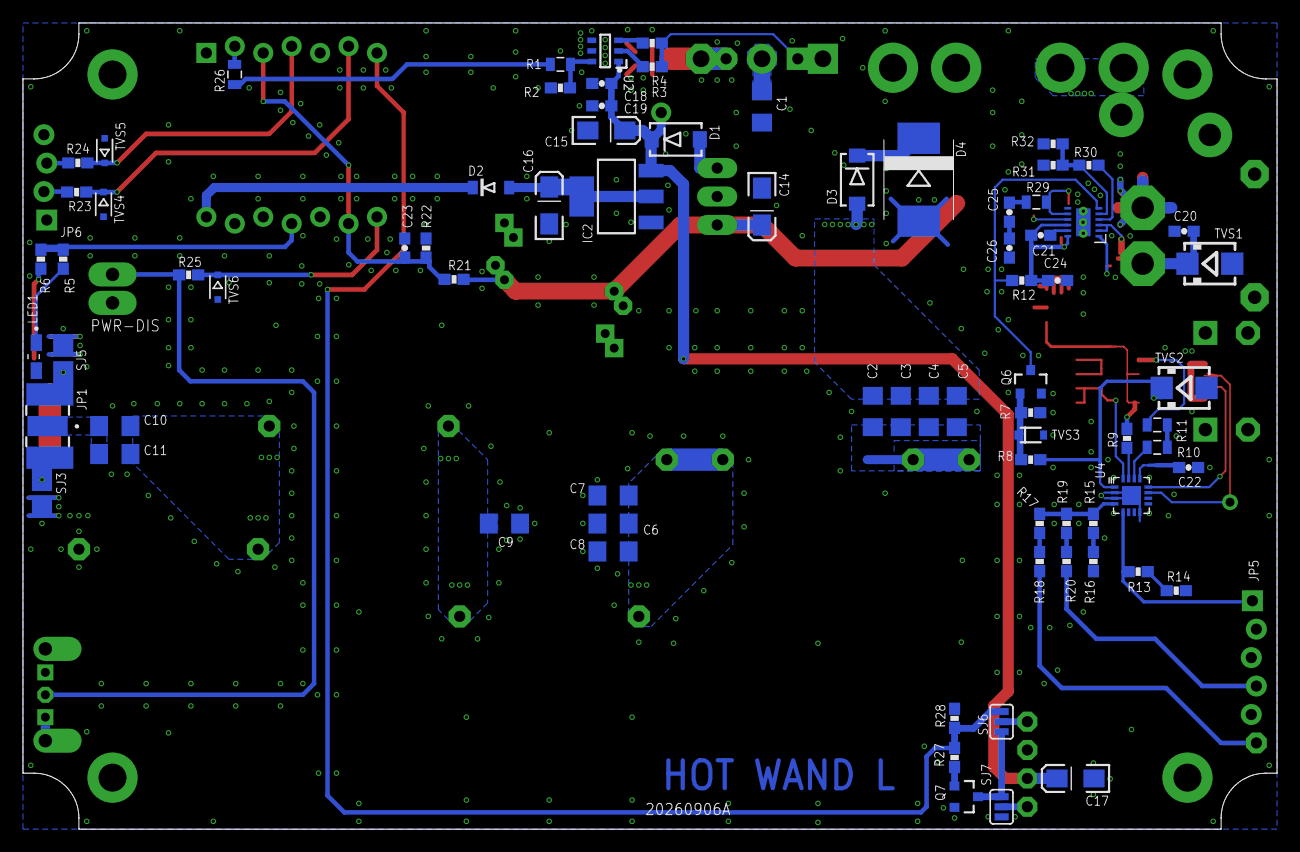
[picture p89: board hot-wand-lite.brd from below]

Board: 2 copper layers, 112.0 x 72.0 mm, 106 parts (79 on the bottom side), 66 nets.

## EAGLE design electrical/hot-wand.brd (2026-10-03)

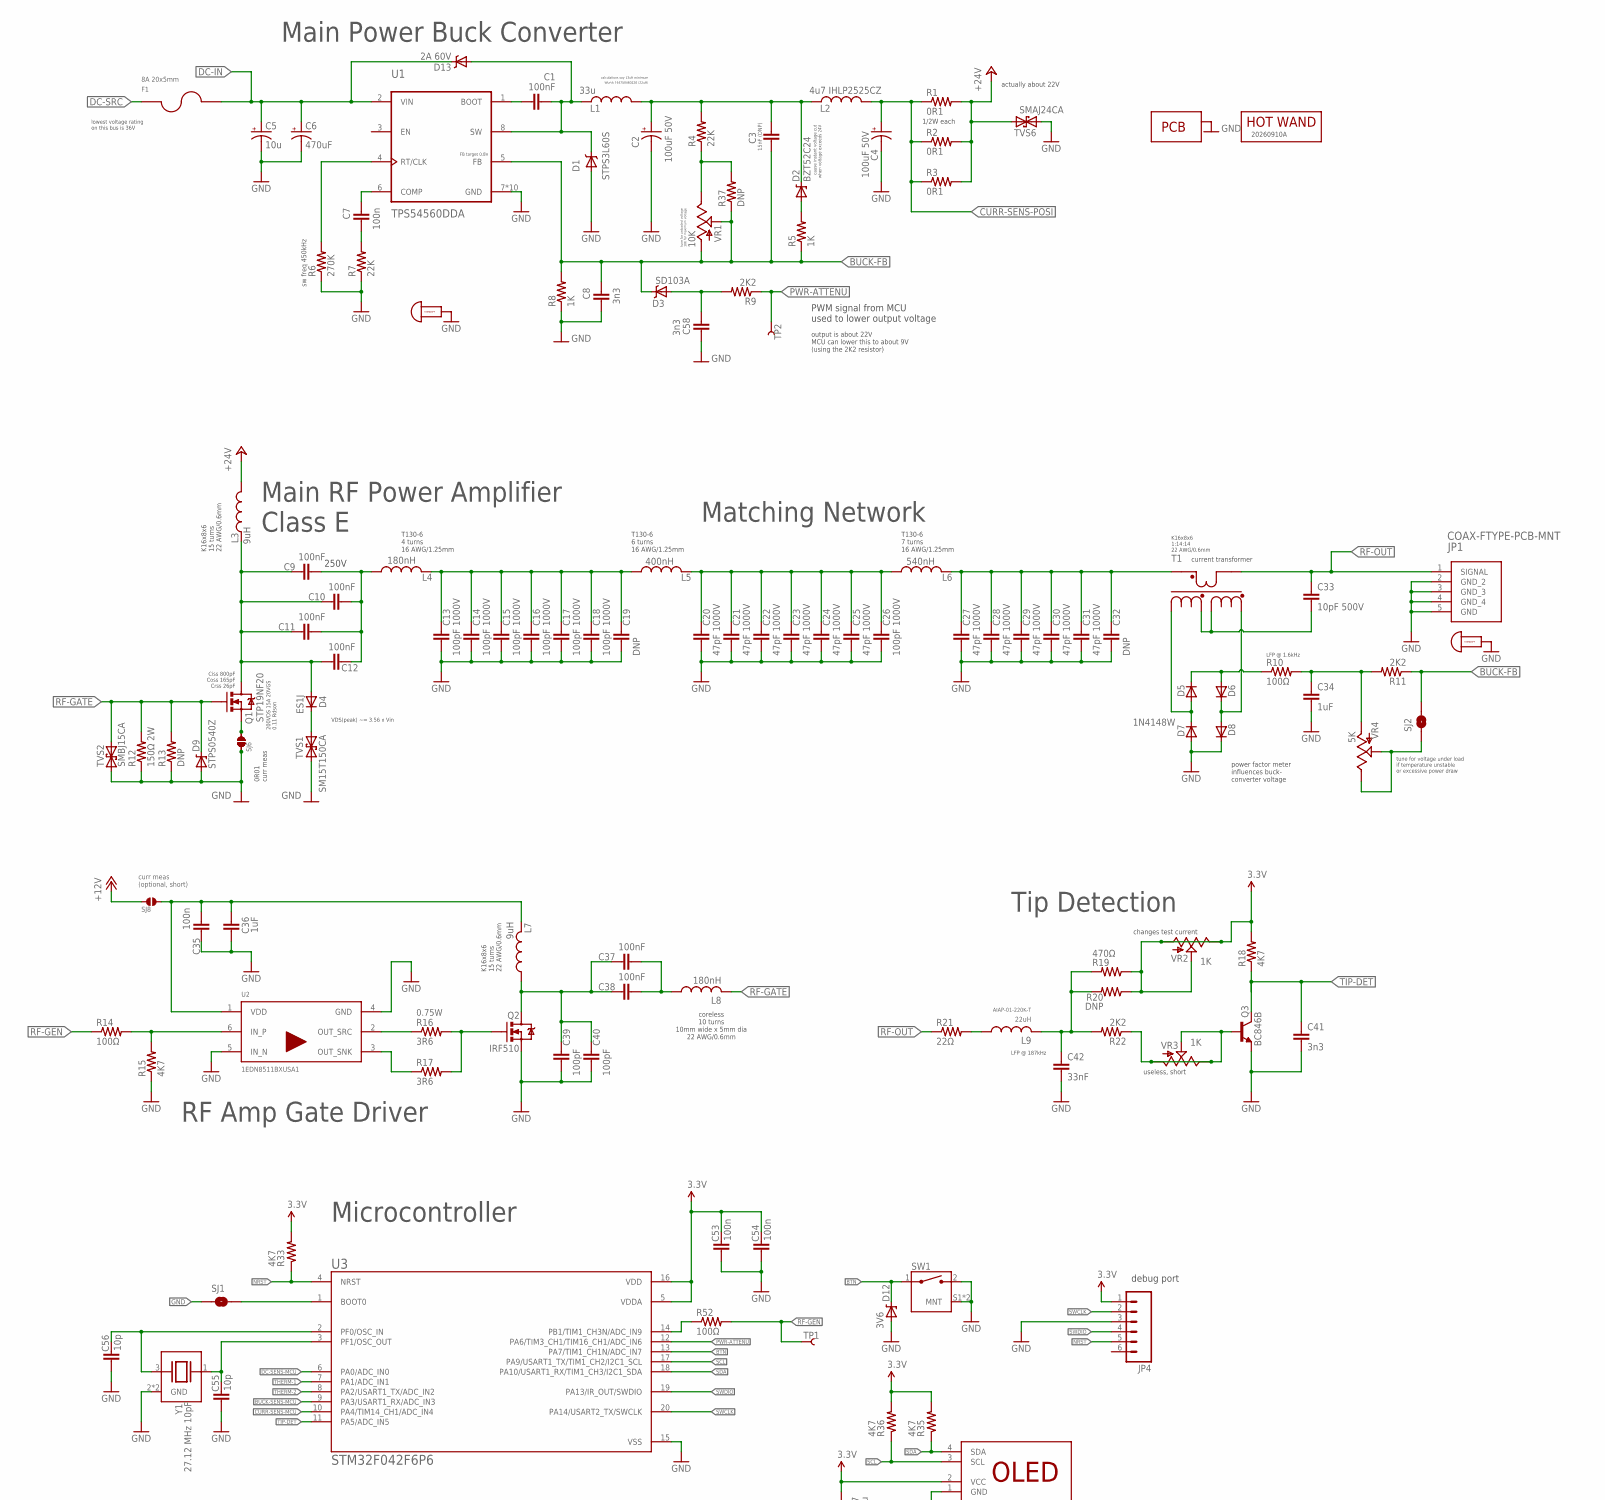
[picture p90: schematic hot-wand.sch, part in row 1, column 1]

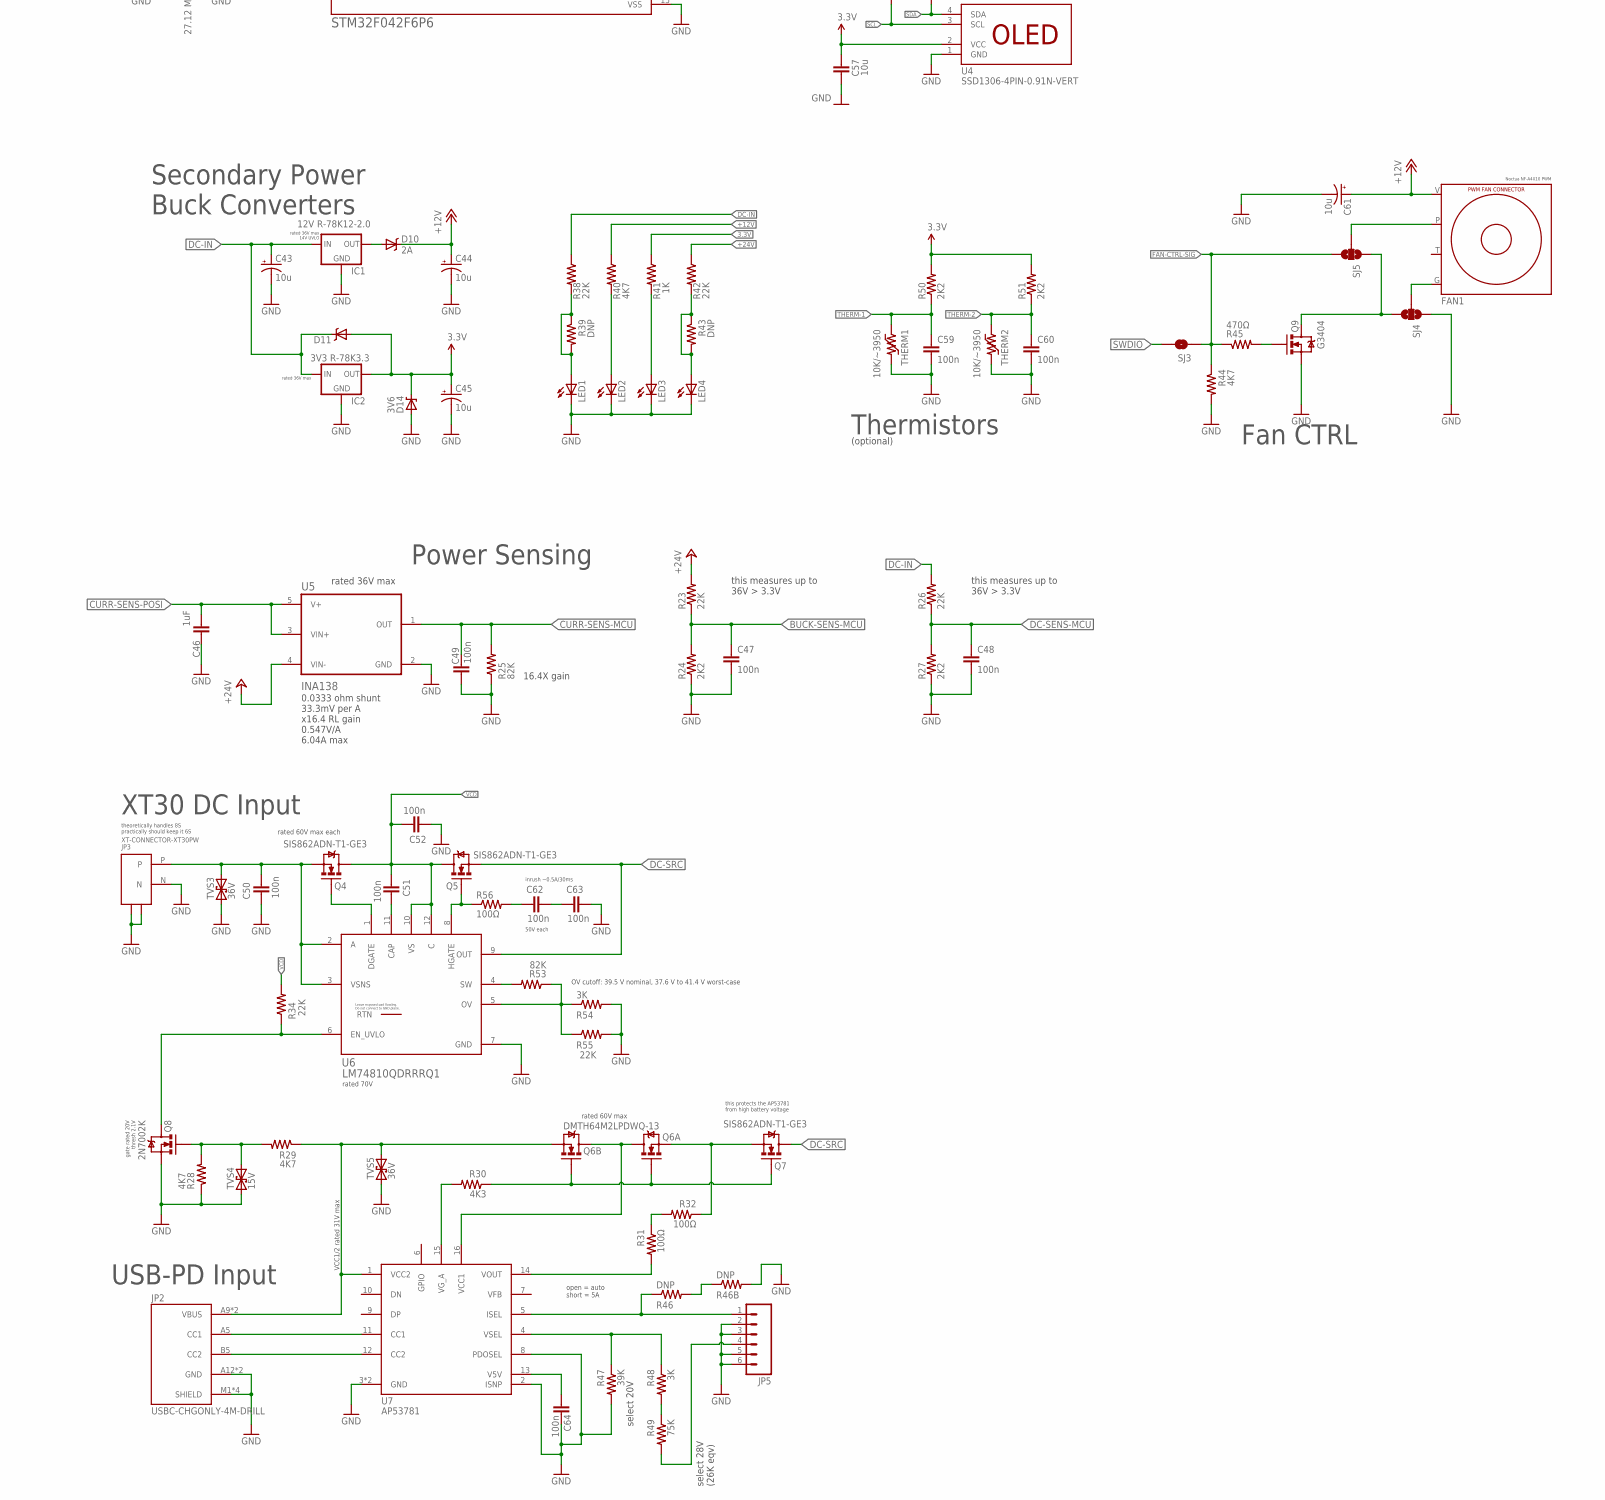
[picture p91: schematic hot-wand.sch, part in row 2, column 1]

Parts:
C1: 100nF; 0603-CAP; JLCPARTNUM C14663
C2: 100uF 50V; CPOL-RADIAL-COMBO-10MM; PARTNUM EEU-FR1H101B;EEU-FR1J101B; JLC-DNP 1
C3: 15nF (DNP); 0805; JLC-DNP 1
C4: 100uF 50V; CPOL-RADIAL-COMBO-10MM; JLC-DNP 1
C5, C43, C61: 10u; EIA3216-KIT; PARTNUM MLASU31LBB5106KTNA01;GRT31CR61H106KE01K; JLCPARTNUM C13585
C6: 470uF; CPOL-RADIAL-1000UF-25V; PARTNUM UHW1H471MPD;EEU-FR1H471;EEU-FR1H471B; JLC-DNP 1
C7, C35, C48, C49, C50, C51, C52, C53, C54, C59, C60, C62, C63, C64: 100n; 0603-CAP; JLCPARTNUM C14663
C8, C41, C58: 3n3; 0603-CAP; JLCPARTNUM C1613
C9, C10, C11, C12, C37, C38: 100nF; 0805-L; PARTNUM CHV0805N250104KXT;MBASQ21GAB7104KTCA01;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; JLCPARTNUM C5182461
C13: 100pF 1000V; 0805-L; PARTNUM QCCT102Q101J1GV001E; JLCPARTNUM C6958299
C14, C15, C16, C17, C18, C26: 100pF 1000V; 0805-L; JLCPARTNUM C6958299
C19: DNP; 0805-L; JLCPARTNUM C6958299
C20: 47pF 1000V; 0805-L; PARTNUM QCCT102Q470J1GV001E; JLCPARTNUM C6366545
C21, C22, C23, C24, C25, C27, C28, C29, C30, C31: 47pF 1000V; 0805-L; JLCPARTNUM C6366545
C32: DNP; 0805-L; JLC-DNP 1
C33: 10pF 500V; 0805-L; PARTNUM QCCT102Q100J1GV001E; JLCPARTNUM C6629873
C34, C36, C46: 1uF; 0603-CAP; JLCPARTNUM C15849
C39, C40: 100pF; 0805-L; JLCPARTNUM C6958299
C42: 33nF; 0603-CAP; JLCPARTNUM C21117
C44: 10u; EIA3216-KIT; PARTNUM TAJA106K016TNJ;T491A106K016AT; JLCPARTNUM C13585
C45: 10u; EIA3216; PARTNUM TAJA106K016TNJ;T491A106K016AT; JLCPARTNUM C13585
C47: 100n; 0603-CAP
C55, C56: 10p; 0603-CAP; JLCPARTNUM C1634
C57: 10u; 1206; JLCPARTNUM C13585
D1: STPS3L60S; SMC; JLCPARTNUM C2971007
D2: BZT52C24; SOD123FL; JLCPARTNUM C2109
D3: SD103A; SOD-323; JLCPARTNUM C7420360
D4: ES1J; SMA-DIODE; JLCPARTNUM C64879
D5, D6, D8: 4148; SOD123FL; JLCPARTNUM C84367
D7: 1N4148W; SOD123FL; JLCPARTNUM C84367
D9: STPS0540Z; SOD123FL; JLCPARTNUM C181835
D10: 2A; SMA-DIODE; PARTNUM VSSAF5N50;SL36A; JLCPARTNUM C698873
D11: DIODE-SCHOTTKY_; SMA-DIODE; JLCPARTNUM C698873
D12, D14: 3V6; SOD-323; PARTNUM ESDLC3V3D3B-TP;CDSOD323-T03SC;SD03LCC; JLCPARTNUM C840638
D13: 2A 60V; SOD123FL; PARTNUM STPS2L60ZFY; JLCPARTNUM C53340922
F1: 8A 20x5mm; FUSE_5MM; PARTNUM Keystone 3518P; JLC-DNP 1
FAN1: FAN-CONN-X4-CONN-X4; FAN-CONN-X4
IC1: 12V R-78K12-2.0; TO220-BUCK-12V; JLC-DNP 1
IC2: 3V3 R-78K3.3; TO220-BUCK-3.3V; JLC-DNP 1
JP1: COAX-FTYPE-PCB-MNT; CONN_73330-0030_MOL; JLC-DNP 1
JP2: USBC-CHGONLY-4M-DRILL; SAMESKY_UJC-H-G-SMT-2-P6-TR-DRILL; JLC-DNP 1
JP3: XT-CONNECTOR-XT30PW; XT30PW; JLC-DNP 1
JP4: M06LOCK; 1X06_LOCK; JLC-DNP 1
JP5: M06LOCK; 1X06_LOCK
L1: 33u; IND_RADIAL_D12.7_COMBO; PARTNUM Wurth 744750460220 (22uH); JLC-DNP 1
L2: 4u7 IHLP2525CZ; IND_IHLP-2525CZ_VIS-M; PARTNUM IHLP2525CZER4R7M11; JLCPARTNUM C845027
L3, L7: 9uH; IND_K16X8X6_X2; JLC-DNP 1
L4: 180nH; IND_T130-6_X2; JLC-DNP 1
L5: 400nH; IND_T130-6_X2; JLC-DNP 1
L6: 540nH; IND_T130-6_X2; JLC-DNP 1
L8: 180nH; IND-10X6MM; JLC-DNP 1
L9: 22uH; TFI0410; PARTNUM AIAP-01-220K-T; JLC-DNP 1
LED1, LED2, LED3, LED4: LED; LED-0603; JLC-DNP 1
PCB1: PCB-OUTLINE; JLC-DNP 1
PCB2: PCB-ART-VERSION; JLC-DNP 1
Q1: STP19NF20; TO220V-REAR; JLC-DNP 1
Q2: IRF510; TO220V-REAR; JLC-DNP 1
Q3: BC846B; SOT23-3; JLCPARTNUM C181138
Q4, Q5, Q7: SIS862ADN-T1-GE3; POWERPAK-1212-8; JLC-DNP 1
Q6: DMTH64M2LPDWQ-13; POWERPAK-SO8-X2; JLC-DNP 1
Q8: 2N7002K; SOT23-3; PARTNUM 2N7002K;SSM3K388R,LF;Si2318CDS-T1-GE3;P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; JLCPARTNUM C14498;C547263;C5224211;C54347659
Q9: G3404; SOT23-3; PARTNUM G3404;MMFTN3404A;PJA3404A;Si2318CDS-T1-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; JLCPARTNUM C14498;C547263;C96615
R1, R2, R3: 0R1; 1206; PARTNUM KDV12DR100ET;VMK-R033-1.0-U; JLCPARTNUM C188071
R4, R7, R23, R26, R34, R38, R42, R55: 22K; 0603-RES; JLCPARTNUM C31850
R5, R8, R41: 1K; 0603-RES; JLCPARTNUM C21190
R6: 270K; 0603-RES; JLCPARTNUM C137755
R9, R11, R22, R24, R27, R50, R51: 2K2; 0603-RES; JLCPARTNUM C4190
R10, R14, R52: 100Ω; 0603-RES; JLCPARTNUM C22775
R12: 150Ω 2W; R2512; PARTNUM CRGP2512F150R; JLCPARTNUM C175287
R13: DNP; R2512; PARTNUM CRGP2512F150R; JLC-DNP 1
R15, R18, R28, R29, R33, R35, R36, R40, R44: 4K7; 0603-RES; JLCPARTNUM C23162
R16, R17: 3R6; 1206; JLCPARTNUM C6301221
R19, R45: 470Ω; 0603-RES; JLCPARTNUM C23179
R20: DNP; 0805; JLC-DNP 1
R21: 22Ω; R2512; JLCPARTNUM C5204054
R25, R53: 82K; 0603-RES; JLCPARTNUM C23254
R30: 4K3; 0603-RES; JLCPARTNUM C23159
R31, R32, R56: 100Ω; 0805; JLCPARTNUM C441975
R37, R46, R46B: DNP; 0603-RES; JLC-DNP 1
R39, R43: DNP; 0603-RES
R47: 39K; 0603-RES; JLCPARTNUM C23153
R48, R54: 3K; 0603-RES; JLCPARTNUM C4211
R49: 75K; 0603-RES; JLCPARTNUM C23242
SJ1, SJ2, SJ3: SOLDERJUMPERNO; SJ_2S-NO; JLC-DNP 1
SJ4, SJ5: SOLDERJUMPER_2WAYS; SJ_3
SJ6, SJ7, SJ8: SJ-SMALL-1206-SJ; 1206-SJ
STANDOFF1, STANDOFF2: STANDOFF-M2.5-4.5MMHEX
SW1: SW-TACT-SIDE; SW_1-1825027-1; PARTNUM MJTP1236D;TL1105JAF160R1RBLK; JLC-DNP 1
T1: XFORMER-1:14:14; XFORMER-K16X8X6-1:14:14; JLC-DNP 1
THERM1, THERM2: 10K/~3950; 1X02-2MM; PARTNUM B57891M0103K000; JLC-DNP 1
TP1, TP2: TEST-POINT-SQ-2MM; PAD-SQ-2MM
TVS1: SM15T150CA; SMC; JLCPARTNUM C133715
TVS2: SMBJ15CA; SMA-DIODE; JLCPARTNUM C78809
TVS3, TVS5: 36V; SMA; PARTNUM SMAJ36CA; JLCPARTNUM C134984
TVS4: 15V; SOD-323; PARTNUM SD15C-01FTG;CDSOD323-T15SC;TSD15CDYFR; JLCPARTNUM C2987151
TVS6: SMAJ24CA; SMA; JLCPARTNUM C148223
U1: TPS54560DDA; VREG_LM5017MR/NOPB; JLCPARTNUM C31966
U2: 1EDN8511BXUSA1; SOT95P280X145-6N-7-V; JLCPARTNUM C3655509
U3: STM32F042F6P6; SOP65P640X120-20N; JLCPARTNUM C2969989
U4: SSD1306-4PIN-0.91N-VERT; OLED-0.91IN-VERT; JLC-DNP 1
U5: INA138; SOT95P280X145-5N; JLCPARTNUM C47914
U6: LM74810QDRRRQ1; DRR0012E-MFG; JLCPARTNUM C3215601
U7: AP53781; QFN3030-16; JLCPARTNUM C52730979
VR1: 10K; TRIM_35WR1KLFTR_V2; PARTNUM TC33X-2-103E; JLC-DNP 1
VR2, VR3: 1K; TRIM_35WR1KLFTR_V3; PARTNUM TC33X-2-102E; JLC-DNP 1
VR4: 5K; TRIM_35WR1KLFTR_V2; PARTNUM TC33X-2-502; JLC-DNP 1
Y1: 27.12 MHz 10pF; XTAL-4SMD-3.2X2.5-V2; JLCPARTNUM C1986817

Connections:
3.3V: C45.A (+), C53.1, C54.1, C57.2, D11.A, D14.1 (C), IC2.3 (OUT), JP4.1, R18.2, R19.1, R20.1, R33.2, R35.2, R36.2, R41.1, R50.2, R51.2, U3.5 (VDDA), U3.16 (VDD), U4.2 (VCC), VR2.1 (A), VR2.2 (S), VR2.3 (E)
12V-2: D10.A, IC1.3 (OUT)
12V-FOR-GATE-DRIVER: C35.2, C36.2, L7.2, SJ8.2, U2.1 (VDD)
+12V: C44.A (+), C61.A (+), D10.C, FAN1.V, R40.1, SJ8.1
+24V: L3.2, R1.2, R2.2, R3.2, R23.2, R42.1, TVS6.C (2), U5.4 (VIN-)
BTN: D12.1 (C), SW1.1, U3.13 (PA7/TIM1_CH1N/ADC_IN7)
BUCK-1ST-STAGE: C2.1 (+), C2.1B (+), C3.2, D2.C, L1.2, L1.2B (2), L2.1, R4.2
BUCK-FB: C3.1, C8.2, D3.1 (C), R5.1, R8.2, R11.1, R37.1, SJ2.2, U1.5 (FB), VR1.1 (A), VR1.2 (S)
BUCK-SENS-MCU: C47.1, R23.1, R24.2, U3.9 (PA3/USART1_RX/ADC_IN3)
BUCK-SWITCH-NODE: C1.2, D1.C, D13.A, L1.1, L1.1B (1), U1.8 (SW)
CURR-SENS-MCU: C49.1, R25.2, U3.10 (PA4/TIM14_CH1/ADC_IN4), U5.1 (OUT)
CURR-SENS-POSI: C4.1 (+), C4.1B (+), C46.2, L2.2, R1.1, R2.1, R3.1, U5.3 (VIN+), U5.5 (V+)
DC-IN: C5.A (+), C6.1 (+), C43.A (+), D11.C, D13.C, F1.3 (2), F1.4 (2), IC1.1 (IN), IC2.1 (IN), R26.2, R38.1, U1.2 (VIN)
DC-SENS-MCU: C48.1, R26.1, R27.2, U3.6 (PA0/ADC_IN0)
DC-SRC: F1.1, F1.2 (1), Q5.1 (S), Q5.2 (S), Q5.3 (S), Q7.5 (D), Q7.6 (D), Q7.7 (D), Q7.8 (D), Q7.9 (D), U6.9 (OUT)
FAN-CTRL-SIG: R44.1, R45.1, SJ3.1, SJ5.3
GND: C2.2 (-), C2.2B (-), C4.2 (-), C4.2B (-), C5.C (-), C6.2 (-), C8.1, C13.2, C14.2, C15.2, C16.2, C17.2, C18.2, C19.2, C20.2, C21.2, C22.2, C23.2, C24.2, C25.2, C26.2, C27.2, C28.2, C29.2, C30.2, C31.2, C32.2, C34.2, C35.1, C36.1, C39.2, C40.2, C41.2, C42.2, C43.C (-), C44.C (-), C45.C (-), C46.1, C47.2, C48.2, C49.2, C50.2, C52.2, C53.2, C54.2, C55.2, C56.2, C57.1, C58.1, C59.2, C60.2, C61.C (-), C63.1, C64.1, D1.A, D7.A, D8.C, D9.A, D12.2 (A), D14.2 (A), IC1.2 (GND), IC2.2 (GND), JP1.2 (GND_2), JP1.3 (GND_3), JP1.4 (GND_4), JP1.5 (GND), JP2.A12 (GND), JP2.B12 (GND), JP2.M1 (SHIELD), JP2.M2 (SHIELD), JP2.M3 (SHIELD), JP2.M4 (SHIELD), JP3.M1, JP3.M2, JP3.N, JP4.3, JP5.2, JP5.3, JP5.5, JP5.6, LED1.C, LED2.C, LED3.C, LED4.C, PCB1.1, PCB1.2, PCB1.3, PCB1.4, Q2.3 (S), Q3.2 (E), Q8.2 (S), Q9.2 (S), R6.1, R7.1, R8.1, R12.1, R13.1, R15.1, R24.1, R25.1, R27.1, R28.1, R44.2, R46B.2, R47.2, R54.2, R55.2, SJ1.1, SJ4.1, SJ6.1, SJ7.1, STANDOFF1.1, STANDOFF1.2, STANDOFF2.1, STANDOFF2.2, SW1.2, SW1.S1 (MNT), SW1.S2 (MNT), THERM1.2, THERM2.2, TVS1.A (1), TVS2.A (1), TVS3.A (1), TVS4.2 (1), TVS5.A (1), TVS6.A (1), U1.7 (GND), U1.9 (GND), U1.10 (GND), U1.11 (GND), U1.12 (GND), U1.13 (GND), U1.14 (GND), U1.15 (GND), U1.16 (GND), U1.17 (GND), U2.4 (GND), U2.5 (IN_N), U3.15 (VSS), U4.1 (GND), U5.2 (GND), U6.7 (GND), U7.2 (ISNP), U7.3 (GND), U7.8 (PDOSEL), U7.EXP (GND), Y1.2 (GND), Y1.4 (GND)
MCU-BOOT0: SJ1.2, U3.1 (BOOT0)
MCU-OSC-IN: C56.1, U3.2 (PF0/OSC_IN), Y1.3 (2)
MCU-OSC-OUT: C55.1, U3.3 (PF1/OSC_OUT), Y1.1
MCU-RF: R14.2, R15.2, U2.6 (IN_P)
unnamed: L9.1, R21.2
unnamed: C33.2, T1.S1B (4), T1.S2A (3)
unnamed: C20.1, C21.1, C22.1, C23.1, C24.1, C25.1, C26.1, L5.2, L6.1
unnamed: D5.C, D6.A, R10.1
unnamed: D6.C, D8.A, T1.S2B (2)
unnamed: D5.A, D7.C, T1.S1A (1)
unnamed: D4.C, TVS1.C (2)
unnamed: C42.1, L9.2, R19.2, R20.2, R22.2
unnamed: C13.1, C14.1, C15.1, C16.1, C17.1, C18.1, C19.1, L4.2, L5.1
unnamed: C9.2, C10.2, C11.2, C12.2, L4.1
unnamed: R16.1, U2.2 (OUT_SRC)
unnamed: R17.1, U2.3 (OUT_SNK)
unnamed: Q2.1 (G), R16.2, R17.2
unnamed: C37.2, C38.2, L8.1
unnamed: C7.2, U1.6 (COMP)
unnamed: C7.1, R7.2
unnamed: R6.2, U1.4 (RT/CLK)
unnamed: C1.1, U1.1 (BOOT)
unnamed: R4.1, R37.2, VR1.3 (E)
unnamed: D2.A, R5.2
unnamed: C58.2, D3.2 (A), R9.2
unnamed: C62.1, C63.2
unnamed: Q8.1 (G), R28.2, R29.2, TVS4.1 (2)
unnamed: Q6.5 (D), Q6.6 (D), Q6.7 (D), Q6.8 (D), Q6.9 (D), Q6.10 (D), U7.16 (VCC1)
unnamed: C64.2, U7.13 (V5V)
unnamed: R31.2, U7.14 (VOUT)
unnamed: C62.2, R56.2
unnamed: LED2.A, R40.2
unnamed: LED3.A, R41.2
unnamed: LED1.A, R38.2, R39.1, R39.2
unnamed: SJ2.1, VR4.2 (S), VR4.3 (E)
unnamed: Q9.1 (G), R45.2
unnamed: R46.2, R46B.1
unnamed: R31.1, R32.2
unnamed: R48.2, R49.1
unnamed: JP5.4, R49.2
unnamed: LED4.A, R42.2, R43.1, R43.2
unnamed: Q6.1 (S), Q7.1 (S), Q7.2 (S), Q7.3 (S), R32.1
unnamed: FAN1.G, SJ4.2
unnamed: FAN1.P, SJ5.2
unnamed: R53.2, U6.4 (SW)
NRST: JP4.5, R33.1, U3.4 (NRST)
PWR-ATTENU: R9.1, TP2.1, U3.12 (PA6/TIM3_CH1/TIM16_CH1/ADC_IN6)
Q1-VD: C9.1, C10.1, C11.1, C12.1, D4.A, L3.1, Q1.2 (D)
Q1-VS: Q1.3 (S), SJ6.2, SJ7.2
Q2-VD: C37.1, C38.1, C39.1, C40.1, L7.1, Q2.2 (D)
Q3-VB: Q3.1 (B), R22.1, VR3.1 (A), VR3.2 (S), VR3.3 (E)
Q9-VD: Q9.3 (D), SJ4.3, SJ5.1
RF-FB-RECTIFIED: C34.1, R10.2, R11.2, VR4.1 (A)
RF-FINAL: C27.1, C28.1, C29.1, C30.1, C31.1, C32.1, L6.2, T1.P1 (P2)
RF-GATE: D9.C, L8.2, Q1.1 (G), R12.2, R13.2, TVS2.C (2)
RF-GEN: R14.1, R52.2, TP1.1
RF-GEN-: R52.1, U3.14 (PB1/TIM1_CH3N/ADC_IN9)
RF-OUT: C33.1, JP1.1 (SIGNAL), R21.1, T1.P2 (P1)
SCL: R36.1, U3.17 (PA9/USART1_TX/TIM1_CH2/I2C1_SCL), U4.3 (SCL)
SDA: R35.1, U3.18 (PA10/USART1_RX/TIM1_CH3/I2C1_SDA), U4.4 (SDA)
SWCLK: JP4.2, U3.20 (PA14/USART2_TX/SWCLK)
SWDIO: JP4.4, SJ3.2, U3.19 (PA13/IR_OUT/SWDIO)
THERM-1: C59.1, R50.1, THERM1.1, U3.7 (PA1/ADC_IN1)
THERM-2: C60.1, R51.1, THERM2.1, U3.8 (PA2/USART1_TX/ADC_IN2)
TIP-DET: C41.1, Q3.3 (C), R18.1, U3.11 (PA5/ADC_IN5)
U6-CAP: C51.1, U6.11 (CAP)
U6-DGATE: Q4.4 (G), U6.1 (DGATE)
U6-EN: Q8.3 (D), R34.1, U6.6 (EN_UVLO)
U6-HGATE: Q5.4 (G), R56.1, U6.8 (HGATE)
U6-OV: R53.1, R54.1, R55.1, U6.5 (OV)
U7-ISEL: JP5.1, R46.1, U7.5 (ISEL)
U7-VGA: R30.2, U7.15 (VG_A)
U7-VGA-2: Q6.2 (G), Q6.4 (G), Q7.4 (G), R30.1
U7-VSEL: R47.1, R48.1, U7.4 (VSEL)
USB-CC1: JP2.A5 (CC1), U7.11 (CC1)
USB-CC2: JP2.B5 (CC2), U7.12 (CC2)
USB-VBUS: JP2.A9 (VBUS), JP2.B9 (VBUS), Q6.3 (S), R29.1, TVS5.C (2), U7.1 (VCC2)
VCD: C51.2, C52.1, Q4.5 (D), Q4.6 (D), Q4.7 (D), Q4.8 (D), Q4.9 (D), Q5.5 (D), Q5.6 (D), Q5.7 (D), Q5.8 (D), Q5.9 (D), R34.2, U6.10 (VS), U6.12 (C)
VIN-XT30: C50.1, JP3.P, Q4.1 (S), Q4.2 (S), Q4.3 (S), TVS3.C (2), U6.2 (A), U6.3 (VSNS)

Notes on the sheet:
this measures up to 36V > 3.3V
rated 36V max
16.4X gain
0.0333 ohm shunt 33.3mV per A x16.4 RL gain 0.547V/A 6.04A max
Main Power Buck Converter
Power Sensing
RF Amp Gate Driver
Main RF Power Amplifier Class E
current transformer
power factor meter influences buck- converter voltage
Tip Detection
Secondary Power Buck Converters
Matching Network
PWM signal from MCU used to lower output voltage
T130-6 7 turns 16 AWG/1.25mm
T130-6 6 turns 16 AWG/1.25mm
T130-6 4 turns 16 AWG/1.25mm
K16x8x6 1:14:14 22 AWG/0.6mm
K16x8x6 15 turns 22 AWG/0.6mm
coreless 10 turns 10mm wide x 5mm dia 22 AWG/0.6mm
1/2W each
Ciss 800pF Coss 165pF Crss 26pF
200VDS 15A 20VGS 0.11 Rdson
AIAP-01-220K-T
select 20V
XT30 DC Input
USB-PD Input
gate rated 20V thresh 2.1V
Microcontroller
Thermistors
(optional)
LFP @ 1.6kHz
tune for voltage under load if temperature unstable or excessive power draw
useless, short
LFP @ 187kHz
sw freq 450kHz
tune for unloaded voltage 10K for maximum voltage
Wurth 744750460220 (22uH)
output is about 22V MCU can lower this to about 9V (using the 2K2 resistor)
cause instant voltage cut when voltage exceeds 24V

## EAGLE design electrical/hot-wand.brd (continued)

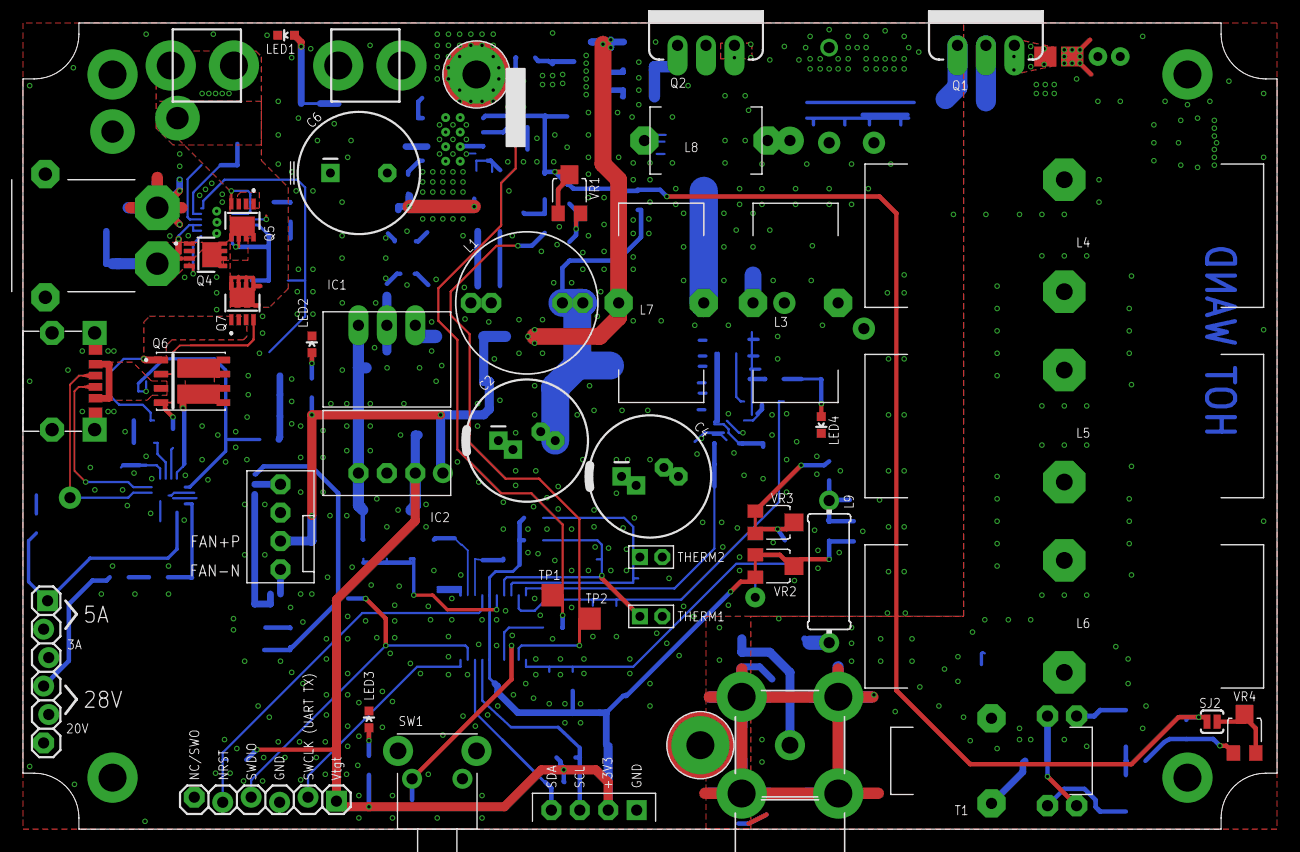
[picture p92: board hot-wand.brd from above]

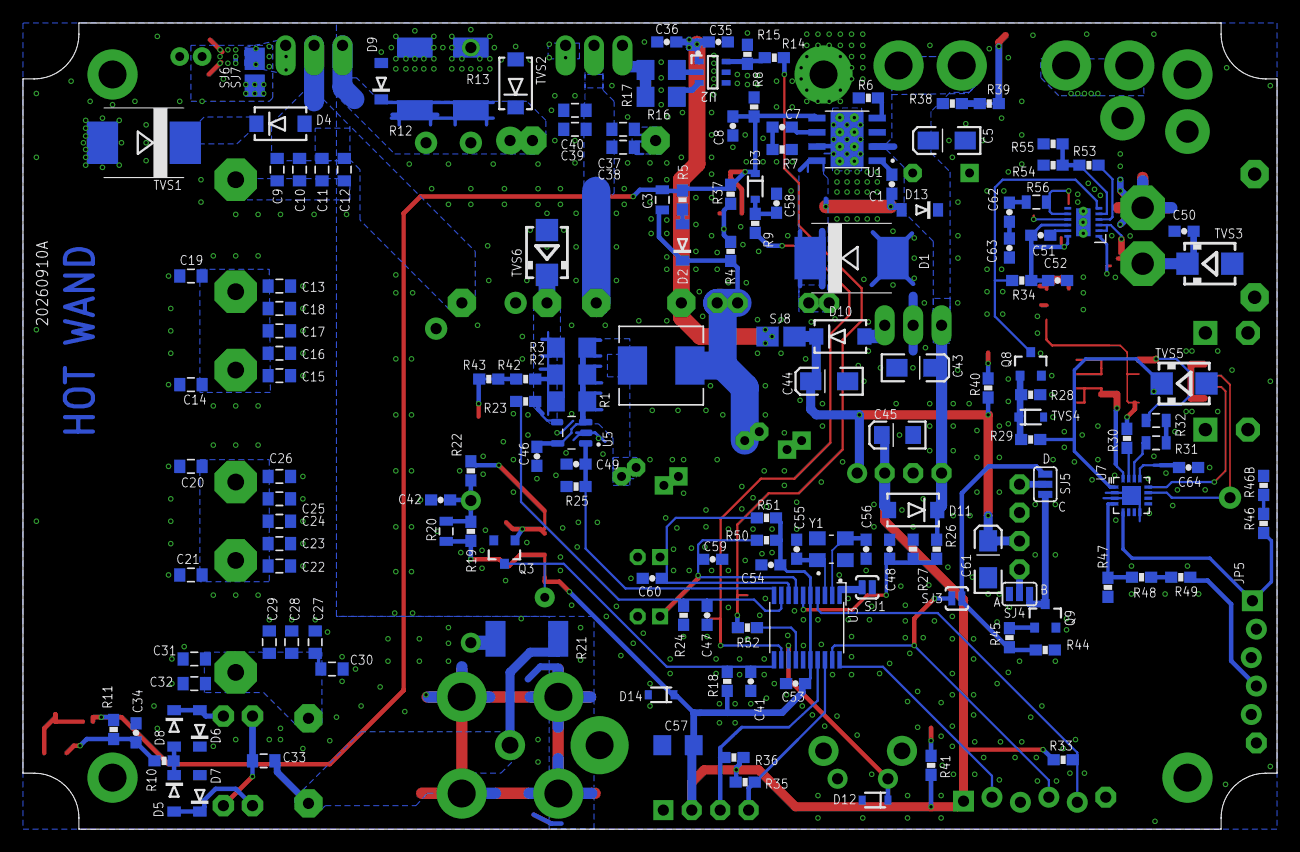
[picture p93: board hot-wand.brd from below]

Board: 2 copper layers, 112.0 x 72.0 mm, 202 parts (156 on the bottom side), 96 nets.

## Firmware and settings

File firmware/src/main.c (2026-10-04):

// -----------------------------------------------------------------------------
// Includes
// -----------------------------------------------------------------------------

#include "hotwand.h"
#include "adc.h"
#include "battery.h"
#include "button.h"
#include "conf.h"
#include "fan.h"
#include "fault.h"
#include "miscutils.h"
#include "nvm.h"
#include "oled.h"
#include "pwrmgt.h"
#include "pwrlvl.h"
#include "rfgen.h"
#include "setup_menu.h"
#include "stm32f0xx_hal.h"
#include "systick.h"
#include "tipdetect.h"
#include "uart_debug.h"
#include "tests.h"
#include "watchdog.h"

#include <stddef.h>
#include <stdint.h>

// -----------------------------------------------------------------------------
// Configuration
// -----------------------------------------------------------------------------

#if !defined(HOT_WAND_TARGET_STM32F030) && !defined(HOT_WAND_TARGET_STM32F042)
#error "This source supports only the STM32F030 and STM32F042 targets."
#endif

#define SETUP_HOLD_BAR_WIDTH             32
#define SETUP_HOLD_BAR_HEIGHT            3
#define SETUP_HOLD_BAR_Y                 45
#define MAIN_DISPLAY_FRAME_INTERVAL_MS   67
#define MAIN_DISPLAY_VOLTAGE_BUFFER_SIZE 8

// -----------------------------------------------------------------------------
// Globals
// -----------------------------------------------------------------------------

static const uint32_t auto_sleep_delay_ms[] = {0, 5 * 60 * 1000, 15 * 60 * 1000, 30 * 60 * 1000};
static const uint32_t auto_dim_delay_ms[]   = {0, 15 * 1000, 30 * 1000, 60 * 1000};

#ifdef SHOW_SPLASH
static uint32_t splash_started_ms;
static bool     splash_visible;
#endif

uint8_t pixshift_x = 0; // randomized pixel shift to avoid OLED burn-in
uint8_t pixshift_y = 0;

// -----------------------------------------------------------------------------
// Function Prototypes
// -----------------------------------------------------------------------------

void enter_sleep_mode(void);

static void boot_check_for_setup(void);
static void boot_draw_setup_hold(u8g2_t* graphics, uint8_t bar_width);
static void boot_wait_for_power_stable(void);
static void main_render_display(void);
static void Error_Handler(void);

// -----------------------------------------------------------------------------
// Main Flow
// -----------------------------------------------------------------------------

int main(void)
{
#if defined(HOT_WAND_FIDUCIAL_ONLY) && HOT_WAND_FIDUCIAL_ONLY
    test_bringup_oled_fiducial(); // camera focus/exposure image; never returns
#elif !defined(BTN_SWD_TEST_HARNESS) || !BTN_SWD_TEST_HARNESS
    test_run(); // if a test is enabled, it does its own initialization and never returns
#endif

    battery_guess_t     battery_guess_result;
    hotwand_setup_nvm_t settings;
    uint32_t            random_seed;
    uint32_t            display_last_frame_ms;
    uint16_t            input_millivolts;
    bool                boot_button_down;

    // HAL provides the temporary reset-clock tick needed by the RCC startup timeout. Application initialization begins
    // with HSE immediately afterward.
    HAL_Init();

    /* Establish the fail-low RF state before starting the watchdog. */
    rfgen_stop();
    if (!watchdog_init())
    {
        Error_Handler();
    }

    rfgen_clock_init();
    systick_init();
    adc_init();
    btn_init();

    I2C1_Init();
    if (!OLED_Init(&oled, &i2c1))
    {
        Error_Handler();
    }
    OLED_ConfigureGraphics(&oled);

#if defined(HOT_WAND_VISION_TEST) && HOT_WAND_VISION_TEST
    /* Put the calibration target on the OLED before any normal boot graphics.
     * SWD dismissal preserves the harness's synthetic boot hold for Setup Menu. */
    vision_test_fiducial_gate();
#endif

    nvm_init();
    if (!nvm_read(&settings))
    {
        nvm_apply_defaults(&settings);
    }
    adc_set_input_voltage_calibration(settings.input_v_calib);

    // when all ADC channels have been read once
    // we use the LSB of the data to use as a RNG seed
    // taking advantage of noise
    /* Deliberately do not feed here: a DMA/ADC path that never produces a
     * usable seed is a startup fault and should be recovered by IWDG. */
    do
    {
        random_seed = adc_get_rand_seed();
    } while (random_seed == 0);
    hotwand_srand(random_seed);

#ifdef SHOW_SPLASH
    if (settings.show_splash)
    {
        show_splash();
        splash_started_ms = systick_get_ms();
        splash_visible    = true;
    }
#endif

    pixshift_x = hotwand_rand() % (OLED_MAX_PIXEL_SHIFT_X_BIGFONT + 1);
    pixshift_y = hotwand_rand() % (OLED_MAX_PIXEL_SHIFT_Y + 1);

    boot_button_down = btn_is_down();
    UART_SetAllowed(boot_button_down);
    if (boot_button_down)
    {
        boot_check_for_setup();
        // this might just reboot
    }

    boot_wait_for_power_stable();

    input_millivolts = adc_to_millivolts(DC_SENS_IDX);

    if ((settings.batt_mode != BATT_MODE_NONE) && (settings.batt_mode <= BATT_MODE_LIFE_SAFE))
    {
        // automatic cell count determination
        if (battery_guess(input_millivolts, settings.batt_mode, &battery_guess_result))
        {
            battery_set_params(battery_guess_result.optimistic_cell_count, settings.batt_mode);
        }
    }
    else
    {
        // 0 cell will disable battery level monitoring
        battery_set_params(0, BATT_MODE_NONE);
    }

    /* perform all other initialization here */
    tipdetect_init();
    pwrlvl_init();
    pwrmgt_set_desired_power_level((pwrlvl_mode_t)settings.startup_power_level);
    pwrmgt_set_idle_power_threshold(settings.idle_detect_thresh);
    settings.fan_mode = fan_normalize_mode(settings.fan_mode);
    fan_init(settings.fan_mode, settings.fan_sig_inv != 0);
    display_last_frame_ms = systick_get_ms() - MAIN_DISPLAY_FRAME_INTERVAL_MS;

    for (;;)
    {
        uint32_t inactive_ms;
        uint32_t now;
        bool     short_msg_active;

        btn_task();
        tipdetect_task();

        // Both faults are latched and stop the RF generator at their source. Their screens are terminal until the user
        // requests a reset.
        if (tipdetect_has_triggered())
        {
            show_fault("TIP\nFAULT", true);
        }
        if (rfgen_has_clock_fault())
        {
            show_fault("CLOCK\nFAULT", true);
        }

        // Central runtime output supervisor:
        // - Checks the configured battery cutoff, input-power loss, buck-output overvoltage, terminal input
        //   undervoltage, and sustained overtemperature shutdown.
        // - Applies temperature and input-voltage derating with hysteresis.
        // - Selects the effective power level and advances PWM attenuation.
        // - Enforces current and short-circuit limits in the lower-level task.
        // - Updates attenuation diagnostics, activity timing, and graph history.
        // A terminal fault blocks here until the user resets the controller.
        pwrmgt_task();

        // Retry after supervision has ruled out terminal power faults. The RF driver performs its own clock-fault and
        // tip-debounce checks too.
        if (!rfgen_is_active() && rfgen_tip_allows_start())
        {
            rfgen_start();
        }

        ntc_task();        // reports missing external temperature sensors once after startup
        fan_task();        // spins the fan as appropriate
        UART_debug_task(); // spits out a debug message when requested

        now = systick_get_ms();

        if (btn_has_short_press(true))
        {
#ifdef SHOW_SPLASH
            if (splash_visible)
            {
                splash_visible = false;
            }
            else
#endif
            {
                pwrmgt_change_pwr_lvl();
            }
        }
        if (btn_has_long_press(true))
        {
            enter_sleep_mode();
        }

        inactive_ms = pwrmgt_get_time_since_last_activity_ms();

        if ((settings.auto_sleep != AUTO_SLEEP_OFF) && (inactive_ms >= auto_sleep_delay_ms[settings.auto_sleep]))
        {
            enter_sleep_mode();
        }

        OLED_SetDimMode(&oled,
                        (settings.auto_dim != AUTO_DIM_OFF) && (inactive_ms >= auto_dim_delay_ms[settings.auto_dim]));

        // Transient messages own the display while active. Otherwise draw the live voltage and graph at no more than 15
        // frames per second.
        short_msg_active = short_msg_task();

#ifdef SHOW_SPLASH
        if (short_msg_active)
        {
            splash_visible = false;
        }
#endif

        if (!short_msg_active && ((uint32_t)(now - display_last_frame_ms) >= MAIN_DISPLAY_FRAME_INTERVAL_MS))
        {
            display_last_frame_ms = now;
            main_render_display();
        }

        /* Feed only after the complete supervised foreground pass succeeds. */
        watchdog_feed();
    }
}

// -----------------------------------------------------------------------------
// Supporting Functions
// -----------------------------------------------------------------------------

static void boot_check_for_setup(void)
{
    u8g2_t*  graphics = OLED_GetGraphics(&oled);
    uint32_t hold_start_ms;
    uint32_t release_start_ms = 0;
    uint8_t  drawn_width      = 0;
    bool     release_pending  = false;

    if (graphics == NULL)
    {
        Error_Handler();
    }

#ifdef SHOW_SPLASH
    splash_visible = false;
#endif

    boot_draw_setup_hold(graphics, 0);
    hold_start_ms = systick_get_ms();

    for (;;)
    {
        uint32_t elapsed;
        uint32_t now;
        uint8_t  width;

        btn_task();
        now = systick_get_ms();

        if (!btn_is_down())
        {
            if (!release_pending)
            {
                release_start_ms = now;
                release_pending  = true;
            }
            else if ((uint32_t)(now - release_start_ms) >= BTN_DEBOUNCE_MS)
            {
                u8g2_ClearBuffer(graphics);
                OLED_SendBuffer(&oled);
                btn_has_short_press(true);
                btn_has_long_press(true);
                return;
            }

            HAL_Delay(1);
            watchdog_feed();
            continue;
        }

        release_pending = false;
        elapsed         = (uint32_t)(now - hold_start_ms);
        if (elapsed >= SETUP_HOLD_DURATION_MS)
        {
            width = SETUP_HOLD_BAR_WIDTH;
        }
        else
        {
            width = (uint8_t)((elapsed * SETUP_HOLD_BAR_WIDTH) / SETUP_HOLD_DURATION_MS);
        }

        if (width != drawn_width)
        {
            boot_draw_setup_hold(graphics, width);
            drawn_width = width;
        }

        if (width >= SETUP_HOLD_BAR_WIDTH)
        {
            setup_menu();
            return;
        }

        HAL_Delay(1);
        watchdog_feed();
    }
}

static void boot_draw_setup_hold(u8g2_t* graphics, uint8_t bar_width)
{
    u8g2_ClearBuffer(graphics);
    u8g2_DrawStr(graphics, 1, OLED_FIRST_TEXT_BASELINE, "HOLD");
    u8g2_DrawStr(graphics, 1, OLED_FIRST_TEXT_BASELINE + OLED_TEXT_LINE_HEIGHT, "TO");
    u8g2_DrawStr(graphics, 1, OLED_FIRST_TEXT_BASELINE + (2 * OLED_TEXT_LINE_HEIGHT), "ENTER");
    u8g2_DrawStr(graphics, 1, OLED_FIRST_TEXT_BASELINE + (3 * OLED_TEXT_LINE_HEIGHT), "SETUP");
    u8g2_DrawBox(graphics, 0, SETUP_HOLD_BAR_Y, bar_width, SETUP_HOLD_BAR_HEIGHT);
    OLED_SendBuffer(&oled);
}

static void boot_wait_for_power_stable(void)
{
    uint16_t maximum_millivolts = adc_to_millivolts(DC_SENS_IDX);
    uint32_t wait_started_ms    = systick_get_ms();
    uint32_t maximum_reached_ms = wait_started_ms;
    bool     wait_message_drawn = false;

    for (;;)
    {
        uint16_t millivolts = adc_to_millivolts(DC_SENS_IDX);
        uint32_t now        = systick_get_ms();

#ifdef SHOW_SPLASH
        btn_task();
        if (splash_visible && btn_has_short_press(true))
        {
            u8g2_t* graphics = OLED_GetGraphics(&oled);

            splash_visible = false;
            if (graphics != NULL)
            {
                u8g2_ClearBuffer(graphics);
                OLED_SendBuffer(&oled);
            }
        }
#endif

        if (millivolts > maximum_millivolts)
        {
            maximum_millivolts = millivolts;
            maximum_reached_ms = now;
        }

        if ((uint32_t)(now - maximum_reached_ms) >= BOOT_POWER_STABLE_MS)
        {
            return;
        }

        if ((uint32_t)(now - wait_started_ms) >= BOOT_POWER_TIMEOUT_MS)
        {
            return;
        }

        if (!wait_message_drawn && ((uint32_t)(now - wait_started_ms) >= BOOT_POWER_WAIT_MS))
        {
            u8g2_t* graphics = OLED_GetGraphics(&oled);

            if (graphics != NULL)
            {
#ifdef SHOW_SPLASH
                if (splash_visible)
                {
                    u8g2_SetDrawColor(graphics, 0);
                    u8g2_DrawBox(graphics, 0, 0, 32, OLED_TEXT_LINE_HEIGHT);
                    u8g2_SetDrawColor(graphics, 1);
                }
                else
#endif
                {
                    u8g2_ClearBuffer(graphics);
                }
                u8g2_DrawStr(graphics, 1, OLED_FIRST_TEXT_BASELINE, ".....");
                OLED_SendBuffer(&oled);
            }

            wait_message_drawn = true;
        }

        HAL_Delay(1);
        watchdog_feed();
    }
}

static void main_render_display(void)
{
    char     voltage[MAIN_DISPLAY_VOLTAGE_BUFFER_SIZE];
    size_t   voltage_length;
    uint16_t input_millivolts;
    u8g2_t*  graphics = OLED_GetGraphics(&oled);

#ifdef SHOW_SPLASH
    if (splash_visible)
    {
        if ((uint32_t)(systick_get_ms() - splash_started_ms) < SHOW_SPLASH_MS)
        {
            return;
        }

        splash_visible = false;
    }
#endif

    if (graphics == NULL)
    {
        return;
    }

    input_millivolts = adc_to_millivolts(DC_SENS_IDX);
    millivolts_to_str(input_millivolts, voltage, 1, &voltage_length);
    voltage[voltage_length++] = 'V';
    voltage[voltage_length]   = '\0';

    u8g2_ClearBuffer(graphics);
    u8g2_SetFont(graphics, u8g2_font_6x10_tr);
    u8g2_DrawStr(graphics, (u8g2_uint_t)pixshift_x, (u8g2_uint_t)(OLED_FIRST_TEXT_BASELINE + pixshift_y), voltage);
    pwrmgt_render_graph(graphics);
    pwrmgt_render_high_voltage_warning(graphics, input_millivolts);
    OLED_SendBuffer(&oled);
}

void enter_sleep_mode(void)
{
    show_fault("ZZZZZ", true);
}

// -----------------------------------------------------------------------------
// Debug / Fault Helpers
// -----------------------------------------------------------------------------

static void Error_Handler(void)
{
    /* Leave every power-stage control fail-low, then let IWDG recover. */
    rfgen_emergency_stop();
    __disable_irq();

    /* Deliberately do not feed the watchdog in a fatal handler. */
    for (;;)
    {
    }
}

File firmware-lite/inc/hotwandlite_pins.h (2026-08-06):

#pragma once

// Board-level pin assignments traced from electrical/hot-wand-lite.sch.

// XIAO D1/A1 is SAMD21 PA04 and provides TCC0/WO[0].
#define RFGEN_PIN D1

// The schematic's active-high LED net is XIAO D10/A10, SAMD21 PA06.
#define BLINK_LED_PIN D10

// XIAO's active-low onboard user LED is Arduino pin 13, SAMD21 PA17.
#define BLINK_XIAOBUILTIN_LED_PIN LED_BUILTIN

// Power-selection jumpers: names match their JP6 connector pin numbers.
#define SEL2_PIN D5 // XIAO D5/A5, SAMD21 PA09.
#define SEL3_PIN D4 // XIAO D4/A4, SAMD21 PA08.

// Input-voltage sensing divider output, XIAO D8/A8, SAMD21 PA07.
#define ADC_PIN D8

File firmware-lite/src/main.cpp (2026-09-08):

/*
 * Hot Wand Lite application entry point.
 *
 * setup() establishes safe outputs before starting USB serial.
 * loop() keeps the power manager and status indicator responsive.
 *
 */

// -----------------------------------------------------------------------------
// Includes
// -----------------------------------------------------------------------------

#include <Arduino.h>
#include "hotwandlite.h"
#include "testing_cli.h"

// -----------------------------------------------------------------------------
// Main Flow
// -----------------------------------------------------------------------------

void setup()
{
    // RF must remain off until the power manager's startup delay expires.
    rfgen_set(0);
    // for safety concerns, driving the RF generator pin low has the highest priority

    // Serial is the XIAO's USB CDC port; the baud rate is nominal for USB.
    Serial.begin(115200);

    blink_init();

    cli_init();
    watchdog_init();
}

void loop()
{
    // Feed before every possible return path, including exclusive test mode.
    watchdog_feed();
    rfgen_task();

    // A started test owns the application until the board is reset.
    if (testing_task())
    {
        return;
    }

    // Apply power-selection inputs and update the status indication.
    pwrmgt_task();
    blink_task();
}

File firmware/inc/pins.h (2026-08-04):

#pragma once

#include "stm32f0xx_hal.h"

#define DC_SENS_GPIOx    GPIOA
#define DC_SENS_PINn     GPIO_PIN_0
#define DC_SENS_ADCCHANn ADC_CHANNEL_0
#define DC_SENS_IDX      0

#define THERM_1_GPIOx    GPIOA
#define THERM_1_PINn     GPIO_PIN_1
#define THERM_1_ADCCHANn ADC_CHANNEL_1
#define THERM_1_IDX      3

#define THERM_2_GPIOx    GPIOA
#define THERM_2_PINn     GPIO_PIN_2
#define THERM_2_ADCCHANn ADC_CHANNEL_2
#define THERM_2_IDX      4

#define BUCK_SENS_GPIOx    GPIOA
#define BUCK_SENS_PINn     GPIO_PIN_3
#define BUCK_SENS_ADCCHANn ADC_CHANNEL_3
#define BUCK_SENS_IDX      1

#define CURR_SENS_GPIOx    GPIOA
#define CURR_SENS_PINn     GPIO_PIN_4
#define CURR_SENS_ADCCHANn ADC_CHANNEL_4
#define CURR_SENS_IDX      2

#define MCU_TEMP_ADCCHANn ADC_CHANNEL_TEMPSENSOR
#define MCU_TEMP_IDX      5

#define TIP_DET_GPIOx GPIOA
#define TIP_DET_PINn  GPIO_PIN_5

#define PWR_ATTENU_GPIOx GPIOA
#define PWR_ATTENU_PINn  GPIO_PIN_6

#define RFGEN_GPIOx GPIOB
#define RFGEN_PINn  GPIO_PIN_1

#define BTN_GPIOx GPIOA
#define BTN_PINn  GPIO_PIN_7

#define FAN_GPIOx GPIOA
#define FAN_PINn  GPIO_PIN_13

#define SCL_GPIOx GPIOA
#define SCL_PINn  GPIO_PIN_9

#define SDA_GPIOx GPIOA
#define SDA_PINn  GPIO_PIN_10

#define SWDIO_GPIOx GPIOA
#define SWDIO_PINn  GPIO_PIN_13

#define SWCLK_GPIOx GPIOA
#define SWCLK_PINn  GPIO_PIN_14

#define UART_TX_GPIOx GPIOA
#define UART_TX_PINn  GPIO_PIN_14

#define OSC_IN_GPIOx GPIOF
#define OSC_IN_PINn  GPIO_PIN_0

#define OSC_OUT_GPIOx GPIOF
#define OSC_OUT_PINn  GPIO_PIN_1

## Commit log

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2026-07-27 added STM32G051F8P3 but does not have correct pin names yet
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2026-07-29 circuit wip, part number attributes
    [hot-wand.brd, hot-wand.sch]
2026-07-29 circuit wip, added fan ctrl
    [hot-wand.brd, hot-wand.sch]
2026-07-30 laser cut thermal pad
    [hot-wand.brd]
2026-07-30 circuit wip, changed current sensor gain to read up to 6A
    [hot-wand.brd, hot-wand.sch]
2026-07-31 circuit wip, added JLCPARTNUM
    [hot-wand.brd, hot-wand.sch]
2026-07-31 circuit wip, more part numbers
    [hot-wand.brd, hot-wand.sch]
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2026-08-01 circuit now uses thermals so SMT can be easier
    [hot-wand.brd, hot-wand.sch]
2026-08-01 DFM changes, almost ready to order from JLC
    [hot-wand.brd, hot-wand.sch]
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2026-08-01 added a current sensor for 12V current draw
    [hot-wand.brd, hot-wand.sch]
2026-08-02 major thermal related changes, and I moved that one bootstrap cap to the bottom
    [hot-wand.brd, hot-wand.sch]
2026-08-02 circuit drill sizes sorted
    [hot-wand.brd, hot-wand.sch]
2026-08-02 thermal and mech changes
    [enclosure.step, hot-wand.brd, hot-wand.sch]
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2026-08-04 circuit wip, curr xformer footprint changed
    [hot-wand.brd, hot-wand.sch]
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2026-08-05 out of stock parts
    [hot-wand.brd, hot-wand.sch]
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2026-08-05 corrected fan behavior
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2026-08-05 ckt minor update, more parts for lbr
    [hot-wand.sch]
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2026-08-06 mfg scripts for lite
    [hot-wand-lite.brd, hot-wand-lite.sch, hot-wand.sch]
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2026-08-08 added selectable voltage for USB
    [hot-wand.brd, hot-wand.sch]
2026-08-08 routing, compatible with rp2040
    [hot-wand-lite.brd, hot-wand-lite.sch]
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2026-08-08 splash screen is now a full feature
    [hot-wand-lite.brd, hot-wand-lite.sch, hot-wand.brd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]
2026-08-08 corrected a resistor part number
    [hot-wand-lite.brd, hot-wand-lite.sch, hot-wand.brd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]
2026-08-09 added a selector for ISEL
    [hot-wand-lite.brd, hot-wand-lite.sch, hot-wand.brd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]
2026-08-10 added an option to use 3.3V regulator from 12V
    [hot-wand.brd, hot-wand.sch]
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2026-08-11 lite, major design change, now 15V or 20V, 3A or 5A, no mosfet for fan
    [hot-wand-lite.brd, hot-wand-lite.sch]
2026-08-11 names and part numbers
    [hot-wand-lite.brd, hot-wand-lite.sch]
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2026-08-11 missed a route
    [hot-wand-lite.brd]
2026-08-11 lite, moved LED, updated inductor comments
    [hot-wand-lite.brd, hot-wand-lite.sch]
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2026-08-12 changed how the DMA fed pulse generration works, dynamically generates a pulse train with correct estimated average power
    [main.cpp, power.cpp, rfgen.h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]
2026-08-13 added selector for 28V
    [hot-wand-lite.brd, hot-wand-lite.sch]
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2026-08-13 22 ohm resistor now 2W capable
    [hot-wand.brd, hot-wand.sch]
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2026-08-13 added another TVS diode to protect the buck converter
    [hot-wand.brd, hot-wand.sch]
2026-08-13 added out-to-in diode for buck converter
    [hot-wand.brd, hot-wand.sch]
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2026-08-14 changed a resistor that set the buck converter output voltage
    [hot-wand.brd, hot-wand.sch]
2026-08-14 changed that 22V zener to 24V
    [hot-wand.brd, hot-wand.sch]
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2026-08-17 more work regarding current transformer, better diode bom
    [hot-wand.brd, hot-wand.sch]
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2026-08-17 vrefint, and comment fixes
    [adc.c, button.c, conf.h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]
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2026-08-18 another hole for the air core inductor, moved a diode
    [hot-wand.brd]
2026-08-18 added protection for 8S possibility
    [hot-wand.brd, hot-wand.sch]
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2026-08-18 added reverse HV protection MOSFET for AP53781, TODO, remove the gigantic zeners
    [hot-wand.brd, hot-wand.sch]
2026-08-18 removed the zener diodes that were gonna get hot
    [hot-wand.brd, hot-wand.sch]
2026-08-18 tweaks after the new mosfet
    [hot-wand.brd, hot-wand.sch]
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2026-08-18 tip detector was wired wrong
    [hot-wand.brd, hot-wand.sch]
2026-08-18 update sch notes on tip detector
    [hot-wand.sch]
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2026-08-19 PCB tweaks, zener for 3.3V bus
    [hot-wand.brd, hot-wand.sch]
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2026-08-19 changing lite pcb to match mosfet changes to other design
    [hot-wand-lite.brd, hot-wand-lite.sch, hot-wand.sch]
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2026-08-22 lite version ready to order, corrected QFN16 footprint
    [hot-wand-lite.brd, hot-wand-lite.sch, hot-wand.brd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]
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2026-08-22 resistors for the leds needed to get beefier
    [hot-wand.brd, hot-wand.sch]
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2026-08-23 fixed blocked DMA bug
    [rfgen_samd21.cpp]
2026-08-23 fixed blocking dma bug, better cli response
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2026-08-23 slight design changes in response to sergeymax's video
    [hot-wand-lite.brd, hot-wand-lite.sch, hot-wand.brd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]
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2026-08-24 MOSFETs closer to enclosure wall for heat sink purposes
    [hot-wand-lite.brd, hot-wand.brd, hot-wand.sch]
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2026-08-25 brd change, option for larger TH resistors over SMD ones
    [hot-wand-lite.brd, hot-wand-lite.sch, hot-wand.brd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]
2026-08-25 no more thermal pad layer, added a bridge-able pot footprint
    [hot-wand.brd, hot-wand.sch]
2026-08-26 significant tweaks to pcb, less DRC errors to approve
    [hot-wand.brd, hot-wand.sch]
2026-08-27 added test points to aid in testing, marks for solder jumpers
    [hot-wand.brd, hot-wand.sch]
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2026-08-28 moved the oled, 3.3V buck converter footprint fixed
    [hot-wand.brd, hot-wand.sch]
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2026-08-29 clearly labeled the shunt jumper positions on the PCB
    [hot-wand-lite.brd, hot-wand-lite.sch, hot-wand.brd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]
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2026-08-29 lite pcb, capacitor footprint, labeled jumpers, TVS diode on big mosfet
    [hot-wand-lite.brd, hot-wand-lite.sch]
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2026-08-29 bad change, back2back fets won't work, will revert
    [hot-wand.brd, hot-wand.sch]
2026-08-29 Revert "bad change, back2back fets won't work, will revert"
    This reverts commit 54ef0c944ce6a9341d84e4487adf057fd6dd0504.
    [hot-wand.brd, hot-wand.sch]
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2026-09-01 new part number for small mosfet to lower costs
    [hot-wand-bom-jlc.csv, hot-wand-bom.csv, hot-wand-lite-bom-jlc.csv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]
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2026-09-05 mech update, strike plate for stand no longer aluminum
    [1590t-enclosure-body.step, 1590t-enclosure-lid.step, air-gap-blocker.step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]
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2026-09-06 econo box extended air gap beside PCB for better airflow
    [bottom-lid.step, bottom-lid.stl, box-body.step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]
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2026-09-08 fixed ESP32C3 fw and shorter than usual pulses
    [main.cpp, rfgen.h, rfgen_common.cpp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]
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2026-09-08 helper for winding the coreless inductor, moved some files
    [coreless_inductor_post.scad, current_transformer.scad]
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2026-09-11 esp32c3 has problems, PCB rerouted, different fw pin maps written
    [hot-wand-lite.brd, hot-wand-lite.sch]
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2026-09-15 inductor pin spacing, capacitor footprint silk, LED resistor changes
    [hot-wand-lite.brd, hot-wand-lite.sch, hot-wand.brd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]
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2026-09-15 corrected pot direction
    [hot-wand.sch]
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2026-09-21 inductor footprint larger pads, stm32f042 uses USART2 for debug
    [hot-wand-lite.brd, hot-wand-lite.sch, hot-wand.sch]
2026-09-21 more solder stop mask for easier inductor soldering
    [hot-wand-lite.brd]
2026-09-25 pcb assembly problems being addressed
    [hot-wand-lite.brd, hot-wand-lite.sch, hot-wand.brd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]
2026-10-01 tested pwrlvl to get a voltage table, added leaky bucket
    [duty.csv, duty_verify.csv, inductors.csv]
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2026-10-21 lite firmware, added rework, added high voltage ramp
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2026-10-28 added spike prevention algorithm using the PWM on the FB
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

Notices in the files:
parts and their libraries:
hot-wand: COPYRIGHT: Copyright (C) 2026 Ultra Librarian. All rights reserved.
